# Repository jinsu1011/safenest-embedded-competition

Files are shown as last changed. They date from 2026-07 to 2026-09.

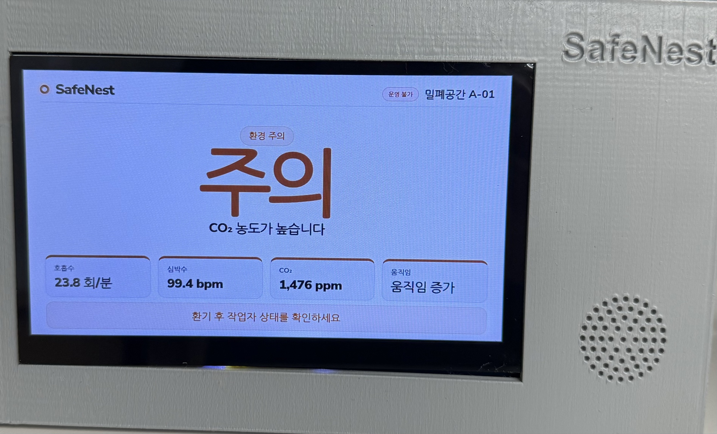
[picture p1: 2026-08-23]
final-report/assets/ui_lcd_3_caution.jpg

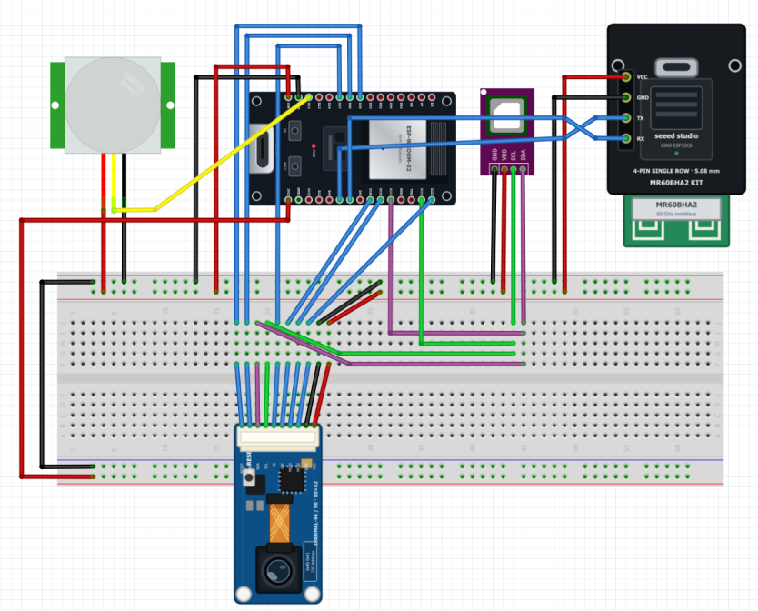
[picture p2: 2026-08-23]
final-report/assets/hw_wiring_diagram.png

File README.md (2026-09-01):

# SafeNest

밀폐공간 작업자 안전을 위한 엣지 AI 모니터링 시스템입니다. ESP32 센서 노드가 mmWave·Thermal·CO₂·PIR을 측정해 Raspberry Pi로 보내고, Pi가 On-device AI와 Rule Engine으로 위험도를 판정해 실시간 웹 대시보드에 표시합니다.

이 저장소는 여러 팀 저장소를 통합한 **canonical 통합 저장소**입니다. 각 컴포넌트의 상류 저장소와 정확한 commit SHA는 [`COMPONENT_SOURCES.json`](COMPONENT_SOURCES.json)에 기록되어 있습니다.

---

## 한 줄 실행

Raspberry Pi에서 아래 한 명령으로 전체 SafeNest 런타임이 기동됩니다.

```bash
./run_safenest.sh
```

최초 1회만 의존성을 설치합니다.

```bash
./run_safenest.sh --install
```

Thermal 모델만 바꿔 같은 SafeNest 스택을 비교하려면 별도 테스트 런처를 씁니다. 기본 `./run_safenest.sh` 동작은 그대로입니다.

```bash
./run_safenest_thermal_test.sh baseline
./run_safenest_thermal_test.sh a
./run_safenest_thermal_test.sh b
```

자세한 선택 의미는 [`docs/thermal/20260831_Thermal_V2_Team_MultiModel_Test_Staging_01.md`](docs/thermal/20260831_Thermal_V2_Team_MultiModel_Test_Staging_01.md)를 봅니다.
Pi 현장에서 baseline/A/B를 켜고 확인하는 절차는 [`PI_RUNBOOK_THERMAL.md`](PI_RUNBOOK_THERMAL.md)입니다.

이 한 명령이 하나의 프로세스 트리 안에서 다음을 모두 띄웁니다.

| 구성 요소 | 역할 |
| --- | --- |
| SafeNest TCP v1 게이트웨이 (`:9000`) | mmWave·CO₂·PIR scalar telemetry 수신 |
| SafeNest Thermal UDP v1 수신기 (`:5005`) | 80×62 열화상 프레임 chunk 재조립 |
| Sensor State Manager | 센서별 최신값·freshness·유효성·device health |
| On-device AI 파이프라인 | `RaspberryPi/Ondevice_AI`의 TFLite 어댑터 지연 로드 |
| Rule / Risk Engine | SAFENEST_RISK_V1(+필요 시 V4 호환)으로 `NORMAL/WARNING/DANGER` 판정 |
| SQLite | `RaspberryPi/Runtime/data/safenest.db` 스냅샷·이벤트 영속화 |
| FastAPI + WebSocket (`:8000`) | 통합 상태 API와 실시간 push |
| 실시간 웹 대시보드 | `http://<pi-주소>:8000/dashboard` |

여러 터미널을 열 필요가 없습니다. `Ctrl+C` 한 번으로 전체가 정상 종료됩니다.

### 접속 주소

| 대상 | URL |
| --- | --- |
| 관리자 웹 | `http://<pi-주소>:8000/admin` |
| A01 방문자 열화상 | `http://<pi-주소>:8000/guest/dashboard/A01` |
| 실시간 대시보드 | `http://<pi-주소>:8000/dashboard` |
| LCD 표시 화면 | `http://<pi-주소>:8000/display` |
| LCD 데모 제어 (명시적 opt-in) | `SAFENEST_DEMO_MODE=true`일 때 `http://<pi-주소>:8000/control` |
| 통합 상태 API | `http://<pi-주소>:8000/api/status` |
| 센서 상세 | `http://<pi-주소>:8000/api/sensors` |
| 이력 / 이벤트 | `/api/history`, `/api/events` |
| 헬스체크 | `http://<pi-주소>:8000/health` |
| WebSocket | `ws://<pi-주소>:8000/ws` |

포트를 바꾸려면 인자를 그대로 전달합니다: `./run_safenest.sh --api-port 8080 --sensor-port 9100`

### 웹과 열화상 빠른 확인

Raspberry Pi OS에서 최초 1회 OS 패키지를 설치한 뒤 SafeNest를 시작합니다.

```bash
sudo apt update
sudo apt install -y python3-venv python3-pip python3-dev build-essential
./run_safenest.sh --install
```

`--install`은 가상환경과 Python 의존성을 설치한 다음 사전 점검을 거쳐 런타임까지 시작합니다. 이후 실행은 `./run_safenest.sh`만 사용합니다. 방화벽을 사용하면 브라우저용 TCP `8000`, scalar telemetry용 TCP `9000`, Thermal UDP `5005`를 허용합니다.

ESP32의 `secrets.h`에는 Pi의 실제 IP를 `RPI_HOST`로 넣고, 펌웨어의 `THERMAL_UDP_PORT`와 Pi의 `SAFENEST_THERMAL_UDP_PORT`를 동일한 `5005`로 유지합니다. 프레임 수신 여부는 다음처럼 확인합니다.

```bash
curl -fsS http://127.0.0.1:8000/health | python3 -m json.tool
curl -sS -D - -o /dev/null http://127.0.0.1:8000/api/thermal/A01
```

열화상 API가 `200`과 `application/octet-stream`을 반환하면 웹이 그릴 수 있는 완성 프레임이 있습니다. 아직 프레임이 없으면 `204`가 정상적으로 반환됩니다. 자세한 순서는 [`RaspberryPi/Runtime/docs/WEB_THERMAL_RUNBOOK_KO.md`](RaspberryPi/Runtime/docs/WEB_THERMAL_RUNBOOK_KO.md)를 따릅니다.

---

## 저장소 구조

```
ESP32/
├── Arduino/esp32_sensor_node/    canonical 플래시 소스 (4개 센서 통합 노드)
├── docs/COMMUNICATION_PROTOCOL.md  ESP32 ↔ Pi 프로토콜 계약
├── reference/mmwave_platformio/  mmWave 단독 PlatformIO 참조 펌웨어
└── secret.h.example              Wi-Fi/Pi 주소 템플릿 (실제 값은 커밋 금지)

RaspberryPi/
├── Ondevice_AI/                  On-device AI 상류 권위 소스 (sheepmeat/test)
├── LCD/                          Pi LCD 키오스크 (레거시 독립 경로, 아래 주의)
├── Web/                          실시간 관제 대시보드 정적 자산
└── Runtime/                      Pi 런타임 (게이트웨이·상태·AI·risk·backend·DB)

research/
├── thermal_ai/                   Thermal 오프라인 데이터셋/모델 연구 (런타임 아님)
└── co2_validation/               CO₂ 측정·검증 도구와 세션 fixture (런타임 아님)

archive/                          과거 구현·측정 증거 보존 (런타임이 참조하지 않음)
hardware/                         하우징 3D 모델
COMPONENT_SOURCES.json            컴포넌트별 상류 저장소와 commit SHA
run_safenest.sh                   단일 실행 진입점
run_safenest_thermal_test.sh      Thermal baseline/A/B 비교용 테스트 런처
PI_RUNBOOK.md                     Pi 일반 현장 기동
PI_RUNBOOK_THERMAL.md             Pi Thermal baseline/A/B 비교 현장 가이드
```

### 구조 예외 (STRUCTURE_EXCEPTION)

기본 목표 구조는 `RaspberryPi/{Ondevice_AI, LCD, Web}`였지만, 기술적으로 다음 디렉터리를 추가했습니다.

| 디렉터리 | 책임 | 왜 필요한가 |
| --- | --- | --- |
| `RaspberryPi/Runtime/` | 게이트웨이, 센서 상태, AI 오케스트레이션, Risk, FastAPI, SQLite, 서비스, 배포 | 이 코드는 특정 센서나 UI가 아니라 **셋을 연결하는 런타임**입니다. `Ondevice_AI`에 넣으면 상류 저장소를 오염시키고, `Web`에 넣으면 UI가 게이트웨이를 소유하게 됩니다. 이게 없으면 단일 명령 실행 자체가 성립하지 않습니다. |
| `research/` | Thermal·CO₂ 오프라인 모델/데이터 연구 워크스페이스 | 두 상류 저장소가 스스로 "펌웨어 통합·위험도 판단은 범위 밖"이라고 명시합니다. 런타임에 섞으면 미검증 모델이 배포 경로로 오해됩니다. |
| `ESP32/docs`, `ESP32/reference` | 프로토콜 계약 문서, mmWave 참조 펌웨어 | 계약 테스트가 이 파일들을 읽습니다. `archive/`에 두면 활성 테스트가 archive에 의존하게 되어 금지된 구조가 됩니다. |
| `hardware/` | 하우징 STL | ESP32도 Pi도 소유하지 않는 물리 설계 자산입니다. |

---

## 데이터 흐름

```
ESP32 센서 노드
  ├─ mmWave (MR60BHA2, UART)  ─┐
  ├─ CO₂ (SCD4x, I2C)          ├─ JSON telemetry ─→ SafeNest TCP v1 :9000 ─┐
  └─ PIR (GPIO)               ─┘                                            │
  └─ Thermal (MI48xx, SPI) ─ 80×62 uint16 ─→ Thermal UDP v1 :5005 ─────────┤
                                                                            ▼
                                                     RaspberryPi/Runtime/gateway
                                                                            │
                                                     state/manager.py (freshness·유효성)
                                                                            │
                                              ai/pipeline.py ──→ Ondevice_AI TFLite
                                                                            │
                                              risk/engine.py (V4 가중치·임계값)
                                                                            │
                                     backend/store.py → database/ (SQLite)  │
                                                                            ▼
                                            backend/app.py (FastAPI + /ws)
                                                                            │
                                                          RaspberryPi/Web 대시보드
```

활성 진입점은 하나뿐입니다: `RaspberryPi/Runtime/backend/run_backend.py`. 컴포넌트 간 경로는 전부 `RaspberryPi/Runtime/paths.py`가 해석합니다.

---

## 설치와 실행

### 1. ESP32 펌웨어 플래시

1. Arduino IDE에서 `ESP32/Arduino/esp32_sensor_node/esp32_sensor_node.ino`를 엽니다.
2. 자격증명 파일을 스케치 폴더에 만듭니다. **이 파일은 Git에 커밋되지 않습니다.**
   ```bash
   cp ESP32/secret.h.example ESP32/Arduino/esp32_sensor_node/secrets.h
   ```
3. `secrets.h`를 열어 2.4 GHz Wi-Fi SSID/비밀번호와 Raspberry Pi의 IP를 채웁니다.
4. 보드를 `ESP32 Dev Module`로 선택하고 업로드합니다.
5. 필요한 라이브러리: `SensirionI2cScd4x`, `Seeed_Arduino_mmWave`.

배선과 패킷 형식은 [`ESP32/docs/COMMUNICATION_PROTOCOL.md`](ESP32/docs/COMMUNICATION_PROTOCOL.md)를 따릅니다.

### 2. Raspberry Pi 준비

```bash
git clone https://github.com/jinsu1011/safenest-embedded-competition.git
cd safenest-embedded-competition
./run_safenest.sh --install   # .venv 생성 + 의존성 설치
./run_safenest.sh             # 실행
```

의존성은 `RaspberryPi/Runtime/requirements-backend.txt`(FastAPI/uvicorn)와 `RaspberryPi/Ondevice_AI/requirements-pi.txt`(ai-edge-litert, numpy 등)에서 옵니다.

### 3. 선택: 비상 대응 설정

SMS·부저를 쓰려면 저장소 루트에 `.env`를 만듭니다. 템플릿은 [`RaspberryPi/Runtime/.env.example`](RaspberryPi/Runtime/.env.example)입니다. `.env`는 Git에 올라가지 않습니다.

---

## 실패 동작

시스템은 **fail-closed**입니다. 값을 지어내지 않습니다.

| 상황 | 동작 |
| --- | --- |
| 센서 패킷이 끊김 | 해당 센서가 `STALE` → `DISCONNECTED`. 마지막 값을 현재값으로 쓰지 않음 |
| 잘못된 패킷 수신 | 해당 연결만 끊고 `protocol_errors` 증가. 서비스는 계속 동작 |
| 모델 로드 실패 | 해당 센서만 `MODEL_RUNTIME_UNAVAILABLE`, 나머지는 계속 평가 |
| 전 컴포넌트 불가 | `risk_level = null` + `ALL_RISK_COMPONENTS_UNAVAILABLE`. 임의 점수를 만들지 않음 |
| 필수 설정 누락 | 기동 시 명시적 오류 |

`system_health`가 `DEGRADED`/`FAILED`인데 `risk_level`이 `NORMAL`이면, 그것은 "안전 확인"이 아니라 "판정 근거 부족"입니다.

---

## AI 모델 상태

**중요: 이 저장소의 어떤 모델도 실기기에서 검증되지 않았습니다.** Thermal 모델은 최종 runtime artifact로 활성화했지만, 이는 Pi/실센서/실제 낙상 검증 완료를 뜻하지 않습니다.

| 센서 | 런타임 모델 | 상태 |
| --- | --- | --- |
| Thermal | `public_sdt_pooled_mlp_fp32_tflite_v1` | **활성 최종 runtime 모델**. `HUMAN_FALL_PROXY`는 위험 점수 0.4로 제한 반영하며 긴급 override는 금지 |
| CO₂ | `co2_occupancy_int8_v0.1.0` | candidate, `CONFIRMED_SYNTHETIC_ONLY` |
| mmWave | `mmwave_resp_int8_v0.1.0` | **배포 차단** (`deployment_allowed: false`, `CLASS_COLLAPSE_ON_REPOSITORY_NPZ`) |
| mmWave v0.2.0 | `mmwave_resp_int8_v0.2.0_candidate` | candidate, `SYNTHETIC_SMOKE_ONLY`, 하드웨어 검증 `BLOCKED_HARDWARE` — 런타임 기본값으로 승격하지 않음 |
| PIR | 없음 | AI 모델 없음. Rule 전용 센서 |

용어를 구분합니다: 최종 runtime artifact ≠ 실기기 검증 완료, `HUMAN_FALL_PROXY` ≠ 실제 낙상 이벤트, 제한 위험 반영 ≠ 긴급 호출 권한.

권위 있는 상태는 [`RaspberryPi/Ondevice_AI/models/model_manifest.json`](RaspberryPi/Ondevice_AI/models/model_manifest.json)입니다.

---

## 검증

```bash
cd RaspberryPi/Runtime
python -m unittest discover -s tests -p "test_*.py" -v   # 151개 테스트
python deployment/verify_bundle.py                        # 필수 파일 + 모델 SHA-256
python -m hil.preflight                                   # Pi 환경 사전 점검
```

`tests/test_end_to_end.py`는 실제 TCP loopback으로 게이트웨이→AI→Risk→SQLite→API view 전체를 통과시킵니다. 이는 **소프트웨어 E2E**이며, 실제 센서 하드웨어 검증이 아닙니다. 하드웨어 검증 절차는 [`RaspberryPi/Runtime/docs/HIL_ACCEPTANCE.md`](RaspberryPi/Runtime/docs/HIL_ACCEPTANCE.md)에 있습니다.

---

## 주의사항

### LCD 경로

`run_safenest.sh`가 시작하는 FastAPI가 production 웹 대시보드와 LCD 화면을 함께 제공합니다. 물리 LCD에는 `http://localhost:8000/display`를 엽니다. 화면은 read-only `/api/state`를 통해 실제 센서/application 상태를 사용합니다. 기본 실행에서는 수동 LCD override, demo TTS, 모의 119 신고 route가 등록되지 않습니다.

경진대회용 Web/LCD 데모가 꼭 필요할 때만 저장소 루트 `.env`에 `SAFENEST_DEMO_MODE=true`를 명시하고 정상 런처를 실행합니다. 이 경우 기존 demo 대시보드, `http://<pi-주소>:8000/control`, `POST /api/state`, 모의 119 route가 함께 활성화됩니다. 설정이 없거나 `false`이면 항상 production 경로입니다.

HTML 파일을 `file://`로 직접 열지 말고 위 HTTP 주소로 접속해야 CSS·JavaScript와 센서 API가 같은 origin으로 연결됩니다.

`RaspberryPi/LCD/server.py`는 과거의 독립 구현으로 자체 TCP `:9000` 수신기와 `state.json`을 사용합니다. canonical 게이트웨이와 포트·상태가 중복되므로 `run_safenest.sh`와 동시에 실행하지 않습니다. 단독 점검이 필요할 때만 별도 포트로 실행합니다.

같은 이유로 `research/co2_validation/pi/safenest_pi_service.py`(CO₂ 전용 `:9000` 수신기)도 런타임과 동시에 실행하면 안 됩니다.

### archive는 런타임이 참조하지 않습니다

`archive/`는 과거 구현·측정 증거 보존 전용입니다. 활성 런타임은 archive를 import하지도, 설정·모델을 읽지도 않습니다.

---

## 상류 저장소 동기화

| 컴포넌트 | 상류 | 통합 commit |
| --- | --- | --- |
| On-device AI | `sheepmeat/test` | `4129753e64e0f18a3491e5b6cc0454b0d36f1610` |
| 런타임·게이트웨이·backend·DB·Web | `yuname121/integration` | `9e4ddfe770d505266f33b39dfe9ba8ec86099f82` |
| Thermal 연구 | `yuname121/safenest-thermal-ai` | `db51112bfd02cdda2d41e99cf11acde75f771ecf` |
| CO₂ 측정·검증 | `yuseungha/Sandi-2026_summer` | `145deac4cbec12ce6459cf5a6858cb0d0b1d06da` |
| 기존 메인 저장소 | `jinsu1011/safenest-embedded-competition` | `6fc04d6e9e09aa0baac96592eb374f6d3de6af07` |

상류 갱신을 반영할 때:

1. 상류 저장소를 clone하고 새 HEAD SHA를 확인합니다.
2. **런타임 임계 경로**(`inference/`, `config/`, `adapters/`, `models/model_manifest.json`)의 diff를 먼저 봅니다.
3. 모델 매니페스트의 `deployment_allowed`와 `validation_status`가 바뀌었는지 확인합니다. 최신이라는 이유만으로 승격하지 않습니다.
4. 파일을 반영하고 `COMPONENT_SOURCES.json`의 SHA를 갱신합니다.
5. `python -m unittest discover -s tests`와 `verify_bundle.py`를 돌려 모델 SHA-256이 매니페스트와 일치하는지 확인합니다.

---

## 문제 해결

| 증상 | 확인할 것 |
| --- | --- |
| 대시보드가 "WebSocket 오프라인" | 백엔드가 살아있는지 `curl localhost:8000/health` |
| 모든 센서가 `DISCONNECTED` | ESP32의 `secrets.h` 속 Pi IP, 같은 2.4 GHz 네트워크인지, `:9000` 방화벽 |
| Thermal만 안 들어옴 | Thermal은 UDP `:5005`. TCP와 별도 포트입니다 |
| `virtual environment not found` | `./run_safenest.sh --install` 먼저 실행 |
| `port_9000_available: false` | LCD나 CO₂ 전용 서비스가 이미 `:9000`을 점유 중 |
| mmWave AI가 `INPUT_UNAVAILABLE` | 정상입니다. B-model은 300-sample 호흡 phase window를 요구하며 현재 펌웨어는 vendor scalar만 보냅니다 (`PENDING_MMWAVE_DEVICE_CONTRACT_VALIDATION`) |

---

## 기여

브랜치 규칙과 리뷰 절차는 [`CONTRIBUTING.md`](CONTRIBUTING.md)를 따릅니다. 단계별 통합 근거는 [`RaspberryPi/Runtime/docs/`](RaspberryPi/Runtime/docs/)에 PHASE 1~10으로 정리되어 있습니다.

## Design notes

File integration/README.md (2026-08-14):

# `integration/`

## 1. 디렉터리 목적
ESP32 텔레메트리를 받아 상태를 판정하고 LCD·부저·웹 화면으로 내보내는 Raspberry Pi 쪽 실행 계층을 한곳에 모은다.

## 2. 시스템에서 담당하는 기능
TCP 9000으로 들어온 센서 패킷을 검증·보관하고, 상태를 판정해 LCD 키오스크 화면과 GPIO 부저를 구동하며, 관리자·방문자 웹 화면과 REST API를 제공한다.

## 3. 포함해야 하는 파일 유형
Pi 수신·표시 서버, 웹 서버와 정적 화면, 실행·설치 스크립트, 이 계층만으로 통과 가능한 테스트를 포함한다.

## 4. 포함하면 안 되는 파일 유형
ESP32 펌웨어(`devices/esp32_node/`), 센서별 드라이버(`devices/<sensor>/`), TFLite 모델·추론(`ondevice_ai/`), 공용 계약(`shared/contracts/`), `node_modules/`와 `.env` 같은 로컬 산출물은 포함하지 않는다.

## 5. 주요 하위 구성
`pi_lcd/`는 Python 표준 라이브러리 기반 수신·표시 서버(`server.py`, `static/`, `tests/`, `start_lcd.sh`, `stop_lcd.sh`)다. `web/`은 Express 기반 통합 웹(`server.js`, `admin-api.js`, `preview.html`, `qr-codes/`)이다. `install_raspberry_pi.sh`와 `start_all.sh`는 두 서버를 설치·기동한다.

## 6. 입력과 출력 인터페이스
입력은 ESP32의 `safenest.telemetry.v1` JSON(TCP 9000)이다. 출력은 `GET /api/state`, `GET /api/thermal`, `GET /health`(:8080)와 통합 웹(:3000), 그리고 LCD 화면·부저다. `POST /api/state`로 판정 결과가 LCD에 반영된다. 결측·0·NaN·timeout은 정상값이나 무호흡으로 바꾸지 않고 `stale`/`waiting`으로 표시한다.

## 7. 다른 기능 영역과의 관계
`devices/esp32_node/`가 보내는 텔레메트리를 소비하는 하위 계층이며, 반대로 펌웨어를 import하지 않는다. 현재 판정은 `web/server.js`의 규칙 기반 `evaluate()`/`riskScore()`를 쓰며, `ondevice_ai/`의 V4 위험도 엔진과는 아직 연결돼 있지 않다. 두 판정 경로의 통합은 후속 작업이다.

## 8. 실행·학습·추론 또는 활용 방법
설치와 실행은 저장소 루트에서 수행한다.

```bash
bash integration/install_raspberry_pi.sh
bash integration/start_all.sh
```

스크립트는 `pi_lcd/`와 `web/`을 각각 `~/raspberry_pi_lcd`와 `~/SafeNest_Web`으로 복사한다. 저장소 경로와 실행 환경 폴더 이름이 다른 것은 실측 검증된 운용 절차를 그대로 유지하기 위해서다. 자세한 절차는 [`docs/operations/INTEGRATION_INSTALL_AND_RUN.md`](../docs/operations/INTEGRATION_INSTALL_AND_RUN.md)에 있다.

테스트는 `pi_lcd/`에서 실행한다. 테스트가 `server.py`를 직접 import하므로 해당 디렉터리를 `PYTHONPATH`에 넣는다.

```bash
cd integration/pi_lcd
PYTHONPATH=. python3 -m unittest discover -s tests -p "test_*.py"
```

## 9. 현재 개발 상태 및 버전
실제 하드웨어에서 ESP32 수신 → 상태 판정 → LCD 자동 전환까지 검증했고 회귀 테스트 13건이 통과한다. 남은 한계(열화상 죽은 픽셀, 호흡수 노이즈)는 [`docs/esp32_node/ESP32_LCD_INTEGRATION_NOTES.md`](../docs/esp32_node/ESP32_LCD_INTEGRATION_NOTES.md) 5절에 있다. 최상위 `display-test/`와 `display-test2/`는 이 작업의 이전 스냅샷이며 이 디렉터리가 대체한다.

## 10. 향후 파일 추가 및 관리 규칙
판정 규칙과 임계값은 한 번에 하나만 바꾸고 같은 조건에서 변경 전후를 비교한다. 텔레메트리 필드를 바꾸면 `devices/esp32_node/`와 [`docs/esp32_node/COMMUNICATION_PROTOCOL.md`](../docs/esp32_node/COMMUNICATION_PROTOCOL.md)를 같은 PR에서 함께 고친다. `.env`와 `secrets.h`, `node_modules/`는 커밋하지 않는다.

## 11. 주요 기여자와 원본 브랜치·커밋 추적 정보
담당: Seungha (`@yuseungha`) — Pi 수신·표시 서버, 통합 웹, 설치·실행 스크립트.
원본 ref `yuseungha/safenest-embedded-competition@0992a6d`(`main`에 PR #1로 병합), 원본 경로 `yuseungha/raspberry_pi_lcd/`와 `yuseungha/SafeNest_Web/`.

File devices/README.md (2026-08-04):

# `devices/`

## 1. 디렉터리 목적
기기 담당자가 단독으로 책임지는 센서별 펌웨어, 드라이버, 배선·보정 문서, 기기 단독 테스트를 기기 단위로 모은다.

## 2. 시스템에서 담당하는 기능
각 물리 센서를 초기화·수집·검증해 `shared/contracts/base_sensor.py` 계약을 만족하는 정규화된 판독값으로 바꾼다.

## 3. 포함해야 하는 파일 유형
기기별 드라이버·어댑터·mock, 펌웨어 프로젝트, 기기 설정, 배선·보정 문서, 그 기기만으로 통과 가능한 테스트를 포함한다.

## 4. 포함하면 안 되는 파일 유형
여러 기기가 함께 쓰는 인터페이스(`shared/contracts/`), TFLite 추론·위험도 융합·통합 노드(`ondevice_ai/`), 빌드 산출물과 사용자명 디렉터리는 포함하지 않는다.

## 5. 주요 하위 구성
`co2/`, `pir/`, `mmwave/`, `thermal/` 네 기기가 있고 각 기기는 `src/`를 기본으로 필요에 따라 `firmware/`, `config/`, `tests/`, `docs/`를 갖는다.

## 6. 입력과 출력 인터페이스
입력은 UART/I2C/GPIO 원신호와 리플레이 로그이며, 출력은 `SensorReading` 계약을 따르는 판독값과 명시적인 결측 표시다.

## 7. 다른 기능 영역과의 관계
`shared/contracts/`의 계약을 구현하고, `ondevice_ai/src/`가 이 구현을 `devices.<device>.src...` 경로로 명시적으로 import한다. 반대 방향 의존은 만들지 않는다.

## 8. 실행·학습·추론 또는 활용 방법
기기 단독 테스트는 `python3 -m unittest discover -s devices/<device>/tests -p 'test_*.py'`로 실행하고, 펌웨어는 해당 기기 README의 빌드 절차를 따른다.

## 9. 현재 개발 상태 및 버전
mmWave는 MR60 schema 1.2 / 펌웨어 v1.2.0으로 실측 검증까지 완료했고, CO2·PIR·Thermal은 어댑터와 mock 단계다. 2026-08-03 책임 영역 재편(`38274c0`) 구조를 따른다.

## 10. 향후 파일 추가 및 관리 규칙
새 기기는 `devices/<device>/src/`부터 만들고 담당자·README·CODEOWNERS 항목을 함께 추가한다. 기기 코드를 다른 기기 디렉터리로 복사하지 말고, 공통이 필요해지면 `shared/contracts/`로 올린 뒤 양쪽에서 import한다.

## 11. 주요 기여자와 원본 브랜치·커밋 추적 정보
| 기기 | 담당 | GitHub handle | 책임 범위 |
|---|---|---|---|
| `co2/` | Seungha | `@yuseungha` | CO2 센서 드라이버, 배선, 보정 |
| `pir/` | Yuna | `@yuname121` | PIR 어댑터, 하우징 연계 |
| `mmwave/` | Jinsu | `@jinsu1011` | MR60 펌웨어, 텔레메트리, 실측 검증 |
| `thermal/` | Taegyun | `@rla1729` | Thermal-44 드라이버, 프레임 파서 |

원본은 `origin/Ondevice_AI`(`d97df3e`)의 센서 구현과 `codex/mmwave-phase-integration`(`b0d3c95`)의 MR60 작업이며, 상세 매핑은 [`docs/architecture/BRANCH_PROVENANCE.md`](../docs/architecture/BRANCH_PROVENANCE.md)에 있다.

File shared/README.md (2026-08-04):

# `shared/`

## 1. 디렉터리 목적
여러 책임 영역이 함께 의존하는 최소한의 공용 인터페이스만 보관한다. 어느 한 기기나 `ondevice_ai/`에만 속한다고 말할 수 없는 것만 여기에 둔다.

## 2. 시스템에서 담당하는 기능
기기 구현과 온디바이스 AI 사이의 데이터 계약을 한 곳에 고정해, 양쪽이 서로의 내부 구현을 알지 않아도 되게 한다.

## 3. 포함해야 하는 파일 유형
추상 기반 클래스, 데이터 계약, 상태 enum처럼 둘 이상의 최상위 영역이 실제로 import하는 정의만 포함한다.

## 4. 포함하면 안 되는 파일 유형
특정 기기 드라이버, 모델·데이터셋, 위험도 로직, 실행 스크립트, 유틸리티 잡동사니는 포함하지 않는다. 한 영역만 쓰는 코드는 그 영역에 둔다.

## 5. 주요 하위 구성
`contracts/`에 센서 계약 `base_sensor.py` 하나가 있다.

## 6. 입력과 출력 인터페이스
직접 실행되지 않는 정의 전용 영역이다. `devices/`가 구현하고 `ondevice_ai/`가 소비한다.

## 7. 다른 기능 영역과의 관계
`devices/<device>/src/`의 모든 어댑터가 이 계약을 구현하고, `ondevice_ai/src/`가 같은 계약에 기대어 동작한다. 이 영역이 커질수록 팀 전원이 같은 파일을 건드리게 되므로 의도적으로 작게 유지한다.

## 8. 실행·학습·추론 또는 활용 방법
`from shared.contracts.base_sensor import ...` 형태로 저장소 루트 기준 import한다.

## 9. 현재 개발 상태 및 버전
2026-08-03 책임 영역 재편(`38274c0`)에서 신설했다. 현재 공용 정의는 센서 계약 한 개다.

## 10. 향후 파일 추가 및 관리 규칙
새 파일을 추가하기 전에 "두 개 이상의 최상위 영역이 실제로 import하는가"를 확인한다. 아니면 해당 영역에 둔다. 계약 변경은 모든 구현체와 테스트를 함께 갱신하고 CODEOWNERS 리뷰를 받는다.

## 11. 주요 기여자와 원본 브랜치·커밋 추적 정보
담당: Junwoo (`@sheepmeat`), Jinsu (`@jinsu1011`) 공동.
원본 ref `origin/Ondevice_AI` (`d97df3e`), 원본 경로 `src/sensors/base_sensor.py`. 2026-08-03 이동 커밋 `38274c0`에서 현재 경로로 옮겼다.

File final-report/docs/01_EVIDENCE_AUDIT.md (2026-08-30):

# 01_EVIDENCE_AUDIT

Evidence levels: **E0** planned · **E1** source implemented · **E2** software verified ·
**E3** component HW verified · **E4** integrated real-HW / HIL · **E5** repeated quantitative.

Snapshot = `05_Source_Snapshot/safenest-embedded-competition` @ commit `3f22fb1…` (branch `codex/mmwave-m-c0-correspondence`).
"Executed" = actually run by me on this Mac (see `work/test_runs/EXECUTED_TESTS.md`).

| Feature / Claim | Exact source | Status | Level | Verified? | Safe wording (KO) | Missing evidence |
|---|---|---|---|---|---|---|
| ESP32 4-sensor node firmware | `devices/esp32_node/firmware/esp32_sensor_node.ino` (741 lines) | 4 sensors in one node, ESP32 Dev Module | **E1** | source read | 구현 완료 | 실기기 4센서 동시 수신 로그 |
| MCU = ESP32 DevKit V1 (not XIAO) | same file, pin constants L34-47; 유승하 report 대표문제 B | Board changed from XIAO ESP32-C6 | **E1/E3** | source + report | 구현 완료 | 교체 사유 1차 문서 (`[검증 필요]` per 유승하) |
| mmWave MR60BHA2 via **UART2** 115200 | `.ino` L38-39 `PIN_MMWAVE_RX=16/TX=17`, `MMWAVE_BAUD` | implemented + real capture | **E3** | `FINAL_REPORT_KO.md` 9.990 Hz, 1,201 rec | 실기기 검증 | — |
| SCD40 CO₂ via **I2C** 0x62 | `.ino` `SCD4X_ADDRESS=0x62`, SDA21/SCL22 | implemented + real sessions | **E3** | CO₂ 4 sessions 2026-08-12 | 실기기 검증 | 센서 분리(결측) 계약 미완 |
| Thermal MI48xx **I2C ctrl + SPI data** | `.ino` L40-46, `THERMAL_ADDRESS_A/B 0x40/0x41` | implemented | **E1/E3** | thermal v5 real frames | 실기기 검증(별도 리그) | 정식 노드에서의 실측 |
| PIR via **GPIO 13** digital | `.ino` `PIN_PIR=13`, `PIR_PERIOD_MS=20` | implemented | **E1** | source | 구현 완료 | 실 GPIO 수신 증거 (한준우: "실 GPIO 미설치") |
| **SafeNest TCP protocol v1** 16B header `SNST` | `.ino` L113-124; `integration/pi_lcd/server.py` L43-47 `PACKET_HEADER=Struct("!4sBBHII")` | both ends implemented | **E2** | **executed: 13 passed** | SW 검증 | — |
| `recv_exact()` length-prefixed framing | `integration/pi_lcd/server.py` | implemented | **E2** | executed | SW 검증 | — |
| **null ≠ 0** for invalid readings | `.ino` `formatNullableFloat()` L546-553 → emits `"null"` | implemented both ends | **E2** | executed + CO₂ CSV | 구현 완료 · SW 검증 | — |
| Per-channel `valid{}` block | `.ino` L576-583; server L140-145 | implemented | **E2** | executed | 구현 완료 | — |
| Per-sensor freshness TTL (ESP side) | `.ino` `MMWAVE_STALE_MS=5000`, `CO2_STALE_MS=15000`, `THERMAL_STALE_MS=30000` | implemented | **E1** | source | 구현 완료 | — |
| Pi-side stale state machine `waiting/live/stale/error` | `server.py` `SensorStore.snapshot()` L226-258, `stale_seconds=5.0` | implemented | **E2** | executed | SW 검증 | — |
| **CRC-16/CCITT-FALSE** on thermal frames | `.ino` L303-320 `thermalFrameCrc()`, poly 0x1021 init 0xFFFF; counter `thermalCrcErrors` | implemented | **E1** | source read | 구현 완료 | 실측 CRC 오류율 |
| Thermal frame integrity: geometry + inner/outer sequence + recomputed min/max cross-check | `server.py` L175-206 | implemented, corrupt frame discarded | **E2** | executed | SW 검증 | — |
| Dead-pixel band 2332–4231 raw (≈ −40…150 °C), ≥32 live pixels | `.ino` L98-101; `server.py` L199-206 | implemented | **E2** | executed | 구현 완료 | — |
| Robust peak = coolest of 16 hottest | `.ino` `THERMAL_PEAK_SAMPLE_COUNT=16` + comment | implemented | **E1** | source | 구현 완료 | — |
| Thermal auto re-init after 30 s no-frame (GPIO RESET 25) | `.ino` `recoverThermalIfStale()` L418-434, `initializeThermalCamera()` L232-240 | implemented | **E1** | source | 구현 완료 | 실측 복구 로그 |
| **Thermal full-frame streaming DISABLED** | `.ino` L108-111 `THERMAL_STREAM_FRAMES=false` + comment | current canonical state | **E1** | source | 현재 구조: 요약값 전송 | — |
| SPI 1 MHz / I2C 100 kHz (signal integrity) | `.ino` `THERMAL_SPI_HZ=1000000`; `Wire.setClock(100000)` L696 | implemented, from 8 MHz/400 kHz | **E3** | 유승하 report 문제3 | 실기기 검증 | 계측 파형 없음 |
| No `delay()`; millis() scheduling + FreeRTOS network task; 1-slot `xQueueOverwrite` | `.ino` header comment L15-18 | implemented | **E1** | source | 구현 완료 | — |
| Buzzer GPIO18 880 Hz on `emergency` | `server.py` `BuzzerController` L410, args L699-701 | implemented | **E2** | executed (mocked) | SW 검증 | 실기기 부저 증거 |
| **Risk engine (current Pi)** R=100·(0.25·mmWave+0.30·CO₂+0.15·PIR+0.30·Thermal), floors | `RaspberryPi/Runtime/risk/formula_v1.py`, `risk_formula_v1.json` | implemented | **E2** | `test_risk_formula_v1.py` | SW 검증. 보고서 P10 정본 | 구 V4 스냅샷 식과 다름 |
| Thresholds NORMAL<30 / WARNING 30–65 / DANGER ≥65 | same | implemented | **E2** | executed | 주의=WARNING. CAUTION 명칭 폐기 | 30/65는 팀 프로토타입 |
| CO₂ warning floor ≥1500 ppm or baseline+700, immediate danger ≥5000 ppm | `risk_formula_v1.json` `co2` + `CO2BaselineLock`; `docs/09_SAFETY_CRITERIA_V1.md` | implemented | **E2** | `test_indoor_air_quality_anchor_raises_warning_even_when_r_is_low`; `test_relative_rise_warns_below_the_absolute_ceiling`; `test_co2_baseline_lock.py` | 1,500 ppm(별표2 비고)=주의. \(B\)+700=상대 주의. occupancy는 점수 제외 | 인증 기준 아님 |
| **Fail-closed: all sensors invalid → risk_score=None, risk_level=None** | `ondevice_ai/risk/fallback.py` L196-201 | implemented | **E2** | executed | SW 검증 (**핵심 차별성**) | — |
| Weight renormalisation over valid sensors only | `fallback.py` L214-219 | implemented | **E2** | executed | SW 검증 | — |
| STALE excluded (not reused as current) | `fallback.py` L157-163 `_STALE_TIMESTAMP` | implemented | **E2** | executed | SW 검증 | — |
| system_health HEALTHY/DEGRADED/FAILED | `fallback.py` L182-190 | implemented | **E2** | executed | SW 검증 | — |
| Emergency override (thermal=1.0 or mmwave=1.0 → 100/DANGER) | `fallback.py` L203-212 | implemented | **E2** | executed | SW 검증 | — |
| **mmWave model v0.1.0 — deployment BLOCKED** | `ondevice_ai/models/model_manifest.json` | `validation_status: BLOCKED`, `block_reason: CLASS_COLLAPSE_ON_REPOSITORY_NPZ`, acc 0.3996, macroF1 0.19, abnormal/apnea recall 0.0, 468/468 predicted NORMAL | **E2** | manifest | 재현성 검증에서 클래스 붕괴 → 배포 차단 | — |
| mmWave model v0.2.0 candidate acc 1.0 | same manifest | `SYNTHETIC_SMOKE_ONLY`, `real_sensor_performance: NOT_VERIFIABLE`, `hardware_validation: BLOCKED_HARDWARE`, false-alarm `NOT_COMPUTABLE` | **E2** | manifest | **합성 데이터 한정** 후보 | 실센서 평가 전무 |
| Thermal model `thermal_fall_int8_v0.1.0` | manifest: `CONFIRMED_SYNTHETIC_ONLY` (2026-07-25) **superseded by** `03_Evidence/Thermal/*` (2026-08-11) real-HW E2E | real frames → real INT8 TFLite on Pi 5 | **E4** | phase reports | 실기기 E2E 검증 | 정식 4센서 노드 경유는 아님 |
| **HUMAN_FALL = LYING posture proxy** | `phase7_10_scenario_report.md` 시나리오 D "**안전하게 눕기**" → `HUMAN_FALL`; 김태균 report L47,490-491 | proxy only | **E3** | evidence | 눕기(LYING) 자세 기반 위험 후보 상태 | 시간축 낙상 사건 검증 없음 |
| Thermal surface temp ≠ body temp | 김태균 report L502; `.ino` peak comment | — | — | — | 표면 온도 / 열 분포 | 의료 근거 없음 |
| **Real Raspberry Pi 5 E2E latency (thermal)** | `phase11_12_fail_closed_benchmark.md` | 30.06 s, 138 iter, 135 valid (97.8%), 4.6 FPS, mean 167.92 / p50 162.70 / p95 173.90 / max 873.75 ms | **E5** | evidence | 실기기 실측 | 단일 세션·thermal 채널 한정 |
| Thermal fail-closed 6 cases incl. physical disconnect + recovery | `phase11_12_...md` | all PASS on real HW | **E4** | evidence | 실기기 fail-closed 검증 | — |
| Mac-only TFLite latency p50 0.139 ms | `03_Evidence/Thermal/thermal_latest.json` (`platform: macOS`) | model-only, **not Pi** | **E2** | file | macOS 기준 모델 단독 추론 | Pi 단독 추론 수치 없음 |
| CO₂ real sessions (ESP32→Pi TCP 9000) | `03_Evidence/CO2_Data/*.csv` + `VERIFICATION_REPORT_2026-08-12.md` | preflight 30 s (30/30), baseline 5 min attempt02 (300/300, 0% missing), 1st attempt FAIL 7.67% preserved, breath 6 min 360/329 (8.61% missing), peak 1,493 ppm | **E3/E5** | raw CSV | 실기기 검증 (PARTIAL) | 센서 분리 60 s 로그 없음 |
| mmWave live validation (standalone) | `FINAL_REPORT_KO.md` | 199/199 parse, seq loss 0, 9.994 Hz; 1,201 rec @ 9.990 Hz; UART/checksum/parser errors 0/0/0; real INT8 TFLite, fallback 0 | **E3/E5** | evidence | 센서 단위 실기기 검증 | 통합 노드 아님 |
| mmWave fail-closed `MMWAVE_PHASE_SIGNAL_TOO_FLAT` + recovery | `PROJECT_PROGRESS.md`, `FINAL_REPORT_KO.md` | verified live | **E3** | evidence | 실기기 fail-closed | — |
| mmWave replay benchmark (real logs) | `benchmark_summary.csv` | 12 scenarios; presence rate 1.0 @0.6–0.9 m, 0.814 @1.2 m, 0.880 @1.5 m (lock loss, 0 windows); resp MAE 0.270 rpm @12 rpm, 0.275 @15 rpm, 0.550 @20 rpm; model p95 0.14–0.18 ms | **E5** | CSV | 오프라인 리플레이 정량 결과 | 실시간 통합 아님 |
| Long-duration logs 30 min empty / 31 min occupied | `03_Evidence/Logs/*.jsonl` (18.4 MB / 19.0 MB) | sensor-level only | **E3** | files | mmWave 단일 채널 장시간 로그 | 전 센서 통합 내구 시험 없음 |
| ESP32 build footprint | `FINAL_REPORT_KO.md`, `INTEGRATION_PROGRESS.md` | RAM 32,356/327,680 = 9.9%; Flash 268,765/1,310,720 = 20.5% | **E2** | evidence | 실측 빌드 리소스 | — |
| Firmware/config hash-pinned telemetry | `FINAL_REPORT_KO.md` schema 1.2, ESP config SHA-256 `b817e8bf…` | implemented | **E3** | evidence | 구현 완료 | — |
| **FastAPI** in canonical snapshot | searched 401 code files | **NOT PRESENT** | **E0** | verified absent | 미구현 (계획 단계) | — |
| **SQLite** in canonical snapshot | searched 401 code files | **NOT PRESENT** | **E0** | verified absent | 미구현 (계획 단계) | — |
| **WebSocket** in canonical snapshot | searched 401 code files | **NOT PRESENT** | **E0** | verified absent | 미구현 (계획 단계) | — |
| Web layer actually present | `integration/web/package.json` | **Express 5 + bcryptjs + jsonwebtoken + qrcode** (Node.js), `sensor-simulator.js`, `rpi-protocol-simulator.js` | **E1** | source | 구현 완료(시뮬레이터 구동) | 실센서 구동 스크린샷 없음 |
| LCD/API server | `integration/pi_lcd/server.py`, Python **stdlib http.server**, HTTP 8080, 6 states | implemented | **E2** | executed | SW 검증 | 실센서 LCD 사진 없음 |
| Runtime launcher | `integration/start_all.sh`, `install_raspberry_pi.sh` | present (no `run_safenest.sh`) | **E1** | source | 구현 완료 | — |
| Integrated node runtime | `ondevice_ai/integrated_node/run_node.py` (+ mock sensors, provider contract) | implemented, provider injection | **E1/E2** | source | 구현 완료 | 4센서 실기기 주입 미검증 |
| Mock E2E scenario coverage 21 scenarios A–O | `03_Evidence/Test_Results/m_b9_summary.json` | `gate_status: PASS_WITH_WARNINGS`, mock only | **E2** | file | **모의 E2E** | 실 HIL 아님 |
| Test functions in repo | 99 files | **1,483 `def test_`** — count only | — | counted | 소스 내 테스트 함수 수 | 전체 실행 결과 아님 |
| Tests executed by me | see `work/test_runs/EXECUTED_TESTS.md` | **57 passed, 2 failed** (2 = missing packaged dataset manifest) | **E2** | executed | 본 세션 실행 결과 | TF/HW 의존 스위트 미실행 |
| Integrated 4-sensor HIL | — | **NONE FOUND** | **E0** | — | 미검증 | CRITICAL |
| Wi-Fi disconnect/recovery test | — | **NONE FOUND** (thermal cable-disconnect only) | **E0** | — | 미검증 | HIGH |
| Final integrated hardware photo | `03_Evidence/Hardware_Photos/*` = CO₂ bench only | not final build | **E3** | photos | CO₂ 벤치 실물 | CRITICAL |
| Final enclosure (printed) | `hardware/3d_models/*.stl` ×4 + 2 spec txt + 4 CAD renders (강유나 최종본) | design only | **E1** | files/images | 설계 완료 · 출력물 미확인 | 실제 출력물 사진 |
| Web dashboard with real sensor data | `03_Evidence/Dashboard/` **empty** | — | **E0** | — | 미검증 | HIGH |
| GitHub repo naming compliance | official rule `2026ESWContest_free_팀명` vs `safenest-embedded-competition` | noncompliant | — | — | — | CRITICAL |
| Demo video | storyboard PDF only | — | **E0** | — | 미제작 | CRITICAL |

## Datasets / external models (규정 제10조③ 대상)

| Sensor | Dataset | Source | License | Status |
|---|---|---|---|---|
| mmWave | Zenodo vital-sign, 110명·440rec·530window | DOI `10.5281/zenodo.18599983` | **CC BY 4.0** | 지도학습 backbone |
| Thermal | SDT Dataset, 32k train / 8k val / 8k real test, FLIR Lepton 3.5 | TU Wien / Zenodo `4124309` | **CC-BY-4.0 메타 vs 비상업 연구 제한 충돌 — 확인 필요** | T-A/T-B offline |
| CO₂ | UCI Occupancy Detection, 20,560행 | UCI ID 357 / Univ. of Mons | **CC-BY-4.0 VERIFIED** | C-A/C-B6 학습 |
| PIR | 없음 | — | — | 규칙만 |
| mmWave | repository NPZ 468 샘플 | 저장소 테스트 자산 | 내부 | **합성 — 실세계 근거로 사용 금지** |

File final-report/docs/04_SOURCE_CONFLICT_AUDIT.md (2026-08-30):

# 04_SOURCE_CONFLICT_AUDIT

Priority: ① Official docs ② Canonical source snapshot ③ Actual evidence ④ Team reports ⑤ Initial plan ⑥ External.
Snapshot = `jinsu1011/safenest-embedded-competition` @ `3f22fb145c…`, branch `codex/mmwave-m-c0-correspondence`, archived 2026-08-21 21:59 KST.

| # | Topic | Older / other source | Newer / canonical source | Interpretation | Report wording |
|---|---|---|---|---|---|
| **C1** | **Web/Backend stack** | 중간계획서: "Python(FastAPI) 게이트웨이 · SQLite 로그 DB · Chart.js 대시보드". 강유나 최종본: "Backend FastAPI · WebSocket · SQLite", HTTP 8000, `backend/app.py` | **Snapshot: FastAPI / SQLite3 / WebSocket 문자열이 401개 코드 파일 전체에 0건.** 실제는 `integration/pi_lcd/server.py` (Python **stdlib http.server**, HTTP 8080) + `integration/web` (**Express 5**) | 계획·타 브랜치의 스택이 정본에 병합되지 않음 | 보고서는 **정본 구현만** 기술: stdlib HTTP 서버 + Express. FastAPI/SQLite/WebSocket **언급 금지** |
| **C2** | **강유나 작업 브랜치 미병합** | 강유나 최종본: repo `yuname121/integration`, commit `9e4ddfe770d5…`, 파일 `gateway/protocol.py`, `receiver.py`, `thermal_udp.py`, `backend/`, `web/dashboard/`, `web/portal/`, `services/buzzer.py`, `services/emergency.py`, `deployment/run_pi.sh`. 자체 검증 "Python 153 tests OK" | **정본 스냅샷에 `gateway/`, `backend/`, `web/` 디렉터리 자체가 없음** (확인: `ls` → No such file or directory) | 병렬 개발 브랜치가 정본에 **미병합**. 153 tests는 정본에서 재현 불가 | 정본 기준으로 기술. 강유나 기여는 **정본에 실재하는 산출물**(display-test2 ESP32 노드, `raspberry_pi_lcd` 초기 서버, STL 4종, 설계사양 2종, PIR 어댑터)로 한정. 미병합 사실은 **팀장 확인 필요**로 내부 기록 |
| **C3** | **Thermal 전송 경로** | 중간계획서: XIAO에서 UDP로 Pi 전송. 김태균 v5 검증(2026-08-11): **XIAO-ESP32C6 단독 + UDP 5005 + 1,440 B 청킹**, ~7 FPS. 강유나: **UDP 5005 + SNTU v1 32 B 청크 헤더 + CRC32 + 9개 datagram(≤1,200 B)** | **정본 ESP32 노드: TCP 단일 연결, `PACKET_THERMAL_U16_BE`(type 2) 정의는 있으나 `THERMAL_STREAM_FRAMES = false`로 전송 비활성.** 실제로는 최고온도만 1 s telemetry에 포함 | **3세대 아키텍처가 병존**. 동시 설계가 아님 | 4번 항목(장애요인)에서 **시간 순 진화**로 서술: TCP 전 프레임 스트리밍 → telemetry 침해 확인 → 태스크/큐/청크/분주비/클럭 시도 → 대역폭 문제 잔존 → **정본은 송신측 요약(최고온도)으로 전환**. 별도 열화상 리그는 **UDP 분리 경로**로 검증되었음을 구분 표기 |
| **C4** | **UDP 청크 크기** | 김태균: 1,440 B | 강유나: ≤1,200 B, 9개 | 서로 다른 리그/브랜치 | 수치 단정 금지. "MTU 회피를 위한 청킹" 수준으로 기술하거나 출처를 명시 |
| **C5** | **MCU 보드** | 중간계획서·초기: **XIAO ESP32-C6** (RISC-V) | 정본 `.ino`: **ESP32 Dev Module / ESP-WROOM-32 DevKit V1**, 10개 신호선 단독 핀, RESET D25 | 보드 교체 확정 | "GPIO 자원 제약 → 보드 교체 → 열화상 nRESET 제어 확보 → 30 s 무프레임 자동 복구 가능" 인과로 기술. 단 **유승하 보고서가 인과를 `[검증 필요]`로 표기**했으므로 "기록된 제약 사실 + 결과"로만 서술 |
| **C6** | **열화상 센서 명칭** | 계획·정본: **Thermal-44 Camera** (80×62) | 김태균 최종검증문: "**Thermal-90 모듈**", 동시에 "Thermal-44 V5"도 사용 | 명칭 불일치 | 보고서는 정본 기준 **Thermal-44 (80×62, MI48xx)** 사용. Thermal-90 표기는 인용하지 않음. **팀 확인 필요** |
| **C7** | **AI 모델 검증 등급** | `model_manifest.json` (생성 2026-07-25): thermal·co2 = `CONFIRMED_SYNTHETIC_ONLY` | `03_Evidence/Thermal/*` (2026-08-11): 실 Thermal 프레임 → Pi 5 → 실 INT8 TFLite E2E ALL PASS | **매니페스트가 열화상에 한해 구식** | 열화상은 **실기기 E2E 검증**으로 상향 기술. CO₂·mmWave 모델은 **합성/오프라인 한정** 유지 |
| **C8** | **mmWave 모델 상태** | 계획: 1D-CNN/LSTM으로 무호흡 분류 | v0.1.0 `BLOCKED` (class collapse, acc 0.3996, abnormal/apnea recall 0.0) / v0.2.0 후보 acc 1.0이나 `SYNTHETIC_SMOKE_ONLY`·`NOT_VERIFIABLE` | 배포 가능한 검증 모델 없음 | **"재현성 검증 → 클래스 붕괴 발견 → 배포 차단"**을 공학적 성숙도 근거로 서술. acc 1.0은 **합성 한정**임을 같은 화면에 명시 |
| **C9** | **낙상 감지** | 계획: 낙상 시나리오. 김태균 v5 결론문: "인체 낙상 징후를 명확히 구분해냄" | 동일 문서 시나리오 D = "**안전하게 눕기**" → `HUMAN_FALL`. 김태균 본보고서 L47/490-491: LYING 정적 자세 프록시, 실제 낙상은 자세 전이·충격·지속·회복 실패 필요 | **낙상 사건 검증 아님** | "**눕기(LYING) 자세 기반 위험 후보 상태**", "정적 자세 proxy". `낙상 감지 완료`·`낙상 정확도` **금지** |
| **C10** | **Raspberry Pi AI 지연** | `MISSING_INPUTS.md`: "Actual Raspberry Pi AI latency — MISSING" | `phase11_12_fail_closed_benchmark.md`: Pi 5 실측 E2E mean 167.92 / p50 162.70 / p95 173.90 ms, 4.6 FPS | **열화상 채널 한정 실측은 존재** | "열화상 채널 실기기 E2E 지연"으로 **범위를 명시**하여 사용. 전 시스템 경보 지연으로 일반화 금지 |
| **C11** | **ESP32→Pi 실통신** | `MISSING_INPUTS.md`: NOT VERIFIED | CO₂ 검증 리포트: ESP32 `192.168.1.16` → Pi 5 `192.168.1.44:9000` TCP, 4개 세션 실측 | **CO₂ 단일 채널 실경로는 검증됨**; 4센서 동시는 미검증 | "CO₂ 채널 기준 ESP32→Pi 실경로 검증", "4센서 동시 수신 미검증"으로 분리 서술 |
| **C12** | **CO₂ 임계값** | 유승하 표: NORMAL 400–600 / CAUTION >1,000 / WARNING ≥1,500 / EMERGENCY ≥2,000. 구 스냅샷 `co2_ppm > 1500` 성분 1.0. 08.24 보고서는 별표2를 1,500만 적고 기본 1,000을 빠뜨림 | **현재 정본 `risk_formula_v1.json` 1.2.0**: 절대 주의 ≥1,500 ppm(별표2 비고), 밀실 기준값 \(B\)+700 상대 주의, 2,500 ppm도 주의 플로어, 즉시 위험 ≥5,000 ppm. 별표2 기본 1,000은 트립 아님. occupancy 모델은 점수 제외 | 유승하 2,000 EMERGENCY와 V4 1,500=위험은 **폐기**. 필드 idle ~1,184 ppm을 1,000 주의로 올리면 상시 경보 | 보고서 P10은 v1만 기술. "안전기준 준수" 금지. 출처 표는 `09_SAFETY_CRITERIA_V1.md` |
| **C13** | **LCD 아키텍처** | `display-test/`, `display-test2/raspberry_pi_lcd/` (독립 수신·상태) | 정본 `integration/pi_lcd/server.py` (동일 계보의 최신본, 테스트 13종) | 레거시 2벌 + 정본 1벌 | 정본만 현재 런타임으로 기술. display-test·display-test2는 **초기/레거시**로 구분 |
| **C14** | **테스트 수** | 강유나: "153 tests OK"(자기 브랜치). `INTEGRATION_PROGRESS.md`: "84 tests OK, skipped=2". `PROJECT_PROGRESS.md`: "devices 46 passed, on-device/provider 23 passed" | 저장소 정적 카운트 **1,483 `def test_`** / **본 세션 실행 57 passed, 2 failed** | 시점·범위가 모두 다름 | 숫자를 합치지 않음. 보고서에는 **본 세션 실행값**과 **소스 내 테스트 함수 수**를 분리 표기 |
| **C15** | **응용 범위 드리프트** | 계획: 밀폐공간 + 통학차량. 강유나 최종본: "실내 안전 모니터링", 김태균 자료조사: 독거노인·고령자 | 정본 QR: `밀폐공간_A-01`, `통학차량_B-02`, `창고_C-03` | 1차 범위는 밀폐공간·차량 | 주 적용처 = **밀폐공간**, 부 = **차량 내부**. 고령자·독거 시나리오는 **확장 가능성**으로만 |
| **C16** | **중간계획서 출처** | `01_Initial_Plan` 원본 파일명 = `창의혁신공모전_중간계획서`, 제목 = "제5회 창의혁신 공모전 중간계획서" | 본 대회는 제24회 임베디드SW경진대회 | **타 공모전 제출 계획서** | 대회 보고서에서 계획서를 인용할 때 **본 대회 제출물로 오인될 표현 금지**. 규정 제10조④ 관련 사실은 정확히만 기술 |
| **C17** | **Thermal frame 요청 FPS** | 강유나: "약 6.25 FPS, divider 4 기준" | 정본 `.ino`: `THERMAL_FRAME_RATE_DIVIDER = 8` → 약 3.125 FPS | 강유나는 구(display-test2) 펌웨어 기준 | 정본 값(divider 8, ~3.125 FPS, 1 MHz에서 프레임당 ~81 ms) 사용 |
| **C18** | **display-test2 펌웨어에 CRC 없음** | 유승하 문제#5: CRC-16/CCITT-FALSE 도입 | 정본 `devices/esp32_node` 에 `thermalFrameCrc()` **존재**, `display-test2` 펌웨어에는 **없음** | CRC는 정본에만 반영 | CRC 관련 서술 시 **정본 파일 경로**를 근거로 표기 |

## 처리 원칙

1. 서로 다른 세대의 아키텍처를 **동시 설계인 것처럼 합치지 않는다**.
2. 정본에 없는 구성요소(FastAPI·SQLite·WebSocket·gateway·backend·web/dashboard)는 **보고서에 등장시키지 않는다**.
3. 팀원 보고서의 결론 문장이 같은 문서의 데이터와 충돌하면(**C9**), **데이터를 따른다**.
4. 범위가 다른 실측치(**C10, C11**)는 삭제하지 않고 **범위를 명시**하여 사용한다.

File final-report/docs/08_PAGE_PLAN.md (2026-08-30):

# 08_PAGE_PLAN — 표지 + 콘텐츠 20p (공식 3+10+5+2)

배지 표기: `구현 완료` `SW 검증` `오프라인 AI 검증` `실기기 검증` `통합 HIL` `미검증` `향후 검증`

---
## 표지 (콘텐츠 미포함)
제24회 임베디드SW경진대회 개발완료보고서 / 자유공모 부문 / SafeNest — 엣지 AI 기반 밀폐공간·차량 생명감지 및 위험도 자동경보 시스템 / `[팀번호 확인 필요]_가만있어도SANDI` / 경희대학교

---
# SECTION 1 · 개발 개요 (3P)

## P1 — 「밀폐공간 사고는 '사람이 쓰러진 뒤'에 발견된다」
- 결론: 사고를 못 막는 이유는 감지 수단이 없어서가 아니라, **사람의 상태를 상시 확인할 수단이 없기 때문**.
- 근거: 2014~2023 밀폐공간 질식재해 174건 / 재해자 338명 / 사망 136명(치명률 약 42%) — 각주 "고용노동부 보도자료(2024) 인용, **원문 확인 필요**"
- 산업안전보건법 제619조: 농도 측정 + 감시인 배치 의무 → 소규모 사업장은 상시 배치가 현실적으로 어려움
- 시각: 문제 다이어그램(작업자 진입 → 이상 발생 → 발견 지연 → 사고)
- 심사: 독창성(동기·배경)
- 상태: 통계 `[출처 원문 확인 필요]`

## P2 — 「단일 센서는 '값'은 주지만 '사람이 안전한지'는 답하지 못한다」
- 비교표 (○/△/×): 가스감지기 / CCTV / PIR / 웨어러블 / 단일 mmWave / 단일 열화상 × 축(정지 인체 / 사생활 / 미착용 / 환경 / 오탐 구분)
- 각 한계는 단정 대신 조건부(△) 사용
- **SafeNest 관점 도입**: 문제는 센서 개수가 아니라 "이 증거를 지금 믿어도 되는가"
- 심사: 독창성(차별성)

## P3 — 「SafeNest: 카메라 없이, 증거의 유효성까지 판단하는 엣지 안전 노드」
- 개발 목표 ①~④ (중간계획서 기준, **초기 개발 목표**로 명시)
- 개념도: 4채널 증거 → 유효성/신선도 → 규칙+엣지AI → 위험도(정상 R<30 / 주의 30–65 / 위험 R≥65 / 판단 보류) → 경보/표시/기록
- **소스코드**: `https://github.com/jinsu1011/safenest-embedded-competition` (실제 URL)
- **시연동영상**: `[최종 시연동영상 URL 입력 필요]` — 하이퍼링크 생성 금지
- 심사: 독창성 / 공식 필수(링크)

---
# SECTION 2·3·4 · 개발 환경 + 프로그램 설명 + 장애요인 (10P)

## P4 — 「SafeNest는 3계층 엣지 구조로 동작한다」
- 계층: 감지(4센서) → 수집·검증(ESP32) → 판단(Raspberry Pi 5) → 대응(부저/LCD/Web/로그)
- 개발환경 표: Arduino/PlatformIO(ESP32), Python 3(Pi, 표준 라이브러리 중심), Node.js Express 5(Web), TensorFlow 2.19.1(학습), TFLite INT8(추론), macOS/Pi OS
- **주의: FastAPI·SQLite·WebSocket은 정본 미구현 → 등장 금지 (C1)**
- 심사: 기술성

## P5 — 「4개 센서를 서로 다른 버스로 한 노드에 통합했다」
- 인터페이스 표: MR60BHA2 **UART2** 115200 (RX16/TX17) / SCD4x **I2C** 0x62 (SDA21·SCL22) / PIR **GPIO13** / Thermal-44 **I2C 0x40·0x41 제어 + SPI 데이터** (SCLK18·MISO19·MOSI23·CS27·READY26·**RESET25**)
- 사진 A1(회전 보정) + 3D 개구부 렌더 A8
- 캡션: "CO₂ 검증용 벤치 구성 — **최종 통합 4센서 완제품 아님** `[최종 통합 하드웨어 사진 교체 필요]`"
- 심사: 기술성

## P6 — 「저장소는 기기·책임 영역 기준으로 나뉜다」
- 주요 모듈 표 (경로 / 역할 / 입력 / 출력): `devices/esp32_node/firmware/esp32_sensor_node.ino`, `devices/{mmwave,co2,pir,thermal}/src/`, `shared/contracts/base_sensor.py`, `ondevice_ai/{inference,risk,integrated_node}/`, `integration/pi_lcd/server.py`, `integration/web/`, `hardware/3d_models/`
- 외부 OSS/데이터셋 고지 (규정 제10조③): Zenodo CC BY 4.0 / UCI CC-BY-4.0 / SDT(라이선스 확인 필요) / TFLite / Express
- 심사: 기술성, 정보전달력

## P7 — 「센서에서 게이트웨이까지: SafeNest TCP protocol v1」
- 16바이트 헤더 도해: `SNST`(4) · version 1 · type(1 JSON / 2 thermal) · flags(2) · sequence u32 · payload_length u32, network byte order
- TCP는 경계를 보존하지 않음 → `recv_exact()` 길이 접두 프레이밍
- 주기: PIR 20 ms / CO₂ 250 ms / telemetry 1,000 ms
- 코드 스니펫(3~5줄): `formatNullableFloat()` — **invalid → `null`**
- 심사: 기술성(임베디드SW)

## P8 — 「0은 측정값이지만, 결측은 측정값이 아니다」 ★핵심
- 판정 흐름도: 수신 → magic/version/length 검사 → 스키마 검사 → `valid{}` 확인 → TTL 검사 → LIVE / STALE / INVALID / DISCONNECTED
- 이중 신선도: ESP32(mmWave 5 s · CO₂ 15 s · Thermal 30 s) + Pi(5 s) 독립 판정
- 열화상 무결성: **CRC-16/CCITT-FALSE**(poly 0x1021, init 0xFFFF) + 헤더 min/max 재계산 대조 + 내외부 sequence 일치 + 사용 가능 화소 ≥32 → 불일치 프레임 폐기
- 30 s 무프레임 → GPIO RESET 재초기화
- 배지: `구현 완료` `SW 검증`(본 세션 13 tests 통과)
- 심사: 기술성 + 독창성

## P9 — 「온디바이스 AI는 '모델이 있다'와 '검증됐다'를 구분한다」
- 모델 3종 표: 입력 / 출력 / 양자화 / 검증등급 / 배포상태
  - Thermal `thermal_fall_int8_v0.1.0` (62×80×1 INT8 → 3class) — **실기기 E2E 검증**, 단 `HUMAN_FALL` = **눕기(LYING) 정적 자세 프록시**
  - CO₂ `co2_occupancy_int8_v0.1.0` (3특징 → 2class) — 합성/오프라인 한정
  - mmWave `mmwave_resp_int8` (300샘플 30 s 창 → 3class) — **v0.1.0 배포 차단**, v0.2.0 후보는 **합성 한정**
- 실측(열화상 채널, Pi 5): p50 162.70 / p95 173.90 ms, 4.6 FPS, 유효 97.8% — **범위 명시**
- 차트 CH2 또는 열화상 스팟체크 A9
- 심사: 기술성

## P10 — 「NORMAL과 UNKNOWN은 다르다」 ★최강 페이지
- 정본: `RaspberryPi/Runtime/risk/formula_v1.py` + `risk_formula_v1.json` (`SAFENEST_RISK_V1`)
- 상세 정책: `docs/09_SAFETY_CRITERIA_V1.md`
- R = 100 × (0.25·mmWave + 0.30·CO₂ + 0.15·PIR + 0.30·Thermal)
- 정상 R<30 / 주의(WARNING) 30–65 / 위험 R≥65. 구 V4 CAUTION·R≥60 사용 금지
- 채널 플로어: CO₂ ≥1,500 ppm 주의(별표2 기계환기 예외) 또는 밀실 기준값 \(B\)+700. ≥5,000 ppm 즉시 위험. occupancy는 점수 제외
- 열화상 `HUMAN_FALL_PROXY`는 점수 0.4·비상 없음. mmWave 신경망은 관측 전용, 하드웨어 확인 apnea만 즉시 위험
- 유효 센서만으로 가중치 재정규화. 유효 가중치 <0.5 이면 정상을 INDETERMINATE로 내림
- 전 센서 무효 → `risk_score=None`, `risk_level=None`, `system_health=FAILED`
- 계산 예시(엔진 실행): CO₂ 1,500 ppm + 평온 인체 → R=9.75 정상, 플로어로 주의
- occupancy 로컬라이징은 본 식에서 제외
- 배지: `SW 검증` (`tests/test_risk_formula_v1.py`)
- 심사: 기술성 + 독창성

## P11 — 「실제로 어디까지 돌아가는가」
- 런타임: `integration/start_all.sh` → TCP 9000 수신 + HTTP 8080(`/display` `/control` `/api/state` `/health`) + 부저 GPIO18 880 Hz + 6개 상태
- **차트 CH1**: 실측 CO₂ 6분 세션 (호기 상승 1,493 ppm → 복귀 634 ppm) + **결측 구간을 잇지 않고 공백 표시**
- 검증 매트릭스(요약): 채널별 구현/SW검증/실기기/통합HIL
- 미확보 항목 명시: 실센서 대시보드·LCD 캡처 `[추가 증거 필요]`, 4센서 동시 수신 `미검증`
- 심사: 기술성, 정보전달력

## P12 — 「열화상 스트리밍이 telemetry를 밀어내 전송 구조를 바꿨다」 (장애요인 ①)
- 문제: type 2 프레임 9,952 B × 약 6.25 fps ≈ 60 KB/s를 ESP32 Wi-Fi 단일 TCP로 전송 → 1초 telemetry 주기 붕괴
- 시도 5가지: FreeRTOS 태스크 분리 / 큐 1칸 `xQueueOverwrite` / 512 B 청크 / divider 4→8 / SPI 8 MHz→1 MHz
- **실패 인정**: 구조 개선은 지연을 감췄을 뿐 링크 총 바이트를 줄이지 못함
- 최종: `THERMAL_STREAM_FRAMES = false` — 송신측에서 요약(가장 뜨거운 16화소 중 최저값)만 1초 telemetry에 포함
- 잃은 것: LCD 열화상 영상 제외 (정직하게 명시)
- 별도 열화상 리그는 UDP 분리 경로로 검증됨(범위 구분)
- 심사: 기술성(난이도·문제해결)

## P13 — 「나머지 세 가지 실제 임베디드 문제」 (장애요인 ②)
- ① **GPIO 자원**: XIAO ESP32-C6 외부 11핀 중 D6/D7(내부 UART), D3(레이더 부트/리셋), D1(RGB LED 공유) 제약 → nRESET 미연결 시 카메라 부팅 시퀀스·자동복구 불가 → **ESP32 DevKit V1 교체**, 10신호선 단독 배정, RESET D25 확보
- ② **신호 무결성**: 브레드보드·점퍼에서 SPI 8 MHz·I2C 400 kHz 판독 누락 → **SPI 1 MHz / I2C 100 kHz**, 프레임당 약 81 ms로 divider 8의 160 ms 예산 내 → `READOUT_TOO_SLOW` 해소
- ③ **AI 재현성**: mmWave v0.1.0 재현 검증에서 **클래스 붕괴**(468/468 NORMAL, abnormal·apnea recall 0.0) → **배포 차단(`deployment_allowed:false`)** 후 후보 재수립
- 메시지: 실패를 지우지 않고 차단·기록한 것이 안전 시스템의 요건
- 심사: 기술성

---
# SECTION 5·6 · 차별성 + 파급력 (5P)

## P14 — 「SafeNest의 기술적 차별성 5가지」
① 이종 센서 **증거 융합**(값 수집 아님) ② 카메라 없는 프라이버시 보존 감지 ③ **유효성·신선도를 1급 상태로 관리** ④ **fail-closed: NORMAL≠UNKNOWN** ⑤ 규칙+엣지 AI 하이브리드와 **검증 등급에 따른 배포 통제**
- 각 항목에 근거 파일 경로 + 배지

## P15 — 「기존 방식과의 비교」
- 카테고리 비교표: 사생활 / 정지 인체 증거 / 환경 감시 / 로컬 처리 / 다중 증거 / 무효 데이터 인지 / 이벤트 로그 / 확장성
- 마케팅 체크박스 금지, △ 적극 사용, SafeNest 미구현 항목도 △/× 표기

## P16 — 「현재 완성도: 무엇이 검증됐고 무엇이 남았는가」
- 표: 구성요소 / 구현 / 검증 / 증거 / 남은 과제
  - ESP32 4센서 노드 ● / SW / `.ino` / 4센서 동시 실측
  - SNST v1 송수신 ● / SW(13) / `server.py` / —
  - 유효성·신선도 ● / SW / `fallback.py` / 통합 HIL
  - Risk 엔진 ● / SW(22) / `risk_engine.py` / 실입력 HIL
  - mmWave 채널 ● / **실기기** / 9.990 Hz·오류 0 / 통합
  - CO₂ 채널 ● / **실기기(부분)** / 4세션 CSV / 분리 로그
  - Thermal 채널 ● / **실기기 E2E** / p95 173.9 ms / 정본 노드 경유
  - Web/LCD ● / SW / 13 tests / 실센서 캡처
  - 하우징 ◐ / 설계 / STL 4종 / 출력·조립
- 본 세션 실행: **57 passed / 2 failed** + 소스 내 테스트 함수 1,483개(실행 결과 아님)

## P17 — 「1차 적용처는 밀폐공간, 확장은 차량·창고」
- 주 적용: 맨홀·정화조·집수정 등 밀폐공간 무인 감시 (산안법 제619조 대응 보조)
- 확장 가능성: 통학차량 잔류 감지 / 냉동·양생 창고 (저장소 QR 3종 실재: 밀폐공간 A-01, 통학차량 B-02, 창고 C-03)
- 기대효과는 "가능성"으로 서술, 매출·시장규모 단정 금지

## P18 — 「프로토타입에서 현장까지: 단계형 로드맵」
- 현재(프로토타입, 채널별 검증) → 통합 HIL → 하우징 출력·조립 → 현장 데이터 수집·보정 → 다중 노드 → 인증·평가
- 3D CAD 렌더 A5/A6/A7 배치 + 치수(센서 137×80×60 mm, LCD 240×140 mm, 슬롯 3.5 mm, 편측 유격 0.25 mm)
- 완료된 것/미완료를 시각적으로 명확히 구분

---
# SECTION 7 · 일정 + 업무 분장 (2P)

## P19 — 「실제 개발 일정과 주요 설계 변경」
- 계획 대비 실제: 7월 설계·부품 → 8/1 mmWave 장시간 로그 → 8/2~8/3 저장소 통합·책임영역 재편(`38274c0`) → 8/8 mmWave 라이브 검증·리플레이 벤치 → 8/11 열화상 v5 실기기 E2E → 8/12 CO₂ 실측 4세션 → 8/16~8/21 mmWave M-C0 정합·스냅샷(`3f22fb1`)
- 주요 설계 결정 3개 표시: 보드 교체 / 열화상 전송 구조 전환 / 모델 배포 차단
- **미완료 구간도 표시** (통합 HIL, 시연영상)

## P20 — 「5인 책임 영역과 인터페이스」
- 근거: `.github/CODEOWNERS` (2026-08-03 collaborator 권한 확인 기재) + 실제 산출물
  - **김진수**(팀장, @jinsu1011): mmWave 펌웨어·어댑터·실측, 저장소 통합·구조, 문서 — `devices/mmwave/`, `docs/`
  - **유승하**(@yuseungha): CO₂(SCD40) 연동·실측 4세션, ESP32 4센서 노드, Pi LCD/부저 서버, 회로 — `devices/co2/`, `devices/esp32_node/`, `integration/`
  - **김태균**(@rla1729): Thermal-44 드라이버·프레임 파서·전처리, 열화상 온디바이스 AI 실기기 검증 — `devices/thermal/`
  - **한준우**(@sheepmeat): 데이터셋 출처·분할, 모델 학습·비교·재현, Pi AI 준비, 위험 판단 연계 — `ondevice_ai/`, `shared/contracts/`
  - **강유나**(@yuname121): PIR 어댑터, 3D 하우징 CAD 4종·설계사양, LCD/Web 초기 골격 — `devices/pir/`, `hardware/3d_models/`
- 인터페이스: 센서 계약(`shared/contracts/base_sensor.py`) → 텔레메트리 스키마 `safenest.telemetry.v1` → Risk 입력 계약
- **내부 주의**: 강유나 최종 산출물 상당수가 `yuname121/integration` @ `9e4ddfe…`에 있으며 정본 미병합 → `[팀장 확인 필요]`

---
## 페이지 배분 검증
1(3) + 2·3·4(10: P4–P13) + 5·6(5: P14–P18) + 7(2: P19–P20) = **20** ✅ 표지 제외

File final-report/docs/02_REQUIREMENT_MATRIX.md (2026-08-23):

# 02_REQUIREMENT_MATRIX

## A. 공식 필수 항목 → 페이지 대응

| 공식 요구사항 | 보고서 페이지 | 증거 | 상태 | 위험 |
|---|---:|---|---|---|
| 1. 개발 개요 — 배경 | 1 | 고용노동부 밀폐공간 질식재해 통계(중간계획서 인용, **원문 재확인 필요**) | 계획 | 통계 원문 미확보 |
| 1. 개발 개요 — 동기·필요성 | 2 | 기존 방식 한계 비교(계획서 + 정본 구현 근거) | 계획 | — |
| 1. 개발 개요 — 목표 | 3 | 중간계획서 개발목표 ①~④ | 계획 | KPI는 "초기 개발 목표"로만 |
| 1. **소스코드 링크(필수)** | 3 | `https://github.com/jinsu1011/safenest-embedded-competition` | **삽입 예정** | repo 명명 규칙 위반 |
| 1. **시연동영상 링크(필수)** | 3 | 없음 | **MISSING** | **CRITICAL — 예선 필수** |
| 2. HW 구성 및 기능 | 5 | `esp32_sensor_node.ino` 핀맵, 실물 사진, 3D CAD 4종 | 계획 | 최종 통합 사진 없음 |
| 2. SW 구성 | 4, 6 | 정본 디렉터리 트리, `package.json`, `server.py` | 계획 | — |
| 2. 기능 설계도 | 4 | 계층 아키텍처 다이어그램(정본 기준) | 계획 | — |
| 2. 개발 환경 | 4 | PlatformIO/Arduino, Python 3, Node.js, Pi 5 | 계획 | — |
| 3. 파일 구성 | 6 | 모듈별 경로·입출력 표 | 계획 | — |
| 3. 함수별 기능 | 6, 8, 10 | `formatNullableFloat`, `thermalFrameCrc`, `recoverThermalIfStale`, `evaluate_sensor_health_and_risk` | 계획 | — |
| 3. 흐름도 | 7, 8, 10 | 센서→ESP32→Pi 흐름 / 유효성 판정 흐름 / Risk 판정 흐름 | 계획 | — |
| 3. 기술적 차별성 | 9, 10, 14 | fail-closed, null≠0, 배포 차단 | 계획 | — |
| 4. 장애요인과 해결방안 | 12, 13 | 대역폭·GPIO·신호무결성·CRC·클래스 붕괴 | 계획 | — |
| 5. 차별성·우수성 | 14, 15, 16 | 비교표 + 완성도 매트릭스 | 계획 | — |
| 6. 파급력·기대효과 | 17, 18 | 활용처 + 로드맵 | 계획 | 시장 수치는 계획서 인용, 원문 재확인 필요 |
| 7. 개발 일정 | 19 | 실제 마일스톤(커밋·검증일자 기반) | 계획 | — |
| 7. 업무 분장 | 20 | CODEOWNERS + 실제 산출물 | 계획 | 강유나 브랜치 미병합 |
| ≤20 콘텐츠 페이지 | 1–20 | — | **PASS (표지 별도)** | — |
| PPT 작성 → PDF 제출 | — | PPTX → PDF | 계획 | — |

## B. 심사 항목 → 페이지 대응

| 심사 항목 | 배점 | 담당 페이지 | 주력 증거 | 현재 약점 |
|---|---:|---|---|---|
| **독창성** | **30** | 1, 2, 3, 14, 15 | ① 이종 센서 **증거 융합**(값 수집이 아님) ② 비영상 프라이버시 보존 ③ 유효성·신선도를 1급 상태로 다루는 설계 ④ NORMAL≠UNKNOWN | 유사 연구 대비 정량 비교 부재 |
| **기술성 및 완성도** | **30** | 4–13, 16 | UART/I2C/SPI/GPIO 실배선, SNST v1 프로토콜, CRC-16, 자동 재초기화, 신호무결성 조정, fail-closed(실행 22 tests), 열화상 실기기 E2E(p95 173.9 ms), mmWave 9.990 Hz·오류 0, 모델 배포 차단 | **통합 4센서 HIL 부재**, AI 2종 합성 한정 |
| **활용성** | **20** | 17, 18 | 밀폐공간 1차 적용 + 차량·창고 QR 3종, 단계형 로드맵 | 시장 수치 원문 미확인, 현장 파일럿 없음 |
| **정보전달력** | **10** | 전 페이지 | 결론형 제목, 증거 등급 배지, 각주 출처 | — |
| **팀 구성 및 팀 역량** | **10** | 20 (+19) | CODEOWNERS 5인 책임 영역, 실제 산출물, 인터페이스 계약 | 강유나 산출물 미병합, 팀번호 미확인 |

**독창성+기술성 = 60/100** → 페이지 4–16(13쪽)이 기술·차별성에 배정되어 배점 비중과 정렬됨.

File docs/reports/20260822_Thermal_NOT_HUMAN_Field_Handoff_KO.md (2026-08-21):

# 열화상 필드 상황 인수인계 (NOT_HUMAN / 육안 불일치)

- **작성일:** 2026-08-22 (KST)
- **대상 레포:** `jinsu1011/safenest-embedded-competition`
- **세션 성격:** 실행 중 런타임 **수정 없이** 관측·누적 데이터 검토
- **관련 측정 기록:** [`measurements/20260822_thermal_field_measurement_record.json`](./measurements/20260822_thermal_field_measurement_record.json)

---

## 1. 한 줄 요약

열화상 **수신·저장·추론 파이프라인은 동작**한다.  
실시간 화면에서 사람 형체가 보여도, production 모델 `thermal_fall_int8@0.1.0` 은 필드에서 **`NOT_HUMAN`으로 과다 분류**한다.  
우선 확인할 것은 **재학습이 아니라 보정/전처리 계약(°C·학습 도메인 vs 런타임 `per_frame_minmax`)** 이다.

---

## 2. 네트워크 / 호스트 정리

| 역할 | 관측 주소 | 비고 |
|---|---|---|
| Raspberry Pi (SafeNest `:8000`) | **`192.168.137.249`** | health/status 응답. 사용자가 “와바튼 IP”로 부른 주소는 **Pi** |
| ESP peer (thermal/telemetry) | **`192.168.137.107`** | `thermal.state.peer` |
| 이전 필드 Wi‑Fi IP (참고) | `192.168.0.3` (`EELabO3 2G`) | 이후 `192.168.137.x` 망으로 이동 |

---

## 3. 관측된 증상

1. LCD/상태 API에서 열화상 AI가 **`NOT_HUMAN`**
2. 운영자가 **인식거리에서 실시간 열화상 화면으로 사람 형체를 육안 인지**
3. 동시에 mmWave는 종종 `presence=true` / `human_detected_raw=true`
4. Risk reasons에 **`MMWAVE_THERMAL_MISMATCH`** 등장
5. 시스템: `ONLINE` / **`DEGRADED`** (수신은 되나 센서 간 불일치·폴백)

---

## 4. 측정 기록 (요약)

상세 JSON:  
- [`20260822_thermal_live_api_snapshot.json`](./measurements/20260822_thermal_live_api_snapshot.json)  
- [`20260822_thermal_npz_tally.json`](./measurements/20260822_thermal_npz_tally.json)  
- 통합: [`20260822_thermal_field_measurement_record.json`](./measurements/20260822_thermal_field_measurement_record.json)

### 4.1 라이브 API 스냅샷 (동일 세션 후반)

| 항목 | 값 |
|---|---|
| Pi | `192.168.137.249:8000` |
| system | `ONLINE` / `DEGRADED` |
| TCP connections | 4 |
| telemetry_packets | 15987 |
| thermal completed_frames | 10074 |
| thermal incomplete_frames | 424 |
| effective_fps | ~5.19 |
| storage written thermal | 10068 |
| storage written mmwave | 15987 |
| thermal status | `LIVE` |
| AI state | **`NOT_HUMAN`** |
| confidence | ~0.992 |
| probabilities | `[0.992, 0.008, 0.0]` → class0 우세 |
| preprocessing | `per_frame_minmax` |
| temperature_calibrated | **`false`** |
| raw min–max (예) | 2722–3172 |
| model | `thermal_fall_int8` / `0.1.0` |
| mmWave presence / raw | `true` / `true` |
| risk formula | `SAFENEST_RISK_V1` |
| risk reasons (예) | `PRESENCE_FROM_MMWAVE`, `MMWAVE_THERMAL_MISMATCH`, `HIGH_CO2_WARNING`, `NO_MOTION_DETECTED` |
| component_status | thermal=`AI`, mmwave=`RULE_FALLBACK`, co2=`RULE`, pir=`RULE` |

### 4.2 누적 NPZ 집계 (디스크)

경로(파이): `/home/sandi/safenest-team-main/RaspberryPi/Runtime/data/thermal/`  
포맷: `frames (N,62,80) uint16` + `analysis_json`(프레임별 AI 스냅샷)

| 항목 | 값 |
|---|---|
| on-disk npz | 3516 |
| readable npz | 3484 |
| 최근 500파일 analysis frames | 6163 |
| `NOT_HUMAN` | 5879 (~95.4%) |
| `HUMAN_NORMAL` | 189 |
| `HUMAN_FALL` | 95 |
| HUMAN_* 합 | 284 (~4.6%) |
| raw span mean (최근) | ~465.5 (min 280 / max 1017) |
| hot≥0.75 픽셀 수 mean | ~434 (공간 핫스팟 존재) |

### 4.3 동일 밤 더 이른 프로브 (참고)

약 01:15 KST 부근 최근 500파일 창에서는 `HUMAN_* = 0`, `NOT_HUMAN` 지배였다.  
후반 창에서는 HUMAN 소수가 나타나지만 **여전히 NOT_HUMAN 과다**.

### 4.4 공간 구조 (육안과 정합)

최근 npz 샘플에서 per-frame min-max 후 상위 핫픽셀·centroid가 관측됨 → **빈 노이즈 프레임이 아님**.  
UI `heatmap_preview`도 동일 min-max로 대비를 키워 **형체가 잘 보이게** 만듦.

---

## 5. 원인 분석 (우선순위)

### P0 — 보정/전처리 계약 불일치 가능성 (**먼저 체크**)

| 런타임(production) | 오프라인 O2/문서 경로 |
|---|---|
| `temperature_calibrated: false` | `uint16 → Celsius (raw/10 − 273.15)` 등 물리 도메인 |
| `preprocessing: per_frame_minmax` | P1 global z-score 등 학습 파이프라인 |
| 모델 입력: min-max 후 INT8 | T-B5/O2 리플레이는 별 계약 |

문서(`PHASE5_AI` 등)도 production은 “°C 미추정, 공간 패턴만”이라고 명시.  
**학습/검증이 물리 도메인이면**, 지금 런타임 경로만으로 `NOT_HUMAN` 과다 → **재학습 전에 계약 정렬·재추론 비교**가 맞다.

### P1 — 도메인 시프트 / 모델 편향 (계약이 맞을 때의 후보)

전처리가 학습과 동일한데도 HUMAN이 희귀하면 → 재학습·필드 데이터 적응 검토.

### 아님 (이번 세션에서 기각)

- ESP↔Pi 미연결, thermal `NO_DATA` → **아님** (`LIVE`, fps·written 증가)
- “형체가 데이터에 없다” → **아님** (핫픽셀·centroid·육안 preview)

---

## 6. UI vs AI가 어긋나 보이는 이유

1. 화면 preview와 모델 모두 **프레임별 min-max** → 눈에는 사람처럼 보임.  
2. 분류기는 학습 분포의 ‘사람’ 특징을 요구 → 필드 raw/스케일이 다르면 **고대비 블롭 ≠ HUMAN_***.  
3. mmWave는 재실을 말하고 thermal은 `NOT_HUMAN` → Risk가 mismatch를 기록 (정상 동작).

---

## 7. 인수인계 — 다음에 할 일 (권장 순서)

1. **(수정 없이)** 저장된 npz raw에 O2식 `°C = raw/10 − 273.15` 적용 후 **동일 `thermal_fall_int8` 재추론** → 클래스 분포 비교.  
2. 학습/매니페스트 계약이 `normalized_thermal_frame` + min-max인지, °C/P1인지 **문서·학습 스크립트와 대조**.  
3. 전처리만 맞춰도 HUMAN이 유의미하게 늘면 → **런타임 전처리 PR** (재학습 아님).  
4. 맞춰도 `NOT_HUMAN` 고착이면 → 필드 npz 라벨/재학습 이슈로 에스컬레이션.  
5. 운영 PASS 관점: thermal AI만으로 재실을 단정하지 말 것. mmWave mismatch·`DEGRADED`를 명시.

**금지(현 세션 합의):** 라이브 런타임 핫패치로 결론 확정하지 말 것. worktree → PR → merge → Pi pull.

---

## 8. 관련 코드/문서 포인터

| 항목 | 위치 |
|---|---|
| production AI 경로 | `RaspberryPi/Runtime/ai/pipeline.py` (`temperature_calibrated: False`, `per_frame_minmax`) |
| TFLite wrapper | `RaspberryPi/Ondevice_AI/inference/thermal_interpreter.py` (`_prepare_float_frame` min-max) |
| 클래스맵 | `NOT_HUMAN` / `HUMAN_NORMAL` / `HUMAN_FALL` |
| 필드 모니터 | `RaspberryPi/Runtime/hil/pi_field_monitor.py` (표3 thermal `ai_state`) |
| Pi 런북 | `PI_RUNBOOK.md` |
| O2 °C 리플레이 | `RaspberryPi/Runtime/hil/thermal_o2_real_snapshot_replay.py` |

---

## 9. 측정 재현 명령 (읽기 전용)

```bash
# 라이브
curl -s http://192.168.137.249:8000/api/status | python3 -m json.tool | less

# 필드 모니터
cd /home/sandi/safenest-team-main/RaspberryPi/Runtime
python3 hil/pi_field_monitor.py --once

# 누적 npz (파이 로컬)
ls RaspberryPi/Runtime/data/thermal | wc -l
```

---

## 10. 인수 체크리스트

- [ ] Pi IP / ESP peer 구분 이해 (`249` = Pi, `107` = ESP)
- [ ] thermal LIVE·저장 증가·`NOT_HUMAN` 과다 재현 가능
- [ ] 육안 형체 vs AI 불일치가 “수신 실패”가 아님을 공유
- [ ] **다음 액션 = 보정/전처리 계약 검증** (재학습은 그 다음)
- [ ] 본 문서 + `measurements/*.json` 이 팀 main에 merge됨

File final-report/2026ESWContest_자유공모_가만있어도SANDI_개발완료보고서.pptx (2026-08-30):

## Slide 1

제24회 임베디드SW경진대회 개발완료보고서

자 유 공 모 부 문

SafeNest

엣지 AI 기반 밀폐공간·차량 생명감지 및 위험도 자동경보 시스템

가만있어도SANDI

경희대학교 전자공학과

김진수 · 유승하 · 김태균 · 한준우 · 강유나

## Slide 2

Ⅰ. 개발 개요

1.1 밀폐공간 질식재해 현황과 개발 필요성

재해 통계 (최근 10년, 2014~2023)

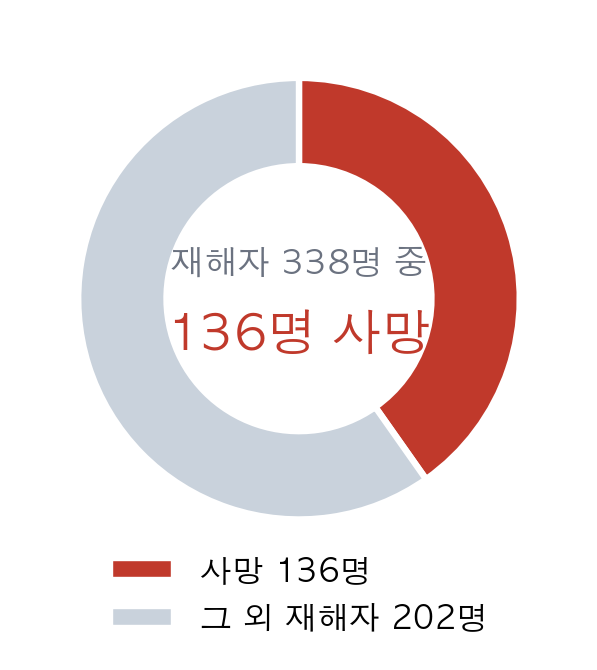
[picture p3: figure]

밀폐공간 질식재해 발생 건수

174건

제도와 현실의 간극

· 산업안전보건법 제619조는 밀폐공간 작업 시 산소·유해가스 농도 측정과 감시인 배치를 사업주 의무로 규정한다.

· 중대재해처벌법 확대 적용으로 소규모 사업장까지 예방 설비 수요가 늘었다.

· 감시인 상시 배치가 어려운 소규모 사업장이 대다수여서, 사람의 상태까지 자동으로 확인하는 무인 감시 수단이 필요하다.

재해자

338명

사망자

136명

검찰 송치 중대재해 중
산소·유해가스 농도 미측정 상태에서 발생

85.7%

사고 진행 단계와 현재 감시 수단의 공백

가스 감지기·PIR·CCTV가 사람의 상태를 놓치는 구간

작업자 진입

밀폐공간 내부

이상 발생

산소결핍·유해가스

움직임 정지

스스로 신고 불가

▼

발견 지연

감시인 부재

▼

사고 확정

구조 골든타임 경과

▶

▶

▶

▶

SafeNest는 이 구간에서 사람의 존재와 상태를 자동으로 확인하고 현장에 경보를 낸다.

※ 출처 : 고용노동부 밀폐공간 질식재해 예방 보도자료(2024), 경향신문 밀폐공간 중대재해 분석 보도(2025). 법령 : 산업안전보건법 제619조.

SafeNest · 가만있어도SANDI

1

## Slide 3

Ⅰ. 개발 개요

1.2 기존 감지 방식의 한계

감지 방식 | 정지 인체 | 사생활 보호 | 착용 불필요 | 환경 위험 감시 | 한계
가스 감지기 | × | ○ | ○ | ○ | 공기질만 측정하므로 사람의 존재를 알지 못한다
CCTV | △ | × | ○ | × | 정지 인체 판별이 어렵고 사생활 침해 소지가 크다
PIR 센서 | × | ○ | ○ | × | 움직일 때만 감지하여 쓰러진 사람을 놓친다
웨어러블 | ○ | ○ | × | × | 착용과 충전에 의존하며 미착용 시 무력하다
단일 mmWave | ○ | ○ | ○ | × | 환경 위험을 모르고 비생체 반사와 구분이 어렵다
단일 열화상 | △ | ○ | ○ | × | 히터·기계 열원과 사람의 구분이 어렵다

공백의 성격

여섯 가지 방식은 각각 다른 이유로 실패한다. 공통점은 하나다. 센서가 값을 내지 못하거나 값이 오래된 상황을 스스로 인지하지 못한다는 점이다.
그래서 값이 도착하지 않아도 시스템은 조용하고, 조용한 상태는 안전한 상태로 읽힌다. SafeNest는 서로 다른 성질의 증거를 함께 모으고, 그 증거를 지금 신뢰해도 되는지까지 판정하는 구조로 이 공백에 대응한다.

○ 충족 · △ 조건부 충족 · × 미충족. 비교는 감지 방식의 범주를 기준으로 하며 특정 제품의 성능을 단정하지 않는다. 유사 제품과의 비교는 15페이지에 별도로 제시한다.

SafeNest · 가만있어도SANDI

2

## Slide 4

Ⅰ. 개발 개요

1.3 개발 목표 및 시스템 구성

시스템 구성도

mmWave
MR60BHA2

UART2

resp_rate_bpm
heart_rate_bpm

▼

Thermal-44
(80×62)

I²C + SPI

thermal_max_c

▼

PIR

GPIO

pir_motion

▼

SCD40
(CO₂)

I²C

co2_ppm

▼

개발 목표 (중간계획서 기준 초기 목표)

① mmWave와 열화상 융합으로 정지 상태의 인체를 비영상 방식으로 감지한다.

② 다중 센서 증거 융합과 온디바이스 AI로 정상·주의·위험 3단계를 자동 판단한다.

ESP32 Dev Module 4센서 수집 · 유효성 판정 · 패킷화

▼ SafeNest TCP protocol v1 (16 B 헤더 · Wi-Fi · valid{} 동봉)

③ 위험 감지 시 현장 경보·상태 표시·이벤트 기록을 자동 수행한다.

④ Raspberry Pi 단일 노드 MVP를 완성하고 다중 노드로 확장 가능한 구조를 갖춘다.

Raspberry Pi 5
유효성·신선도 재검사 → INT8 TFLite 추론 → Risk Engine 가중 융합

▼

소스코드 (GitHub)

시연동영상 (YouTube)

SafeNest는 mmWave·열화상·PIR·CO₂ 센서의 서로 다른 정보를 결합하고, 각 값의 유효성과 신선도를 확인한 뒤 위험도를 판단하여 현장 경보와 화면으로 전달하는 임베디드 안전 시스템이다.

정상

R < 30

▼

주의

30 ≤ R < 65

▼

위험

R ≥ 65

▼

판단 보류

증거 부족

▼

부저

GPIO18 · 880 Hz

LCD

상태 6종 표시

Web 관제

Express 5 · QR 공간코드

표기 원칙 : 구현 완료 / SW 검증 / 실기기 검증 / 실기기 E2E / 미검증 을 구분해 표기한다. 초기 개발 목표와 달성 결과는 분리하며, 달성 여부는 16페이지 완성도 표에 증거 등급과 함께 제시한다.

SafeNest · 가만있어도SANDI

3

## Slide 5

Ⅱ. 개발 환경 설명

2.1 시스템 계층 구조 및 개발 환경

감지

4계층 역할 분담

MR60BHA2 · Thermal-44 · SCD40 · PIR

수집·검증

ESP32 Dev Module. 버스 판독, valid·freshness 판정, CRC, 패킷화

판단

대응

Raspberry Pi 5. 센서 상태 관리, INT8 TFLite 추론, Risk Engine

부저·LCD·Web 관제. 등급별 경보와 상태 표시

개발 환경

구분 | 사용 기술 | 대상 기기 | 저장소 근거 경로
MCU 펌웨어 | Arduino / PlatformIO (C++) | ESP32 Dev Module | devices/esp32_node/firmware/
수신·표시 서버 | Python 3 표준 라이브러리 (http.server, socket, struct) | Raspberry Pi 5 | integration/pi_lcd/server.py
온디바이스 AI | TensorFlow Lite INT8 추론 / 학습·검증 TensorFlow 2.19.1 | Raspberry Pi 5 | ondevice_ai/inference/, models/
위험도 엔진 | Python, 규칙+플로어 융합 | Raspberry Pi 5 | RaspberryPi/Runtime/risk/formula_v1.py
웹 관제 | Node.js Express 5 (bcryptjs · jsonwebtoken · qrcode) | Raspberry Pi 5 | integration/web/
센서 계약 | Python 추상 인터페이스 | 전 영역 공통 | shared/contracts/base_sensor.py
외함 | 3D CAD → STL 4종 | FDM 출력 | hardware/3d_models/

저장소 전체 파일 수 1,904개 (패키징 시점 개발 스냅샷, commit 3f22fb1). 위 표는 개발 환경에 해당하는 구성만 발췌한 것이다.

SafeNest · 가만있어도SANDI

4

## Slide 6

Ⅱ. 개발 환경 설명

2.2 센서 구성 및 하드웨어 인터페이스

센서 | 인터페이스 | ESP32 핀 / 주소 | 수집 값
MR60BHA2 (mmWave) | UART2 115200 bps | RX GPIO16 / TX GPIO17 | 호흡수, 심박수, 재실, phase
SCD40 (CO₂) | I²C 100 kHz | SDA 21 / SCL 22 / 0x62 | co2_ppm
PIR | GPIO 디지털 입력 | GPIO 13 (20 ms 폴링) | pir_motion
Thermal-44 (MI48xx) | I²C 제어 + SPI 1 MHz | 0x40 · 0x41 / SCLK18 MISO19 MOSI23 CS27 READY26 RESET25 | 80×62 uint16 프레임


[그림 1] ESP32 4센서 결선도. 좌측 표의 핀 배정과 1:1로 대응한다.

설계상 중요한 점

· 열화상 RESET(GPIO25)을 단독 핀으로 확보해 부팅 시퀀스와 무프레임 자동 재초기화를 구현하였다.

· 브레드보드·점퍼 배선 환경을 고려해 SPI 1 MHz, I²C 100 kHz로 운용한다.

· 실행 루프에서 delay()를 사용하지 않고 millis() 주기 판정과 FreeRTOS 네트워크 태스크로 분리하였다.

· 10개 신호선이 서로 다른 버스에 물리므로 핀 상수를 펌웨어 상단에 모아 배선도와 1:1로 대응시켰다.

근거 : devices/esp32_node/firmware/esp32_sensor_node.ino (741줄) 의 핀 상수 정의 PIN_*, SCD4X_ADDRESS, THERMAL_ADDRESS_A·B.

SafeNest · 가만있어도SANDI

5

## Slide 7

Ⅲ. 개발 프로그램 설명

3.1 소프트웨어 모듈 구성

경로 | 역할 | 입력 → 출력
devices/esp32_node/firmware/ esp32_sensor_node.ino | 4센서 수집, 유효성 판정, 패킷화 (741줄) | 센서 버스 → SafeNest TCP v1 패킷
devices/{mmwave,co2,pir,thermal}/src/ | 센서별 어댑터, mock, 설정 | 원시 판독 → 공용 센서 계약
shared/contracts/base_sensor.py | 모든 영역이 의존하는 센서 계약 | 인터페이스 정의
integration/pi_lcd/server.py | TCP 9000 수신, HTTP 8080 API, 상태 6종, 부저 | 패킷 → 상태·화면·경보
ondevice_ai/inference/ | TFLite Interpreter, 모델 레지스트리, 검증기 | 프레임·윈도우 → InferenceResult
RaspberryPi/Runtime/risk/ formula_v1.py | 가중 융합 + 채널별 안전기준 플로어 | 센서·AI → risk_score / WARNING·DANGER
ondevice_ai/integrated_node/run_node.py | 통합 실행 노드, 외부 provider 주입 | 센서 provider → 위험도 출력
integration/web/ | Express 5 관제 웹, QR 생성, 시뮬레이터 | 상태 → 관리자·방문자 화면
hardware/3d_models/ | 외함 CAD STL 4종 + 설계사양 2종 | 설계 → FDM 출력

외부 오픈소스 및 데이터셋 고지 (대회 규정 제10조 ③)

데이터셋 : Zenodo mmWave vital-sign (DOI 10.5281/zenodo.18599983, CC BY 4.0) · UCI Occupancy Detection (ID 357, CC BY 4.0) · SDT Thermal (TU Wien / Zenodo 4124309, 라이선스 조건 확인 중)
라이브러리 : TensorFlow Lite, Sensirion SCD4x, Seeed mmWave, Express 5, gpiozero, NumPy. 위 자산은 학습·추론·통신에 활용하였으며, 센서 통합 펌웨어와 통신 프로토콜, 상태 관리, 위험도 엔진은 팀 자체 구현이다.

본 보고서의 저장소 경로는 패키징 시점 스냅샷(commit 3f22fb1) 기준이다. 이후 저장소를 기기 단위로 재편하여 현재 main 에서는 ESP32/ 와 RaspberryPi/ 아래에 있으며, 스냅샷 구조는 archive/legacy_main_repo/ 에 그대로 보존되어 있다.

SafeNest · 가만있어도SANDI

6

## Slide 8

Ⅲ. 개발 프로그램 설명

3.2 통신 프로토콜 설계

SafeNest TCP protocol v1. 모든 정수는 network byte order

16 B 고정 헤더 구조

magic

4 B

"SNST"

version

1 B

1

type

1 B

1=JSON, 2=열화상

flags

2 B

0

sequence

4 B

uint32

payload_length

4 B

uint32

전송 흐름과 페이로드

센서 판독

▶

유효성 판정

▶

SNST 16 B 헤더 + payload

▶

TCP 9000 송신

▶

Pi 수신·재검사

Type 1 스칼라 JSON, 1초 주기

Type 2 열화상 프레임, 현재 비활성

Type 1 페이로드 (schema safenest.telemetry.v1)

device_id · seq · uptime_ms
resp_rate_bpm · heart_rate_bpm · co2_ppm
thermal_max_c · pir_motion
valid { respiration, heart, co2, thermal }

Type 2 규격 (12페이지의 구조 변경으로 전송 비활성)

16 B 메타 (width 80, height 62, frame_sequence,
uptime_ms, minimum_raw, maximum_raw)
+ 4,960 × uint16 = 9,920 B
→ payload 9,936 B / 패킷 9,952 B

0 ppm과 측정 실패를 같은 숫자로 보내면 수신 측은 둘을 구분할 수 없다. 값과 valid 플래그를 함께 보내야 판단 계층이 결측을 정상값으로 오해하지 않는다.

무효값 처리

void formatNullableFloat(char *output, size_t outputSize, bool valid, float value) {
if (valid && isfinite(value)) snprintf(output, outputSize, "%.2f", value);
else strlcpy(output, "null", outputSize); // 0으로 대체하지 않는다
}

근거 : esp32_sensor_node.ino 프로토콜 정의 L113–124, formatNullableFloat L546–553 · integration/pi_lcd/server.py 의 PACKET_HEADER, recv_exact.

SafeNest · 가만있어도SANDI

7

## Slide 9

Ⅲ. 개발 프로그램 설명

3.3 센서 유효성 및 신선도 검사

수신부터 상태 확정까지

패킷 수신

recv_exact()로 헤더 16 B를 읽고
payload_length 만큼 정확히 수신

형식 검사

magic·version·flags 확인
payload > 20,000 B 이면 연결 종료

스키마 검사

safenest.telemetry.v1 확인
valid{} 객체 존재 확인

신선도 검사

ESP32 : mmWave 5 s / CO₂ 15 s / 열화상 30 s
Pi : 5 s 독립 판정

상태 확정

LIVE · STALE · INVALID
DISCONNECTED · WAITING

▶

▶

▶

▶

열화상 프레임 무결성 검사

검사 | 방법 | 불합격 시 처리 | 구현 위치
CRC-16/CCITT-FALSE | poly 0x1021, init 0xFFFF 로 계산해 헤더 기록값과 대조 | 프레임 폐기 | thermalFrameCrc()
헤더 범위 재계산 | min/max 를 픽셀에서 다시 계산해 헤더 값과 대조 | 프레임 폐기 | server.py
시퀀스 교차 확인 | 외부 헤더 sequence 와 내부 frame_sequence 일치 확인 | 프레임 폐기 | server.py
죽은 화소 배제 | raw 2332–4231 (약 −40~150 ℃) 범위 밖 화소 제외 | 사용 가능 화소 32개 미만이면 폐기 | .ino / server.py
무프레임 자동 복구 | 30 s 무프레임 시 GPIO RESET LOW 20 ms → HIGH 300 ms | 센서 재초기화 | recoverThermalIfStale()

설계 원칙 : 센서가 정해진 시간 안에 갱신되지 않으면 해당 입력을 STALE로 분리하고, 마지막 정상값을 현재 증거로 다시 쓰지 않는다. 유효하지 않은 증거는 판단에서 제외하며 0으로 대체하지 않는다.

검증 : 본 문서 작성 시점에 integration/pi_lcd 테스트 13건을 실행해 전부 통과하였다. 부분 수신, 잘못된 헤더, 시퀀스 불일치, 신선도 판정이 포함된다.

SafeNest · 가만있어도SANDI

8

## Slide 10

Ⅲ. 개발 프로그램 설명

3.4 온디바이스 AI 모델 구성과 검증 범위

기능 | 모델 | 입력 → 출력 | 양자화 | 검증 범위 | 상태
열화상 기반 인체 자세 분석 | thermal_fall_int8 v0.1.0 | 62×80×1 프레임 → 3-class NOT_HUMAN / HUMAN_NORMAL / HUMAN_FALL | full INT8 318 KB | 실제 Thermal 프레임 → Raspberry Pi 5 → 실제 INT8 TFLite E2E 관통 | 허용
CO₂ 기반 재실 분석 | co2_occupancy_int8 v0.1.0 | CO₂ slope · 습도 · ppm → 2-class VACANT / OCCUPIED | full INT8 4.4 KB | 공개 데이터셋 기반 오프라인 검증 (실센서 평가 미수행) | 허용 (제한)
mmWave 기반 호흡 패턴 분석 | mmwave_resp_int8 v0.1.0 | 300샘플 30 s 창 → 3-class NORMAL / RAPID / APNEA | full INT8 466 KB | 재현 검증에서 클래스 붕괴 확인 acc 0.3996 · macro-F1 0.19 · recall 0.0 | 차단
mmWave 기반 호흡 패턴 분석 | mmwave_resp_int8 v0.2.0 후보 | 동일 | full INT8 22 KB | 합성 데이터 468샘플 한정 smoke 실센서 성능 검증 불가 | 후보

열화상 채널
실기기 실측

Raspberry Pi 5
30.06 s · 138회

p50

162.70 ms

p95

173.90 ms

평균

167.92 ms

유효 프레임

135/138

처리량

4.6 FPS

※ 네트워크 수신 + 추론 포함, 열화상 채널 한정

실기기 E2E

오프라인

배포 차단

합성 한정

① HUMAN_FALL 은 눕기(LYING) 정적 자세의 프록시이며 시간축 낙상 사건을 검증한 결과가 아니다.
② 열화상이 산출하는 값은 표면 온도이며 의료용 체온이 아니다. ③ mmWave 호흡 관련 신호는 임상 진단 목적이 아니다. ④ v0.2.0 후보의 합성 데이터 정확도 1.0은 실센서 성능이 아니다.

근거 : ondevice_ai/models/model_manifest.json · 03_Evidence/Thermal/phase4_6_inference_report.md · phase11_12_fail_closed_benchmark.md

표현 범위

SafeNest · 가만있어도SANDI

9

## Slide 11

Ⅲ. 개발 프로그램 설명

3.5 위험도 산출과 안전기준

R = 100 × ( 0.25 · mmWave + 0.30 · CO₂ + 0.15 · PIR + 0.30 · Thermal ) 정상 R < 30 · 주의 30 ≤ R < 65 · 위험 R ≥ 65

채널별 안전기준. 플로어가 가중합보다 등급을 올릴 수 있다

채널 | 주의 플로어 | 즉시 위험 | 점수에 넣는 방식
CO₂ | ≥ 1,500 ppm 또는 기준값+700 ppm 상승 ≥ 15 ppm/min | ≥ 5,000 ppm 비상 2,500 ppm 은 주의 유지 | ppm 곡선. occupancy 모델은 제외
열화상 | HUMAN_FALL_PROXY 점수 0.4 비상 없음 | HUMAN_FALL 신뢰도 ≥ 0.8 현재 모델은 프록시만 출력 | 눕기 자세 프록시. 낙상 사건 검증 전
mmWave | 미검증 APNEA 2회 연속 호흡 10–24 rpm 이탈 지속 | 하드웨어 확인 apnea 만 | 신경망은 관측 전용. 스펙트럼 호흡수 우선
PIR | 재실 확인 후 180 s 무움직임 | 해당 없음 | 재실 미확인이면 비가용 (0점으로 채우지 않음)

SW 검증

계산 예시 : CO₂ 1,500 ppm, 사람 상태는 평온

입력 호흡 16 rpm · CO₂ 1,500 ppm (성분 0.325) · 움직임 있음 · 열화상 HUMAN_NORMAL
가중합 R = 100 × (0.25×0 + 0.30×0.325 + 0.15×0 + 0.30×0) = 9.75 → 점수 등급 정상
플로어 co2_warning → 주의 · 비상 아님 · mmWave 신경망 관측 전용이라 health = DEGRADED

fail-closed (formula_v1.py)

전 채널 무효 → score·level = None
유효 가중치 < 0.5 이고 정상이면
INDETERMINATE (정상으로 채우지 않음)
점수가 낮아도 플로어가 주의를 올린다

임계값의 근거 1,500 ppm 은 별표2 비고(자연환기 불가+기계환기)이며 기본 유지기준은 1,000 ppm 이다. 5,000 ppm 은 OSHA/NIOSH 8h TWA와 같은 값이며 순간 비상으로 쓴다. 제618조 적정공기는 15,000 ppm. 인증 준수 주장은 하지 않는다. 출처는 docs/09_SAFETY_CRITERIA_V1.md.

계산 예시는 RaspberryPi/Runtime/risk/formula_v1.py 실행 값. 검증 : tests/test_risk_formula_v1.py. occupancy 로컬라이징은 본 식에서 제외한다.

SafeNest · 가만있어도SANDI

10

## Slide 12

Ⅲ. 개발 프로그램 설명

3.6 실측 검증 결과

서로 다른 조건에서 채널별로 수행하였으며, 통합 시스템 성능으로 합산하지 않는다

① CO₂ 센서 연속 수신 검증

ESP32 192.168.1.16 → Pi 5 192.168.1.44:9000, TCP 실경로, 2026-08-12

② mmWave 수신 안정성 및 리플레이 결과

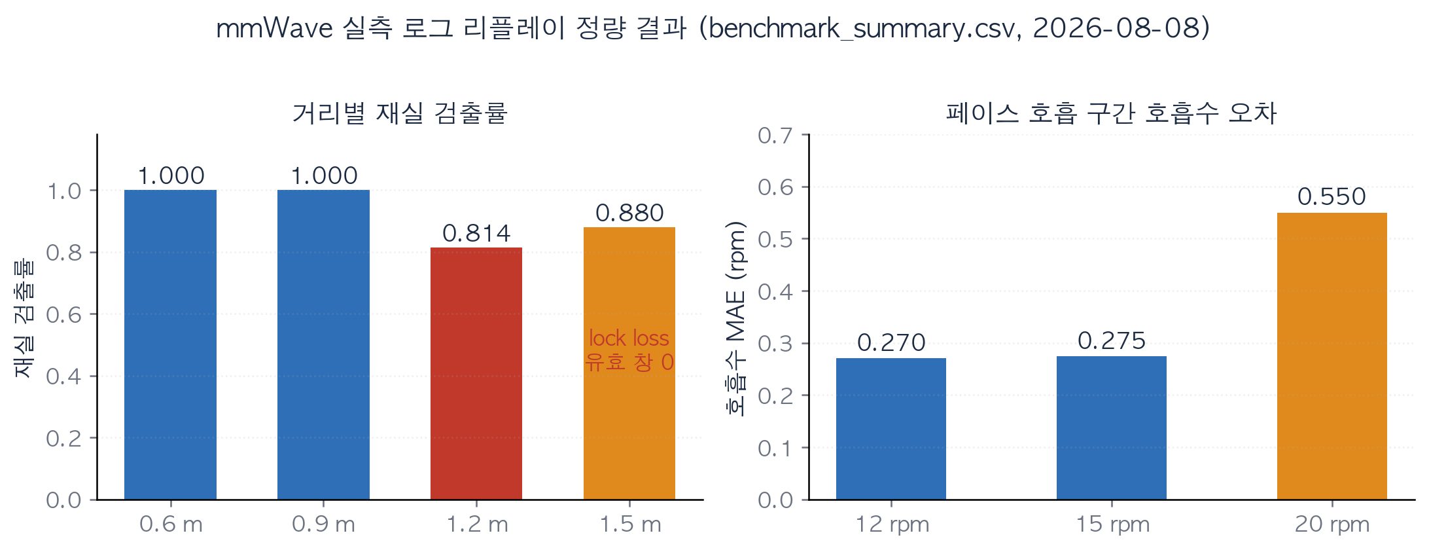
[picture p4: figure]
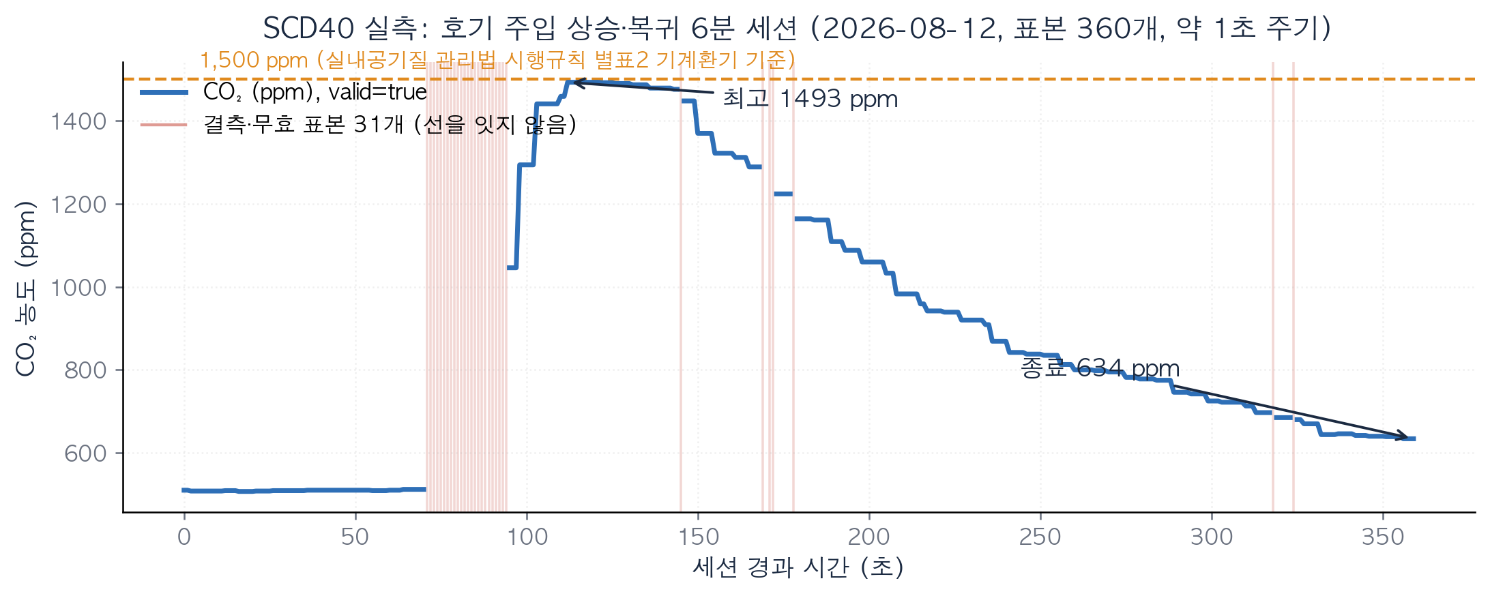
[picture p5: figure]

세션 | 유효 표본 | 결측률 | 판정
프리플라이트 30초 | 30 / 30 | 0 % | PASS
baseline 5분 (최초) | 277 / 300 | 7.67 % | FAIL
baseline 5분 (재측정) | 300 / 300 | 0 % | PASS
호기 6분 | 329 / 360 | 8.61 % | PASS

라이브 UART 수신 (2026-08-08)

9.990 Hz · 1,201 레코드 · 199/199 창 파싱 · 시퀀스 누락 0 · UART / checksum / parser 오류 0 / 0 / 0

③ Thermal 실기기 End-to-End

Raspberry Pi 5, 30.06 s / 138회 측정

p50 162.70 ms · p95 173.90 ms · 평균 167.92 ms
유효 프레임 135 / 138 (97.8 %) · 처리량 4.6 FPS
fail-closed 6종(순서위반 · NaN/Inf · 형식오류 · 물리적 단선 · 복구 · close 후 read) 실기기 PASS

최초 baseline 의 결측은 채우거나 삭제하지 않고 원본을 실패 증거로 보존한 뒤 재측정하였다. 호기 세션 최고 1,493 ppm, 종료 634 ppm.

ESP32 펌웨어 빌드 자원 : RAM 32,356 / 327,680 B (9.9 %), Flash 268,765 / 1,310,720 B (20.5 %). 4센서 동시 수신 로그는 아직 확보하지 않았다 [추가 검증 필요].

SafeNest · 가만있어도SANDI

11

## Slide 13

Ⅳ. 장애요인과 해결방안

4.1 열화상 전송 구조 개선

문제

열화상 프레임을 계속 전송하면 1초 주기 telemetry(호흡·심박·CO₂·PIR)가 밀린다. 화면 값이 갱신되지 않거나 stale 로 떨어졌다.

원인

패킷 하나가 9,952 B (메타 16 B + 4,960 × 2 B + 헤더 16 B). 당시 분주비 4로 25 FPS 센서에서 초당 약 6.25 프레임을 요청하여 약 60 KB/s 를 ESP32 Wi-Fi 단일 TCP 연결에 투입하였다. 열화상 write 가 블로킹되면 뒤의 telemetry write 도 함께 지연된다.

시도

① TCP write 를 별도 FreeRTOS 태스크로 분리 ② 열화상 큐를 길이 1로 두고 xQueueOverwrite 로 최신 프레임만 유지 ③ 512 B 청크 분할 전송 ④ 분주비 4 → 8 (약 3.125 FPS) ⑤ SPI 8 MHz → 1 MHz

실패

수집이 네트워크 때문에 멈추는 현상은 사라졌지만, 스트리밍을 켠 상태에서 1초 주기는 여전히 유지되지 않았다. 큐를 줄인 것은 지연을 감춘 것이지 전송량을 줄인 것이 아니었다. 링크에 실리는 총 바이트는 그대로였다.

해결

THERMAL_STREAM_FRAMES = false 로 전환하였다. 프레임을 보내는 대신 ESP32 가 그 자리에서 요약한다. 측정 범위 밖 죽은 화소를 제외하고, 살아 있는 화소가 32개 이상일 때 가장 뜨거운 16개 중 최저값을 골라 thermal_max_c 하나로 환산해 1초 telemetry 에 싣는다.

type 2 패킷 9,952 B 를 초당 약 6.25회 전송 시도
→ 1초 telemetry 주기 붕괴, 화면 값 지연

개선 전

type 2 전송 없음. telemetry JSON 1개(상한 512 B)로 1초 주기 유지
대신 LCD 열화상 영상은 제외하였고, 프레임 자체는 별도 리그에서만 검증한다.

개선 후

배운 점 : 대역폭이 한정된 링크에서는 판정에 필요한 최소 정보를 송신 측에서 뽑아 보내야 한다. 9,936 B 프레임에서 실제 판정에 쓰인 정보는 최고온도 하나였다.

근거 : esp32_sensor_node.ino 의 THERMAL_STREAM_FRAMES, THERMAL_FRAME_RATE_DIVIDER, xQueueOverwrite 사용부.

SafeNest · 가만있어도SANDI

12

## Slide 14

Ⅳ. 장애요인과 해결방안

4.2 자원·버스·재현성 장애요인

① GPIO 자원 제약으로 자동 복구 기능이 막힌 문제

문제·원인

XIAO ESP32-C6 의 외부 디지털 핀 11개 중 D6/D7 은 보드 내부에서 MR60BHA2 와 UART 로 묶여 외부 사용이 불가능하고, D3 은 레이더 부트·리셋 회로에, D1 은 온보드 RGB LED 에 물려 있었다.

시도·실패

nRESET 을 연결하지 않는 방안을 시도하였으나, 초기화가 I²C 주소를 찾기 전에 RESET 을 LOW 20 ms → HIGH 300 ms 로 토글해야 해서 부팅 시퀀스가 성립하지 않았다. 사람이 버튼을 눌러야 복구되는 장치는 무인 감시에 쓸 수 없다.

해결

ESP32 DevKit V1(30-pin)으로 교체하고 10개 신호선을 모두 단독 핀에 배정하였다. RESET(GPIO25) 제어를 확보하여 30초 무프레임 자동 재초기화가 동작한다.

② 브레드보드 배선이 버스 속도를 견디지 못한 문제

문제·원인

SPI 8 MHz, I²C 400 kHz 에서 MI48 과 SCD4x 양쪽에서 판독 누락이 재현되었다. 배선을 다시 꽂고 길이를 줄여도 동일하였다.

시도·실패

속도를 낮추면 프레임 판독 시간이 늘어 요청 주기를 넘길 위험이 있었으므로, 시간 예산 안에 들어오는지를 함께 계산해야 했다.

해결

SPI 1 MHz, I²C 100 kHz 로 조정하였다. 1 MHz 에서 한 프레임 판독이 약 81 ms 로, 분주비 8이 요구하는 160 ms 예산 안에 들어가 READOUT_TOO_SLOW 정지가 사라졌다.

③ 학습이 끝난 모델이 재현 검증을 통과하지 못한 문제

문제·원인

mmWave 호흡 이상 분류 모델 v0.1.0 을 저장소 데이터로 재현 평가한 결과, 468개 표본 전부를 NORMAL 로 예측하는 클래스 붕괴가 확인되었다. 정확도 0.3996, macro-F1 0.19, RAPID·APNEA 재현율 0.0 이다.

시도·실패

아티팩트는 존재하였고 SHA-256 과 텐서 계약도 일치하였다. 모델 파일이 있다는 것이 검증을 통과했다는 뜻은 아니라는 사실이 드러났다.

해결

매니페스트에 deployment_allowed = false 와 차단 사유 CLASS_COLLAPSE_ON_REPOSITORY_NPZ 를 기록해 배포를 차단하고 후보를 다시 세웠다. 안전 판단 경로에 검증되지 않은 모델을 올리지 않는 것을 우선하였다.

세 번째 사례가 특히 중요하다. 성능이 나오지 않은 모델을 팀이 스스로 찾아내 배포를 차단한 것은, 검증되지 않은 구성요소를 안전 경로에 올리지 않는다는 원칙을 실제로 적용한 결과다.

근거 : esp32_sensor_node.ino (핀 상수 · THERMAL_SPI_HZ · Wire.setClock · recoverThermalIfStale) · ondevice_ai/models/model_manifest.json (validation_status: BLOCKED).

SafeNest · 가만있어도SANDI

13

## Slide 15

Ⅴ. 개발 결과물의 차별성

5.1 기술적 차별성

1

증거가 무효이거나 결측이면 마지막 정상값을 재사용하지 않는다. 네 채널이 모두 무효이면 위험도를 산출하지 않고 risk_score 와 risk_level 을 None 으로 두며 system_health 를 FAILED 로 기록한다. 침묵을 안전의 증거로 삼지 않는다.

fail-closed 판단 보류

RaspberryPi/Runtime/risk/formula_v1.py

SW 검증

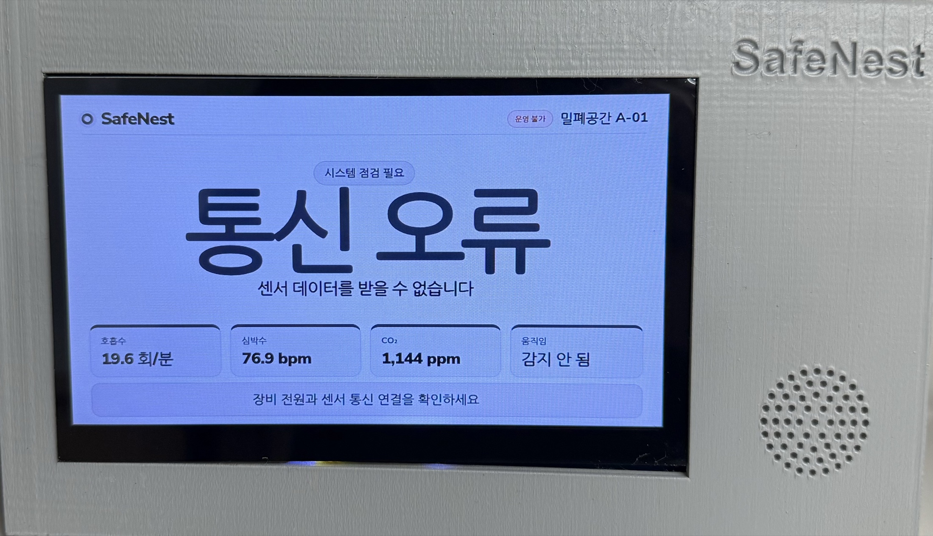
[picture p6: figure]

[그림 2] 전 센서 무효 시 표시 화면. 정상으로 표시하지 않고 점검 필요 상태를 출력한다. 표시 계층 검증용 시나리오 화면이며 실센서 측정값이 아니다.

2

값과 함께 valid 플래그를 전송하며, 유효하지 않은 수치는 0으로 대체하지 않고 null 로 보낸다. ESP32 와 Raspberry Pi 가 신선도를 각각 독립적으로 판정하고, STALE 입력은 판단에서 제외한다.

유효성·신선도의 1급 상태 관리

formatNullableFloat() · SensorStore

SW 검증

3

영상 센서를 쓰지 않는다. mmWave 의 미세 움직임, 열화상의 저해상도 열 분포, CO₂ 의 환경 추세, PIR 의 움직임 이벤트가 서로 다른 실패 모드를 상쇄한다. 열화상은 80×62 해상도로 개인 식별용 영상이 아니다.

카메라 없는 이종 센서 증거 융합

RaspberryPi/Runtime/risk/formula_v1.py

SW 검증

4

모델마다 검증 범위와 배포 허용 여부를 매니페스트에 기록한다. 재현 검증에 실패한 모델은 실제로 배포가 차단되었다.

검증 등급에 따른 배포 통제

오프라인 검증

5

CRC-16/CCITT-FALSE 검사, 헤더 범위 재계산, 시퀀스 교차 확인을 거치며 30초 무프레임 시 GPIO RESET 으로 센서를 재초기화한다.

각 항목은 03_CLAIM_EVIDENCE_LEDGER 의 근거 파일과 1:1로 연결되어 있으며, 근거가 확인되지 않은 주장은 포함하지 않았다.

SafeNest · 가만있어도SANDI

프레임 무결성과 자동 복구

실기기 검증

14

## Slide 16

Ⅴ. 개발 결과물의 차별성

5.2 기존 방식 및 유사 사례 비교

비교 축 | 가스감지기 | CCTV | PIR | 웨어러블 | Vayyar Care | TI IWR6843 | SafeNest
사생활 보호 (비영상) | ○ | × | ○ | ○ | ○ | ○ | ○
정지 인체에 대한 증거 | × | △ | × | ○ | ○ | ○ | ○
환경 위험 감시 | ○ | × | × | × | × | × | ○
다중 증거 교차 확인 | × | × | × | × | × | × | ○
무효·결측 데이터 인지 | × | × | × | △ | 확인 불가 | 확인 불가 | ○
증거 부재 시 판단 보류 | × | × | × | × | 확인 불가 | 확인 불가 | ○
통합 실기기 검증 완료 | ○ | ○ | ○ | ○ | ○ | ○ | ×

Vayyar Care
(상용 제품)

SafeNest 가 다르게 한 지점은 감지 성능보다 증거를 다루는 정책에 있다. 조사한 세 사례 모두 공개 자료에서 무효·결측 인지와 판단 보류 정책을 확인할 수 없었다. 다만 SafeNest 는 4센서 통합 실기기 검증을 완료하지 않았으므로 마지막 행을 그대로 표기한다.

60 GHz 4D 이미징 레이더 기반 낙상 감지 장치. 카메라·마이크·웨어러블을 쓰지 않고 1대가 약 16 m²를 감시하며 낙상을 3단계로 구분한다. 환경 가스 감시 기능은 제품 설명에서 확인되지 않는다.

TI IWR6843
(상용 부품)

60~64 GHz FMCW 단일칩 mmWave 센서. 재실 감지와 생체신호 검출 레퍼런스 디자인이 공개되어 있다. 센서 단위 부품이므로 환경 센서 융합과 판단 보류 정책은 범위 밖이다.

학술 연구
(arXiv 2403.05634, 2024)

SafeNest · 가만있어도SANDI

TI mmWave 레이더 3대로 다중 인체 추적과 낙상 감지를 수행하여 정확도 96.3 %를 보고하였다. 단일 모달리티 실험이며 센서 무효·결측 시의 처리 정책은 다루지 않는다.

○ 충족 · △ 조건부 충족 · × 미충족 · 확인 불가는 공개 자료에서 판정 근거를 찾지 못한 항목이다. 출처 : vayyar.com/care-pages/how, ti.com/tool/IWR6843ISK, arXiv:2403.05634.

15

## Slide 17

Ⅴ. 개발 결과물의 차별성

5.3 구현 결과 및 검증 수준

구성요소 | 구현 | 검증 수준 | 증거 | 남은 과제
ESP32 4센서 통합 노드 | 완료 | SW 검증 | esp32_sensor_node.ino 741줄 · 빌드 RAM 9.9 % / Flash 20.5 % | 4센서 동시 수신 실측
TCP v1 송·수신 및 유효성 검사 | 완료 | SW 검증 | 수신기 테스트 13건 통과 · CRC-16 · 범위 재계산 · 이중 TTL | 실환경 장시간 수신
Risk Engine · fail-closed | 완료 | SW 검증 | 위험도 테스트 22건 실행 통과 | 실입력 기반 HIL
mmWave 채널 | 완료 | 실기기 검증 | 9.990 Hz · 1,201 레코드 · 오류 0 · 리플레이 MAE 0.270 rpm | 통합 노드 편입
CO₂ 채널 | 완료 | 실기기 검증(부분) | 실측 4세션 · 재측정 결측 0 % · 호기 최고 1,493 ppm | 센서 분리 결측 계약
Thermal 채널 | 완료 | 실기기 E2E | Pi 5 p50 162.70 / p95 173.90 ms · 유효 97.8 % · fail-closed 6종 통과 | 정본 노드 경유 검증
Web · LCD · 부저 · 외함 | 완료 | SW 검증 + 실물 | 상태 6종 표시·경보 확인 · 하우징 2종 출력·조립 완료 | 실센서 구동 화면
4센서 통합 HIL | 미착수 | 미검증 | 해당 없음 | 최우선 과제

하드웨어 없이 실행 가능한 테스트를 직접 실행하여 57건 통과, 2건 실패(데이터 파일 부재)하였다. 저장소의 테스트 함수 1,483개는 소스에 정의된 개수이며 실행·통과 건수와 다르다.

테스트 수치의 의미

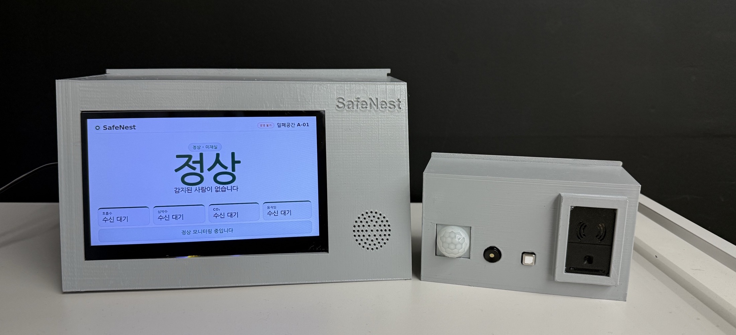
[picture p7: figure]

[그림 3] 완성품. 좌측 표시부, 우측 센서 노드. 하우징 2종은 자체 설계 STL 출력물이다.

SafeNest · 가만있어도SANDI

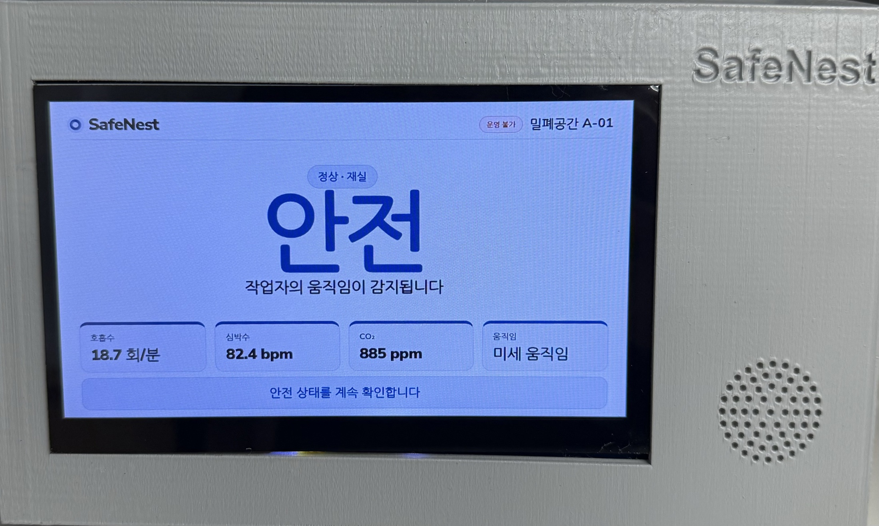
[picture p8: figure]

안전 · 재실


주의 · CO₂ 높음

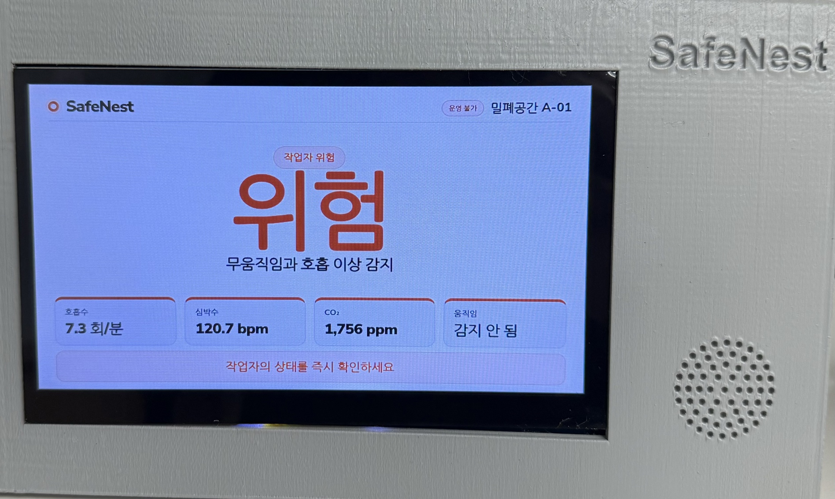
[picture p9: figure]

위험 · 호흡 이상

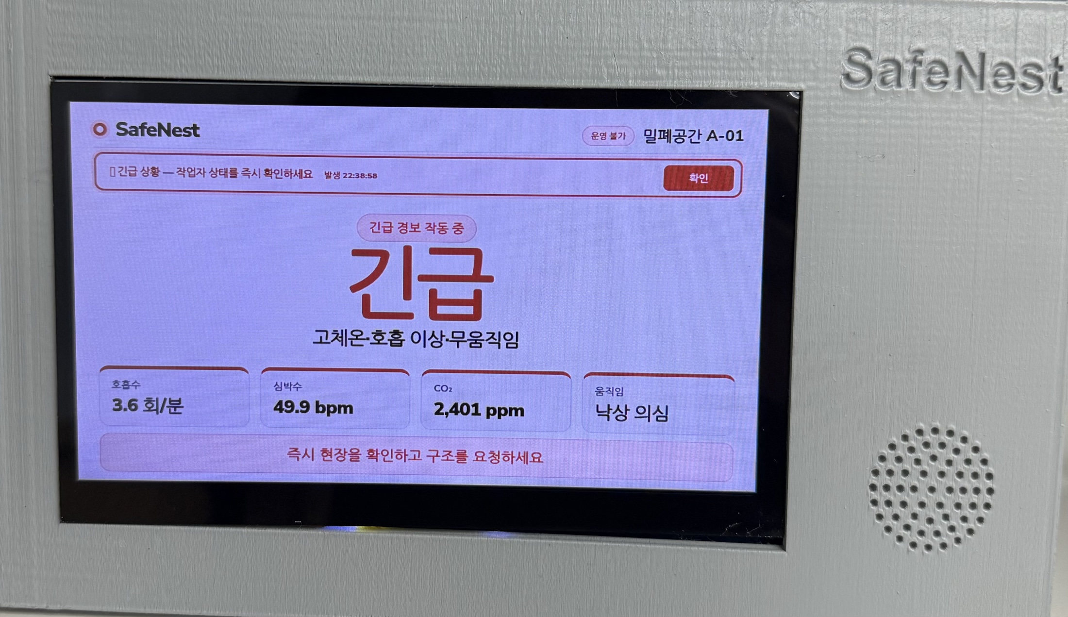
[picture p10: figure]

긴급 · 복합 위험

[그림 4] 위험도 등급별 표시·경보 화면. 주의는 화면 경고, 위험부터는 부저 경보가 함께 출력된다. 화면 값은 표시 계층 검증용 시나리오 입력이며 실센서 측정값이 아니다.

검증 수준 : SW 검증은 소프트웨어 테스트 통과, 실기기 검증은 실제 센서·보드에서 확인, 실기기 E2E 는 실센서부터 추론까지 관통, 통합 HIL 은 4센서 동시 실기기 검증(미완)을 뜻한다.

16

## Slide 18

Ⅵ. 파급력 및 기대효과

6.1 적용 분야 및 기대효과

1차 적용 : 밀폐공간 무인 감시

· 맨홀·정화조·집수정 등 산업안전보건법 시행규칙 별표18이 정한 밀폐공간

· 감시인 상시 배치가 어려운 소규모 사업장의 보조 감시 수단

· 공기질(CO₂)과 사람의 상태를 함께 확인하여 가스 감지기 단독 운용의 공백을 메운다

· 카메라를 쓰지 않으므로 작업자 사생활 문제를 설계 단계에서 줄인다

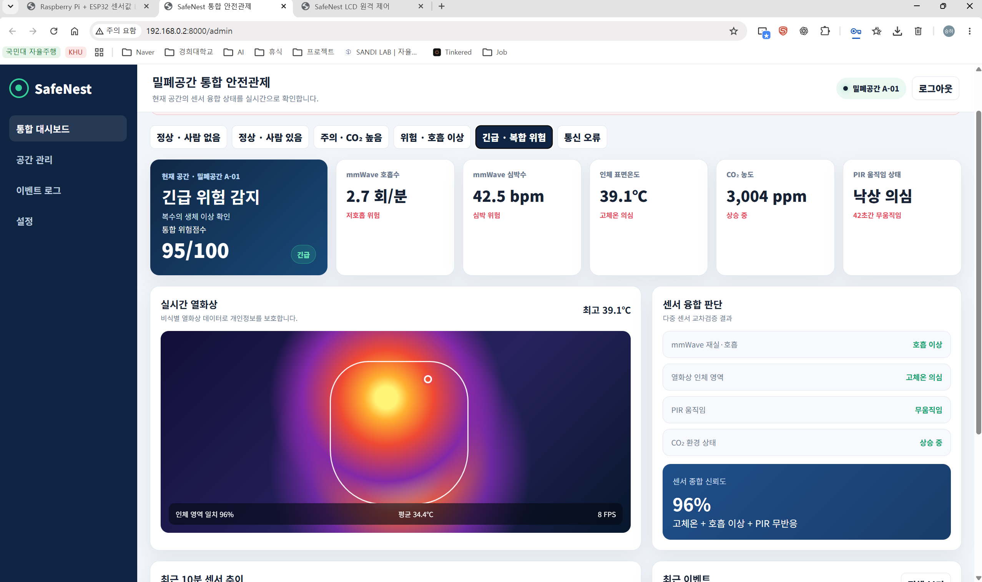
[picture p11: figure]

[그림 5] Express 5 관제 웹. 공간 단위 상태 조회와 다중 노드 관제로의 확장 근거다. 표시 계층 구현 결과이며 화면 값은 시나리오 입력이다.

확장 적용과 실측 감지 특성의 대응

좌석까지의 거리가 0.6~0.9 m 구간에 해당한다. 해당 구간의 재실 검출률은 리플레이 기준 1.000 이다.

통학차량 잔류 감지

창고·냉동·양생 공간

작업자 고립 감지와 환경 악화 추세를 동시에 관측한다. 1.2 m 이상에서는 검출률이 0.814로 낮아지므로 노드 배치 간격을 좁혀야 한다.

다중 노드 확장

1.5 m 에서는 lock loss 로 유효 창이 0이었다. 따라서 대형 공간은 단일 노드를 키우는 대신 노드를 분산 배치하여 대응한다.

공간 식별 체계

기대효과 서술의 범위

확장 시나리오는 동일한 노드 구조로 대응 가능하다는 설계 판단과 리플레이 실측 감지 특성에 근거한다. 현장 파일럿과 정량 효과, 시장 규모는 아직 검증하지 않았다. 매출·판매가·시장 점유 수치는 제시하지 않으며, 부품 단가도 공개 출처로 전 항목을 확인하기 전까지 기재하지 않는다.

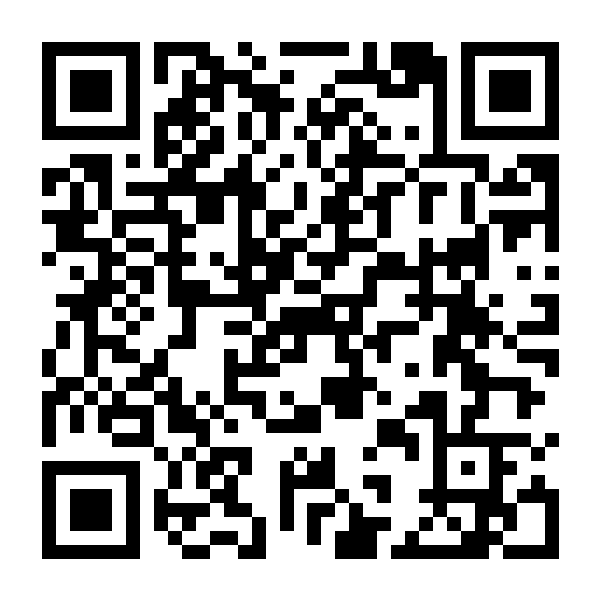
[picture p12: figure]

QR 로 공간을 식별한다. 관제 웹에 밀폐공간 A-01, 통학차량 B-02, 창고 C-03 등록.

SafeNest · 가만있어도SANDI

적용 근거 : 산업안전보건법 시행규칙 별표18 밀폐공간의 범위. 감지 거리 근거 : devices/mmwave/validation_results/replay_v5/benchmark_summary.csv.

17

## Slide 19

Ⅵ. 파급력 및 기대효과

6.2 발전 가능성 및 외함 설계

단계별 진행 상황

✓

✓

3

4

5

6

1단계

채널별 실기기 검증
+ SW 검증

2단계

하우징 출력·조립
완제품 형상 확보

3단계

4센서 통합 HIL
실입력 → Risk → 경보

4단계

현장 데이터 수집
임계값·보정 확정

5단계

다중 노드 확장
무선 관제

6단계

인증·현장 평가

설계에서 실물까지

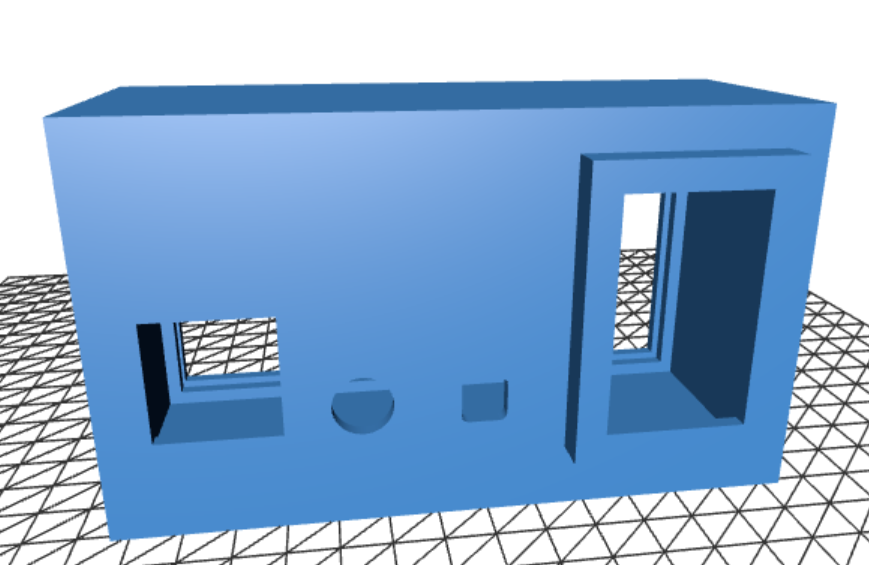
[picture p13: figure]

[그림 6] 센서 하우징 전면 개구부 설계

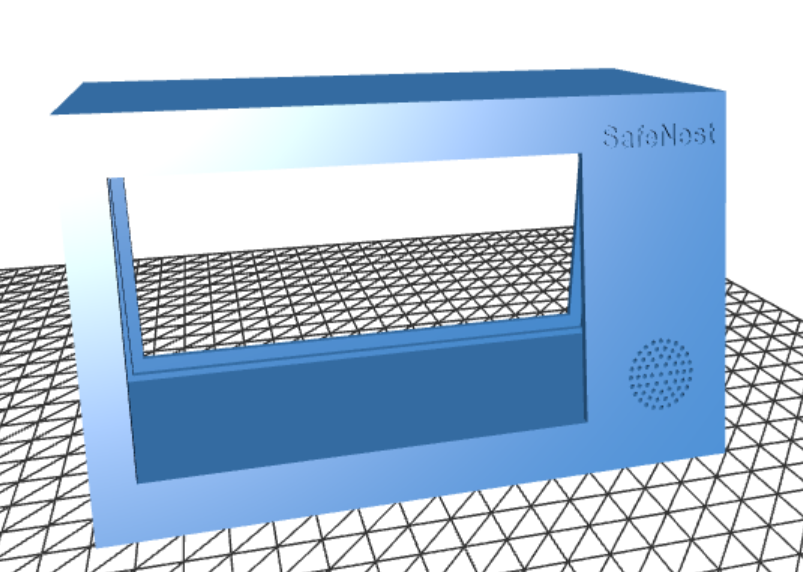
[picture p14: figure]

[그림 7] LCD·부저 하우징 전면 설계

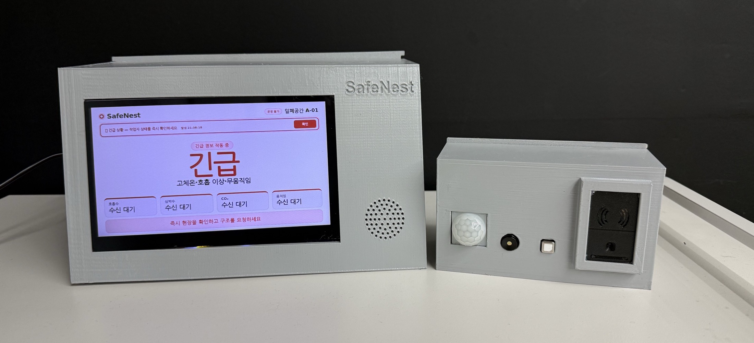
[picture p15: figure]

[그림 8] FDM 출력·조립을 마친 실물. 긴급 등급 표시 상태이며 화면 값은 시나리오 입력이다.

▶

센서 하우징 137×80×60 mm (벽 3 mm) · LCD·부저 하우징 240×140 mm · 슬라이딩 슬롯 3.5 mm · 편측 유격 0.25 mm. STL 4종과 설계사양 2종을 전달하였고 출력·조립을 완료하였다. 장시간 체결 강도와 발열 특성은 아직 확인하지 않았다.

CAD 설계와 STL 출력물 모두 팀 자체 산출물이다.

SafeNest · 가만있어도SANDI

18

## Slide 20

Ⅶ. 개발 일정 및 업무 분장

7.1 개발 일정 및 주요 설계 변경

7월

실제 수행 일정

요구사항 정의 · 시스템 설계 · 부품 확보 · 개발환경 구축 · 센서별 드라이버 착수

8/01

8/02–8/03

mmWave 장시간 실측. 빈 공간 30분 / 재실 31분 원시 로그 확보

저장소 통합 및 기기·책임 영역 재편 · CODEOWNERS 정의 · 회귀 테스트

8/08

mmWave 라이브 검증(9.990 Hz, 오류 0) · 실측 로그 리플레이 벤치마크 12종

8/11

8/12

Thermal-44 실기기 E2E 검증 · fail-closed 6종 · Pi 5 지연 실측

SCD40 실기기 4세션 측정 · ESP32 → Pi TCP 실경로 확인 · 검증 리포트 작성

8/16–8/21

8/23

mmWave 물리 측정 정합 감사 · 패키징 시점 개발 스냅샷(3f22fb1) 확정

하우징 STL 출력·조립 완료 · 표시·경보 계층 상태 6종 확인

이후

4센서 통합 HIL · 시연동영상 촬영 (미완료)

개발 과정에서 내린 주요 설계 변경

MCU 교체

XIAO ESP32-C6 → ESP32 DevKit V1

GPIO 자원 부족으로 열화상 RESET 제어가 불가능해 자동 복구 요구사항을 충족할 수 없었다.

SafeNest · 가만있어도SANDI

열화상 전송 구조

전 프레임 스트리밍 → 송신측 요약

9,952 B 패킷을 초당 약 6.25회 보내면서 1초 telemetry 주기가 무너졌다.

모델 배포 통제

mmWave v0.1.0 배포 차단

재현 검증에서 클래스 붕괴를 확인하여 검증 실패 모델을 안전 경로에 올리지 않기로 하였다.

일정은 저장소 커밋 이력과 검증 문서의 실제 일자를 기준으로 작성하였으며, 계획서의 예정 간트를 그대로 옮기지 않았다.

19

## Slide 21

Ⅶ. 개발 일정 및 업무 분장

7.2 업무 분장 및 협업 구조

성명 | 구분 | 담당 업무 | 책임 영역 (CODEOWNERS) | 주요 산출물
김진수 | 팀장 | mmWave 펌웨어·어댑터·실측, 저장소 구조 통합, 문서 총괄 | devices/mmwave/ · docs/ · 저장소 전체 기본 리뷰어 | MR60 실측 로그 30분·31분, 라이브 검증(9.990 Hz), 리플레이 벤치 12종
유승하 | 팀원 | CO₂(SCD40) 연동·실측, ESP32 4센서 노드 펌웨어, Pi LCD·부저 서버, 회로 | devices/co2/ · devices/esp32_node/ · integration/ | esp32_sensor_node.ino(741줄), CO₂ 실측 4세션·검증 리포트, TCP v1 송·수신
김태균 | 팀원 | Thermal-44 드라이버·프레임 파서·전처리, 열화상 온디바이스 AI 검증 | devices/thermal/ · docs/thermal/ | 실기기 E2E 관통, fail-closed 6종, Pi 5 지연 실측(p95 173.9 ms)
한준우 | 팀원 | 데이터셋 출처·분할, 모델 학습·비교·재현, Pi AI 준비, 위험 판단 연계 | ondevice_ai/ · shared/contracts/ | 모델 3종 매니페스트, 재현 검증·클래스 붕괴 발견 및 배포 차단
강유나 | 팀원 | PIR 어댑터, 3D 하우징 CAD 설계 및 출력, LCD·Web 초기 골격 | devices/pir/ · hardware/3d_models/ | STL 4종 + 설계사양 2종, 하우징 출력·조립, PIR 어댑터, LCD 초기 서버

담당 경계를 고정한 협업 인터페이스

센서 계약

shared/contracts/base_sensor.py

모든 센서 담당자 ↔ AI 담당자

텔레메트리 스키마

패킷 규격

safenest.telemetry.v1 (valid 블록 포함)

SafeNest TCP protocol v1 (16 B 헤더)

ESP32 담당 ↔ 수신 서버 담당

ESP32 담당 ↔ Pi 수신 담당

추론 결과 계약

위험도 출력

InferenceResult / SensorState

SafeNestRiskOutput (schema 5.0)

센서 담당 ↔ 위험도 담당

위험도 담당 ↔ 표시·경보 담당

담당 표기는 저장소 CODEOWNERS 와 실제 산출물로 확인한 범위만 기재하였으며, 기여도를 인위적으로 균등화하지 않았다.

SafeNest · 가만있어도SANDI

20

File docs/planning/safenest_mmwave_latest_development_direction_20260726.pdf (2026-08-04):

# SafeNest mmWave 최신 개발 방향 및 데이터·노드 아키텍처

기준일: 2026-07-26

문서 상태: 팀 의사결정용 최신안
대상 센서: Seeed Studio MR60BHA2 및 60 GHz FMCW 계열
대상 플랫폼: Raspberry Pi 5 온디바이스 추론
관련 기존 문서: safenest_mmwave_ondevice_ai_roadmap_20260725.md, safenest_mmwave_ai_guide.md
우선 기준: 실제 코드는 models/model_manifest.json, inference/, adapters/, integrated_node/를 따

른다.

상태 표기:

표기 | 의미
IMPLEMENTED | 코드 경로가 존재함
LOCAL-VALIDATED | 로컬 자동·smoke test까지 확인됨
PLANNED | 목표 구조이며 아직 구현되지 않음
BLOCKED | 외부 데이터·실센서 계약 등 선행조건이 필요함
0. 총괄 결정

SafeNest mmWave의 최신 방향은 데이터 출처별 무조건 통합도 아니고, 데이터셋마다 모델 노드를 하나씩 만드는 구조도 아니다.

채택할 원칙은 다음과 같다.

1. 원본 데이터는 110명 공개 데이터, 추가 공개 데이터, 팀 자체 MR60 데이터로 분리 보존한다.
2. 각 출처는 전용 Adapter를 거쳐 공통 Canonical Window 규격으로 변환한다.
3. 입력 의미·라벨·ground truth·센서 도메인이 호환되는 데이터만 통합 학습 후보로 사용한다.
4. 호흡 상태라는 같은 문제를 푸는 호환 모델은 가능한 한 하나로 통합한다.
5. 호흡 상태, 신호 품질, presence/multi-target처럼 문제가 다르면 전문 모델을 병렬화한다.
6. MR60BHA2 데이터는 초기에는 기존 모델의 외부검증·도메인 보정에 사용하고, 충분한 클래스와 피험자가 확보된 뒤 통합 또는
fine-tuning을 결정한다.
7. 안전 경로는 AI와 분리한다. 출처가 검증된 upstream apnea flag, presence, RPM 규칙과 센서 fault는 30초 AI window를

기다리지 않는다.

한 문장으로 정리하면 다음과 같다.

출처별 병렬 수집 → 호환 데이터의 조건부 통합 학습 → 역할별 전문 모델 병렬 추론 → 하나의 mmWave 상태로 안전 융합

1. 현재 기준선

1.1 학습·모델 상태

현재 적용 모델의 기준선은 다음과 같다.

항목 | 현재 상태
원 학습 데이터 | 110명 규모 db_records 60 GHz FMCW 데이터
safenest_mmwave_latest_development_direction_20260726.md | 2026-07-26

항목 | 현재 상태
원 데이터 버전 | 현재 공개본은 Zenodo v1.1, DOI 10.5281/zenodo.18599983; 실제 학습본 버전은 확인 필요
원 데이터 규모 | 110명, 4개 조건씩 총 440개 기록
학습 위치 | Google Colab 외부 학습 환경
저장소에 보관한 항목 | 양자화 TFLite, 정규화 metadata, manifest
공식 모델 | models/mmwave/mmwave_resp_int8_v0.1.0.tflite
입력 | resp_phase, [1, 300, 1], 10 Hz, 30초, INT8
출력 | [1, 3], NORMAL / RAPID_OR_ABNORMAL / APNEA
현재 검증 등급 | local_runtime_validated
미완료 | 실센서 CSV 정확도, Pi 5 benchmark, 현장 HIL, 클래스별 provenance

110명 원본 데이터가 저장소에 없는 것은 현재 배포 구성과 일치한다. 저장소 밖의 Colab 환경에서 학습했고, 이 저장소에는 배포 산출물

만 반입됐다. 다만 원본·notebook·학습 run의 현재 보존 여부와 실제 사용 버전은 아직 증명되지 않았으므로, 재현성을 위해 DOI, 버전,
파일 해시, subject split, 학습 commit을 dataset_manifest.json에 고정해야 한다.

원 데이터 v1.1의 공식 설명에는 440개 실험 중 12개 실험의 시작 부분에 all-zero FFT frame이 있다고 명시돼 있다. 재학습 Adapter

는 공식 skip 목록을 반영하고, 제거 전후 frame 수를 manifest에 기록해야 한다.

1.2 Class 1 주의사항

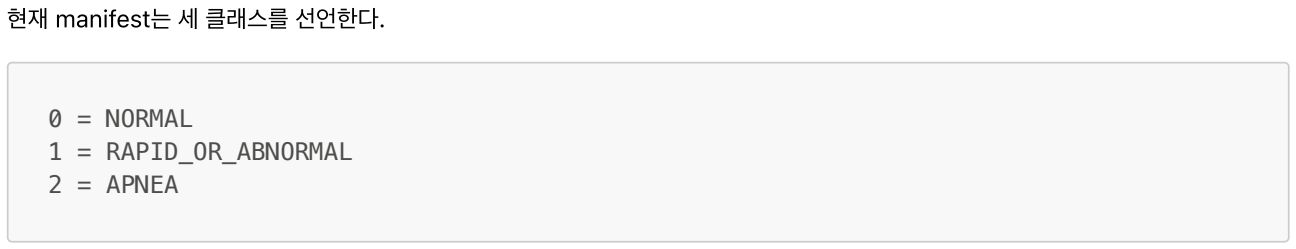
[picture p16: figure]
현재 manifest는 세 클래스를 선언한다.; 0 = NORMAL 1 = RAPID_OR_ABNORMAL 2 = APNEA

그러나 현재 보존된 학습 가이드의 window 생성 코드에서는 NORMAL=0, APNEA=2만 생성한다. 별도의 실제 학습 코드 또는 label

manifest에서 Class 1 양성 샘플이 확인되기 전까지는 다음처럼 취급한다.

Class 1은 검증 대기 상태다.

Class 1 출력을 안전 위험도의 확정 근거로 단독 사용하지 않는다.

Class 1 데이터가 확보되지 않으면 NORMAL/APNEA 2-class 재학습 후보를 만든다.
3-class를 유지하려면 tachypnea/rapid, bradypnea/slow, shallow/hypopnea의 정의와 ground truth를 먼저

고정한다.

1.3 현재 런타임 구현 수준

현재 통합 코드는 ROS2가 아니라 다음과 같은 in-process Python 구조다.

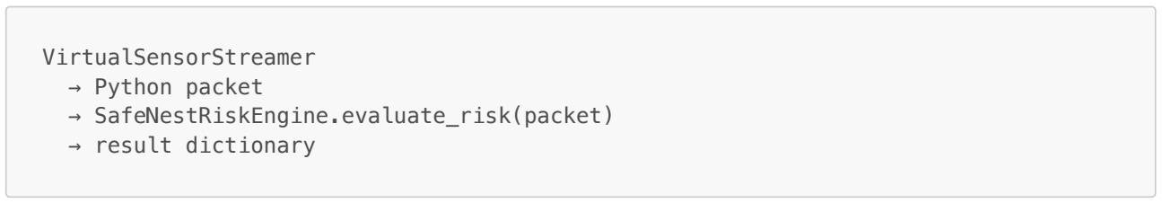
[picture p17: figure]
VirtualSensorStreamer → Python packet → SafeNestRiskEngine.evaluate_risk(packet) → result dictionary

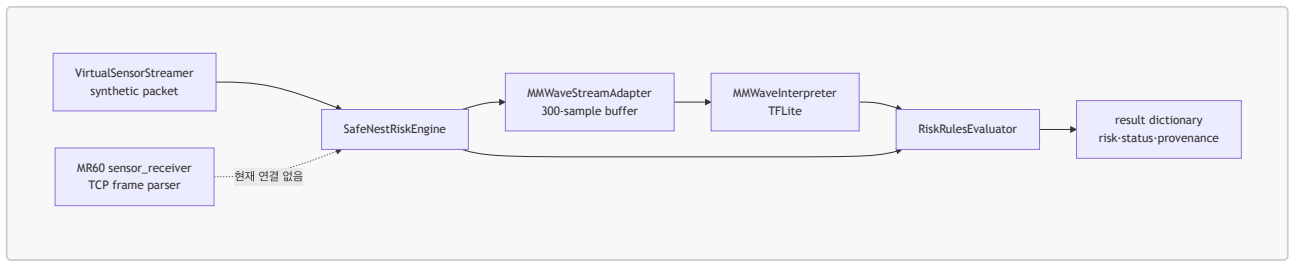
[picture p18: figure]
VirtualSensorStreamer synthetic packet; SafeNestRiskEngine; MMWaveStreamAdapter 300-sample buffer; MMWaveInterpreter TFLite; RiskRulesEvaluator; result dictionary risk·status·provenance; MR60 sensor_receiver TCP frame parser

이 그림은 AS-IS다. sensor_receiver.py와 통합 위험엔진 사이의 publish/subscribe 연결은 현재 존재하지 않는다.

mmwave_mr60 패킷에서 사용하는 핵심 필드는 다음과 같다.

presence
breath_rpm
heart_bpm
apnea
resp_phase
rfft_frame # 선택적

현재 구현의 실제 동작은 다음과 같다.

resp_phase를 ring buffer에 저장한다.
300개가 쌓이면 TFLite 입력 window를 만든다.
push_sample()이 presence=0을 받으면 buffer를 초기화한다. 다만 presence=0 패킷에 resp_phase가 없으면 현 위

험엔진은 push_sample()을 호출하지 않아 과거 buffer가 남을 수 있다.
timestamp 역순·중복, NaN/Inf, 0.5초 초과 gap을 거부한다.
2초 이상 stale이면 추론 window를 사용하지 않는다.

sample_rate_hz=10은 선언돼 있지만 실시간 Adapter가 10 Hz 재샘플링이나 29.9초 coverage를 강제하지는 않는다. 현

재는 간격이 허용 범위 안이면 300개를 30초 window로 간주한다.

breath_rpm과 apnea가 모두 있어야 현행 Quality Gate가 mmWave를 정상 입력으로 인정한다.
모델 파일·hash·tensor 계약 오류는 fallback provenance로 기록한다.

로컬 더미 입력으로 invoke()가 성공했다는 사실은 tensor와 실행 경로가 동작한다는 뜻일 뿐 정확도를 증명하지 않는다. 실제 CSV

와 source별 confusion matrix가 확보되기 전에는 모델의 호흡·무호흡 성능을 보장한다고 표기하지 않는다.

2. 핵심 의사결정: 통합 모델과 병렬 모델

2.1 데이터셋마다 노드를 만들면 안 되는 이유

데이터셋은 런타임 센서가 아니라 모델을 만드는 학습 근거다. 따라서 다음 구조는 기본안으로 채택하지 않는다.

세 모델이 같은 입력과 같은 라벨을 학습했다면 중복 계산이 많고, 신뢰도가 서로 다르며, 한 출처의 편향을 세 표처럼 잘못 세는 문제가 생

긴다. 병렬 모델은 데이터 출처가 다르다는 이유가 아니라 다른 역할을 수행할 때 사용한다.

2.2 권장 모델 역할

모델 역할 | 입력 | 출력 | 병렬 유지 이유
Respiration State | 30초 resp_phase

NORMAL, ABNORMAL,
APNEA
| | | 핵심 호흡 패턴 분류

Signal Quality

SNR, gap, phase variance,
motion, distance

GOOD, MOTION,
NO_TARGET, FAULT
| | | 낮은 품질을 APNEA로 오인하 지 않기 위해 분리

Presence/Multi-target

raw ADC/rFFT 또는 센서
presence

0/1/multi target, target bin

| | | 사람 수·위치 문제는 호흡 상태
와 다른 task
MR60 Specialist | MR60 breath_phase | 호흡 상태 | 기존 110명 도메인과 호환되지 않을 때만 사용

2.3 통합/분리 결정 트리

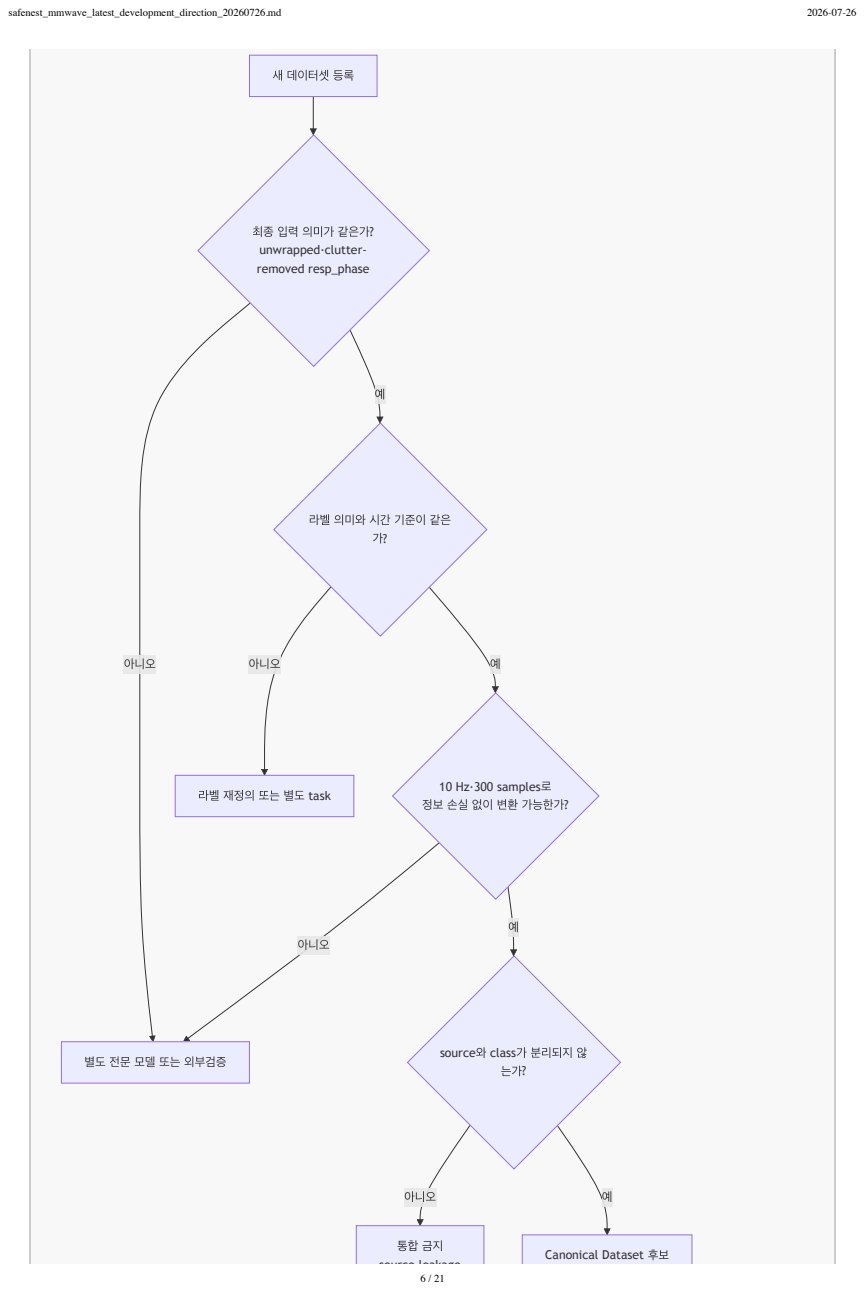
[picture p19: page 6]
아니오; 새 데이터셋 등록; 통합 금지 source leakage

최종 입력 의미가 같은가?
unwrapped·clutter-
removed resp_phase

라벨 의미와 시간 기준이 같은

10 Hz·300 samples로
정보 손실 없이 변환 가능한가?

라벨 재정의 또는 별도 task

source와 class가 분리되지 않

별도 전문 모델 또는 외부검증

Canonical Dataset 후보

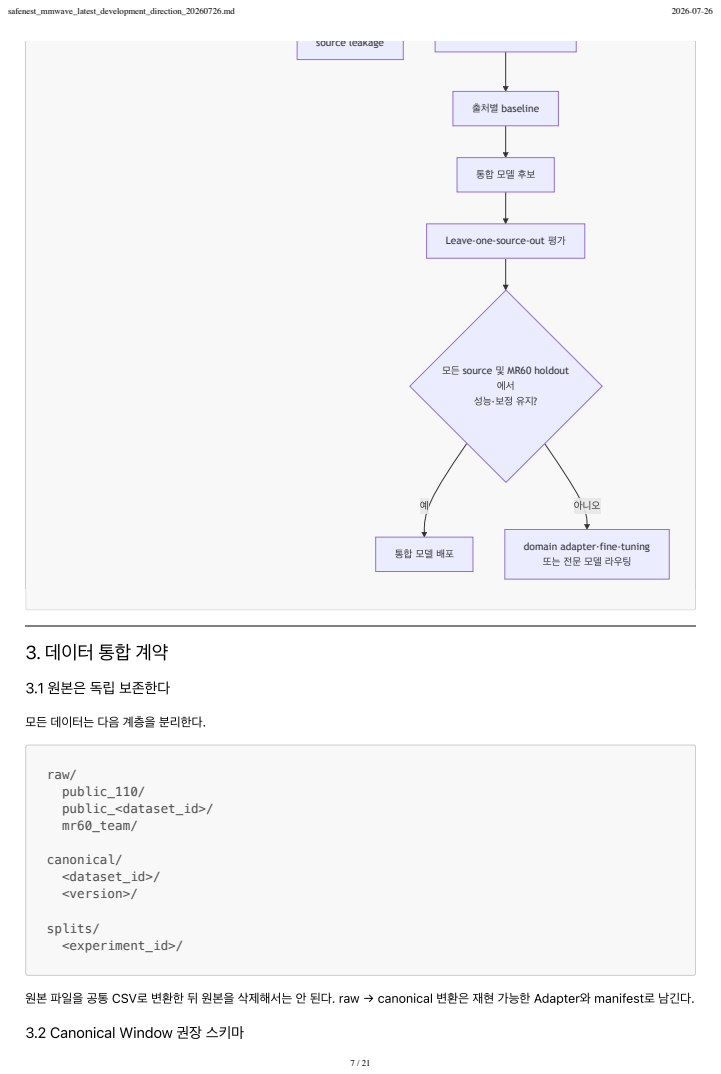
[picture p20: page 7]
아니오; source leakage; 출처별 baseline; raw/ public_110/ public_<dataset_id>/ mr60_team/; canonical/ <dataset_id>/ <version>/; splits/ <experiment_id>/

Leave-one-source-out 평가

모든 source 및 MR60 holdout

domain adapter·fine-tuning

또는 전문 모델 라우팅

3. 데이터 통합 계약

3.1 원본은 독립 보존한다

모든 데이터는 다음 계층을 분리한다.

원본 파일을 공통 CSV로 변환한 뒤 원본을 삭제해서는 안 된다. raw → canonical 변환은 재현 가능한 Adapter와 manifest로 남긴다.
3.2 Canonical Window 권장 스키마

window_id
timestamp_start_s
timestamp_end_s
subject_id
session_id
source_id
device_id
firmware_version
sensor_frequency_ghz
signal_semantic

resp_phase[300]
sample_rate_hz = 10
window_seconds = 30
stride_seconds = 3

presence
distance_m
breath_rpm_reference
apnea_reference
quality

label_respiration
label_presence
label_motion_artifact
ground_truth_source

label_respiration, label_presence, label_motion_artifact를 분리한다. 사람 부재, 센서 dropout, 큰 움직임을

APNEA에 포함하면 모델이 호흡 정지가 아니라 신호 소실을 학습하게 된다.

3.3 호환성 검사 항목

영역 | 확인 항목
신호 의미 | ADC, range FFT, phase, displacement, 제조사 처리 breath_phase 구분
단위·스케일 | rad, mm, arbitrary unit, unwrap 여부, filter 대역
시간 | 실제 sample rate, jitter, gap, window/stride
센서 | 주파수, 안테나, chirp, 펌웨어, 설치 거리·각도
라벨 | NORMAL, rapid, shallow, apnea의 정의와 최소 지속시간

ground truth 버튼, 호흡 벨트, ECG/PPG, mannequin 설정, 센서 자체 flag

누수 | subject/session/source가 train과 test에 중복되는지

3.4 통합 승인 시험

통합 모델은 최소 다음 비교를 통과해야 한다.

1. 현재 110명 모델 baseline
2. 출처별 단독 학습 baseline
3. 모든 호환 출처 통합 모델
4. 110명 모델을 MR60에 fine-tuning한 모델
5. 필요 시 역할별 전문 모델과 decision fusion

평가는 다음 단위로 별도 보고한다.

source별 confusion matrix
class별 precision, recall, F1
APNEA false negative와 false alarm/hour subject-independent test
leave-one-source-out test
MR60 현장 holdout
confidence calibration/ECE
Pi 5 p50·p95·p99 latency, RSS, throttling

통합 모델이 평균 성능만 높고 특정 source 또는 MR60 holdout을 악화시키면 통합 승인을 내리지 않는다.

4. 권장 학습 아키텍처

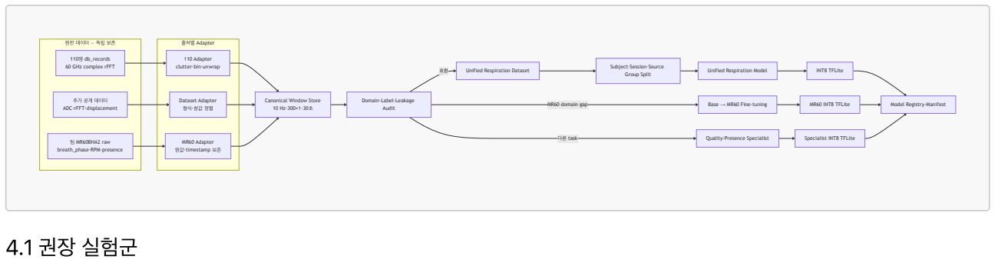
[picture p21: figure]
원천 데이터 — 독립 보존; 출처별 Adapter; MR60 domain gap; 다른 task; 110명 db_records 60 GHz complex rFFT; 추가 공개 데이터 ADC·rFFT·displacement; 팀 MR60BHA2 raw breath_phase·RPM·presence; 110 Adapter clutter·bin·unwrap; Dataset Adapter 형식·참값 정렬; MR60 Adapter 원값·timestamp 보존; Canonical Window Store 10 Hz·300×1·30초; Domain·Label·Leakage Audit; Unified Respiration Dataset; Base → MR60 Fine-tuning; Quality·Presence Specialist; Subject·Session·Source Group Split; Unified Respiration Model; INT8 TFLite; MR60 INT8 TFLite; Specialist INT8 TFLite; Model Registry·Manifest; 4.1 권장 실험군

ID | 후보 | 목적
B0 | 현재 110명 INT8 모델 | 기준선 고정
B1 | 110명 데이터 재학습 | split·class provenance 복구
U1 | 110명 + 호환 공개 데이터 | 통합 데이터 이점 검증
U2 U1 + 균형 잡힌 MR60 데이터 | 완전 통합 가능성 검증
F1 | B1 또는 U1 → MR60 fine-tuning | 장치 도메인 적응
E1 | Respiration + Quality 전문 모델 | motion/no-target 오탐 억제
E2 | Respiration + Presence/Multi-target 다중 인원 확장 시 사용

4.2 현재 권장 배포 순서

1. B0를 현행 baseline으로 유지한다.
2. 팀 MR60 raw로 B0의 외부검증을 먼저 수행한다.
3. Class 1 provenance를 복구하거나 2-class B1을 만든다.
4. 추가 공개 데이터는 바로 합치지 않고 Adapter·label audit를 선행한다.
5. U1/F1/E1을 동일 MR60 holdout에서 비교한다.
6. 가장 단순하면서 안전 성능을 만족하는 후보만 Pi 5에 배포한다.
5. 추가 공개 데이터셋 추천

추천 등급은 현재 SafeNest 목표인 호흡 이상·무호흡·밀폐공간 강건성·다중 인원 확장을 기준으로 한다.

5.1 추천 목록

우

선

순

위

데이터셋 | 센서·규모·참값 | 라이선스 | SafeNest 배치

기

준

Extensive Age-Balanced 110-
participant

TI IWR6843 계열 60 GHz, 110명 ·440회, rFFT, Movesense ECG·가속 도, breath-hold timestamp

CC BY
4.0

현 모델 baseline·재현 기준

P1

Radar Recorded
Child Vital Signs

TI IWR6843 60 GHz, 50명 아동, 20 fps raw IF·추출 신호, Nihon Kohden

호흡·심박 참값

CC0

같은 대역의 사람 데이터. phase 변환

후 조건부 통합 후보

P1

Three FMCW
Radars at Elevated
Position

IWR6843ISK+DCA1000 3대, 18명,

10 Hz, 호흡벨트, 자세·위치·움직임·빠른

호흡

CC BY
4.0

정지 단일표적 구간은 조건부 통합, 전체
는 자세·motion 전문 모델

P1 SiViS

IWR6843AOP, 2~3개 의료
mannequin, RR
0~33·apnea·distress, raw complex
I/Q

저장소

조건 재

확인

Quality·multi-target·Class 1 사전

연구

P1

120 GHz Vital
Signals with
synchronized
references

custom 122~123 GHz, 24명,
resting·자발성 apnea, displacement
와 ECG·PPG·호흡 참값

CORA

공개본
CC0

APNEA 독립 외부검증, raw 직접 병합

금지

P1

Clinically Recorded
Radar Vital Signs

24 GHz Six-Port CW I/Q, 30명, ECG·ICG·흉부 임피던스·혈압, breath-hold 등

CC BY
4.0

임상 외부검증·표현 사전학습, raw 직접

병합 금지

P2

Diverse
Physiological
Scenarios

AWR1642 77~81 GHz, 10명, 20 fps ADC·range map·chest
displacement, Polar H10

CC BY-NC-SA
4.0

feature-level 조건부 통합 또는 외부검

증

P2

60 GHz Multi-person Vital Signs

IWR6843ISK+DCA1000, 2명 동시,
raw ADC, ADS1292R ECG·호흡 참값

CC BY
4.0

target
separation·presence·quality 전

문 모델

다음 자료는 현재 1차 도입 대상에서 제외한다.

IR-UWB 데이터는 motion/quality 연구에는 도움이 되지만 MR60 respiration 모델의 직접 증강 자료가 아니다. 감정 분류용 mmWave 데이터는 apnea/rapid 라벨이 없어 우선순위가 낮다.

CWT 이미지 데이터는 현행 1D resp_phase 입력과 표현이 달라 직접 병합하지 않는다.

피험자 1명 데이터는 일반화 학습이 아니라 장애물·SNR 회귀시험에만 사용한다.

5.2 데이터셋별 권장 배치도

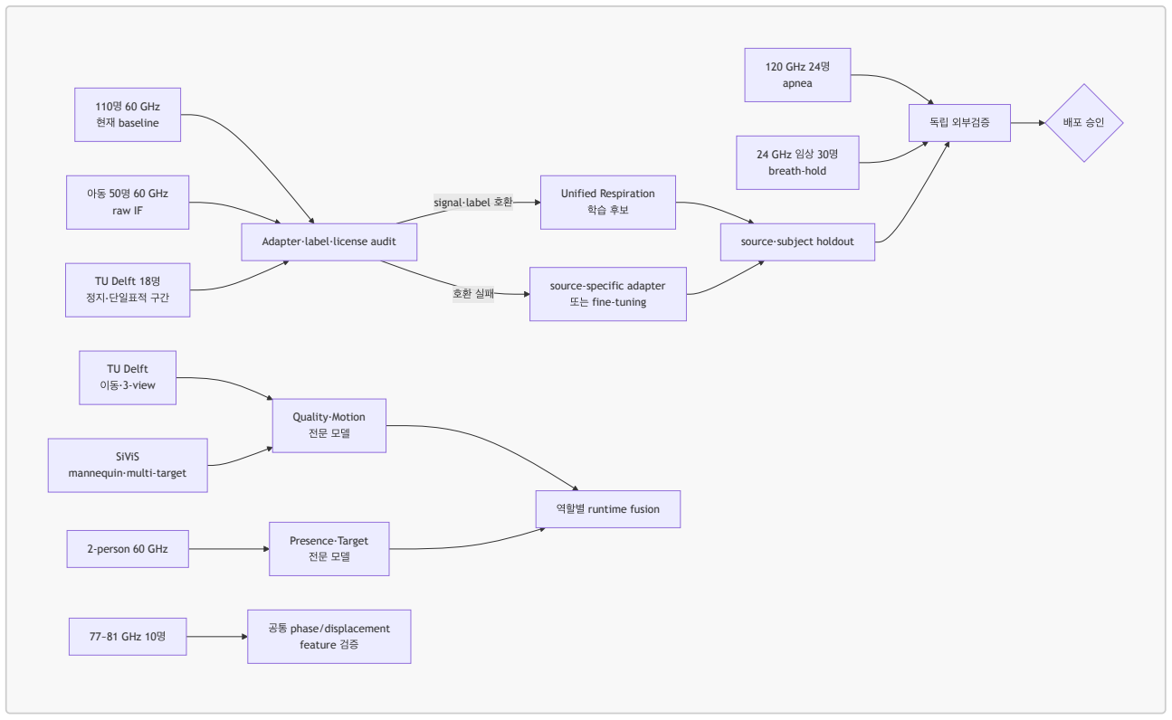
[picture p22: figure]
signal·label 호환; 110명 60 GHz 현재 baseline; Adapter·label·license audit; 아동 50명 60 GHz raw IF; TU Delft 18명; 정지·단일표적 구간; Unified Respiration 학습 후보; source-specific adapter 또는 fine-tuning; TU Delft 이동·3-view; Quality·Motion 전문 모델; SiViS mannequin·multi-target; 2-person 60 GHz; Presence·Target 전문 모델; 120 GHz 24명 apnea; 독립 외부검증; 24 GHz 임상 30명 breath-hold; 77~81 GHz 10명; 공통 phase/displacement feature 검증; source·subject holdout; 역할별 runtime fusion

핵심은 아동·TU Delft 데이터도 파일을 내려받았다는 이유만으로 합치는 것이 아니라, signal_semantic, 참값 정의, source

leakage 시험을 통과한 구간만 통합하는 것이다.

5.3 상세 추천 판단

A. 50명 아동 60 GHz — 가장 먼저 확인할 직접 보강 후보

데이터: Figshare DOI 10.6084/m9.figshare.13515977.v1 (https://doi.org/10.6084/m9.figshare.13515977.v1)
논문: Sensors 2021, child vital-sign dataset (https://doi.org/10.3390/s21072412)
센서·참값: TI IWR6843, 60.25 GHz 시작·3.75 GHz bandwidth, 20 fps, raw IF와 추출 vital signal, Nihon Kohden
BSM6501K 동기 참값

장점: 현재 110명 및 MR60과 같은 60 GHz 계열의 실제 사람 데이터이고 아동 50명으로 연령 도메인을 넓힌다.

제한: 차량 환경·아동 도메인이며 명시적 apnea 학습셋이 아니다. 몸 움직임 구간을 APNEA나 RAPID로 매핑하면 안 된다.
결정: range-bin → phase unwrap/displacement → 20→10 Hz → 300 sample Adapter를 만든 뒤 NORMAL·quality 도메인 보강에 조건부 사용한다. dataset_id, age_group, vehicle/motion 태그를 유지하고 source-balanced sampler를 사용한다.
B. 18명·3레이더 TU Delft — 자세·움직임과 Class 1 검증 후보

데이터: 4TU DOI 10.4121/169cadca-e5dd-46e7-a9c5-91a4c9b1ff28.v1 (https://doi.org/10.4121/169cadca-e5dd-46e7-a9c5-91a4c9b1ff28.v1)
공식 설명: TU Delft Research Portal (https://research.tudelft.nl/en/datasets/dataset-of-vital-sign-measurements-with-three-fmcw-radars-at-elev/)
센서·참값: IWR6843ISK+DCA1000 3대, 60/61.25/62.5 GHz FDMA, 10 Hz raw .bin, respiration belt

장점: 착석·누움·임의 위치·자세 변경·연속 이동·20초 빠른 호흡과 3개 elevated view를 포함한다.

제한: apnea 라벨은 없고, 다중 view를 한 sample처럼 합치면 현 단일 MR60 배포 조건과 달라진다.

결정: 정지·단일 radar 구간은 reference RR로 RAPID 기준을 다시 계산한 뒤 조건부 통합한다. 움직임·자세·다중 view 구간은
Quality/Motion 모델 및 stress test에 사용한다.
C. SiViS — 통제된 apnea·multi-target 전문모델 후보

DOI: 10.7910/DVN/S9SNAK (https://doi.org/10.7910/DVN/S9SNAK)

논문: Scientific Data, SiViS (https://www.nature.com/articles/s41597-025-06449-9)
장점: RR=0 apnea부터 빠른 호흡까지 프로그램된 참값, 2~3개 target, 거리·각도·chirp 변화, IWR6843AOP raw complex sample을 제공한다.

제한: 사람 대신 의료 mannequin이므로 실제 흉부 미세운동 분포와 다르다.
결정: 최종 사람 호흡 모델의 단독 근거로 사용하지 않는다. Quality, Multi-target, Range-bin, Class 1 사전학습에

사용하고 사람 holdout으로 반드시 재검증한다.

D. 120 GHz Rest/Apnea — APNEA 독립 외부검증 후보

데이터: CORA DOI 10.34810/DATA2962 (https://doi.org/10.34810/DATA2962)
논문: Scientific Data, 120 GHz vital signals (https://www.nature.com/articles/s41597-026-07016-6)
장점: 24명, 명시적 resting·자발성 apnea 절차, ECG·PPG·호흡 신호가 동기화돼 있어 onset과 recovery를 평가할 수 있다. 제한: 120 GHz custom radar이며 제공 신호가 displacement 중심이다.
결정: 60 GHz rFFT와 raw 수준에서 병합하지 않는다. 공통 displacement/phase 표현으로만 변환해 APNEA 외부검증 및 representation 비교에 사용한다.
E. 24 GHz 임상 데이터 — 센서가 다른 독립 안전성 시험 후보

데이터: Figshare DOI 10.6084/m9.figshare.12186516.v2 (https://doi.org/10.6084/m9.figshare.12186516.v2)
논문: Scientific Data, clinically recorded radar vital signs (https://doi.org/10.1038/s41597-020-00629-5)
장점: 30명, 24 GHz CW I/Q와 ECG·ICG·흉부 임피던스·혈압이 동기화되고 흡기·호기 breath-hold, Valsalva, tilt 조건이 있

다.

제한: FMCW가 아닌 Six-Port CW이고 입력 표현과 대역이 다르다.
결정: raw 직접 통합하지 않는다. breath-hold 검출의 센서간 독립 검증이나 self-supervised representation 연구에 사용한

다.

F. 77~81 GHz 및 2-person 60 GHz — 기능 확장용 P2

77~81 GHz: 4TU Diverse Physiological Scenarios는 (https://doi.org/10.4121/48acba04-96bc-4131-b52f-9e18458ad92b) ADC·range map·chest displacement와 운동 후·천식·명상 조건

을 제공한다. 조건명이 아니라 실제 reference RR 기준을 만족한 구간만 RAPID 후보로 사용한다.
2-person 60 GHz: Mendeley Multi-person Vital Signs는 (https://doi.org/10.17632/684v4r8wfr.1) IWR6843ISK raw ADC와 ADS1292R 참값을 제공하지만 피 험자 수가 적고 apnea 라벨이 없다. 주 분류기에 섞지 말고 target separation·presence·quality 노드에 사용한다.

5.4 실제 도입 순서

1. 현재 110명 v1.1의 ExampleCode.ipynb, helper, damaged-frame skip 목록, DOI·파일 hash를 먼저 동결해 B0 재현

기준을 만든다.
2. 아동 50명 데이터의 metadata와 2~3명 sample로 raw IF→canonical phase Adapter를 검증한다.
3. TU Delft 데이터의 ReadMe와 정지·빠른 호흡·움직임 sample을 받아 label 및 단일-radar 분리가 가능한지 확인한다.
4. SiViS metadata·sample·decoder로 multi-target/quality 전문모델의 입력 계약을 확인한다.
5. 120 GHz와 24 GHz 데이터는 2~3명씩 받아 apnea/breath-hold boundary를 공통 평가 포맷으로 변환한다.
6. multi-person 전체 다운로드는 Presence/Target 노드 개발 착수 시점으로 미룬다.

각 데이터는 전체 다운로드 전에 최신 이용조건을 다시 확인하고 아래 산출물을 승인받는다.

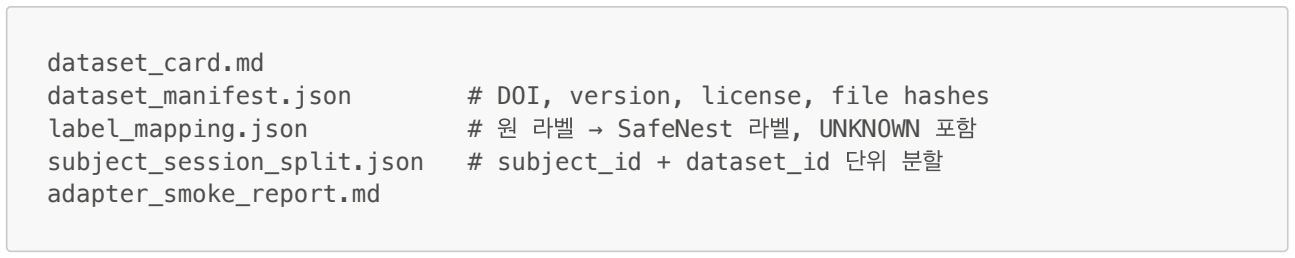
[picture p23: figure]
dataset_card.md; adapter_smoke_report.md

dataset_manifest.json | # DOI, version, license, file hashes
label_mapping.json | # 원 라벨 → SafeNest 라벨, UNKNOWN 포함
subject_session_split.json | # subject_id + dataset_id 단위 분할

무작위 window 분할은 금지한다. 동일 인물·세션의 인접 window가 train/test에 동시에 들어가면 데이터 증강이 아니라 누수가 된다.

운동 후, 천식, 빠르게 호흡 지시도 reference RR 및 지속시간 기준을 만족한 경우에만 RAPID_OR_ABNORMAL로 매핑하고, 나머지
는 UNKNOWN 또는 보조 domain label로 유지한다.

## 6. 팀 자체 MR60BHA2 데이터 방향

6.1 초기 역할

팀 raw 데이터는 처음부터 110명 데이터에 합치는 학습 재료가 아니다. 우선 다음 세 목적으로 사용한다.

1. MR60 breath_phase와 110명 unwrapped phase의 도메인 차이 측정
2. 기존 모델의 field holdout 평가
3. 센서·설치·환경별 calibration 및 Quality Gate 설계

6.2 수집 필수 조건

그룹 | 수집 조건
NORMAL | 여러 피험자, 날짜, 누움/정지 조건
RAPID | 참조 호흡수와 함께 안전하게 유도된 빠른 호흡

SLOW/SHALLOW 명확한 protocol과 호흡 참조센서 필요

APNEA | 안전관리·동의·중단 조건이 있는 짧은 breath-hold
NO_TARGET | 빈방, 진입 전, 퇴장 후
MOTION | 자세 변경, 뒤척임, 센서 흔들림
HARD NEGATIVE | 팬, 에어컨, 커튼, 반사체, 차량/기계 진동
DOMAIN | 0.5/1.0/1.5 m, 각도·높이, 방, firmware/device 반복

MR60BHA2 공식 안내는 호흡·심박 기능을 약 1.5 m 이내의 정지한 단일 대상, 특히 수면 환경 중심으로 설명한다. 따라서 데이터는 다

음처럼 구분한다.

primary distribution: 제조사 권장 설치·정지 단일 대상

stress test: 거리 초과, 움직임, 다중 대상, 팬·커튼·진동

공식 참고: Getting started with MR60BHA2 (https://wiki.seeedstudio.com/getting_started_with_mr60bha2_mmwave_kit/)

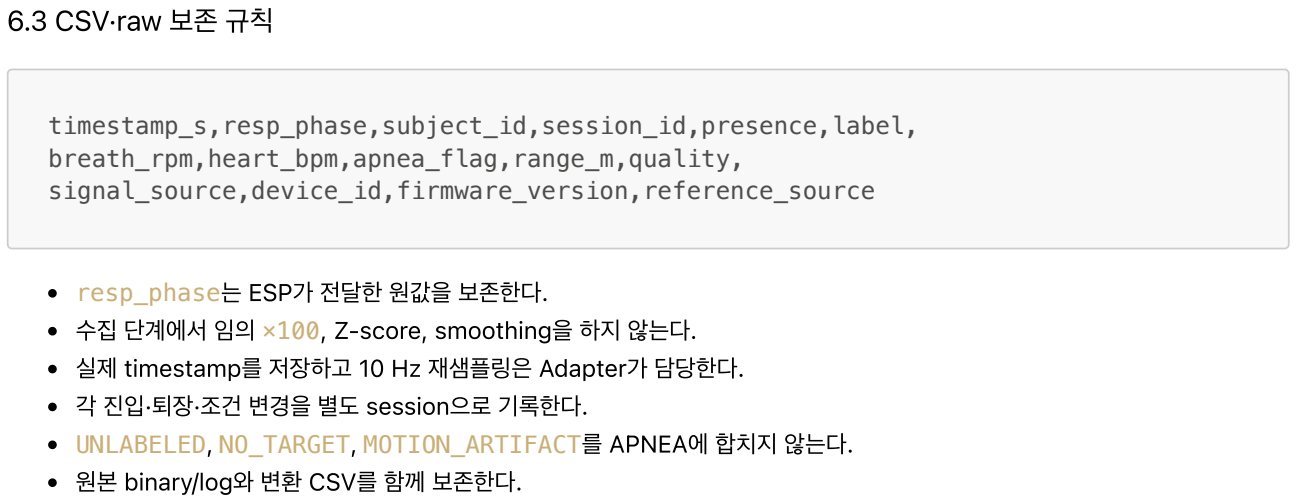
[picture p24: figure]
6.3 CSV·raw 보존 규칙; timestamp_s,resp_phase,subject_id,session_id,presence,label, breath_rpm,heart_bpm,apnea_flag,range_m,quality, signal_source,device_id,firmware_version,reference_source; resp_phase는 ESP가 전달한 원값을 보존한다.; 각 진입·퇴장·조건 변경을 별도 session으로 기록한다.; 원본 binary/log와 변환 CSV를 함께 보존한다.

수집 단계에서 임의 ×100, Z-score, smoothing을 하지 않는다.
실제 timestamp를 저장하고 10 Hz 재샘플링은 Adapter가 담당한다.

UNLABELED, NO_TARGET, MOTION_ARTIFACT를 APNEA에 합치지 않는다.

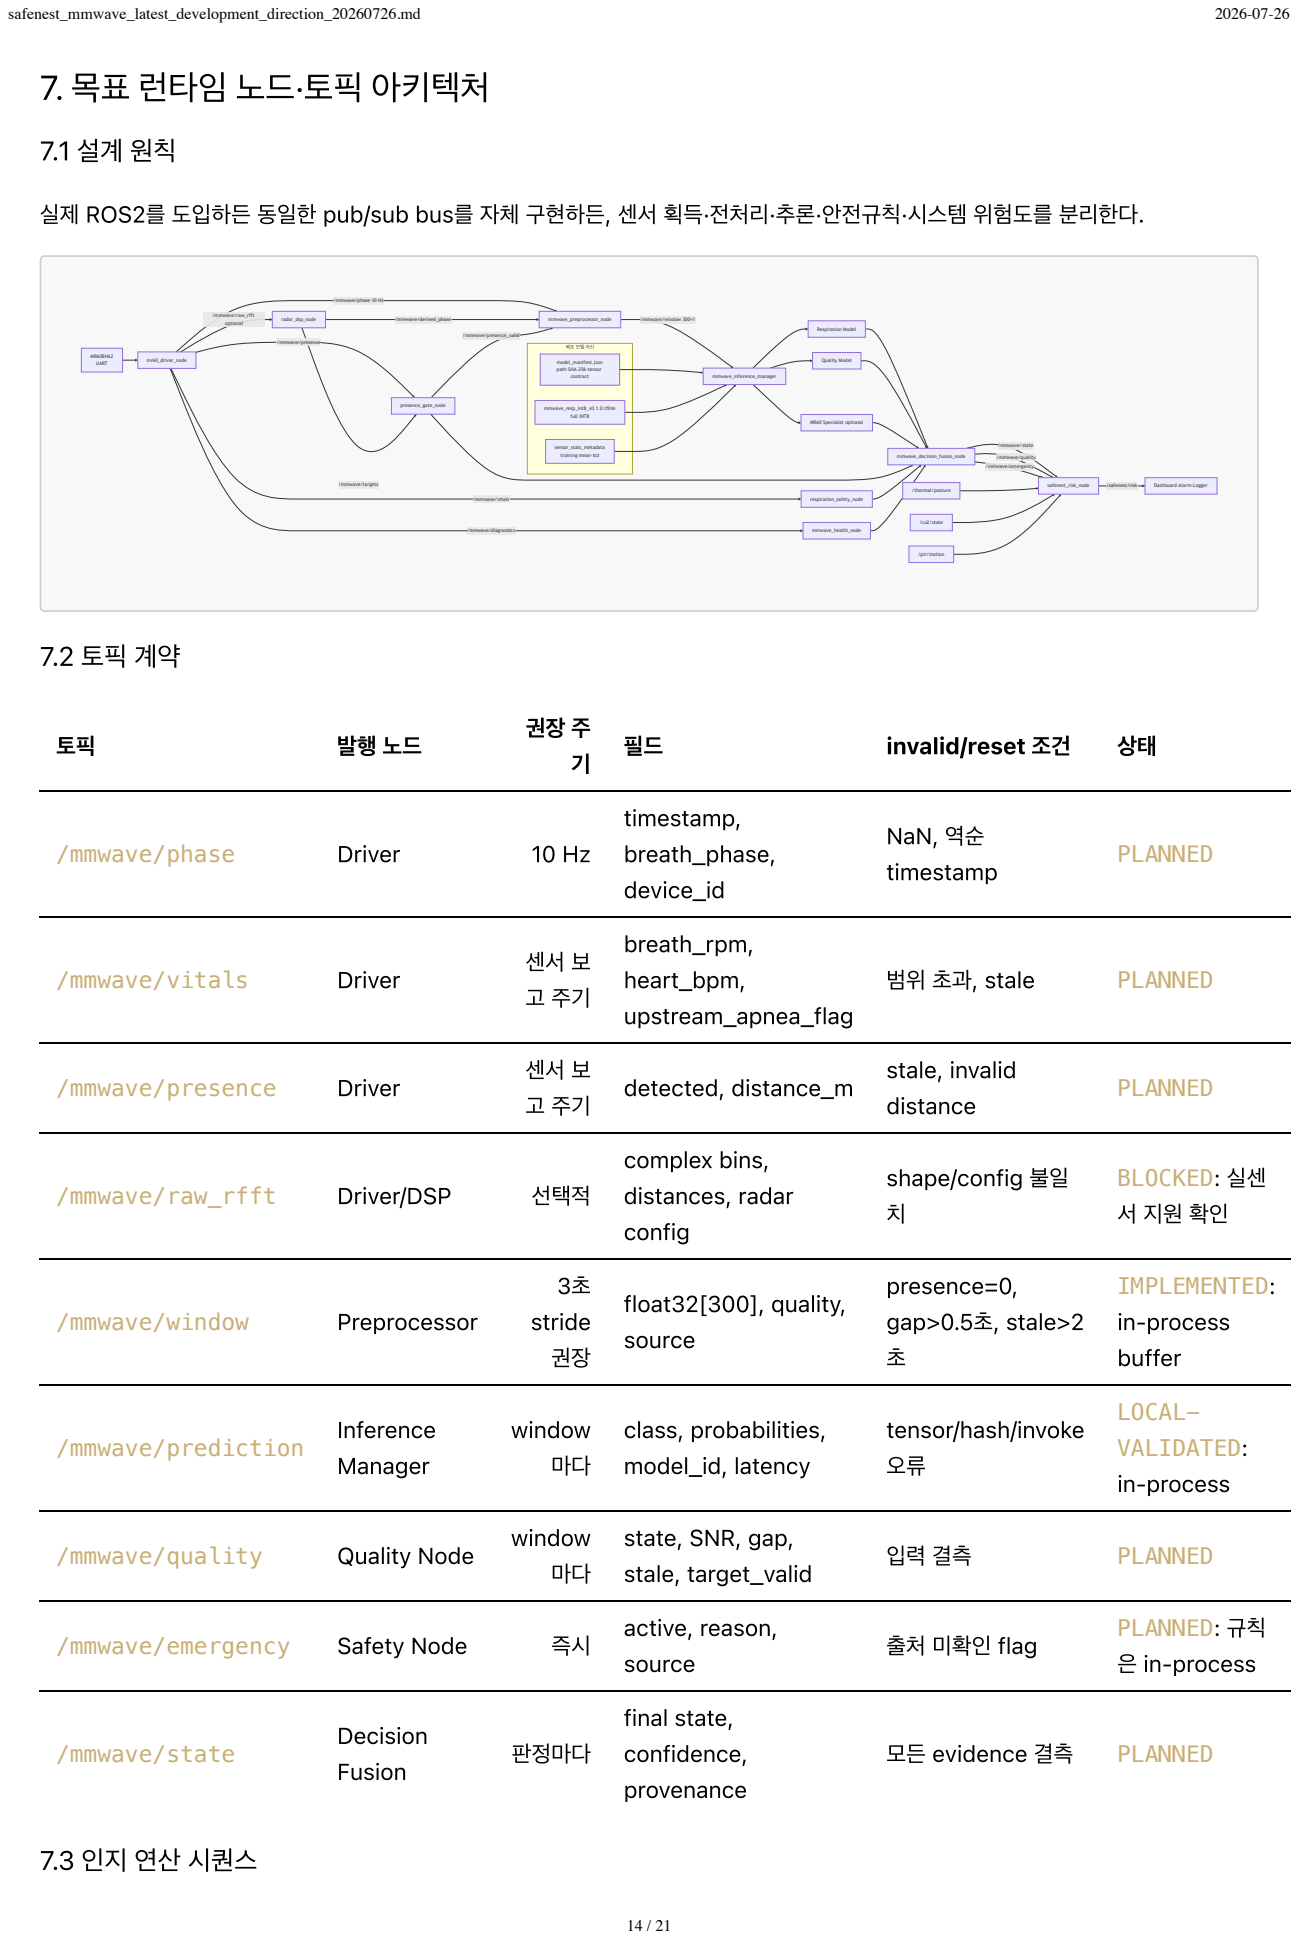
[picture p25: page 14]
/mmwave/presence; /mmwave/vitals; /mmwave/raw_rfft optional; /mmwave/diagnostics; /mmwave/derived_phase; /mmwave/targets; /mmwave/presence_valid; /mmwave/window 300×1; /mmwave/state; /safenest/risk; MR60BHA2 UART; mr60_driver_node; presence_gate_node; respiration_safety_node; radar_dsp_node; mmwave_preprocessor_node; mmwave_health_node; mmwave_resp_int8_v0.1.0.tflite full INT8; Respiration Model; Quality Model; MR60 Specialist optional; mmwave_decision_fusion_node; safenest_risk_node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

7. 목표 런타임 노드·토픽 아키텍처

실제 ROS2를 도입하든 동일한 pub/sub bus를 자체 구현하든, 센서 획득·전처리·추론·안전규칙·시스템 위험도를 분리한다.

/mmwave/phase 10 Hz

mmwave_inference_manager model_manifest.json path·SHA-256·tensor contract

sensor_stats_metadata
training mean·std

/mmwave/quality /mmwave/emergency

Dashboard·Alarm·Logger

shape/config 불일

tensor/hash/invoke

state, SNR, gap,
stale, target_valid

출처 미확인 flag

7.3 인지 연산 시퀀스

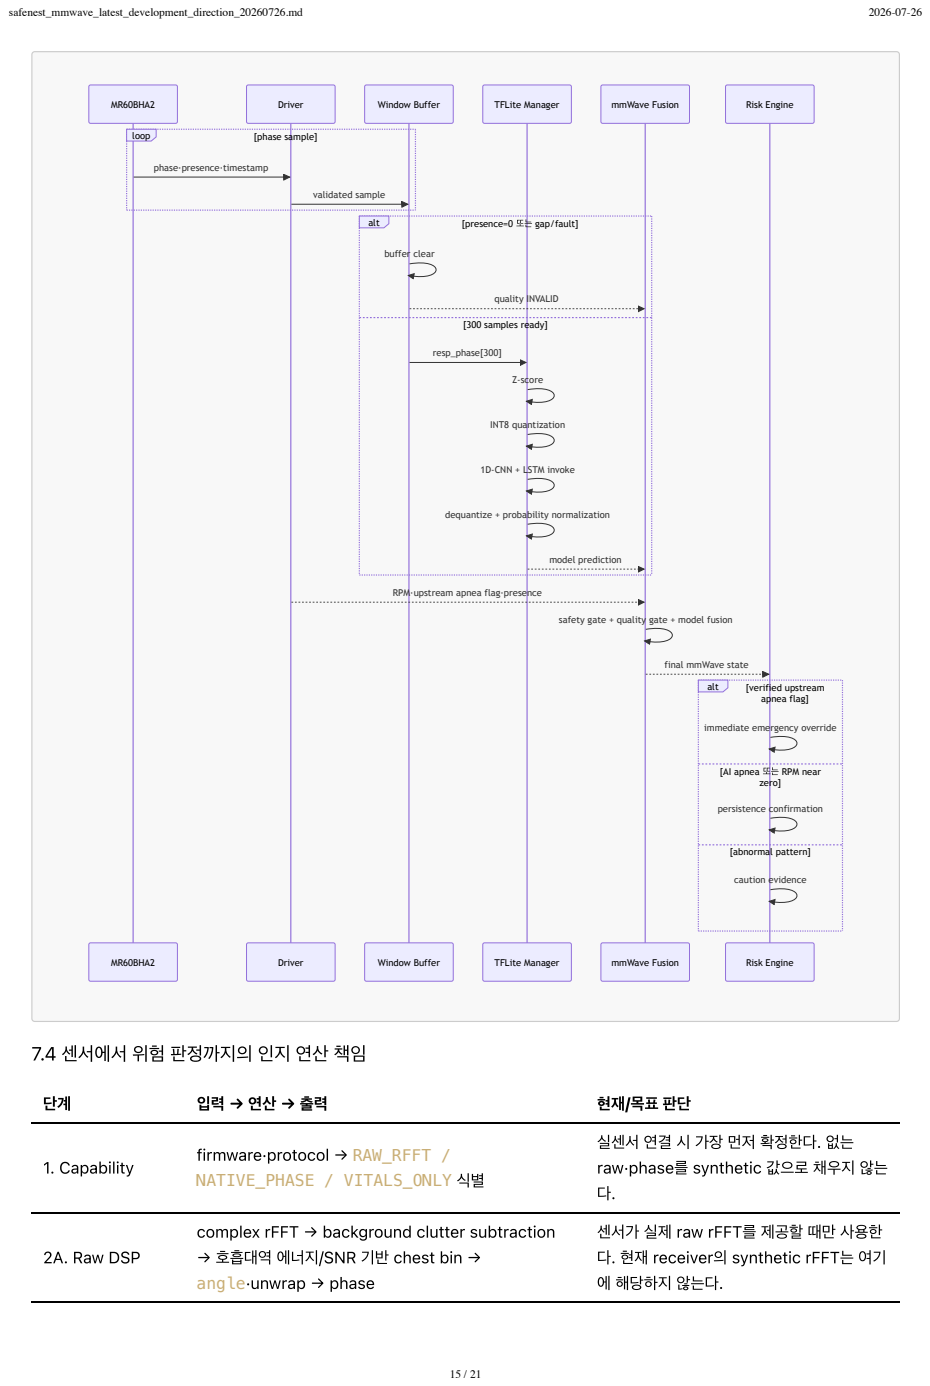
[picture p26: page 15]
MR60BHA2; Driver; Window Buffer; TFLite Manager; mmWave Fusion; Risk Engine; loop; [phase sample]; alt; [presence=0 또는 gap/fault]; [300 samples ready]; [verified upstream; apnea flag]; zero]; [abnormal pattern]; validated sample; buffer clear; quality INVALID; resp_phase[300]; Z-score; INT8 quantization; model prediction; persistence confirmation; caution evidence; 1. Capability; firmware·protocol → RAW_RFFT / NATIVE_PHASE / VITALS_ONLY 식별; 2A. Raw DSP

phase·presence·timestamp

1D-CNN + LSTM invoke

dequantize + probability normalization

RPM·upstream apnea flag·presence

safety gate + quality gate + model fusion

final mmWave state

immediate emergency override

[AI apnea 또는 RPM near

7.4 센서에서 위험 판정까지의 인지 연산 책임

실센서 연결 시 가장 먼저 확정한다. 없는
raw·phase를 synthetic 값으로 채우지 않는

complex rFFT → background clutter subtraction
→ 호흡대역 에너지/SNR 기반 chest bin →
angle·unwrap → phase

센서가 실제 raw rFFT를 제공할 때만 사용한
다. 현재 receiver의 synthetic rFFT는 여기
에 해당하지 않는다.

단계 | 입력 → 연산 → 출력 | 현재/목표 판단

2B. Native phase

제조사 breath_phase → timestamp·단위·filter 의미 검증 → canonical phase

MR60 native phase가 110명 모델의 resp_phase와 같은 의미인지 domain audit가 필요하다.

3.
Presence/Quality

presence·distance·gap·stale·motion·SNR →
VALID/NO_TARGET/MOTION/FAULT 및 quality
| | 사람 부재·신호 소실을 APNEA로 오인하지
| | 않도록 AI보다 앞에서 gate한다.
4. Window

valid phase → 실제 10 Hz grid 재샘플링 → 300 sample·29.9초 coverage 확인

presence loss, gap>0.5초, timestamp 역순, stale이면 reset/abstain한다.

5. Model input

window → 학습 metadata의 global mean/std Z-score → manifest scale·zero point로 INT8 quantization

| | 현재 wrapper가 수행한다. 전처리 의미는 실
제 Colab notebook과 대조해야 한다.
6. AI inference

INT8 [1,300,1] → 1D-CNN 특징 → LSTM 시간 패
턴 → Dense/Softmax → 3-class probability

모델은 30초 패턴 증거이며 즉시 안전센서가
아니다. confidence·calibration·abstain

을 추가한다.

7. mmWave
fusion

AI 확률 + Quality + Presence + RPM + 검증된 upstream flag → 최종 mmWave state

모델 출처별 다수결이 아니라 역할별
evidence와 provenance를 융합한다.
8. System risk

mmWave state + Thermal + CO₂ + PIR → rule·persistence·hysteresis → alarm/dashboard/log

검증된 fast safety path는 smoothing을 우회하고, 모델 오류·fallback은
DEGRADED/FAULT로 전파한다.

모델 파일은 센서 값을 직접 읽지 않는다. Driver가 발행한 신호를 Preprocessor가 모델 입력으로 만들고, Inference Manager가 manifest의 경로·SHA-256·tensor shape·INT8 scale을 검증한 뒤 모델을 호출한다. 모델이 없거나 hash/load/invoke 오류가 나

면 현재 코드의 heuristic 결과를 학습 모델 판정처럼 사용하지 않고 fallback_used=true와 원인을 함께 발행해야 한다.

## 8. Decision Fusion 정책

8.1 우선순위

1. 센서 fault와 no-target를 먼저 판정한다.
2. presence가 없으면 flat phase를 APNEA로 분류하지 않는다.
3. 출처와 의미가 검증된 upstream apnea flag는 빠른 안전 경로로 보낸다.
4. AI APNEA는 presence·quality·지속시간과 함께 확인한다.
5. 미검증 Class 1은 확정 위험이 아니라 추가 증거로만 사용한다.
6. 모델 충돌은 억지 다수결 대신 UNCERTAIN/DEGRADED와 provenance를 발행한다.

8.2 같은 라벨 공간의 병렬 모델을 사용할 때

MR60 specialist와 global respiration 모델을 동시에 실행한다면 단순 다수결을 사용하지 않는다.

p_fused = normalize(Σ quality_m × calibration_weight_m × p_m)

다만 device_id=MR60BHA2처럼 배포 도메인을 알고 있는 경우에는 다음 순서를 우선한다.

1. 사전 결정된 MR60 모델로 routing
2. global 모델은 shadow evaluation 또는 fallback
3. 두 모델 동시 추론은 비교 실험 기간에만 허용

이는 중복 모델을 영구 실행해 Pi 5 지연과 메모리를 늘리는 것을 방지한다.

9. 현재 코드와 목표 구조의 차이
Gap | 현재 | 목표

우

선

순

위

실센서 연결

sensor_receiver.py가 화면 출력

중심

| | Driver가 표준 message publish | P0
rFFT | receiver 내부 synthetic rFFT | 실제 센서 raw 가능 여부 확인 후 실제 DSP | P0
phase 경로 | 가상 streamer가 resp_phase 생성 | 실제 MR60 breath_phase 수신·timestamp | P0
노드 통신 | in-process dictionary | ROS2 또는 명시적 pub/sub interface | P1
inference stride | buffer 준비 후 매 sample 추론 가능 | 학습과 일치하는 3초 stride 명시 | P1

시간축 계약

10 Hz 선언만 있고 실시간 재샘플링
·coverage 검사 없음
| | canonical 10 Hz grid와 실제 29.9초 coverage 검사 | P0
presence reset | phase 없는 presence=0 event가 buffer를 못 비울 수 있음 | presence event가 독립적으로 buffer reset | P0
Quality Gate | 필드 존재 중심 0/1 품질 | SNR·gap·stale·motion·distance 연속 품질 | P1
confidence | class index만 규칙에 전달 | calibration·confidence threshold·abstain | P1

상태 의미

NO_TARGET/WINDOW_NOT_READY 도 DEGRADED로 혼합

NO_TARGET·WARMING_UP·READY·DEGRADED·FAULT

분리

P0

오류 전파

일부 load/hash/init 오류가 system status와 분리될 수 있음

모든 model health 오류를 diagnostics와 system status에

전파

P0

위험 단계

호흡 CAUTION이 최종 가중합에서는
NORMAL에 머물 수 있음
| sensor severity와 system severity 전달 정책 명시 | P0

raw DSP 연

결

chest bin 계산과 모델 입력이 분리 | rFFT→clutter→target bin→phase→window 연결 | P1

전처리 의미

guide와 metadata의 clutter 제거 의미

가 완전히 대조되지 않음

| | 실제 Colab notebook으로 signal semantic 확정 | P0
Class 1 | manifest에 존재, provenance 불명 | 데이터 확보 또는 2-class 전환 | P0
Pi 성능 | Mac local 검증 | Pi 5 p95/RSS/thermal 검증 | P0
provenance 모델·metadata 중심 | dataset DOI/hash/split/training commit 포함 | P0
CLI smoke | unit test 밖의 CLI가 구형 결과 key를 참 조 | process-level CLI/GUI smoke test | P1

중요: 현재 mr60/sensor_receiver.py의 rFFT는 실제 센서 raw가 아니라 알고리즘 표시용 합성 데이터다. 따라서 해당 코드의
clutter map과 adaptive chest bin 화면을 실센서 검증 결과로 표기하면 안 된다.

10. 단계별 실행 계획

Phase 0 — 기준선과 provenance 고정

작업:

110명 데이터 DOI·버전·파일 해시 기록
실제 학습 notebook과 class 생성 코드 고정 train/val/test subject 목록 복구
현재 TFLite와 metadata 연결 확인

Class 1 양성 데이터 존재 여부 확정

완료 조건:

dataset_manifest.json
split_manifest.json
training_manifest.json
클래스별 sample/window 수
재학습 또는 2-class 결정

Phase 1 — 실제 MR60 Driver 구축

작업:

UART/ESP에서 breath_phase, RPM, HR, presence, distance, firmware 수신 단조 timestamp 부여
표준 message/packet 발행

실센서 raw rFFT 지원 여부를 제조사 protocol 기준으로 확정
센서 capability를 RAW_RFFT / NATIVE_PHASE / VITALS_ONLY로 선언하고 지원되지 않는 신호를 synthetic 값으

로 채우지 않기

완료 조건:

10 Hz phase 장기 로그
missing/gap/stale 통계
실제 10 Hz 재샘플링·coverage와 독립 presence reset 검증 receiver→preprocessor→inference end-to-end 실행 synthetic와 real 필드 명확한 분리

Phase 2 — 팀 데이터 수집·도메인 감사

작업:

primary와 stress test를 분리 수집
MR60 mean/std, PSD, SNR, amplitude, gap 분석 110명 phase와 MR60 phase의 의미·스케일 비교 현재 모델을 MR60 holdout에 실행

완료 조건:

mr60_domain_audit.md
session별 예측과 오류 분석
source-only baseline
domain adapter/fine-tuning 필요 여부 결정

Phase 3 — 추가 데이터 intake

작업:

P1 데이터셋 소량 샘플 다운로드
라이선스·형식·decoder·ground truth 확인 Canonical Adapter prototype
Class 1, apnea, multi-target에 실제로 기여하는지 평가

완료 조건:

데이터셋별 dataset_intake_report.md

직접 통합/조건부 통합/전문 모델/외부검증 분류

대용량 전체 다운로드 승인 여부

Phase 4 — 모델 후보 비교

작업:

B1, U1, F1, E1 실험
source/subject-independent 평가 quantization 전후 성능 비교
confidence calibration

완료 조건:

동일 test protocol의 모델 비교표
APNEA false negative와 false alarm/hour 최종 candidate와 rollback model 선택

Phase 5 — 노드·Fusion 구현

작업:

Driver, Preprocessor, Inference Manager, Quality, Safety, Fusion 분리 topic/message contract test
model_id, version, latency, fallback provenance 출력
upstream fast safety path와 AI slow path 결합

완료 조건:

노드별 unit test
message contract test
sensor dropout·presence loss·model failure fault injection emergency path가 smoothing을 우회하는지 검증

Phase 6 — Pi 5와 현장 검증

작업:

Pi 5 p50/p95/p99 latency, RSS, CPU, 온도 24~72시간 soak test

빈방·팬·커튼·진동·진입퇴장·정상·무호흡 시나리오
model rollback과 health telemetry 확인

완료 조건:

pi_validated

실제 센서 HIL 통과 후 field_validated 검증 증거와 함께 release version 고정

11. 최종 권장 아키텍처 요약

multi-target/raw ADC → Presence·Target Specialist; motion/no-target; → Signal Quality Specialist; 런타임 단계 MR60 Driver; ├─ presence/distance → Presence Gate ├─ signal stats → Quality Model

호환 공개셋 ├─ Adapter → Canonical Dataset → Unified Respiration Model
MR60 raw ──┘ | └→ 호환 실패 시 MR60 fine-tuning

├─ phase → 30초 window → Respiration Model

└─ RPM/verified upstream apnea flag → Fast Safety Rule

모든 결과 → mmWave Decision Fusion → SafeNest Risk Engine

따라서 현 시점의 최선은 다음과 같다.

1. 현재 110명 모델을 baseline으로 유지한다.
2. 팀 MR60 데이터는 즉시 합치지 않고 실센서 외부검증과 domain audit에 사용한다.
3. Class 1 학습 근거를 복구하거나 2-class 모델을 병행 제작한다.
4. 추가 데이터는 아동 50명 60 GHz → TU Delft 18명 → SiViS 순으로 Adapter 적합성을 먼저 본다.
5. 120 GHz 24명과 임상 24 GHz 30명은 APNEA/breath-hold 독립 외부검증에 사용한다.
6. 호환성이 입증된 사람·구간만 unified respiration model에 통합하고 source-balanced 학습을 적용한다.
7. 다중표적·움직임·신호품질 데이터는 호흡 모델에 억지로 섞지 않고 전문 모델로 분리한다.
8. 병렬 노드는 데이터셋별이 아니라 Respiration·Quality·Presence라는 역할별로 구성한다.
12. 참고 자료

내부 기준

models/model_manifest.json models/mmwave/sensor_stats_metadata_v0.1.0.json inference/mmwave_interpreter.py adapters/mmwave_stream_adapter.py adapters/mmwave_csv_adapter.py integrated_node/safenest_risk_engine.py mr60/sensor_receiver.py
walkthrough/MMWAVE_MODEL_IMPORT_VALIDATION_20260725.md walkthrough/MMWAVE_CSV_HANDOFF_DECISION_20260725.md

외부 기준

110-participant dataset v1.1 repository (https://doi.org/10.5281/zenodo.18599983)
110-participant 60 GHz vital-sign dataset paper (https://www.nature.com/articles/s41597-026-07172-9)


50-child 60 GHz vital-sign dataset (https://doi.org/10.6084/m9.figshare.13515977.v1)
50-child dataset paper (https://doi.org/10.3390/s21072412)
TU Delft three-radar, 18-participant dataset (https://doi.org/10.4121/169cadca-e5dd-46e7-a9c5-91a4c9b1ff28.v1)
SiViS multi-patient physiological states (https://www.nature.com/articles/s41597-025-06449-9)
120 GHz synchronized vital signals (https://www.nature.com/articles/s41597-026-07016-6)
120 GHz CORA dataset (https://doi.org/10.34810/DATA2962)
24 GHz clinically recorded radar vital signs (https://doi.org/10.6084/m9.figshare.12186516.v2)
4TU diverse physiological scenarios (https://research.utwente.nl/en/datasets/mm-wave-fmcw-radar-vital-sign-monitoring-dataset-diverse-physiolo/)
60 GHz multi-person vital signs (https://data.mendeley.com/datasets/684v4r8wfr/1)
Seeed Studio MR60BHA2 documentation (https://wiki.seeedstudio.com/getting_started_with_mr60bha2_mmwave_kit/)

이 문서는 mmWave 총괄 의사결정 기준이다. 모델·데이터·노드 상태는 검증 증거가 생길 때마다 manifest와 함께 갱신하며, 미검증 수
치는 배포 성능으로 표기하지 않는다.

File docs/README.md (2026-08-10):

# `docs/`

## 1. 디렉터리 목적
개발, 운용, 연구, 기획, 기여 이력을 사람이 읽을 수 있는 문서로 제공한다.

## 2. 시스템에서 담당하는 기능
설치·실행·튜닝·인수인계·구조 결정과 비코드 산출물의 기준 문서를 제공한다.

## 3. 포함해야 하는 파일 유형
Markdown, PDF, DOCX, 문서용 이미지와 검증 가능한 출처 기록을 포함한다.

## 4. 포함하면 안 되는 파일 유형
실행 코드의 유일한 사본, 모델·데이터셋, 비밀값, 렌더링 임시 파일은 포함하지 않는다.

## 5. 주요 하위 구성
기기별 문서는 `mmwave/`처럼 센서 이름으로, 공통 문서는 `operations/`, `architecture/`, `planning/`, `dashboard/`로 구분한다.

## 6. 입력과 출력 인터페이스
입력은 코드·설정·시험 결과이며 출력은 팀원이 재현 가능한 절차와 의사결정 기록이다.

## 7. 다른 기능 영역과의 관계
`devices/`, `ondevice_ai/`, `hardware/`, `shared/` 등 모든 최상위 책임 영역의 사용법을 연결하고 루트 `README.md`의 상세 근거를 제공한다. 각 영역의 상세 규칙은 해당 영역 README에 있다.

## 8. 실행·학습·추론 또는 활용 방법
먼저 루트 README를 읽고 하드웨어 작업은 `operations/`, AI 작업은 `ai/` 문서를 따른다.

## 9. 현재 개발 상태 및 버전
V4 AI 인수인계와 MR60 v1.2.0 운용 문서를 통합했고, 2026-08-03 책임 영역 재편(`38274c0`) 이후 구조를 반영한다. 기기별 인수인계·운용 문서는 `docs/<sensor>/`로 모으며 현재 `docs/mmwave/`가 있다. V4 패키지 내부 문서는 `ondevice_ai/docs/`에 남아 있다.

## 10. 향후 파일 추가 및 관리 규칙
링크는 저장소 루트 기준으로 유지하고 날짜·대상 버전·작성자·원본 ref를 기록한다.

## 11. 주요 기여자와 원본 브랜치·커밋 추적 정보
Jinsu Kim의 `origin/main`/mmWave 계보, Junwoo Han의 `origin/Ondevice_AI` 문서, 팀 공통 운영 문서를 보존한다.

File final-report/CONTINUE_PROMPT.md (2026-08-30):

# 이어서 작업하기 — Claude Code 프롬프트

다른 PC에서 이어서 할 때 아래 `===` 사이를 그대로 Claude Code 에 붙여넣는다.

## 먼저 할 일

```bash
git clone https://github.com/jinsu1011/safenest-embedded-competition.git
cd safenest-embedded-competition
git checkout report/final-report      # 브랜치명은 실제 푸시된 이름으로
cd final-report/generator && npm install
```

macOS + Keynote 가 있어야 PDF 변환이 된다. 없으면 PPTX 편집·생성까지만 가능하다.

---

===============================================================

너는 내 PC에서 Claude Code로 동작한다.
제24회 임베디드SW경진대회(2026) 자유공모 부문 **SafeNest 개발완료보고서**를 이어서 수정한다.

**새로 만들지 마라.** 이미 완성된 21슬라이드 산출물을 수정하는 작업이다.
`DO NOT rebuild from scratch.`

## 0. 작업 폴더

저장소를 clone 한 뒤 `final-report/` 안에서 작업한다.

```
final-report/
├── README.md               ★ 빌드 방법·편집 규칙. 먼저 읽어라
├── HANDOFF.md              ★ 지금까지 한 일과 남은 일. 먼저 읽어라
├── generator/build.js          ★ 슬라이드 편집 원본 (PptxGenJS). 모든 수정은 여기서
├── generator/rebuild.sh        PPTX 생성 → Keynote PDF export → PNG 렌더
├── generator/charts/make_charts.py   차트 생성 (원본 증거 패키지 필요, 보통 쓸 일 없음)
├── assets/                 보고서 삽입 이미지
├── previews/chart_*.png    P1·P11 삽입 차트
├── previews/pdf/p-01~21.png   페이지별 렌더
├── docs/00~08, 11          근거·감사 문서
└── 2026ESWContest_자유공모_가만있어도SANDI_개발완료보고서.pptx / .pdf
```

## 1. 수정 전 필독

1. `HANDOFF.md` — 현재 상태, 남은 일
2. `README.md` — 빌드 방법, Keynote 함정, 편집 규칙
3. `docs/04_SOURCE_CONFLICT_AUDIT.md` — 자료 충돌 18건 해소 결과. **이걸 어기면 사실관계가 틀어진다**
4. `docs/03_CLAIM_EVIDENCE_LEDGER.md` — 강한 주장의 허용/금지 표현
5. `generator/build.js` 전체
6. `previews/pdf/p-01.png ~ p-21.png` 전 페이지 육안 확인

## 2. 작업 방식 — 반드시 이 순서

1. **`generator/build.js`만 편집한다.** PPTX/PDF 를 직접 편집하지 마라. 재빌드 때 덮어써진다.
   슬라이드는 `/* ====== P1 ====== */` ~ `P20` 주석으로 구분되어 있다.
   헬퍼: `page(n,title,sub)` · `box()` · `badge()` · `hdr()` · `sub()` · `note()` · `cap()`
2. 재빌드: `bash final-report/generator/rebuild.sh`
3. **재빌드할 때마다 렌더된 PNG를 Read 도구로 열어 눈으로 확인한다.** 텍스트 넘침·겹침이 자주 난다.
4. 슬라이드 21장 / PDF 21페이지 / PNG 21장인지 확인한다.

**Keynote 함정** (README.md 에도 있음)
- 이전 실행의 Keynote 문서가 남아 있으면 export 가 AppleEvent 타임아웃(-1712)으로 실패한다. `killall Keynote` 후 재시도.
- export 는 됐는데 `close`/`quit` 에서 타임아웃 나면 **PDF 는 이미 정상 생성된 것이다.** PNG 렌더만 따로 돌려라:
  `cd final-report/previews/pdf && rm -f p-*.png && pdftoppm -png -r 70 "../../2026ESWContest_자유공모_가만있어도SANDI_개발완료보고서.pdf" p`

## 3. 절대 규칙 (어기면 대회 규정 위반)

- **날조 금지**: 정확도·지연·오탐률·가용성·시장규모·매출·테스트 결과·사진·팀 기여를 지어내지 마라.
  증거가 없으면 `미검증` / `[추가 검증 필요]`로 쓴다. (대회 규정 제10조④: 제작 사실 허위 시 수상 취소)
- **콘텐츠 20페이지 초과 금지.** 표지 제외 20p까지만 평가된다. 현재 표지1+본문20 = 21슬라이드로 꽉 차 있다.
  **무언가를 추가하려면 반드시 무언가를 빼야 한다.**
- 공식 분량 배분 유지: 개발개요 3p(P1–3) / 환경·프로그램·장애요인 10p(P4–13) / 차별성·파급력 5p(P14–18) / 일정·업무분장 2p(P19–20)
- **초기 개발 목표(KPI)를 달성 결과로 바꾸지 마라.** (정확도 ≥95%, 경보 ≤2초, 오탐 ≤5%/hr, AI ≤100ms, 가용성 ≥99% — 전부 미달성)
- **합성 데이터 결과를 실센서 성능으로 쓰지 마라.** (mmWave v0.2.0 정확도 1.0은 합성 468샘플 한정)
- 금지 표현: `낙상 감지 완료` `낙상 정확도` `체온 측정` `호흡 질환 진단` `세계 최초` `완벽한` `100% 안전` `의료급` `상용화 완료` `실시간 보장`
- **문체 규칙** (이미 전체 적용됨, 유지할 것):
  제목은 전부 명사형 + 번호 체계(`1.1`). em dash(`—`) 사용 금지. `A가 아니라 B` · `핵심은` · `본질적으로` 같은 패턴 금지.
  컬러 콜아웃 박스는 4개(P6·P9·P16·P17)만 유지하고 늘리지 마라.

## 4. 반드시 알아야 할 사실 관계 (조사 완료 — 다시 조사하지 마라)

**정본 소스 스냅샷** = `jinsu1011/safenest-embedded-competition` @ `3f22fb145c…`, 1,904개 파일.

### 실제 구현된 것 (보고서에 써도 되는 것)
- ESP32 Dev Module 4센서 노드 `devices/esp32_node/firmware/esp32_sensor_node.ino` (741줄)
  - mmWave MR60BHA2 **UART2** 115200 (RX16/TX17) · SCD40 **I2C** 0x62 (SDA21/SCL22) · PIR **GPIO13** · Thermal-44 MI48xx **I2C 0x40·0x41 + SPI 1MHz** (SCLK18/MISO19/MOSI23/CS27/READY26/RESET25)
  - **SafeNest TCP protocol v1**: 16B 헤더 `SNST`+version+type+flags+seq+payload_length, network byte order
  - **`formatNullableFloat()`** — 무효값을 0이 아닌 `null`로 전송 + `valid{}` 블록
  - **CRC-16/CCITT-FALSE** (poly 0x1021, init 0xFFFF) `thermalFrameCrc()`
  - **`recoverThermalIfStale()`** — 30초 무프레임 시 GPIO RESET 재초기화
  - `THERMAL_STREAM_FRAMES = false` — 열화상 전 프레임 전송 **비활성**, 최고온도만 1초 telemetry에 실음
  - staleness: mmWave 5s / CO₂ 15s / Thermal 30s, `delay()` 미사용 + FreeRTOS 태스크 + 1-slot 큐
- Pi 수신·표시 `integration/pi_lcd/server.py` — **Python 표준 http.server**, TCP 9000, HTTP 8080, 상태 6종, 부저 BCM GPIO18 880Hz
- 위험도 `RaspberryPi/Runtime/risk/formula_v1.py` — R = 100×(0.25·mmWave+0.30·CO₂+0.15·PIR+0.30·Thermal), 정상<30/주의 30–65/위험≥65
  - 정책 정본 `final-report/docs/09_SAFETY_CRITERIA_V1.md`
  - **전 센서 무효 → `risk_score=None`, `risk_level=None`, `system_health=FAILED`**
  - 유효 센서만 가중치 재정규화. CO₂ ≥1,500 ppm 또는 밀실 기준값 \(B\)+700 주의. ≥5,000 ppm 즉시 위험. occupancy는 점수 제외
  - 열화상 프록시는 비상 없음. mmWave 신경망 관측 전용, 하드웨어 확인 apnea만 즉시 위험
- 웹 `integration/web/` — **Express 5** (bcryptjs·jsonwebtoken·qrcode), QR 공간코드 3종
- 외함 `hardware/3d_models/` — STL 4종. **출력·조립 완료** (체결·발열 확인은 미검증)

### ⚠ 정본에 **없는** 것 (보고서에 쓰면 안 됨)
- **FastAPI · SQLite3 · WebSocket — 코드 401개 파일 전수 검색 결과 0건.**
- `gateway/`, `backend/`, `web/dashboard/`, `web/portal/`, `services/` 디렉터리 — 존재하지 않음
- 강유나 최종 보고서의 `gateway/`·`backend/`·UDP 5005·FastAPI·"153 tests"는 별도 브랜치 `yuname121/integration`에 있고 **정본 미병합**

### 실측 수치 (전부 원시 증거 기반, 그대로 인용 가능)
- 열화상 Pi 5 실기기 E2E: mean 167.92 / **p50 162.70 / p95 173.90** ms, 4.6 FPS, 유효 135/138 (97.8%), 30.06초 138회
- 열화상 fail-closed 6종(순서위반·NaN/Inf·형식오류·물리적 단선·복구·close후read) 실기기 PASS
- mmWave 라이브: 9.990 Hz, 1,201 레코드, UART/checksum/parser 오류 **0/0/0**, 시퀀스 누락 0, 199/199 파싱
- mmWave 리플레이: presence 1.0@0.6·0.9m, 0.814@1.2m, 0.880@1.5m(lock loss, 유효창 0) / 호흡 MAE 0.270rpm@12, 0.275@15, 0.550@20
- CO₂ 실측 4세션(2026-08-12, ESP32 192.168.1.16 → Pi 192.168.1.44:9000): preflight 30/30 · baseline 최초 277/300(결측 7.67% **FAIL, 원본 보존**) · 재측정 300/300(0%) · 호기 6분 329/360(8.61%), **최고 1,493 ppm, 종료 634 ppm**
- ESP32 빌드: RAM 32,356/327,680 = **9.9%**, Flash 268,765/1,310,720 = **20.5%**
- **직접 실행한 테스트: 57 passed / 2 failed** (실패 2건 = 패키지 내 manifest 파일 부재)
  - 저장소 내 `def test_` 총 1,483개(99파일) — **이건 함수 개수다. "1,483 통과"로 쓰면 안 됨**
- **P10 계산 예시** (`formula_v1.py` 실행): CO₂ 1,500 ppm + 평온 인체 → **R = 9.75 정상, 플로어 `co2_warning` → 주의**, 비상 아님

### AI 모델 3종 상태 (`ondevice_ai/models/model_manifest.json`)
| 모델 | 상태 |
|---|---|
| `thermal_fall_int8_v0.1.0` | 실기기 E2E 검증됨. 단 **HUMAN_FALL = 눕기(LYING) 정적 자세 프록시**. 시간축 낙상 검증 아님 |
| `co2_occupancy_int8_v0.1.0` | 공개 데이터 오프라인 한정, 실센서 평가 없음 |
| `mmwave_resp_int8_v0.1.0` | **배포 차단** — `CLASS_COLLAPSE_ON_REPOSITORY_NPZ`, acc 0.3996, macro-F1 0.19, abnormal/apnea recall 0.0 |
| `mmwave_resp_int8_v0.2.0` 후보 | acc 1.0이지만 **합성 468샘플 한정**, `real_sensor_performance: NOT_VERIFIABLE` |

### 임계값 외부 근거 (조사 완료)
- **CO₂ 1,500 ppm** = 실내공기질 관리법 시행규칙 **별표2** 기계환기 시설 유지기준과 동일한 값. **주의 구간**이지 즉시 위험이 아님
- 법정 적정공기 = 산업안전보건기준에 관한 규칙 **제618조** (CO₂ 1.5 % 미만 = 15,000 ppm, 산소 18~23.5 %)
- **위험도 30/60 과 CO₂ 2,000 ppm 은 팀 내부 실험 기준값** — 공인 기준 아님. P10에 명시되어 있다

### 선행 사례 (P15 반영 완료)
- Vayyar Care (상용) — 60 GHz 4D 레이더 낙상 감지, 카메라·마이크 없음, 1대 약 16 m², 낙상 3단계 구분. 환경 가스 감시 없음
- TI IWR6843 (상용 부품) — 60~64 GHz FMCW 단일칩, 재실·생체신호 레퍼런스 공개
- arXiv 2403.05634 (2024) — TI 레이더 3대, 낙상 감지 정확도 96.3 % 보고
- 세 사례 모두 공개 자료에서 **무효·결측 인지와 판단 보류 정책을 확인할 수 없었다** → `확인 불가` 로 표기

### 데이터셋 라이선스
- mmWave: Zenodo vital-sign, DOI `10.5281/zenodo.18599983`, **CC BY 4.0**
- Thermal: SDT Dataset, TU Wien/Zenodo `4124309`, **라이선스 조건 확인 중**
- CO₂: UCI Occupancy Detection ID 357, **CC-BY-4.0**

### 팀 5인 (근거: `.github/CODEOWNERS`)
- 김진수(팀장, @jinsu1011): mmWave 펌웨어·실측, 저장소 구조, 문서
- 유승하(@yuseungha): CO₂/SCD40, ESP32 4센서 노드 펌웨어, Pi LCD·부저, 회로
- 김태균(@rla1729): Thermal-44 드라이버·파서, 열화상 온디바이스 AI 실기기 검증
- 한준우(@sheepmeat): 데이터셋·모델 학습/재현/배포판단, Pi AI, 위험판단 연계
- 강유나(@yuname121): PIR 어댑터, 3D 하우징 CAD·출력, LCD·Web 초기 골격

## 5. 현재 상태

**보고서는 완성 상태다.** 21장 전 페이지 육안 검수 완료. AI 문체 지문 제거 완료
(em dash 0 / 서술형 제목 0 / `라벨 — 설명문` 0 / 콜아웃 박스 4개 / 금지어 0).

**남은 것은 사용자가 채워야 하는 빈칸 2개뿐이다:**
- **P3 소스코드 (GitHub) 밑줄** — 저장소 URL. 공식 명명규칙은 `2026ESWContest_free_가만있어도SANDI` 이므로 rename 여부 결정 필요
- **P3 시연동영상 (YouTube) 밑줄** — 아직 촬영 전. 예선 필수 제출물

두 칸 모두 지금은 **깨끗한 빈 밑줄**이다(빨간 안내문구 없음). URL이 정해지면 `build.js` 의 P3 블록에서 밑줄 위에 `hyperlink` 텍스트만 추가하면 된다.

**문서로는 못 메우는 갭 (임의로 완료 처리하지 마라):**
4센서 동시 수신 실기기 로그 · 통합 HIL · AI 최종 성능 · 실제 낙상 검증 · 하우징 체결/발열 확인 · 최종 시연영상
→ 새 증거를 받기 전까지 현재 표기(`미착수` / `미검증` / `[추가 검증 필요]`)를 그대로 유지한다.
단 문서 전체를 미완성 프로젝트처럼 보이게 하지도 마라. 실제 완료된 것은 자신 있게 구현 결과로 쓴다.

## 6. 이번에 할 일

<<< 여기에 원하는 수정을 적으세요. 예시:
- "시연영상 올렸어: <YouTube URL> — P3에 넣어줘"
- "저장소 이름 2026ESWContest_free_가만있어도SANDI 로 바꿨어 — P3 GitHub 칸 채워줘"
- "4센서 동시 수신 로그 찍었어: <파일 경로> — P11이랑 P16 업데이트해줘"
- "하우징 발열 테스트 했어: <결과> — P18 반영해줘"
- "P15에 선행 연구 1건 더 추가해줘: <논문 DOI>"
>>>

작업 후에는 반드시 `rebuild.sh`를 돌리고, 바뀐 페이지의 `previews/pdf/p-XX.png`를 열어 레이아웃을 눈으로 확인한 뒤 결과를 한국어로 보고해라.

===============================================================

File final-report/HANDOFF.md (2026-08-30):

# SafeNest 개발완료보고서 — 작업 인계 메모

최종 갱신 : 2026-08-30 (CO₂ 밀실 기준값 로컬라이징 가동)

---

## 0. 2026-08-30 변경

현재 Pi 런타임 `SAFENEST_RISK_V1` 을 보고서 정본 안전기준으로 올렸다.

- 정책 문서: `docs/09_SAFETY_CRITERIA_V1.md` (팀장에게 넘겨 P10 에이전트 입력으로 쓰는 브리핑. 법령·논문 URL·복붙 문장·금지 표현 포함)
- 슬라이드 원본: `generator/build.js` P3·P4·P6·P10·P14
- 엔진: `RaspberryPi/Runtime/risk/formula_v1.py` + `risk_formula_v1.json` (1.2.0, 절대 주의 1,500 ppm, 밀실 기준값 \(B\) + 상대 \(\Delta 700\))

구 V4 식(0.35/0.35, CAUTION, R≥60, 1,500 ppm=위험)은 보고서에 쓰지 않는다.

**맥에서 `generator/rebuild.sh` 로 PPTX·PDF를 다시 뽑아야 제출본이 갱신된다.** Pi에서는 Keynote export가 안 된다.

---

## 1. 지금 상태 한 줄 요약

`_최종수정프롬프트_v2.md` 의 배치 A~D 를 **전부 반영 완료**했고, 21장 전 페이지 육안 검수까지 마쳤다.
**남은 것은 P17 캡션 1줄 수정 하나뿐**이다. 그 외에는 제출 가능한 상태다.

---

## 2. 산출물 (파일명에서 `_DRAFT` 를 뗐다)

```
2026ESWContest_자유공모_가만있어도SANDI_개발완료보고서.pptx   ← 최신
2026ESWContest_자유공모_가만있어도SANDI_개발완료보고서.pdf    ← 최신
2026ESWContest_자유공모_가만있어도SANDI_개발완료보고서_DRAFT.*  ← 구버전, 참고용
generator/build.js        편집 원본 (전면 재작성됨)
generator/build.js.bak    수정 전 원본 백업
generator/charts/make_charts.py   차트 3종 생성 스크립트 (신규)
previews/chart_co2.png · chart_mmwave.png · chart_victims.png
previews/pdf/p-01 ~ p-21.png
```

---

## 3. 이번에 한 일

### AI 문체 지문 제거 (v2 §5-3)
| 항목 | 전 | 후 |
|---|---:|---:|
| em dash `—` | 39 | **0** |
| 서술형(`~다`) 제목 | 20 | **0** (전부 `1.1 명사형` 번호 체계) |
| `라벨 — 설명문` 패턴 | 27 | **0** |
| 컬러 콜아웃 박스 | 15 | **4** (P6 규정 고지 / P9 표현 범위 / P16 테스트 수치 / P17 기대효과 범위) |
| 금지 패턴(`A가 아니라 B`, `핵심은` 등) | 다수 | **0** |
| 금지어(FastAPI·SQLite·WebSocket·팀번호·DRAFT 등) | — | **0** |

대단원을 `Ⅰ~Ⅶ` 로미숫자 + 소단원 `1.1 / 1.2 …` 로 바꿔 중간계획서 양식에 맞췄다.

### 레이아웃 (v2 §5-1, §5-2)
- `page()` 헬퍼 수정 : 제목 27→23 pt, 부제가 구분선을 뚫던 버그 해결, 콘텐츠 시작선 정리
- 본문 12 pt 이상 / 표 10.5~12 pt / 캡션 9~9.5 pt 로 상향
- 21장 전부 하단 넘침·겹침 제거

### 신규 콘텐츠
- **P3 시스템 구성도 신규 작도** (보고서 전체에 없던 최대 결손). 센서 4종 → ESP32 → TCP v1 → Pi 5 → 등급 4종 → 부저/LCD/Web. 화살표에 실제 인터페이스와 데이터 이름(`resp_rate_bpm`, `co2_ppm`, `thermal_max_c`, `pir_motion`, `valid{}`) 표기
- **P10 계산 예시 신규**. 정본 `ondevice_ai/risk/fallback.py` 를 **직접 실행해서** 얻은 값만 기재 :
  Thermal STALE → 유효 가중치 0.85 재정규화(0.412/0.412/0.176) → **R = 58.82 → CAUTION**, `system_health = DEGRADED`
- **P11 재구성** : 2단 구성으로 바꿔 `chart_mmwave.png`(미배치였던 것) 배치. ①CO₂ ②mmWave ③Thermal 로 검증 블록 분리
- 차트 3종 재생성 (제목의 em dash 제거, CO₂ 차트에 1,500 ppm 법정 기준선 추가, 도넛 신규)

### 사진 배치 (v2 §8)
| 사진 | 위치 |
|---|---|
| `hw_wiring_diagram.png` | P5 주력 (브레드보드 사진 대체) |
| `ui_lcd_6_failed.jpg` | P14 fail-closed 근거 |
| `hw_product_full_crop.jpg` + LCD 4종 | P16 |
| `ui_web.png` | P17 |
| CAD 2종 + `hw_product_emergency_crop.jpg` | P18 (설계 → 실물 대비 구도) |

하우징을 `설계 완료` → **`출력·조립 완료`** 로 상향. 단 `체결·발열 확인` 은 미검증 유지.
**LCD·웹 화면 캡션은 전부 "표시 계층 검증용 시나리오 입력이며 실센서 측정값이 아니다" 로 명시**했다 (§8-1).

### 조사 과제 (v2 §7)
- **① 선행 사례 → P15 반영 완료.** Vayyar Care(상용) / TI IWR6843(상용 부품) / arXiv 2403.05634(낙상 96.3 %). 공개 자료로 확인 못 한 항목은 `확인 불가` 로 두었고 출처를 각주에 남겼다
- **② 임계값 외부 근거 확보 → P10 반영 완료.**
  - CO₂ 1,500 ppm = **실내공기질 관리법 시행규칙 별표2** 기계환기 시설 유지기준과 동일한 값
  - 법정 적정공기(**산업안전보건기준에 관한 규칙 제618조**)는 CO₂ 1.5 %(15,000 ppm) 미만 → SafeNest 값이 훨씬 보수적인 조기경보 지점임을 명시
  - 위험도 30/60 과 CO₂ 2,000 ppm 은 `내부 실험 기준값` 이라고 P10 본문에 빨간 글씨로 못박음
- **③ BOM 원가 → 보류.** 8개 부품 전부의 출처 있는 단가를 확보하지 못했고 P17 공간도 부족. 근거 없는 원가표는 넣지 않았다 (v2 §7-③ 이 허용한 스킵)

### 정직성 유지 (건드리지 않은 것)
`4센서 통합 HIL = 미착수/미검증`, P15 마지막 행 `통합 실기기 검증 완료 = SafeNest만 ×`,
`mmWave v0.1.0 배포 차단`, `v0.2.0 = 합성 468샘플 한정`, `HUMAN_FALL = 눕기(LYING) 프록시`,
`테스트 57 passed / 2 failed (1,483개는 함수 개수)` — 전부 그대로 유지.

---

## 4. 내일 이어서 할 일
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

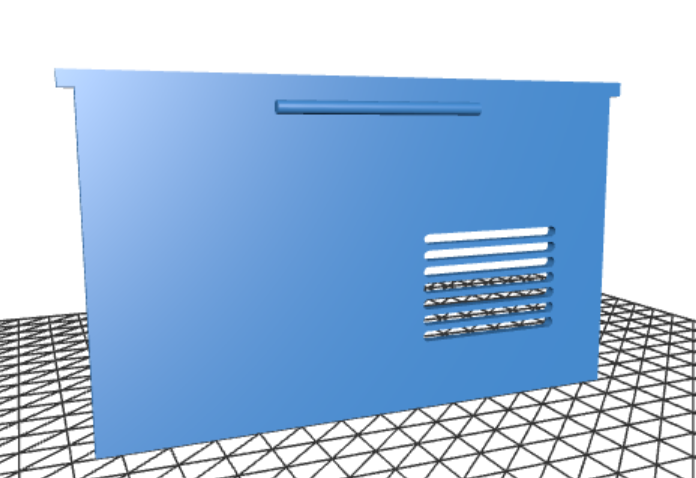
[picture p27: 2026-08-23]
final-report/assets/3d_sensor_housing_sliding_back.png

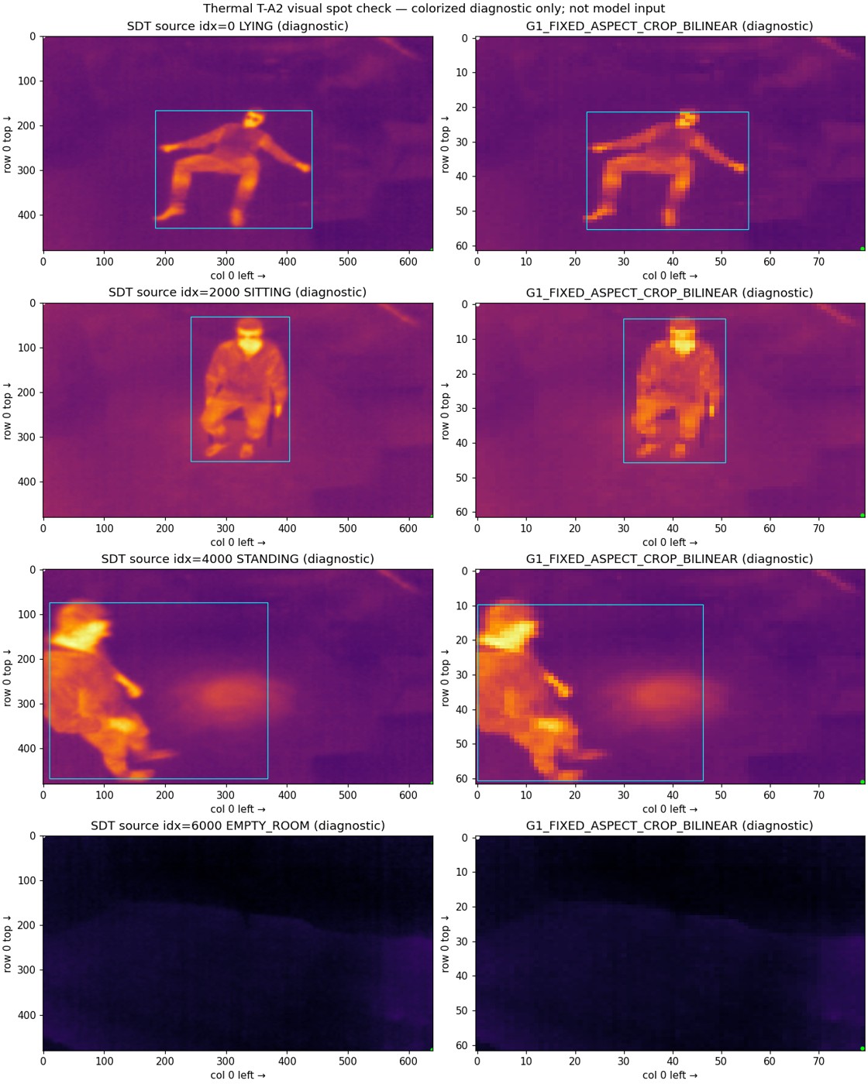
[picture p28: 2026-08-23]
final-report/assets/thermal_spotcheck.jpg

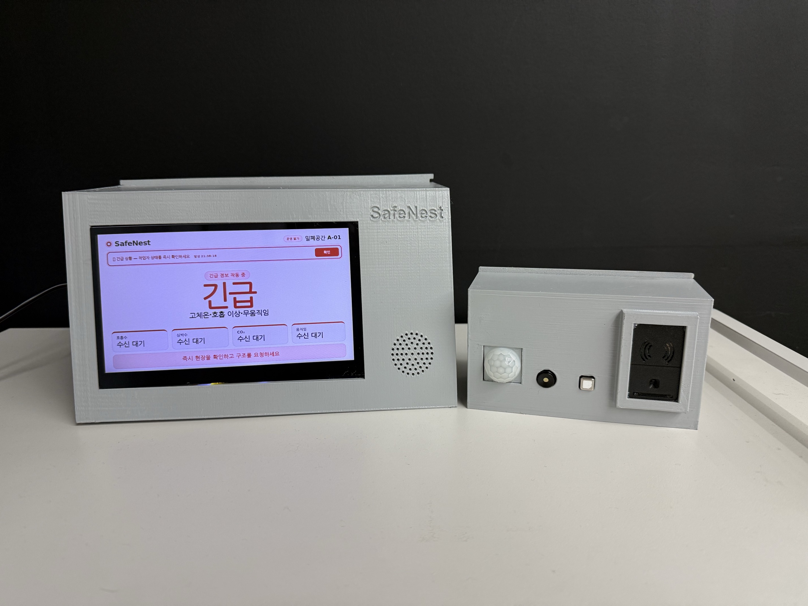
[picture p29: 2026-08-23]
final-report/assets/hw_product_full_emergency.jpg

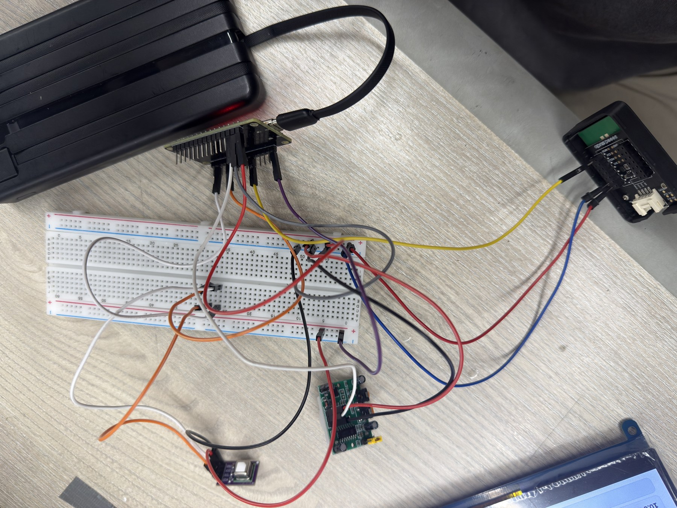
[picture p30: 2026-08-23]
final-report/assets/hw_bench.jpg

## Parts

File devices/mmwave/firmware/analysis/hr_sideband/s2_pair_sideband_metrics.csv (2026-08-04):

index | elapsed_from_entry_s | watch_bpm | vendor_mr60_bpm | vendor_error_bpm | mr60_samples | valid | exclusion_reason | stable_presence_rate | respiration_rpm | breath_phase_std | breath_spectral_peak_ratio | vendor_error_nearest_order | vendor_error_order_residual_bpm | vendor_error_sideband_match | dominant_total_peak_bpm | dominant_spectrum_nearest_order | dominant_spectrum_order_residual_bpm | dominant_spectrum_sideband_match | vendor_to_watch_amplitude_ratio | max_predicted_sideband_to_base_ratio
1 | 0.0 | 135.0 | 68.0 | -67.0 | 49 | False | CAUSAL_WINDOW_STABLE_PRESENCE_BELOW_95_PERCENT | 0.7213114754098361 | 20.698541549934287 | 0.43674853595605734 | 2.325585614698534 | -2 | 25.602916900131426 | False | 103.64117620067586 | -2 | 10.038259300544432 | False | 0.4661009148381991 | 0.6845914469594792
2 | 35.638 | 100.0 | 113.0 | 13.0 | 49 | True |  | 1.0 | 24.82246959237784 | 0.49678886153899415 | 3.923900546131831 | 1 | 11.82246959237784 | False | 100.96907038905266 | 0 | 0.9690703890526606 | False | 0.5451159651101808 | 0.8341938243531272
3 | 65.685 | 92.0 | 82.0 | -10.0 | 49 | True |  | 1.0 | 16.714744402731682 | 0.41577628691231533 | 2.6380362443379926 | -1 | 6.714744402731682 | False | 53.109292851865845 | -2 | 5.46121834267079 | False | 1.2206899228126356 | 1.331755868090329
4 | 95.604 | 92.0 | 61.0 | -31.0 | 49 | True |  | 1.0 | 19.826189145633634 | 0.41047887969736574 | 2.6702661709320217 | -2 | 8.652378291267269 | False | 78.13549020471561 | -1 | 5.961679350349243 | False | 0.9442670569125299 | 1.3211273005002908
5 | 125.64 | 94.0 | 102.0 | 8.0 | 49 | True |  | 1.0 | 24.924873626255557 | 0.4632003934705839 | 7.337318475953275 | 0 | 8.0 | False | 101.85325404122351 | 0 | 7.853254041223508 | False | 1.2828868709824512 | 0.4989825789731233
6 | 155.668 | 86.0 | 73.0 | -13.0 | 49 | True |  | 1.0 | 6.5197965537501625 | 0.3220519855103313 | 1.7422153495248753 | -2 | 0.039593107500325075 | True | 68.58493682725968 | -2 | 4.375470065239993 | False | 2.346585838035434 | 2.346585838035434
7 | 185.598 | 91.0 | 90.0 | -1.0 | 44 | True |  | 1.0 | 10.856720387600937 | 0.21484886936570233 | 2.3309222870534163 | 0 | 1.0 | False | 59.2704788396801 | -2 | 10.016080385118023 | False | 1.012535362370991 | 1.8550491196472636

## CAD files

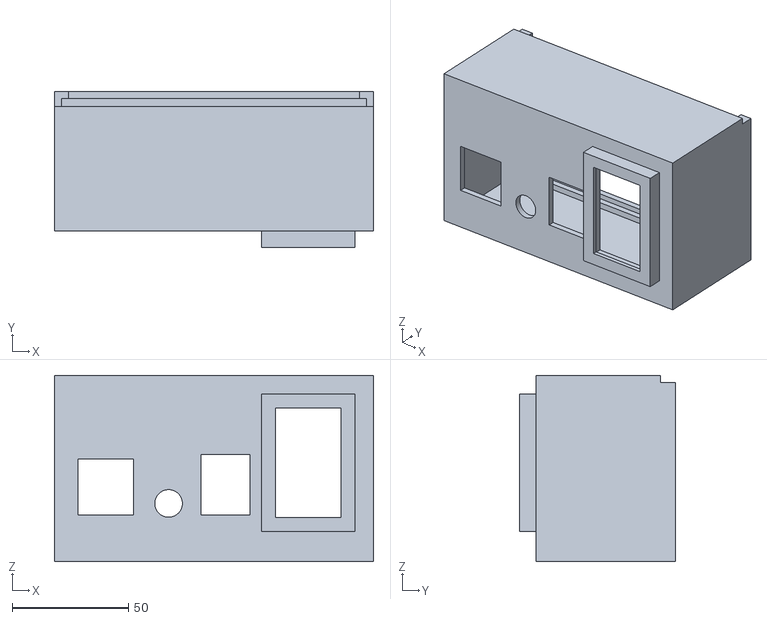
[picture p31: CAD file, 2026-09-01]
hardware/3d_models/housing_body.stl
137.0 x 67.0 x 80.0

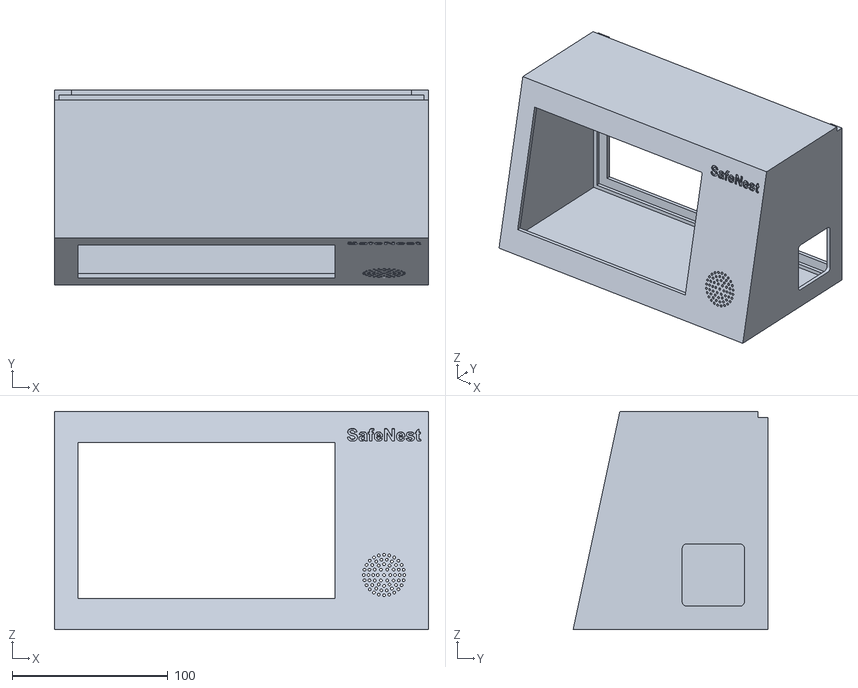
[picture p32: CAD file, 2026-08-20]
hardware/3d_models/trapezoid_housing_body.stl
240.0 x 125.0 x 140.0

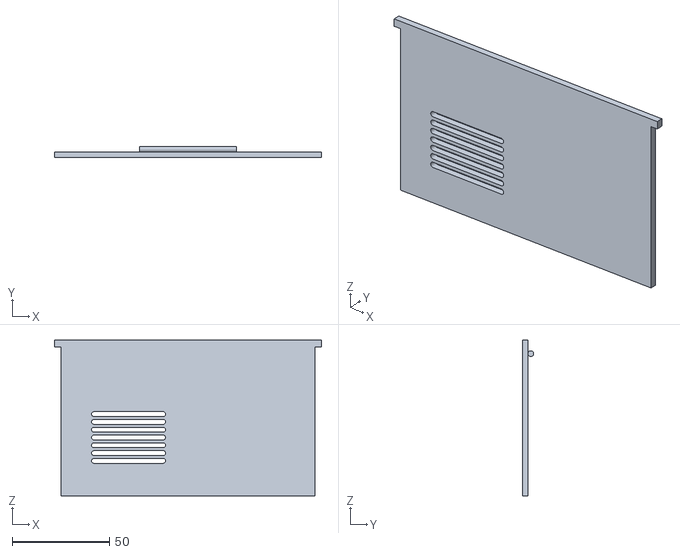
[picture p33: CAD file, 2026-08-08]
hardware/3d_models/sliding_back_panel.stl
137.0 x 5.90 x 80.0

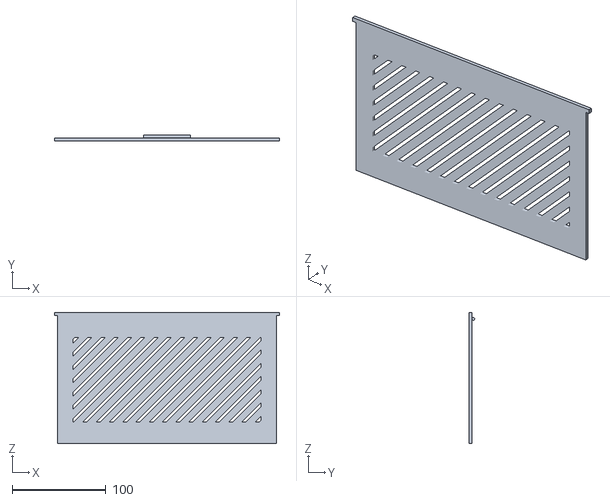
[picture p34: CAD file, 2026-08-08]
hardware/3d_models/trapezoid_T_back_panel.stl
240.0 x 5.90 x 140.0

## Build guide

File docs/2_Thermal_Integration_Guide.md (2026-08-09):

# 열화상 센서 통합 TCP 매뉴얼 (ESP32 & Raspberry Pi)

본 문서는 다른 센서(mmWave, CO2, PIR)와 열화상 카메라가 완전히 통합되어 1개의 단일 프로토콜로 작동하는 **TCP 기반 SafeNest 스트리밍 가이드**입니다.

이 가이드에 해당하는 코드들은 `devices/thermal/thermal_integration` 디렉토리에 위치해 있습니다.

---

## 1. 디렉토리 구성 (thermal_integration)
- `esp32_sensor_node.ino`: 팀에서 최종적으로 하나로 병합한 센서 통합 ESP32 아두이노 코드입니다. 열화상 카메라 제어부 및 TCP 패킷(SNST 헤더) 조립 로직이 포함되어 있습니다.
- `tcp_thermal_receiver_rpi.py`: 라즈베리파이에서 포트 9000번 TCP 서버를 열고 대기하며, `SNST` 규격의 헤더를 파싱하여 열화상(Type 2) 패킷이 들어올 때만 화면에 시각화하는 전용 파이썬 수신부입니다.

---

## 2. 통합 프로토콜 규격 (SNST Protocol v1)

모든 데이터는 TCP 포트 9000을 통해 전송되며, 패킷 앞단에 16바이트의 고정 헤더(Big-Endian)가 붙습니다.
- `[0:4]` Magic Word: "SNST"
- `[4]` Version: 1
- `[5]` Type: 1 (환경 센서 JSON 텔레메트리), 2 (열화상 데이터)
- `[6:8]` Flags: 예약됨
- `[8:12]` Sequence: 패킷 순서 번호
- `[12:16]` Payload Length: 뒤따라오는 데이터 길이

**열화상 (Type 2) 상세 구조:**
- 16 바이트 메타데이터: 가로 폭(80), 세로 높이(62), 업타임, 최소/최대 온도
- 9,920 바이트 픽셀 데이터: 4,960개의 해상도 픽셀 (uint16)

---

## 3. 실행 가이드

이전 UDP 방식과는 달리, **수신부(TCP Server)를 먼저 켜두어야 송신부(TCP Client)가 접속**할 수 있습니다.

1. **수신부 (라즈베리파이) 대기**
   - 라즈베리파이 터미널에서 다음 명령을 통해 TCP 9000번 포트를 엽니다.
     ```bash
     export DISPLAY=:0
     python tcp_thermal_receiver_rpi.py
     ```
   - 콘솔에 `[Main] TCP Server listening on port 9000...` 메시지가 뜨면 접속 대기 상태가 됩니다.

2. **송신부 (ESP32) 접속**
   - `esp32_sensor_node.ino` 코드 내의 RPI_HOST 변수를 수신부 라즈베리파이의 IP 주소로 수정한 뒤 업로드합니다.
   - 전원이 켜지면 ESP32가 Wi-Fi에 접속한 후 자동으로 포트 9000번에 TCP 연결을 시도하며 데이터를 스트리밍합니다.
   - 라즈베리파이 화면에 열화상 영상이 팝업되는 것을 확인할 수 있습니다.

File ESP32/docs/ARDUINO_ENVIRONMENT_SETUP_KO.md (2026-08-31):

# SafeNest ESP32 Arduino 개발 환경 구축 가이드

이 문서는 다른 PC에서도 SafeNest ESP32 통합 센서 펌웨어를 빌드하고 ESP32에 업로드할 수 있도록 필요한 프로그램, 보드 패키지, Arduino 라이브러리, 설정 파일과 실행 절차를 정리한 문서입니다.

대상 스케치:

```text
ESP32/Arduino/esp32_sensor_node/esp32_sensor_node.ino
ESP32/Arduino/esp32_sensor_node_260828_v2/esp32_sensor_node_260828_v2.ino
ESP32/Arduino/esp32_sensor_node_mhz19b_v2/esp32_sensor_node_mhz19b_v2.ino
```

> 이 프로젝트의 기준 보드는 일반적인 ESP32-WROOM 계열의 `ESP32 Dev Module`입니다. XIAO ESP32C6용 보드 설정이 아닙니다. 소스의 핀 번호도 `ESP32 Dev Module` 기준이므로 다른 보드로 바꾸면 배선과 핀 정의를 함께 수정해야 합니다.

`esp32_sensor_node_mhz19b_v2`는 v2 노드의 CO₂ 경로만 MH-Z19B UART로 바꾼 형제 스케치입니다. Sensirion SCD4x 라이브러리가 필요 없고, MR60은 계속 UART2(GPIO 16/17), MH-Z19B는 UART1(GPIO 32/33)을 씁니다. 모듈 전원은 4.5–5.5 V이며 ESP32 3.3 V 레일로 켜지 않습니다. 자세한 배선은 `ESP32/Arduino/esp32_sensor_node_mhz19b_v2/ESP32_UPDATE_CHANGELOG_KO.md`를 봅니다.

## 1. 준비물

- ESP32 Dev Module(ESP32-WROOM 계열)
- 데이터 통신이 가능한 USB 케이블
- MR60BHA2 60 GHz mmWave 센서
- Sensirion SCD40/SCD4x CO₂ 센서
- PIR 센서
- Waveshare Thermal Camera HAT / MI48xx(80 × 62) 열화상 센서
- Raspberry Pi와 ESP32가 함께 접속할 수 있는 **2.4 GHz Wi-Fi**
- Windows, macOS 또는 Linux PC

ESP32는 저속 센서 데이터를 Raspberry Pi의 TCP `9000` 포트로, 열화상 데이터를 UDP `5005` 포트로 전송합니다. 펌웨어만 단독으로 업로드할 수는 있지만 전체 시스템 동작을 확인하려면 Raspberry Pi 수신 프로그램이 먼저 실행 중이어야 합니다.

## 2. 설치해야 하는 프로그램과 패키지

### 2.1 Arduino IDE

[Arduino IDE 공식 다운로드](https://www.arduino.cc/en/software/)에서 Arduino IDE 2.x의 최신 안정 버전을 설치합니다.

CLI 기반 설치를 원하는 경우에는 [Arduino CLI](https://arduino.github.io/arduino-cli/latest/installation/)를 대신 사용할 수 있습니다. GUI 절차는 3절, CLI 절차는 8절을 따릅니다.

### 2.2 ESP32 보드 패키지

Arduino IDE에서 다음 보드 매니저 URL을 등록합니다.

```text
https://espressif.github.io/arduino-esp32/package_esp32_index.json
```

설치 대상:

| 구분 | 설치/선택 항목 | 비고 |
|---|---|---|
| 보드 패키지 | `esp32` by Espressif Systems | 안정 버전 사용 |
| 보드 | `ESP32 Dev Module` | Arduino FQBN: `esp32:esp32:esp32` |
| 시리얼 속도 | `115200` baud | 업로드 후 Serial Monitor 설정 |

설치 순서:

1. Arduino IDE에서 `File > Preferences`를 엽니다.
2. `Additional boards manager URLs`에 위 URL을 추가합니다.
3. `Tools > Board > Boards Manager`를 엽니다.
4. `esp32`를 검색하고 **Espressif Systems**가 제공하는 패키지를 설치합니다.
5. `Tools > Board > esp32 > ESP32 Dev Module`을 선택합니다.

이 스케치에서 사용하는 `Arduino.h`, `WiFi.h`, `WiFiUdp.h`, `Wire.h`, `SPI.h`, FreeRTOS API는 ESP32 보드 패키지에 포함되므로 별도 라이브러리로 설치하지 않습니다.

### 2.3 외부 Arduino 라이브러리

다음 두 라이브러리가 스케치의 직접 의존성입니다.

| Library Manager 검색 이름 | 제공자 | 필요한 헤더 | 권장 버전/주의 사항 |
|---|---|---|---|
| `Sensirion I2C SCD4x` | Sensirion | `SensirionI2cScd4x.h` | `1.0.0` 이상. 현재 소스는 새 `SensirionI2cScd4x` API를 사용함 |
| `Seeed Arduino mmWave` | Seeed Studio | `Seeed_Arduino_mmWave.h` | 검증 기준 안정 계열 `1.0.0`; MR60BHA2 지원 필요 |

함께 설치되는 의존성:

| 상위 라이브러리 | 하위 의존성 | 처리 방법 |
|---|---|---|
| Sensirion I2C SCD4x | `Sensirion Core` | 설치 창에서 `Install all` 선택 |
| Seeed Arduino mmWave | `Adafruit NeoPixel`, `hp_BH1750` | 설치 창에서 `Install all` 선택 |

Arduino IDE에서 설치하는 방법:

1. 왼쪽의 `Library Manager` 아이콘을 누르거나 `Sketch > Include Library > Manage Libraries...`를 엽니다.
2. `Sensirion I2C SCD4x`를 검색해 Sensirion 제공 라이브러리를 설치합니다.
3. 의존성 설치 여부를 물으면 `Install all`을 선택합니다.
4. `Seeed Arduino mmWave`를 검색해 Seeed Studio 제공 라이브러리를 설치합니다.
5. 역시 `Install all`을 선택합니다.
6. 설치가 끝나면 Arduino IDE를 한 번 재시작합니다.

Seeed 라이브러리가 Library Manager에서 검색되지 않으면 [Seeed mmWave 공식 저장소](https://github.com/Seeed-Projects/Seeed-mmWave-library)의 안정 릴리스 ZIP을 내려받아 `Sketch > Include Library > Add .ZIP Library...`로 설치합니다. ZIP으로 수동 설치할 때는 위 표의 하위 의존성도 Library Manager에서 따로 설치합니다. 프리릴리스나 개발 브랜치는 API 호환성을 다시 확인하기 전까지 사용하지 않는 것이 안전합니다.

Sensirion 라이브러리의 공식 설치 및 의존성 정보는 [Sensirion I2C SCD4x 저장소](https://github.com/Sensirion/arduino-i2c-scd4x)를 참고합니다.

## 3. 프로젝트 받기

Git을 사용하는 방법:

```bash
git clone https://github.com/jinsu1011/safenest-embedded-competition.git
cd safenest-embedded-competition
```

Git을 사용하지 않으면 GitHub의 `Code > Download ZIP`으로 받은 뒤 압축을 풉니다. `.ino` 파일 하나만 전달하지 말고 최소한 다음 구조를 유지해야 합니다.

```text
safenest-embedded-competition/
└── ESP32/
    ├── secret.h.example
    └── Arduino/
        └── esp32_sensor_node/
            ├── esp32_sensor_node.ino
            └── secrets.h            # 사용자가 생성, Git에 올리지 않음
```

Arduino 스케치 폴더 이름과 `.ino` 파일의 기본 이름은 모두 `esp32_sensor_node`로 같아야 합니다.

## 4. 개인 설정 파일 만들기

Wi-Fi 비밀번호 같은 개인정보는 소스에 직접 적지 않고 스케치 폴더의 `secrets.h`에 둡니다. 이 파일은 `.gitignore`에 등록되어 Git에 커밋되지 않습니다.

Windows PowerShell:

```powershell
Copy-Item .\ESP32\secret.h.example .\ESP32\Arduino\esp32_sensor_node\secrets.h
```

macOS/Linux:

```bash
cp ESP32/secret.h.example ESP32/Arduino/esp32_sensor_node/secrets.h
```

생성한 `secrets.h`를 다음과 같이 수정합니다.

```cpp
#pragma once

constexpr char WIFI_SSID[] = "2.4_GHz_Wi-Fi_이름";
constexpr char WIFI_PASSWORD[] = "Wi-Fi_비밀번호";
constexpr char RPI_HOST[] = "192.168.1.44";  // Raspberry Pi의 실제 IPv4 주소
constexpr uint16_t RPI_PORT = 9000;
```

주의 사항:

- ESP32는 이 구성에서 2.4 GHz Wi-Fi를 사용합니다.
- `RPI_HOST`에는 `localhost`가 아니라 ESP32에서 접근할 수 있는 Raspberry Pi의 LAN IPv4 주소를 넣습니다.
- `RPI_PORT`는 Raspberry Pi 수신 서버의 TCP 포트 `9000`과 같아야 합니다.
- 열화상 UDP 포트 `5005`는 현재 `.ino`의 `THERMAL_UDP_PORT`에 정의되어 있습니다.
- 실제 `secrets.h`를 메신저, 문서 또는 Git으로 공유하지 마십시오. 다른 사용자는 예제 파일에서 자신의 값을 만들어야 합니다.

## 5. 배선 확인

현재 스케치에 고정된 ESP32 핀은 다음과 같습니다.

| 장치/신호 | ESP32 핀 | 연결 방향 또는 설명 |
|---|---:|---|
| 공통 I²C SDA | GPIO 21 | SCD4x 및 Thermal 제어 버스 |
| 공통 I²C SCL | GPIO 22 | SCD4x 및 Thermal 제어 버스 |
| PIR OUT | GPIO 13 | ESP32 디지털 입력 |
| MR60BHA2 TX | GPIO 16 | 센서 TX → ESP32 RX |
| MR60BHA2 RX | GPIO 17 | 센서 RX ← ESP32 TX |
| Thermal SCLK | GPIO 18 | SPI clock |
| Thermal MISO | GPIO 19 | 센서 → ESP32 |
| Thermal MOSI | GPIO 23 | ESP32 → 센서 |
| Thermal CS | GPIO 27 | SPI chip select |
| Thermal READY | GPIO 26 | ESP32 입력 |
| Thermal RESET | GPIO 25 | ESP32 출력 |

모든 모듈과 ESP32의 GND를 공통으로 연결합니다. 센서 전원 전압과 핀 허용 전압은 반드시 각 센서의 데이터시트 및 사용 중인 모듈 보드 사양을 확인하십시오. 상세 통신 규약은 [COMMUNICATION_PROTOCOL.md](./COMMUNICATION_PROTOCOL.md)를 참고합니다.

## 6. 컴파일 및 업로드

1. Arduino IDE에서 `ESP32/Arduino/esp32_sensor_node/esp32_sensor_node.ino`를 엽니다.
2. `Tools > Board`에서 `ESP32 Dev Module`을 선택합니다.
3. `Tools > Port`에서 ESP32가 연결된 포트를 선택합니다.
4. 먼저 `Sketch > Verify/Compile`로 컴파일합니다.
5. 오류가 없으면 `Upload`를 눌러 플래시합니다.
6. 업로드 후 `Tools > Serial Monitor`를 열고 `115200 baud`를 선택합니다.

ESP32가 포트 목록에 나타나지 않으면 다음을 확인합니다.

- 충전 전용이 아닌 데이터 USB 케이블인지 확인
- 다른 USB 포트 사용
- 보드에 장착된 USB-UART 칩에 따라 CP210x 또는 CH340 드라이버 설치
- Windows 장치 관리자 또는 macOS/Linux의 직렬 장치 목록에서 포트 확인
- 업로드 연결 중 필요하면 보드의 `BOOT` 버튼을 누른 상태에서 업로드 시작

## 7. 정상 동작 확인

업로드 직후 Serial Monitor에서 다음 흐름을 확인합니다.

```text
SafeNest ESP32 sensor node starting
[identity] device=esp32-01 ...
[wifi] connecting to ... asynchronously
```

이후 10초마다 출력되는 `[health]` 로그에서 다음 항목을 확인합니다.

| 항목 | 정상 예시 | 의미 |
|---|---|---|
| `wifi` | `up` | Wi-Fi 연결 성공 |
| `rpi` | 설정한 Raspberry Pi IP | 전송 목적지 |
| `co2` | 0이 아닌 측정값 | SCD4x 측정 수신 |
| `resp`, `heart` | 사람이 감지될 때 값 출력 | MR60BHA2 데이터 수신 |
| `thermal_frames` | 계속 증가 | 열화상 프레임 캡처 진행 |
| `udp_sent` | 계속 증가 | Raspberry Pi로 UDP 전송 진행 |
| `udp_failed` | 지속 증가하지 않음 | UDP 전송 오류 여부 |

Raspberry Pi 쪽에서도 TCP `9000`과 UDP `5005`가 수신 대기 중이어야 합니다. PC 또는 Raspberry Pi 방화벽이 이 통신을 막지 않는지 확인합니다.

## 8. 선택 사항: Arduino CLI로 동일 환경 만들기

다음 명령은 Arduino CLI가 설치되어 있고 터미널에서 `arduino-cli`를 실행할 수 있다는 전제입니다.

```bash
arduino-cli config init
arduino-cli config add board_manager.additional_urls https://espressif.github.io/arduino-esp32/package_esp32_index.json
arduino-cli core update-index
arduino-cli core install esp32:esp32
arduino-cli lib install "Sensirion I2C SCD4x"
arduino-cli lib install "Seeed Arduino mmWave"
```

컴파일:

```bash
arduino-cli compile --fqbn esp32:esp32:esp32 ESP32/Arduino/esp32_sensor_node
arduino-cli compile --fqbn esp32:esp32:esp32 ESP32/Arduino/esp32_sensor_node_mhz19b_v2
```

업로드 예시:

```bash
arduino-cli upload --fqbn esp32:esp32:esp32 --port COM5 ESP32/Arduino/esp32_sensor_node
```

macOS/Linux에서는 `COM5` 대신 실제 포트(예: `/dev/cu.usbserial-...`, `/dev/ttyUSB0`)를 넣습니다. 포트는 다음 명령으로 확인할 수 있습니다.

```bash
arduino-cli board list
```

## 9. 재현성을 위한 버전 기록

모든 팀원이 완전히 같은 결과를 얻어야 한다면 “최신 버전”만 사용하지 말고, 최초로 정상 컴파일·실기 동작을 확인한 뒤 아래 버전을 기록해 공유합니다.

```bash
arduino-cli version
arduino-cli core list
arduino-cli lib list
```

권장 기록표:

| 구성 요소 | 프로젝트 요구 조건 | 팀 검증 버전 기입란 |
|---|---|---|
| Arduino IDE 또는 CLI | IDE 2.x 또는 호환 CLI | `____________` |
| ESP32 by Espressif Systems | 안정 버전, `ESP32 Dev Module` 지원 | `____________` |
| Sensirion I2C SCD4x | `1.0.0` 이상 | `____________` |
| Sensirion Core | SCD4x가 요구하는 버전 | `____________` |
| Seeed Arduino mmWave | 안정 계열 `1.0.0` | `____________` |
| Adafruit NeoPixel | Seeed 라이브러리가 요구하는 버전 | `____________` |
| hp_BH1750 | Seeed 라이브러리가 요구하는 버전 | `____________` |

버전을 고정한 CLI 설치 예시는 다음 형식입니다.

```bash
arduino-cli core install esp32:esp32@<검증한_버전>
arduino-cli lib install "Sensirion I2C SCD4x@<검증한_버전>"
arduino-cli lib install "Seeed Arduino mmWave@1.0.0"
```

## 10. 자주 발생하는 오류

| 오류/증상 | 원인 | 해결 방법 |
|---|---|---|
| `SensirionI2cScd4x.h: No such file or directory` | SCD4x 라이브러리가 없거나 구형 라이브러리 설치 | `Sensirion I2C SCD4x` 1.0.0 이상과 `Sensirion Core` 설치 |
| `Seeed_Arduino_mmWave.h: No such file or directory` | 다른 24 GHz radar 라이브러리를 설치했거나 라이브러리 누락 | 정확히 `Seeed Arduino mmWave` 설치 |
| `secrets.h: No such file or directory` | 개인 설정 파일 미생성 | 4절의 명령으로 예제 파일을 복사 |
| `SCD41_I2C_ADDR_62` 또는 `getDataReadyStatus` 관련 오류 | Sensirion 구형 API 사용 | 구형 SCD4x 라이브러리를 제거하고 1.0.0 이상 설치 |
| 여러 라이브러리가 발견되었다는 메시지 | 이름이 비슷한 구형/복제 라이브러리가 함께 설치됨 | Arduino libraries 폴더에서 중복을 제거하고 정확한 제공자 버전만 유지 |
| 포트가 보이지 않음 | USB 케이블 또는 USB-UART 드라이버 문제 | 데이터 케이블, CP210x/CH340 드라이버, 다른 USB 포트 확인 |
| 업로드 중 연결 실패 | 자동 부트 진입 실패 또는 포트 점유 | Serial Monitor를 닫고 재시도, 필요하면 `BOOT` 버튼 사용 |
| Wi-Fi 연결 실패 | 5 GHz 전용 SSID, 잘못된 비밀번호 | 2.4 GHz SSID와 `secrets.h` 재확인 |
| `wifi=up`인데 Pi에 데이터가 없음 | Pi IP/포트/방화벽 또는 수신 서버 문제 | `RPI_HOST`, TCP 9000, UDP 5005, Pi 실행 상태와 방화벽 확인 |
| 센서 값만 비어 있음 | 배선, 전원, RX/TX 방향 또는 센서 펌웨어 문제 | 5절 배선과 공통 GND 확인; MR60BHA2는 필요 시 공식 안내에 따라 펌웨어 확인 |

## 11. 다른 사람에게 전달할 때 체크리스트

- [ ] 저장소 전체 또는 최소 ESP32 폴더 구조를 전달했다.
- [ ] 실제 `secrets.h`가 아니라 `secret.h.example`만 전달했다.
- [ ] 사용 보드가 `ESP32 Dev Module`임을 알렸다.
- [ ] ESP32 보드 패키지와 두 직접 라이브러리의 설치를 안내했다.
- [ ] 라이브러리 설치 시 `Install all`로 하위 의존성을 설치했다.
- [ ] 검증에 사용한 IDE, ESP32 core, 라이브러리 버전을 기록했다.
- [ ] 2.4 GHz Wi-Fi 및 Raspberry Pi IP를 각 사용자 환경에 맞게 설정했다.
- [ ] TCP 9000, UDP 5005 포트와 방화벽을 확인했다.
- [ ] 업로드 후 Serial Monitor를 `115200 baud`로 확인했다.

## 공식 참고 자료

- [Espressif Arduino-ESP32 설치 문서](https://docs.espressif.com/projects/arduino-esp32/en/latest/installing.html)
- [Sensirion I2C SCD4x Arduino 라이브러리](https://github.com/Sensirion/arduino-i2c-scd4x)
- [Seeed Arduino mmWave 라이브러리](https://github.com/Seeed-Projects/Seeed-mmWave-library)
- [Seeed MR60BHA2 시작 가이드](https://wiki.seeedstudio.com/getting_started_with_mr60bha2_mmwave_kit/)
- [SafeNest ESP32 통신 규약](./COMMUNICATION_PROTOCOL.md)

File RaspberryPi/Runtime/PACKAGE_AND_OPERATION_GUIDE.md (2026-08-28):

# SafeNest 전달 패키지 및 프로그램 실행·종료 가이드

## Thermal UDP 운영 추가사항 (2026-08-14)

```text
mmWave + CO2 + PIR -- SafeNest TCP v1 :9000 --> Raspberry Pi
Thermal-44 --------- chunked UDP :5005 ------> Raspberry Pi
```

Raspberry Pi firewall를 사용하는 경우 TCP 9000과 함께 UDP 5005를 허용해야 한다. `backend/run_backend.py`는 기본적으로 `0.0.0.0:5005/udp`를 열며 `.env`의 `SAFENEST_THERMAL_UDP_*` 값으로 port, incomplete-frame timeout과 pending-frame 상한을 조정할 수 있다. ESP32 firmware의 `THERMAL_UDP_PORT`와 Pi port는 반드시 같아야 한다.

UDP frame은 9개 datagram으로 나뉘며 일부 chunk가 없거나 CRC32/shape/min-max 검증에 실패하면 frame 전체를 폐기한다. `/health`의 `receiver.thermal_udp`에서 packet, 완료 frame, incomplete/timeout, duplicate, out-of-order, effective FPS와 평균 reassembly 시간을 확인한다.

## 1. 압축 폴더만 보내면 실행할 수 있는가?

이 저장소 루트에는 SafeNest 통합을 위해 작성·선정한 소스 코드, TFLite 모델, ESP32 firmware 원본, Raspberry Pi 실행 스크립트, 웹 대시보드, SQLite schema, 자동 테스트와 문서가 모두 포함되어 있다.

다만 ZIP만 풀면 의존성·Wi-Fi 비밀번호·하드웨어 설정까지 자동으로 생기는 것은 아니다. 받는 사람은 이 문서의 최초 설치를 수행해야 하며 Raspberry Pi가 인터넷에 연결되어 있어야 Python 의존성을 설치할 수 있다.

### 포함된 항목

- SafeNest TCP v1 Pi receiver와 strict parser
- Sensor State Manager와 freshness 처리
- `RaspberryPi/Ondevice_AI/` 전체 snapshot, primary 모델과 mmWave candidate/experiment evidence, inference adapter
- Risk Engine과 rule fallback
- FastAPI, WebSocket, SQLite repository
- 실시간 웹 대시보드
- loopback E2E 및 HIL 증거 수집 도구
- ESP-WROOM-32용 통합 ESP32 firmware와 `ESP32/secret.h.example`
- PHASE 1~10 및 HIL 상세 문서
- Pi 설치·점검·실행 스크립트

### 보안상 포함하지 않은 항목

- 실제 Wi-Fi 비밀번호가 든 `secrets.h`
- 개인 SSH key와 Raspberry Pi 계정 비밀번호
- 기존에 생성된 SQLite 운영 데이터
- `.venv`, Python package cache와 임시 파일

### 외부 설치가 필요한 항목

- Raspberry Pi OS 64-bit, Python 3.10 이상
- 인터넷을 통한 FastAPI, uvicorn, numpy, LiteRT 등의 Python package
- Arduino IDE와 ESP32 board core
- Arduino library `Sensirion I2C SCD4x`
- Arduino library `Seeed Arduino mmWave`
- 실제 센서, 배선, 전원, Raspberry Pi와 ESP32

## 2. 현재 지원 보드에 관한 중요 제한

현재 통합 firmware의 핀은 ESP-WROOM-32/Arduino `ESP32 Dev Module` 기준이다.

```text
I²C SDA/SCL: GPIO 21/22
PIR: GPIO 13
MR60 UART RX/TX: GPIO 16/17
Thermal SPI SCLK/MISO/MOSI/CS: GPIO 18/19/23/27
Thermal READY/RESET: GPIO 26/25
```

최종 목표 보드인 XIAO ESP32-C6에는 이 firmware를 그대로 업로드할 수 없다. XIAO C6 사용 시 핀, UART, SPI class와 FreeRTOS 동작을 포팅하고 compile/HIL 검증해야 한다. 이 제한 때문에 **XIAO C6 기준으로는 현재 ZIP만 받아 즉시 전체 시스템을 실행할 수 없다.**

## 3. 기존 실행 방식과 달라진 점

다음 기존 명령은 새 통합 패키지에 포함되지 않으며 실행하지 않는다.

```text
cd ~/raspberry_pi_lcd && bash start_lcd.sh
cd ~/SafeNest_Web && node server.js
http://RPI_IP:8080/thermal
http://RPI_IP:3000
```

새 통합 시스템은 Raspberry Pi에서 Python process 하나가 TCP 9000, UDP 5005, HTTP 8000, SQLite와 대시보드를 함께 담당한다.

```text
ESP32 scalar → TCP 9000 ─┐
ESP32 Thermal → UDP 5005 ├→ SafeNest Runtime
                         ├─ FastAPI / WebSocket :8000
                         ├─ SQLite data/safenest.db
                         ├─ Admin /admin
                         ├─ Guest Thermal /guest/dashboard/A01
                         └─ Dashboard /dashboard
```

## 4. 받는 사람의 최초 설치 순서

### 4.1 저장소 받기

Raspberry Pi에서 canonical 저장소의 최신 `main`을 받는다.

[Raspberry Pi에서 실행]

```bash
cd ~
git clone https://github.com/jinsu1011/safenest-embedded-competition.git
cd safenest-embedded-competition
test -f ./run_safenest.sh
```

이미 clone한 폴더라면 `git pull --ff-only`로 최신 내용을 받은 뒤 진행한다.

Windows에서 먼저 확인할 경우 최신 mmWave 실험 파일 중 경로가 긴 항목이 있으므로 드라이브 루트에 가까운 짧은 clone 경로(예: `C:\safenest`)를 사용하고 Git의 `core.longpaths`를 활성화한다. Raspberry Pi에는 Windows 경로 길이 제한이 없다.

### 4.2 OS 기본 package

```bash
sudo apt update
sudo apt install -y python3-venv python3-pip python3-dev build-essential unzip
```

### 4.3 Python 의존성 설치와 최초 실행

```bash
cd ~/safenest-embedded-competition
./run_safenest.sh --install
```

이 명령은 다음을 순서대로 수행한다.

1. `<repository>/.venv` 생성 (`SAFENEST_VENV_PATH`로 재정의 가능. `~/.venv`가 기본값이 아니다)
2. backend 및 Pi AI 의존성 설치
3. 필수 파일과 Python runtime 확인
4. manifest에 등록된 primary 3개와 보존된 후보 artifact의 SHA-256 확인

최신 mmWave BPF+Z-score 경로는 `runtime_manifest_path`를 명시적으로 전달하는 phase 전용 기능이다. 현재 SafeNest 통합은 운영 primary manifest를 사용하며, `deployment_ready=false` 오프라인 후보를 자동 선택하지 않는다. phase 후보를 별도로 실험할 때만 `scipy`와 해당 runtime manifest 계약을 추가 설치·검증한다.
5. TCP 8000·9000과 UDP 5005 포트 확인
6. FastAPI와 전체 sensor runtime 실행

설치 또는 LiteRT package가 Pi의 Python version에서 실패하면 그 오류를 해결하기 전에는 실행 완료로 간주하지 않는다.

## 5. ESP32 최초 준비

canonical flash source에 비밀번호를 직접 기록하지 말고 Arduino sketch 작업 복사본을 만든다. 플래시 원본은 `ESP32/Arduino/esp32_sensor_node/esp32_sensor_node.ino`다.

[Windows 노트북 PowerShell에서 실행]

```powershell
$repo = "safenest-embedded-competition_경로"
$source = Join-Path $repo "ESP32\Arduino\esp32_sensor_node"
$sketch = Join-Path $HOME "Documents\Arduino\esp32_sensor_node"
Copy-Item -LiteralPath $source -Destination $sketch -Recurse
Copy-Item -LiteralPath (Join-Path $repo "ESP32\secret.h.example") -Destination (Join-Path $sketch "secrets.h")
```

`secrets.h`를 다음처럼 실제 환경에 맞춘다.

```cpp
constexpr char WIFI_SSID[] = "EELab04 2G";
constexpr char WIFI_PASSWORD[] = "실제_비밀번호";
constexpr char RPI_HOST[] = "Raspberry_Pi_IP";
constexpr uint16_t RPI_PORT = 9000;
```

sketch에 선언된 `THERMAL_UDP_PORT = 5005`와 Pi UDP listener 설정이 같은지도 확인한다. 이 상수는 `secrets.h`에 다시 선언하지 않는다.

Arduino IDE에서 다음을 확인한다.

1. Board: `ESP32 Dev Module`
2. 올바른 ESP-WROOM-32 USB port
3. `Sensirion I2C SCD4x`, `Seeed Arduino mmWave` library 설치
4. 센서 배선과 전압 확인
5. firmware upload
6. Serial Monitor 115200 baud에서 Wi-Fi와 TCP 연결 확인

canonical firmware는 boot 때 한 번 생성한 `boot_id`를 재연결 중 유지한다. telemetry `seq`는 약 1초 publication마다, `co2_measurement_event_id`는 성공한 새 SCD4x read마다, `pir_event_id`는 실제 digital state transition마다 증가한다. Thermal `frame_sequence`는 획득한 frame마다 증가하고 `chunk_index`는 한 frame의 0부터 8까지를 식별한다. 서로 다른 sequence를 대체 사용하지 않는다.

Pi는 source의 `uptime_ms`와 sensor event monotonic time을 그대로 보존하고, 별도로 receive wall-clock 및 receive monotonic time을 기록한다. ESP와 Pi 사이 wall-clock 동기화는 가정하지 않는다.

## 6. 매번 프로그램 실행 순서

1. 노트북 Wi-Fi를 `EELab04 2G`로 연결한다.
2. Raspberry Pi 전원을 켠다.
3. Raspberry Pi가 부팅될 때까지 기다린다.
4. VS Code Remote SSH로 Raspberry Pi에 연결한다.
5. VS Code에서 터미널을 하나 연다.
6. Raspberry Pi 통합 프로그램을 실행한다.

```bash
cd ~/safenest-embedded-competition
./run_safenest.sh
```

7. 터미널에서 Uvicorn TCP 8000, sensor TCP 9000, Thermal UDP 5005 listener가 시작됐는지 확인한다.
8. ESP-WROOM-32와 센서 전원을 켠다.
9. ESP32 Serial Monitor 또는 Pi 로그에서 TCP 연결과 telemetry 수신을 확인한다.
10. 노트북 브라우저에서 다음 주소를 연다.

```text
관리자 웹:          http://RPI_IP:8000/admin
A01 방문자 열화상:  http://RPI_IP:8000/guest/dashboard/A01
통합 웹 대시보드:  http://RPI_IP:8000/dashboard
상태 API:           http://RPI_IP:8000/api/status
시스템 진단:        http://RPI_IP:8000/health
API 문서:           http://RPI_IP:8000/docs
```

11. 대시보드에서 `ONLINE`, 센서별 `LIVE`, 현재 값, risk와 최근 갱신 시각을 확인한다.

## 7. 프로그램 종료 순서

1. 브라우저 사용을 종료한다.
2. `run_safenest.sh`가 실행 중인 Pi 터미널에서 `Ctrl+C`를 한 번 누른다.
3. Uvicorn shutdown과 backend 종료 메시지가 끝날 때까지 기다린다.
4. ESP32와 센서 전원을 분리한다.
5. Raspberry Pi에서 안전 종료를 실행한다.

```bash
sudo shutdown -h now
```

6. SSH 연결이 끊어지는 것을 확인한다.
7. Raspberry Pi activity LED가 멈춘 뒤 전원선을 분리한다.

별도의 `node server.js`, `start_lcd.sh`, `stop_lcd.sh` process는 새 통합 시스템에 없으므로 시작하거나 종료할 필요가 없다.

## 8. 정상 실행 확인

[Raspberry Pi의 별도 SSH 터미널에서 실행]

```bash
curl -fsS http://127.0.0.1:8000/health | python3 -m json.tool
curl -fsS http://127.0.0.1:8000/api/status | python3 -m json.tool
curl -sS -D - -o /dev/null http://127.0.0.1:8000/api/thermal/A01
```

필수 확인 항목:

- `/health`의 `ok`가 `true`
- database `available`이 `true`
- receiver `connections`가 1 이상
- receiver `thermal_udp`의 완료 frame과 effective FPS가 증가
- `/api/status`의 `ready`가 `true`
- 센서 연결 후 system `ONLINE`
- SQLite snapshot count가 계속 증가

## 9. 문제 발생 위치 구분

| 증상 | 먼저 확인할 계층 |
|---|---|
| ESP32가 Wi-Fi에 연결되지 않음 | `secrets.h`, 2.4 GHz SSID/비밀번호 |
| ESP32 TCP 연결 실패 | `RPI_HOST`, port 9000, Pi firewall, runtime 실행 여부 |
| 모든 센서 DISCONNECTED | ESP32 전원/TCP와 Pi receiver |
| 한 센서만 INVALID/STALE | 해당 센서 배선·driver·freshness |
| Thermal AI unavailable | LiteRT 설치, 모델 hash, frame 유효성 |
| API는 되지만 DB unavailable | DB 경로 권한과 SQLite 오류 |
| 브라우저 접속 실패 | port 8000, Pi IP, 같은 Wi-Fi 여부 |
| 대시보드 값이 갱신되지 않음 | `/api/status`, `/ws`, sensor timestamp |

## 10. 전달 전 체크리스트

- 저장소 루트에 `README.md`, `run_safenest.sh`, `ESP32/`, `RaspberryPi/`가 있는가?
- `RaspberryPi/Runtime/PACKAGE_AND_OPERATION_GUIDE.md`와 `INTEGRATION_PHASE_SUMMARY.md`가 있는가?
- `RaspberryPi/Ondevice_AI/models/`와 manifest 등록 primary/candidate artifact가 있는가?
- Runtime의 `requirements-backend.txt`와 Ondevice_AI의 `requirements-pi.txt`가 있는가?
- 실제 `secrets.h`, `.venv`, DB, SSH key가 포함되지 않았는가?
- 받는 사람이 WROOM-32와 XIAO C6 제한을 이해했는가?
- 실제 장비 HIL 미완료와 TEST 4/6 제약을 전달했는가?

## 11. Stage 7 Mac-offline preflight and future Pi execution

Mac에서 배포 구조만 확인할 때는 Pi를 기다리지 않는다.

```bash
python3 -m hil.preflight --offline-preflight
```

이 명령이 PASS여도 Pi 배포, ARM, process/port, 실센서 검증을 의미하지 않는다. `pi_checks`와 `sensor_checks`는 `NOT_RUN`이다. Python 3.10 이상에서 runtime import/construct 실패는 구조적 차단이고, 3.10 미만 skip은 ARM/Pi runtime 검증이 아니다.

```text
STAGE_7_MAC_OFFLINE_RUNTIME_PREPARATION = PASS_WITH_LIMITATIONS
STAGE7_PREFLIGHT_MMWAVE_SELECTOR_DRIFT = RESOLVED_IN_CODE
PI_DEPLOYMENT = NOT_RUN
PI_PROCESS_CHECK = NOT_RUN
PI_PORT_CHECK = NOT_RUN
PI_ARM_RUNTIME = NOT_RUN
```

Stage 7 preflight는 현재 M-N9 selector를 검사한다. `deployment_allowed=true`는
device validation이 아니다. 추가 Mac RP-X0 구현은 필요 없고, 이후 실제 Pi 실행만 남는다.

```text
Further Mac RP-X0 implementation required:
NO

FUTURE_OPERATOR_CAN_EXECUTE_WITHOUT_CHAT_HISTORY:
YES for Mac-offline RP-X0 integration work

Remaining boundary:
Stage 7 actual Pi execution = PI_REQUIRED / NOT_RUN
Stage 9 live smoke = SENSOR_AND_PI_REQUIRED / NOT_RUN
```

현재 효과:

```text
PR #22 active M-N9 selector = authoritative
historical B = inactive
O3 status projection = MODEL_PENDING
Stage 7 preflight asserts M-N9 selector identity
deployment_allowed=true is not device validation
DEVICE_VALIDATED = false
PI_SMOKE = NOT_PERFORMED
PRESENCE_GATE_REQUIRED = true
```

아래는 Stage 7의 hardware boundary이며 Stage 9 live-sensor smoke가 아니다.

1. `jinsu1011/safenest-embedded-competition`의 검토된 `main` commit을 checkout한다.
2. Raspberry Pi에서 지원 Python(3.10+)과 `./run_safenest.sh --install`을 사용한다.
3. `.env.example`을 참고해 필요한 env/config를 적용한다. 개발자 Mac 절대경로를 넣지 않는다. venv 기본은 `<repository>/.venv` (`SAFENEST_VENV_PATH`로 재정의).
4. Thermal production path는 `thermal_public_sdt_fp32_active`이며 기존 v0.1.0 INT8은 non-active legacy다. `HUMAN_FALL_PROXY`는 위험 점수 `0.4`로 제한 반영하고 emergency override에는 사용하지 않는다. Stage 7 preflight는 selector·artifact·risk boundary를 함께 검사한다. CO₂/mmWave의 별도 selector와 검증 경계는 manifest를 따른다.
5. `./run_safenest.sh`로 runtime을 시작한다. 진입점은 `run_safenest.sh → RaspberryPi/Runtime/deployment/run_pi.sh → backend/run_backend.py`다.
6. process가 살아 있는지 확인한다.
7. 기대 포트: HTTP `:8000`, TCP `:9000`, UDP `:5005`.
8. `curl -fsS http://127.0.0.1:8000/health` 와 `/api/status`로 backend health를 확인한다.
9. Admin `/admin`, A01 guest thermal `/guest/dashboard/A01`, Dashboard `/dashboard` 도달을 확인한다. Pi LCD도 별도 서버 대신 `/dashboard`를 연다.

그 다음 Stage 9 minimal live smoke만 수행한다. 30분 soak는 기본이 아니다.

## 12. 긴급 대응 HMI와 환경변수

DANGER 전환 시 터치 화면에 긴급 오버레이가 열리고, 서버의 alarm latch·buzzer·SQLite event log가 함께 갱신된다. 119 버튼은 경진대회 시연용 모의 카운트다운만 수행하며 실제 119에 연결되지 않는다. `경고 확인`은 buzzer만 끄고 Risk Engine의 DANGER를 해제하지 않는다. 센서가 offline이거나 WebSocket이 끊겨도 live `WARNING/NORMAL` publication이 오기 전까지 DANGER를 유지한다.

담당자 SMS와 GPIO 설정은 [`docs/EMERGENCY_HMI_AND_OPERATIONS_KO.md`](docs/EMERGENCY_HMI_AND_OPERATIONS_KO.md)의 `.env` 표를 따른다. 실제 SMS 자격증명이 없을 때는 요청을 성공으로 처리하지 않고 `SMS_NOT_CONFIGURED`를 반환한다. 개발 PC에서는 `SAFENEST_GPIO_MODE=mock`을 사용하고, Raspberry Pi에서는 BCM buzzer 핀과 전원 회로를 실제 배선과 대조한다.

화면에 사용할 한국어 음성 파일의 이름과 위치는 [`../../Web/audio/README.md`](../../Web/audio/README.md)에 있다. 음성 파일이 없거나 autoplay가 차단되어도 API와 터치 동작은 중단되지 않는다.

## 13. Stage 9 minimal live-smoke tooling

Stage 9 툴링은 배포 후 런타임이 최소로 살아 있는지 관측하기 위한 읽기 전용 probe다. Mac에서 평가기를 완성하며, 실제 live smoke는 하지 않는다.

```bash
python3 -m hil.stage9_smoke
python3 -m hil.stage9_smoke --plan
python3 -m hil.stage9_smoke --evaluate-fixture tests/fixtures/stage9/pass.json
```

기본 호출은 plan이며 hardware에 접속하지 않는다. fixture PASS는 evaluator 검증일 뿐 `STAGE_9_LIVE_SMOKE = PASS`가 아니다.

```text
STAGE_9_LIVE_SMOKE = NOT_RUN
```

미래 Pi에서만, Stage 7 process/port 확인 뒤에 명시적으로:

```bash
python3 -m hil.stage9_smoke --live
```

`--live`는 Linux/Pi에서 로컬 `ss`와 localhost HTTP만 결합한다. `--host`가 loopback이 아니면 거절한다. Mac에서 `--live`를 실행하면 실패로 거절한다. 기본 관측 창은 20초이며 운영 smoke 시간일 뿐 모델/샘플링 계약이 아니다. 30분 soak는 기본이 아니다.

검사하는 것:

- HTTP `:8000` `/health`, `/api/status`
- TCP `:9000`, UDP `:5005` listener
- ESP TCP session (`/api/status` TCP 센서 connectivity; receiver counters는 보조)
- CO2 물리 측정 identity 진행 (`measurement_event_count`; `last_received_at`만으로는 PASS하지 않음)
- Thermal/mmWave/PIR identity 진행 (값 변화가 아님; PIR `NO_MOTION` 허용)
- runtime-status (Thermal AI `BLOCKED`, PIR AI `NOT_APPLICABLE`; mmWave는 현재 O3 projection `MODEL_PENDING`을 소비한다. PR #22 M-N9 selector와 혼동하지 않는다)
- logger drop **증가분** (`/health` `receiver.sensor_logging.dropped`; `new_drops = after - before`. 과거 lifetime count만으로 FAIL하지 않음)

검사하지 않는 것:

- 모델 정확도, T-B5 활성화, 옛 mmWave B live gate, Capture, risk 임계값, 합성 패킷 주입

결과: `PASS` / `PASS_WITH_LIMITATIONS` / `FAIL` / plan의 `NOT_RUN`.
종료코드: `PASS`, `PASS_WITH_LIMITATIONS`, `NOT_RUN` → 0; `FAIL` → 1.

JSON은 stdout. `--output logs/stage9-smoke.json`은 선택이며 `logs/`는 gitignore된다. 실측 리포트를 커밋하지 않는다.

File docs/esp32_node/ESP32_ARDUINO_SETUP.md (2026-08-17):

# ESP32-WROOM-32 Arduino IDE setup

## Prerequisites

- ESP32-WROOM-32 / ESP32 Dev Module
- A USB data cable
- Arduino IDE 2.x
- 2.4 GHz Wi-Fi
- MR60BHA2, SCD4x, PIR, and MI48 thermal sensor with common ground

## Board and libraries

1. Install the Espressif Systems ESP32 board package from Boards Manager.
2. Select Tools > Board > esp32 > ESP32 Dev Module.
3. Install Sensirion I2C SCD4x and Seeed Arduino mmWave from Library Manager.
4. Select the serial port and open Serial Monitor at 115200 baud.

WiFi, Wire, SPI, and WiFiUDP are included with the ESP32 board package.

## Sketch and secrets.h

Create secrets.h next to devices/esp32_node/firmware/esp32_sensor_node.ino:

~~~
#pragma once
constexpr char WIFI_SSID[] = "YOUR_2G_SSID";
constexpr char WIFI_PASSWORD[] = "YOUR_WIFI_PASSWORD";
constexpr char RPI_HOST[] = "192.168.0.50";
constexpr uint16_t RPI_PORT = 9000;
~~~

RPI_HOST must be an IP address or DNS host without an HTTP scheme or port suffix. The thermal UDP port is the firmware constant THERMAL_UDP_PORT=5005; do not redeclare it in secrets.h.

## Pin map

- SCD4x: SDA GPIO21, SCL GPIO22
- PIR OUT: GPIO13
- MR60BHA2: sensor TX -> ESP32 GPIO16, sensor RX <- ESP32 GPIO17
- Thermal SPI: SCLK GPIO18, MISO GPIO19, MOSI GPIO23, CS GPIO27, READY GPIO26, RESET GPIO25

## Upload

1. Run Verify.
2. Run Upload.
3. If upload stops at Connecting..., hold the BOOT button while starting upload.
4. Open Serial Monitor at 115200 baud after upload.

Expected startup includes:

~~~
SafeNest ESP32 sensor node starting
[thermal] ready: ...
[co2] ready: first measurement takes about 5 seconds
[wifi] connecting to YOUR_SSID asynchronously
~~~

## Verify both network channels

- TCP 9000: scalar telemetry JSON. Confirm a TCP listener is listening.
- UDP 5005: thermal datagrams. Confirm a UDP listener is bound.

On Raspberry Pi:

~~~
hostname -I
sudo ss -ltnp | grep 9000
sudo ss -lunp | grep 5005
sudo ufw allow 9000/tcp
sudo ufw allow 5005/udp
~~~

In the ESP32 health log, thermal_frames is the capture count and udp_sent/udp_failed are frame send results. If thermal_frames grows while udp_failed grows, check RPI_HOST, listener, firewall, and Wi-Fi subnet before suspecting a camera short.

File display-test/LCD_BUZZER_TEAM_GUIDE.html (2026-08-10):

SafeNest 팀 인수인계 문서

# LCD 화면 출력·제어와 피에조 부저 로직

처음 프로젝트를 받는 팀원도 배선, 무음 점검, 실행, 긴급 경보 시험, 종료, Git 업로드까지 한 번에 따라 할 수 있도록 정리했습니다.

작성 기준 2026-08-01 Raspberry Pi + Chromium BCM GPIO18 · 880 Hz 기본 포트 8080

## 오늘 구현한 핵심

Raspberry Pi 한 대가 상태 서버와 LCD 화면을 함께 실행합니다. 같은 Wi-Fi의 노트북이 제어 페이지에서 상태를 바꾸면 LCD가 즉시 갱신되고, 긴급 상태일 때만 피에조 부저가 울립니다.

LCD

6

### 상태별 전체화면

정상·재실·주의·위험·긴급·오류를 색상, 큰 제목, 지표, 행동 문구로 구분합니다.

동기화

0.4초

### LCD 상태 조회 주기

LCD 페이지가 /api/state를 400 ms마다 확인하고 revision이 바뀐 경우만 다시 그립니다.

Alarm

880 Hz

### 긴급 전용 경보

emergency에서만 GPIO18 부저를 켜며, 다른 상태와 서버 종료에서는 끕니다.

현재 범위: 화면에 보이는 CO₂·온도·움직임 수치는 실제 센서에서 수신한 값이 아니라 수동 시연용 예시값입니다. 이번 구현은 화면·원격 상태 전환·긴급 부저 연동까지이며, 센서 실시간 연동 완료를 의미하지 않습니다.

### 이 문서 작성 시 다시 확인한 것

- Python 회귀 테스트 2개 통과
- Python 파일 및 셸 스크립트 문법 검사 통과
- 부저 비활성 모드에서 /health, /display, /control 응답 확인
- 실물 LCD 표시와 GPIO 부저 소리는 Raspberry Pi에서 현장 확인 필요

## 동작 구조

1. 노트북 제어버튼 또는 숫자키 1~6

2. 상태 APIPOST /api/state

3. 저장·출력state.json + LCD 갱신

4. 경보 판단emergency이면 부저 ON

### LCD 화면 쪽

static/display.html은 400 ms마다 상태를 조회합니다. 각 상태는 common.css의 색상 변수로 구분되고, 긴급 화면에는 붉은 점멸 효과가 추가됩니다.

상태 revision이 변했을 때만 DOM을 갱신하므로 같은 상태를 반복해서 다시 그리지 않습니다.

### 노트북 제어 쪽

static/control.html은 버튼과 숫자키 1~6을 지원합니다. 자동 순환은 3초마다 다음 상태로 이동하며 수동 선택 시 즉시 멈춥니다.

공간 이름은 최대 24자로 정리되어 상태 파일에 함께 저장됩니다. 제어 페이지는 1.5초마다 서버 연결 상태를 다시 확인합니다.

### 파일 역할

파일 | 역할 | 팀원이 주로 수정할 때
server.py | HTTP 서버, 입력 검증, 상태 저장, 부저 ON/OFF | 상태·API·GPIO 규칙 변경
static/display.html | 실제 LCD 전체화면과 상태별 문구·예시값 | LCD 내용 변경
static/control.html | 노트북 미리보기, 버튼, 키보드, 자동 순환 | 원격 제어 UI 변경
static/common.css | 상태 색상, LCD 레이아웃, 긴급 점멸 | 디자인·해상도 조정
start_lcd.sh | 서버 시작 후 Chromium 키오스크 실행 | 포트·브라우저 실행 옵션 변경
stop_lcd.sh | PID 파일 기준 브라우저와 서버 종료 | 종료 대상 추가
deploy_buzzer.sh | 테스트→재시작→긴급음 2초→해제 자동 검증 | 현장 검증 절차 변경
test_buzzer.py | 실물 GPIO 없이 부저·상태 연동 회귀 검사 | 부저 규칙 변경 시 테스트 보강

## LCD 6개 상태와 부저 매핑

상태 키는 서버가 허용하는 값과 화면의 시나리오 키가 같아야 합니다. 현재 부저가 켜지는 상태는 긴급 하나뿐입니다.

키 / 조작 | LCD 표시 | 대표 상황 | 색상 | 부저
normal-empty 숫자 1 | 정상 · 미재실 | 사람 감지 없음 | 초록 | OFF
normal-occupied 숫자 2 | 정상 · 재실 | 작업자 움직임 감지 | 파랑 | OFF
warning 숫자 3 | 환경 주의 | CO₂ 농도 상승 예시 | 황색 | OFF
danger 숫자 4 | 작업자 위험 | 무움직임·호흡 이상 예시 | 주황 | OFF
emergency 숫자 5 | 긴급 + 붉은 점멸 | 고체온·호흡 이상·무움직임 예시 | 빨강 | ON, 880 Hz 연속음
offline 숫자 6 | 통신 오류 | 센서 데이터 수신 불가 | 회색 | OFF

## 피에조 부저 제어 로직

### 초기화

gpiozero.TonalBuzzer(18)을 만들고 즉시 정지합니다. 기본 주파수는 880 Hz입니다. 초기화 실패 시 오류를 기록하되 화면 서버는 계속 실행됩니다.

### 상태 연동

상태를 저장한 직후 state == "emergency" 결과를 부저에 전달합니다. 같은 ON/OFF 요청이 반복되면 GPIO 명령을 중복 실행하지 않습니다.

### 안전 종료

서버 종료 시 stop() 후 close()를 호출합니다. 자동 검증 스크립트도 EXIT·INT·TERM에서 긴급 상태를 해제하도록 방어합니다.

### 상태 확인

/health에서 활성화 여부, GPIO 사용 가능 여부, BCM 핀, 주파수, 현재 발음 상태, 오류를 확인할 수 있습니다.

재시작 주의: 서버 시작 시 저장된 마지막 상태가 emergency이면 부저가 바로 켜집니다. 실물 부저를 연결하기 전 state.json의 상태를 확인하거나 아래 무음 시험으로 먼저 normal-empty를 저장하세요.

## 2핀 수동 피에조 부저 배선

Raspberry Pi 전원을 완전히 끈 상태에서 연결합니다. 프로그램은 BCM 번호를 사용하며, BCM GPIO18은 물리 핀 12번입니다.

부저 단자 | Raspberry Pi | 물리 핀 | 기준 위치
+ 긴 다리 | BCM GPIO18 | 12번 | USB 포트가 아래쪽일 때 위에서 6행, 바깥쪽 열
− 짧은 다리 | GND | 14번 | USB 포트가 아래쪽일 때 위에서 7행, 바깥쪽 열

하드웨어 안전: 전원이 켜진 상태에서 배선을 바꾸지 마세요. 5V 핀에 연결하지 않습니다. 단순 저전류 피에조 소자가 아니라 전류가 큰 부저 모듈·스피커라면 GPIO에 직결하지 말고 트랜지스터 드라이버와 보호 회로를 사용해야 합니다.

## 팀원용 실행 순서

처음에는 부저를 연결하지 않거나 --disable-buzzer로 무음 시험을 끝낸 뒤 실제 출력을 켭니다.

1

### Raspberry Pi 준비 상태 확인

Pi와 노트북을 같은 Wi-Fi에 연결하고 필요한 명령이 설치되어 있는지 확인합니다.

복사

python3 --version
python3 -c 'import gpiozero; print("gpiozero OK")'
command -v chromium || command -v chromium-browser
command -v curl
hostname -I

빠진 항목이 있으면 Raspberry Pi OS에서 다음을 설치합니다.

복사

sudo apt update
sudo apt install -y python3 python3-gpiozero chromium curl

2

### 프로젝트 가져오기

GitHub 업로드 후에는 clone 방식이 권장됩니다.

복사

git clone https://github.com/<조직또는계정>/<저장소명>.git
cd <저장소명>/safenest_lcd_remote

아직 GitHub에 올리지 않았다면 Windows PowerShell에서 Pi로 복사합니다. 아래 IP는 현재 문서의 예시이므로 실제 Pi IP로 바꿉니다.

복사

scp -r .\safenest_lcd_remote sandi@192.168.1.44:~/

3

### 실행 권한과 자동 테스트

복사

cd ~/safenest_lcd_remote
chmod +x start_lcd.sh stop_lcd.sh deploy_buzzer.sh
python3 -m unittest -v test_buzzer.py

마지막에 Ran 2 tests와 OK가 표시되어야 합니다. 이 테스트는 실물 GPIO 대신 모의 부저를 사용하므로 소리가 나지 않습니다.

4

### 부저 없는 무음 서버 시험

부저 출력 없이 API와 웹 화면부터 확인합니다. 이 직접 실행 방식은 Chromium 키오스크를 자동으로 띄우지 않습니다.

복사

python3 server.py --disable-buzzer

노트북에서 http://<라즈베리파이-IP>:8080/control을 열고 1~6 버튼을 눌러 봅니다. Pi 브라우저에서는 http://127.0.0.1:8080/display를 열 수 있습니다.

저장 상태가 긴급이면 제어 페이지에서 1. 정상 · 사람 없음을 선택한 뒤 Ctrl+C로 종료합니다.

5

### LCD 키오스크와 실제 부저 실행

전원을 끄고 배선을 마친 뒤 다시 켭니다. 부저가 울려도 안전한 상황인지 주변에 먼저 알립니다.

복사

cd ~/safenest_lcd_remote
bash start_lcd.sh

스크립트가 서버 준비를 확인한 후 Wayland 또는 X11을 자동 선택하고 Chromium을 전체화면으로 엽니다. Raspberry Pi 5의 Chromium GPU 충돌을 피하기 위해 CPU 소프트웨어 렌더링 옵션을 사용합니다.

6

### 건강 상태 확인

복사

curl -s http://127.0.0.1:8080/health | python3 -m json.tool

실물 부저를 사용할 때는 enabled: true, available: true, pin_bcm: 18, frequency_hz: 880.0, 초기 sounding: false를 확인합니다.

7

### 노트북에서 제어

start_lcd.sh가 출력한 주소를 노트북 브라우저에서 엽니다. 예: http://192.168.1.44:8080/control.

- 버튼 또는 숫자키 1~6: 즉시 상태 전환
- 자동 순환: 3초마다 다음 상태로 이동
- 수동 선택: 자동 순환 즉시 중지
- 공간 이름 적용: 최대 24자까지 Pi에 저장

8

### 실제 경보 2초 자동 시험 — 선택 사항

이 명령은 실제 소리를 냅니다. 현장 인원에게 알리고, 테스트 중지 권한이 있는 사람이 옆에서 실행하세요.

복사

cd ~/safenest_lcd_remote
bash deploy_buzzer.sh

단위 테스트와 GPIO 라이브러리 확인 후 LCD를 재시작하고, 긴급 상태를 약 2초 유지한 다음 자동으로 정상 상태로 되돌립니다. 중단 신호를 받아도 경보 해제를 시도합니다.

9

### 종료

복사

cd ~/safenest_lcd_remote
bash stop_lcd.sh

Chromium 키오스크와 SafeNest 서버에 종료 신호를 보내고 PID 파일을 정리합니다. 서버 종료 과정에서 부저도 정지·해제됩니다.

## 주소와 API

경로 | 방식 | 용도
/control | GET | 노트북 원격 제어 화면
/display | GET | Raspberry Pi LCD 전체화면
/api/state | GET | 현재 상태, 공간 이름, revision, 갱신 시각 조회
/api/state | POST | 허용 상태 또는 공간 이름 변경
/health | GET | 서버와 부저 상태 확인

### 상태를 직접 긴급으로 바꾼 뒤 즉시 해제

실물 부저가 연결되어 있으면 첫 명령부터 경보음이 납니다.

복사

curl -s -X POST http://127.0.0.1:8080/api/state \
  -H 'Content-Type: application/json' \
  -d '{"state":"emergency"}'

sleep 2

curl -s -X POST http://127.0.0.1:8080/api/state \
  -H 'Content-Type: application/json' \
  -d '{"state":"normal-empty"}'

## 문제 해결

제어 페이지는 열리는데 LCD가 안 뜹니다

복사

cat ~/safenest_lcd_remote/logs/chromium.log
command -v chromium || command -v chromium-browser
echo "$XDG_RUNTIME_DIR"
echo "$WAYLAND_DISPLAY"
echo "$DISPLAY"

Pi의 실제 로그인 화면 세션과 SSH 세션의 Wayland/X11 환경이 다르면 Chromium이 열리지 않을 수 있습니다.

서버 또는 8080 포트가 열리지 않습니다

복사

cat ~/safenest_lcd_remote/logs/server.log
curl -v http://127.0.0.1:8080/health
ss -ltnp | grep ':8080'

부저가 울리지 않습니다

복사

python3 -c 'import gpiozero; print(gpiozero.__file__)'
curl -s http://127.0.0.1:8080/health | python3 -m json.tool
tail -n 50 ~/safenest_lcd_remote/logs/server.log

available: false 또는 error가 있으면 GPIO 라이브러리, 핀 점유, 권한, 배선을 먼저 확인합니다. 2핀 수동 피에조인지도 확인하세요.

노트북에서 제어 주소가 열리지 않습니다

복사

hostname -I
curl -s http://127.0.0.1:8080/health

Pi와 노트북이 같은 네트워크인지, 브라우저 주소에 Pi의 최신 IP와 포트 8080을 사용했는지 확인합니다.

## GitHub 업로드 준비

현재 폴더에는 실행 중 생기는 로그·PID·상태·Chromium 프로필을 제외하는 .gitignore와 Linux 실행 파일의 줄바꿈을 지키는 .gitattributes가 준비되어 있습니다.

### 업로드할 구조

safenest_lcd_remote/ ├─ server.py ├─ start_lcd.sh ├─ stop_lcd.sh ├─ deploy_buzzer.sh ├─ test_buzzer.py ├─ static/ │ ├─ display.html │ ├─ control.html │ └─ common.css ├─ LCD_BUZZER_TEAM_GUIDE.html ├─ GIT_UPLOAD_GUIDE.md ├─ README.md ├─ state.example.json ├─ .gitignore └─ .gitattributes

업로드 제외: state.json, logs/, PID 파일, .chromium-kiosk/, __pycache__/. 이 항목은 기기별 런타임 데이터입니다.

### 새 저장소에 올리는 명령

복사

git init
git branch -M main
git add .
git update-index --chmod=+x start_lcd.sh stop_lcd.sh deploy_buzzer.sh
git status --short
git diff --cached --check
git commit -m "feat: add SafeNest LCD control and emergency buzzer"
git remote add origin https://github.com/<조직또는계정>/<저장소명>.git
git push -u origin main

### 권장 PR 제목

복사

feat: Raspberry Pi LCD 원격 제어 및 긴급 피에조 경보 추가

커밋 범위, 검증 체크리스트, 그대로 복사할 PR 본문은 같은 폴더의 GIT_UPLOAD_GUIDE.md에 준비되어 있습니다.

## 팀 인계 완료 체크리스트

### 실행 담당자

- Pi 전원을 끄고 GPIO18·GND 배선 확인
- 무음 테스트 후 저장 상태를 정상으로 초기화
- LCD에서 6개 화면과 긴급 점멸 확인
- 긴급 부저 ON과 정상 복귀 OFF 확인
- stop_lcd.sh 종료 후 무음 확인

### Git 업로드 담당자

- 런타임 파일이 staging에 없는지 확인
- 셸 3개 파일의 실행 권한 비트 확인
- 실물 확인 결과를 PR 체크박스에 반영
- 센서 수치가 예시값임을 PR에 명시
- 팀원 한 명이 clone부터 재실행

완료 기준: “코드가 올라감”이 아니라, 다른 팀원이 새로 clone한 폴더에서 무음 시험 → LCD 실행 → 현장 경보 시험 → 안전 종료까지 재현해야 인계 완료입니다.

SafeNest LCD·피에조 부저 팀원 가이드 · 2026-08-01

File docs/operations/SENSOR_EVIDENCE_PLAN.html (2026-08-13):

# SafeNest 센서 실기기 증거 확보 계획

SCD40(CO2) · HC-SR501 계열(PIR) 실측 증거를 devices/co2/, devices/pir/ 아래에 남기기 위한 작업 절차서

작성일 2026-08-12 저장소 safenest-embedded-competition 기준 구조 devices/mmwave/ 셸 PowerShell (Windows 11)

## 0. 이 문서의 사용 규칙

#### 절대 규칙

- 측정하지 않은 값은 만들지 않는다. mock_sensor.py 출력, 시뮬레이션 값, 손으로 쓴 숫자는 증거가 아니다.
- 로그 파일(logs/*.jsonl, *.csv)은 생성 후 사람이 편집하지 않는다. 잘못 찍혔으면 다시 측정한다.
- 결측을 0으로 바꾸지 않는다. 센서 분리·타임아웃은 null + error_code로 기록하고 SensorState로 표기한다.
- 한 번에 한 단계만 진행한다. 이전 단계의 통과 기준을 충족하기 전에 다음 단계로 넘어가지 않는다.
- 배선 변경은 모든 전원(USB-C·외부전원)을 뺀 상태에서만 한다. (docs/operations/HARDWARE_RUNBOOK.md §0)
- git 커밋·푸시는 승인 후에만. main에 직접 커밋하지 않는다.

트랙 표기 ■ 공통 — 두 센서 공통 준비 ■ CO2 — feature/co2-scd40-verification ■ PIR — feature/pir-verification

## 1. 현재 저장소 상태 진단

### 1.1 증거 산출물 존재 여부

요구 산출물 | devices/mmwave (기준) | devices/co2 | devices/pir
docs/WIRING.md (배선·전원·사진) | docs/ 7종 존재(배선 전용 문서는 없음) | 없음 (docs/ 디렉터리 자체 없음) | 없음 (docs/ 디렉터리 자체 없음)
firmware/capture_*.py | capture_serial.py 존재 | 없음 (firmware/ 없음) | 없음 (firmware/ 없음)
firmware/logs/ 실측 로그 | baseline·breath·diagnostics·final 60여 개 JSONL | 없음 | 없음
firmware/analysis/*_summary.json | 40여 개 존재 | 없음 | 없음
tests/ 기기 단독 테스트 | 4개 (로그 리플레이 포함) | 없음 | 없음
docs/VERIFICATION_REPORT_*.md | MMWAVE_TUNING_REPORT_2026-07-29.md 등 | 없음 | 없음

현재 devices/co2/는 README.md, src/co2_adapter.py, src/mock_sensor.py, src/__init__.py 4개 파일뿐이고 devices/pir/도 동일 구성이다. 즉 6종 산출물 중 0종이 존재한다.

### 1.2 코드 레벨에서 발견한 문제

위치 | 내용 | 영향
devices/co2/src/co2_adapter.py:52-54 | read_raw_values()가 (650.0, 45.0, 23.5) 고정값을 반환. 실제 I2C 통신 코드가 한 줄도 없다. | 이름은 "Hardware SCD40 I2C Adapter"지만 실체는 상수 스텁. 지금 상태로 돌리면 하드웨어가 없어도 "정상 동작"처럼 보인다.
devices/co2/src/co2_adapter.py:28-38 | connect()가 self.connected = True만 하고 무조건 성공을 반환. | 센서를 뽑아도 NOT_CONNECTED가 되지 않는다. 결측 시나리오가 현재 코드로는 재현 불가.
devices/pir/src/pir_adapter.py:34-36 | read_gpio()가 항상 True 반환. GPIO 접근 코드 없음. | 영구 "동작 감지" 상태. 무동작 5분 오검출 0 검증이 구조적으로 불가능.
devices/pir/src/pir_adapter.py:22-32 | connect()가 GPIO 설정 없이 무조건 성공. | CO2와 동일 문제.
devices/mmwave/firmware/src/main.cpp:528 | 부팅 이벤트가 "board":"esp-wroom-32"를 보고. 반면 HARDWARE_RUNBOOK.md §3은 XIAO ESP32-C6 핀맵(D4/D5/D0)을 권장. | 문서와 펌웨어의 보드가 불일치. 실물 보드를 확인해야 배선표를 쓸 수 있다. → 질문 Q2
main.cpp 전체 (546줄) | scd/co2/pir/Wire/i2c 문자열이 하나도 없음. 현재 ESP 펌웨어는 mmWave UART 전용. | SCD40/PIR을 ESP32에 붙이기로 하면 펌웨어에 센서 읽기·JSON 필드 추가가 필요하다(통신 재구축이 아니라 필드 추가). → 질문 Q1/Q3
.gitattributes | 경로가 firmware/esp_wroom32_mr60_monitor/logs/...로 되어 있어 현재 구조(devices/mmwave/firmware/logs/)와 맞지 않는 사문화된 규칙. | 새 로그가 CRLF 변환·자동 정규화로 바이트가 바뀔 수 있다. 1단계에서 devices/*/firmware/logs/** 규칙을 추가한다.
작업 트리 상태 | devices/mmwave/firmware/capture_serial.py 수정됨(M), monitor_serial.py·logs/live/ 미추적(??). | 브랜치를 파기 전에 이 변경을 어떻게 처리할지 결정해야 한다. → 질문 Q11

### 1.3 계약(shared/contracts/base_sensor.py) 요약

요소 | 정의 | 검증에서 의미
SensorState | NORMAL / NOT_CONNECTED / READ_TIMEOUT / INVALID_FORMAT / NAN_OR_INF / OUT_OF_BOUNDS / INFER_FAILED / STALE / SHUTDOWN | 센서 분리 시 NOT_CONNECTED 또는 READ_TIMEOUT이어야 하고 값은 valid=False여야 한다.
BaseSensor 추상 메서드 | connect(), read() -> InferenceResult, close() | 기기 테스트는 이 3개와 health()를 저장된 로그로 재생해 검증한다.
SensorHealth | sensor_id, connected, state, last_read_ts, age_sec, read_count, error_count, last_error | stale_sec(기본 5초) 초과 시 STALE로 전이되는지 확인한다.

## 2. 진행 전 확인이 필요한 사항

#### 아래 답변 전에는 1단계 이후로 진행하지 않는다

핀 번호·포트·보드·전원은 추측하면 하드웨어가 망가진다. 모르는 항목은 "모름"이라고 답하면 확인 절차부터 계획에 넣는다.

번호 | 질문 | 왜 필요한가
Q1 | SCD40과 PIR을 각각 어느 보드에 붙일 것인가? (ESP32 / 라즈베리파이 5) | 캡처 경로가 완전히 달라진다. ESP32면 펌웨어 수정 + 시리얼 캡처, Pi면 Python I2C/GPIO 직접 읽기.
Q2 | 실물 ESP32 보드 모델은? (main.cpp는 esp-wroom-32, 런북은 XIAO ESP32-C6) | 핀 이름(D4/D5/D0 vs GPIO21/22)과 전압 규격이 다르다.
Q3 | 현재 ESP32 펌웨어에 SCD40/PIR 읽기 코드가 이미 있는가? 있다면 어느 파일인가? | 없으면 펌웨어에 센서 필드를 추가해야 하고, 그러면 재플래싱 절차가 계획에 들어간다.
Q4 | SCD40 배선 실제 핀: SDA / SCL이 각각 어느 핀에 꽂혀 있는가? (아직 안 꽂았으면 "미배선") | WIRING.md의 핵심 내용이며, 이후 명령의 I2C 버스 번호와 직결된다.
Q5 | SCD40 breakout 제품명과 전원 핀 실크 표기는? (VIN / VDD / 3V3) 레귤레이터·레벨시프터 유무는? | 5V를 넣으면 안 되는 보드에 5V를 넣으면 센서가 죽는다. 런북 §6-3 필수 확인 항목.
Q6 | PIR 모듈 정확한 모델명(HC-SR501?)과 OUT 핀 HIGH 전압 실측값은? VCC는 5V인가 3.3V인가? | OUT이 3.3V를 넘으면 레벨시프터 없이 MCU에 직결 금지(런북 §7-2).
Q7 | PIR OUT을 연결할 핀 번호, 그리고 모듈의 홀드타임/감도 볼륨과 재트리거 점퍼(H/L) 현재 설정은? | 검출 지연·검출률 해석에 반드시 필요하다. 홀드타임이 길면 10회 반복 간격을 그에 맞춰야 한다.
Q8 | 캡처 스크립트를 어디서 실행하는가? (Windows PC에서 USB 시리얼 / 라즈베리파이에서 SSH) | PowerShell 명령의 형태가 달라진다. Pi 실행이면 SSH 원격 명령으로 감싼다.
Q9 | Windows PC에서 ESP32가 잡히는 COM 포트 번호는? (예: COM5) | capture_*.py --port 인자. 2단계에서 목록을 뽑는 명령으로 같이 확인할 수 있다.
Q10 | 라즈베리파이 접속 방법: IP 주소, 사용자 계정, SSH 키 사용 여부. (비밀번호는 알려주지 말 것 — 필요 시 본인이 직접 입력) | Pi에서 측정하거나 Pi로 파일을 가져올 때 필요.
Q11 | 현재 미커밋 상태인 devices/mmwave/firmware/capture_serial.py(수정), monitor_serial.py·logs/live/(미추적)를 어떻게 할까? (그대로 두기 / 별도 커밋 / stash) | 브랜치를 파기 전에 정리해야 CO2·PIR 커밋에 섞이지 않는다.
Q12 | 배선 사진 촬영이 가능한가? 촬영본을 어디에 두면 되는가? | WIRING.md에 사진이 요구 산출물로 명시되어 있다.

## 3. 만들 디렉터리 구조 (mmwave와 동일 형태)

devices/co2/                          devices/pir/
├─ docs/                              ├─ docs/
│  ├─ WIRING.md                       │  ├─ WIRING.md
│  ├─ images/                         │  ├─ images/
│  └─ VERIFICATION_REPORT_YYYY-MM-DD.md  │  └─ VERIFICATION_REPORT_YYYY-MM-DD.md
├─ firmware/                          ├─ firmware/
│  ├─ capture_scd40.py                │  ├─ capture_pir.py
│  ├─ analyze_scd40_log.py            │  ├─ analyze_pir_log.py
│  ├─ logs/                           │  ├─ logs/
│  │  ├─ diagnostics/                 │  │  ├─ diagnostics/
│  │  ├─ baseline/                    │  │  ├─ baseline/
│  │  ├─ scenario/                    │  │  ├─ scenario/
│  │  └─ fault/                       │  │  └─ fault/
│  └─ analysis/*_summary.json         │  └─ analysis/*_summary.json
├─ src/ (기존)                        ├─ src/ (기존)
└─ tests/test_co2_contract.py         └─ tests/test_pir_contract.py

## 4. 단계 요약표

단계 | 트랙 | 이름 | 핵심 산출물
S1 | 공통 | 하드웨어 정보 확정 | Q1~Q12 답변 (이후 모든 문서의 근거)
S2 | 공통 | 작업 트리 정리 · CO2 브랜치 생성 · 디렉터리 골격 · .gitattributes 보강 | feature/co2-scd40-verification, 빈 디렉터리 구조
S3 | 공통 | 캡처 환경 점검 (Python, pyserial, COM 포트 / SSH) | 실행 가능 확인 로그
S4 | CO2 | SCD40 배선 + 사진 + WIRING.md 초안 | devices/co2/docs/WIRING.md, docs/images/
S5 | CO2 | 원시 판독 경로 확보 (펌웨어 필드 추가 또는 Pi I2C 리더) | 펌웨어 패치 또는 리더 코드
S6 | CO2 | capture_scd40.py 작성 | devices/co2/firmware/capture_scd40.py
S7 | CO2 | 헬스체크 60초 (0x62 검출, CRC 오류 0) | logs/diagnostics/*_healthcheck_60s.jsonl
S8 | CO2 | 워밍업 후 실내 baseline 5분 | logs/baseline/*_indoor_baseline_300s.jsonl
S9 | CO2 | 입김 주입 → 상승·복귀 시나리오 | logs/scenario/*_breath_injection.jsonl
S10 | CO2 | 센서 분리 → 결측 표기 시나리오 | logs/fault/*_disconnect.jsonl
S11 | CO2 | analyze_scd40_log.py 작성 및 실행 | analysis/*_summary.json 4종
S12 | CO2 | 계약 테스트 작성·실행 (저장 로그 리플레이) | devices/co2/tests/test_co2_contract.py
S13 | CO2 | 검증 보고서 작성 · WIRING.md 확정 | docs/VERIFICATION_REPORT_YYYY-MM-DD.md
S14 | CO2 | 커밋 · 푸시 · PR (승인 후) | 원격 브랜치 + PR
S15 | PIR | main에서 PIR 브랜치 생성 · 디렉터리 골격 | feature/pir-verification
S16 | PIR | OUT 전압 실측 → 배선 + 사진 + WIRING.md 초안 | devices/pir/docs/WIRING.md
S17 | PIR | 원시 판독 경로 확보 + capture_pir.py 작성 | devices/pir/firmware/capture_pir.py
S18 | PIR | 전원 인가 후 워밍업 60초 캡처 | logs/diagnostics/*_warmup_60s.jsonl
S19 | PIR | 무동작 5분 오검출 0 확인 | logs/baseline/*_no_motion_300s.jsonl
S20 | PIR | 동작 10회 반복 → 검출률·검출 지연 | logs/scenario/*_motion_trials_10.jsonl + 큐 파일
S21 | PIR | 센서 분리 → 결측 처리 확인 | logs/fault/*_disconnect.jsonl
S22 | PIR | analyze_pir_log.py 작성 및 실행 | analysis/*_summary.json 4종
S23 | PIR | 계약 테스트 작성·실행 | devices/pir/tests/test_pir_contract.py
S24 | PIR | 검증 보고서 작성 | docs/VERIFICATION_REPORT_YYYY-MM-DD.md
S25 | PIR | 커밋 · 푸시 · PR (승인 후) | 원격 브랜치 + PR

## 5. 단계별 상세

<확정 후>로 표시된 명령은 S1 답변에 따라 값이 정해진다. 그 전에는 실행하지 않는다.

S1. 하드웨어 정보 확정 공통

목적 | 추측 없이 배선표·캡처 명령을 확정한다.
내 물리 작업 | 보드·모듈 실물을 보고 §2의 Q1~Q12에 답한다. 모르면 "모름"으로 답한다. SCD40 breakout과 PIR 모듈의 실크(핀 이름) 사진을 찍어두면 좋다.
AI 작업 | 답변을 정리하고 S2 이후 명령의 인자(포트·핀·경로)를 확정한다. "모름" 항목은 확인 절차를 별도 단계로 추가한다.
PowerShell | 없음 (대화로 진행)
통과 기준 | Q1·Q2·Q8이 확정됨. 나머지는 "모름"이어도 확인 절차로 대체 가능.
산출물 | 없음 (S4/S16의 WIRING.md에 반영)

S2. 작업 트리 정리 · 브랜치 · 디렉터리 골격 공통

목적 | 깨끗한 브랜치에서 시작하고, 로그가 CRLF 변환으로 오염되지 않게 막는다.
내 물리 작업 | 없음
AI 작업 | Q11 답변에 따라 미커밋 변경 처리 → main 최신화 → CO2 브랜치 생성 → 디렉터리·.gitkeep 생성 → .gitattributes에 devices/*/firmware/logs/**/*.jsonl binary 규칙 추가.
PowerShell | git -C "<repo>" fetch origin git -C "<repo>" switch -c feature/co2-scd40-verification origin/main 디렉터리 생성 명령은 S2 실행 시 함께 제시
통과 기준 | git status가 예상대로 나오고, 브랜치가 feature/co2-scd40-verification이며 main이 아니다.
산출물 | 브랜치, 빈 디렉터리 구조, .gitattributes 갱신

S3. 캡처 환경 점검 공통

목적 | 측정 직전에 환경 문제로 실패하는 것을 막는다.
내 물리 작업 | ESP32(또는 Pi)를 PC에 연결한 상태로 둔다.
AI 작업 | 결과를 보고 누락 패키지·포트 문제를 진단한다.
PowerShell | python --version python -c "import serial; print(serial.__version__)" Get-CimInstance Win32_SerialPort | Select-Object DeviceID, Description
통과 기준 | Python 3.x 확인, pyserial 임포트 성공, ESP32 COM 포트가 목록에 보임 (Pi 실행이면 SSH 접속 성공).
산출물 | 없음 (확인용)

S4. SCD40 배선 + 사진 + WIRING.md 초안 CO2

목적 | 제3자가 재현할 수 있는 배선 근거를 남긴다.
내 물리 작업 | ① 모든 전원 분리 ② 무전원에서 VCC-GND 저항 측정(0Ω 근처면 중단) ③ SDA/SCL/GND 연결(20cm 이내) ④ 전원 핀은 Q5 확인 결과에 따라 결정 — 정체 불명 보드에 5V 금지 ⑤ 사진 3장: 전원 전 전체 / 핀 근접 / 전원 후 상태 LED.
AI 작업 | 답변·사진 파일명을 받아 WIRING.md 초안 작성 (보드, 핀 대응표, 공급 전압, 풀업 유무, I2C 주소, 사진 링크).
PowerShell | 사진 복사 명령 <확정 후>
통과 기준 | 단락 없음, 사진 3장 확보, 배선표의 모든 칸이 실측/실물 확인으로 채워짐(추정 없음).
산출물 | devices/co2/docs/WIRING.md, devices/co2/docs/images/*

S5. SCD40 원시 판독 경로 확보 CO2

목적 | 실제 I2C로 읽은 값이 타임스탬프와 함께 호스트까지 도달하게 한다. (현재 co2_adapter.py는 상수 스텁이라 그대로는 증거가 될 수 없다.)
내 물리 작업 | ESP32 경로면 펌웨어 재플래싱, Pi 경로면 I2C 활성화(raspi-config) 및 i2cdetect 실행.
AI 작업 | Q1/Q3에 따라 ESP 펌웨어에 SCD40 필드 추가 코드를 쓰거나, Pi용 I2C 리더를 작성한다. 오류는 null + error_code로 내보내도록 한다(런북 §8-4).
PowerShell | <확정 후>
통과 기준 | I2C 스캔에서 0x62 검출. 콘솔에 실제로 변하는 ppm/온도/습도가 출력됨.
산출물 | 펌웨어 패치 또는 리더 코드

S6. capture_scd40.py 작성 CO2

목적 | 원시 로그를 가공 없이 JSONL로 저장한다. (devices/mmwave/firmware/capture_serial.py와 동일 철학)
내 물리 작업 | 없음
AI 작업 | --port --duration --output 인자, UTC 타임스탬프 + 단조 시각, 수신 레코드 무변형 기록, 결측·타임아웃 시 null + error_code 기록, 종료 시 레코드 수 출력.
PowerShell | 없음 (파일 작성)
통과 기준 | 스크립트가 --help로 정상 실행되고, 값 보정·평활·결측 대체 로직이 들어있지 않다.
산출물 | devices/co2/firmware/capture_scd40.py

S7. 헬스체크 60초 CO2

목적 | 본 측정 전에 통신이 안정적인지 확인한다.
내 물리 작업 | 센서 근처에서 숨을 쉬지 말고 60초 대기.
AI 작업 | 레코드 수·결측·CRC 오류를 확인하고 이상이면 원인을 진단한다.
PowerShell | python devices/co2/firmware/capture_scd40.py ` --port <COM> --duration 60 ` --output devices/co2/firmware/logs/diagnostics/2026-MM-DD_healthcheck_60s.jsonl
통과 기준 | 재부팅 0회, I2C timeout/CRC 오류 0회, 결측 없이 값 갱신.
산출물 | logs/diagnostics/*_healthcheck_60s.jsonl

S8. 워밍업 후 실내 baseline 5분 CO2

목적 | 기준 실내 농도와 노이즈 수준을 확보한다.
내 물리 작업 | 전원 인가 후 5분 워밍업(런북 §6-6). 그다음 센서에서 1m 이상 떨어져 5분간 유지. 환기·재실 인원·창문 상태를 기록해 알려준다. 측정 중 센서 쪽으로 숨을 쉬지 않는다.
AI 작업 | 명령 제공 후 결과 검토.
PowerShell | python devices/co2/firmware/capture_scd40.py ` --port <COM> --duration 300 ` --output devices/co2/firmware/logs/baseline/2026-MM-DD_indoor_baseline_300s.jsonl
통과 기준 | 레코드 결측률 < 1%, 비현실적 점프 없음, 값이 물리적으로 타당한 범위(대략 400~2000ppm 실내).
산출물 | logs/baseline/*_indoor_baseline_300s.jsonl

S9. 입김 주입 → 상승·복귀 CO2

목적 | 센서가 실제 자극에 반응한다는 것을 보인다. 상수 스텁으로는 절대 나올 수 없는 증거다.
내 물리 작업 | 구간을 시계로 지키고 각 전환 시각을 메모: ①0~60초 무자극 ②60~90초 센서 10cm 앞에서 천천히 날숨 ③90~300초 자리를 떠나 복귀 관찰. 시작·종료 시각을 알려준다.
AI 작업 | 구간별 통계로 상승폭·복귀 시상수를 계산한다.
PowerShell | python devices/co2/firmware/capture_scd40.py ` --port <COM> --duration 300 ` --output devices/co2/firmware/logs/scenario/2026-MM-DD_breath_injection.jsonl
통과 기준 | 자극 구간 최대값이 baseline 평균 + 200ppm 이상 상승하고, 이후 baseline 방향으로 단조 감소(복귀)한다.
산출물 | logs/scenario/*_breath_injection.jsonl

S10. 센서 분리 → 결측 표기 CO2

목적 | 결측이 0으로 위조되지 않고 결측 상태로 남는지 증명한다.
내 물리 작업 | 캡처 시작 → 30초 정상 기록 → SDA(또는 SCL) 점퍼 1개만 뽑음 → 60초 유지 → 다시 꽂음 → 30초 기록. 전원선은 뽑지 않는다(단락 위험). 뽑고 꽂은 시각을 알려준다.
AI 작업 | 결측 구간의 값이 null이고 상태가 NOT_CONNECTED/READ_TIMEOUT인지 확인한다.
PowerShell | python devices/co2/firmware/capture_scd40.py ` --port <COM> --duration 120 ` --output devices/co2/firmware/logs/fault/2026-MM-DD_disconnect.jsonl
통과 기준 | 결측 구간에 co2_ppm = 0인 레코드가 0개. null 또는 명시적 error_code로만 기록됨. 재연결 후 정상 복귀.
산출물 | logs/fault/*_disconnect.jsonl

S11. 분석 스크립트 실행 CO2

목적 | 재현 가능한 수치 요약을 남긴다. (analyze_mmwave_log.py와 동형)
내 물리 작업 | 없음
AI 작업 | analyze_scd40_log.py 작성: 샘플 수, 결측 수·결측률, ppm 평균/중앙/표준편차/최소/최대, 샘플링 주기, CRC·파싱 오류 수, 구간별 통계, 판정(PASS/FAIL).
PowerShell | python devices/co2/firmware/analyze_scd40_log.py ` devices/co2/firmware/logs/baseline/2026-MM-DD_indoor_baseline_300s.jsonl ` --output devices/co2/firmware/analysis/2026-MM-DD_indoor_baseline_300s_summary.json (4개 로그에 대해 반복)
통과 기준 | summary 4개 생성. 각 파일에 records, missing_rate, 통계, verdict가 존재.
산출물 | devices/co2/firmware/analysis/*_summary.json ×4

S12. 계약 테스트 CO2

목적 | 저장된 실측 로그를 재생해 BaseSensor 계약 준수를 자동 검증한다.
내 물리 작업 | 없음
AI 작업 | test_co2_contract.py 작성: ①connect/read/close 구현 확인 ②baseline 로그 리플레이 시 valid=True, ppm 범위 타당 ③fault 로그 리플레이 시 valid=False이고 상태가 NOT_CONNECTED/READ_TIMEOUT, score가 0으로 위조되지 않음 ④stale_sec 초과 시 STALE 전이 ⑤로그 파일이 실측본임을 파일 해시로 고정.
PowerShell | python -m pytest devices/co2/tests -v
통과 기준 | 전 테스트 통과. mock을 쓰지 않고 저장 로그만 사용.
산출물 | devices/co2/tests/test_co2_contract.py

S13. 검증 보고서 작성 CO2

목적 | 측정 조건·기대값·실측값·합격 여부를 한 문서로 묶는다.
내 물리 작업 | 환경 정보 제공(실내 면적, 재실 인원, 환기 상태, 기온, 측정 시각).
AI 작업 | 보고서 작성: 장비·펌웨어 버전, 배선 버전, 시나리오별 조건/기대/실측/판정 표, 로그 파일 경로와 SHA-256, 미달 항목과 사유.
PowerShell | Get-FileHash devices/co2/firmware/logs/*/*.jsonl -Algorithm SHA256 | Select-Object Hash, Path
통과 기준 | 4개 시나리오 전부 표에 있고, 각 행의 실측값이 로그에서 계산된 값과 일치.
산출물 | devices/co2/docs/VERIFICATION_REPORT_2026-MM-DD.md

S14. 커밋 · 푸시 · PR CO2 승인 필수

목적 | 제3자가 GitHub에서 증거를 확인할 수 있게 한다.
내 물리 작업 | 변경 목록 확인 후 승인.
AI 작업 | git status·git diff --stat을 먼저 보여주고 승인받은 뒤에만 커밋·푸시.
PowerShell | git -C "<repo>" add devices/co2 git -C "<repo>" commit -m "<메시지>" git -C "<repo>" push -u origin feature/co2-scd40-verification
통과 기준 | 원격 브랜치에 로그·summary·테스트·문서가 모두 올라가고 main은 변경되지 않음.
산출물 | 원격 브랜치, PR

S15. PIR 브랜치 생성 · 디렉터리 골격 PIR

목적 | CO2와 독립된 브랜치에서 PIR 증거를 만든다.
내 물리 작업 | 없음
AI 작업 | origin/main에서 feature/pir-verification 생성, devices/pir/ 하위 구조 생성.
PowerShell | git -C "<repo>" switch -c feature/pir-verification origin/main
통과 기준 | 브랜치 전환 성공, 작업 트리 깨끗함.
산출물 | 브랜치, 디렉터리

S16. OUT 전압 실측 → 배선 + 사진 + WIRING.md PIR

목적 | MCU 입력 파괴 없이 안전하게 연결하고 근거를 남긴다.
내 물리 작업 | ① 전원 분리 ② PIR VCC/GND만 먼저 연결하고 OUT 핀 HIGH 전압을 멀티미터로 실측 ③ 3.3V 초과면 중단하고 보고(분압/레벨시프터 필요) ④ 안전 확인 후 OUT을 지정 핀에 연결 ⑤ 감도·홀드타임·재트리거 점퍼 설정 기록 ⑥ 사진 3장 ⑦ 히터·직사광·환풍기에서 이격.
AI 작업 | 실측값 기반으로 WIRING.md 작성 (핀 대응표, VCC, OUT HIGH 실측 전압, 홀드타임, 재트리거 모드, 설치 높이·각도, 사진).
PowerShell | 사진 복사 <확정 후>
통과 기준 | OUT HIGH 실측값이 문서에 기록됨. 3.3V 초과 시 보호 회로 없이 연결하지 않았음.
산출물 | devices/pir/docs/WIRING.md, docs/images/*

S17. 원시 판독 경로 + capture_pir.py PIR

목적 | 엣지 타임스탬프를 놓치지 않고 기록한다. (검출 지연 측정의 정확도가 여기서 결정된다.)
내 물리 작업 | 필요 시 펌웨어 재플래싱 또는 Pi GPIO 준비.
AI 작업 | 20~50ms 폴링 또는 엣지 인터럽트로 상태 변화 시각을 밀리초 단위 기록. 매 레코드에 seq, 단조 시각, UTC 시각, 원시 GPIO 레벨. 큐(cue) 기능으로 동작 시작 시각을 별도 파일에 남겨 지연 계산 기준을 만든다.
PowerShell | 없음 (파일 작성)
통과 기준 | 손을 흔들면 콘솔에서 상태가 실제로 변한다.
산출물 | devices/pir/firmware/capture_pir.py

S18. 워밍업 60초 PIR

목적 | HC-SR501 계열은 전원 인가 직후 오출력이 있다. 워밍업 구간을 증거로 남긴다.
내 물리 작업 | 전원을 넣는 즉시 캡처 시작하고 센서 시야에서 벗어난 채 60초 대기.
AI 작업 | 워밍업 중 토글 횟수를 세어 안정화 시점을 판단.
PowerShell | python devices/pir/firmware/capture_pir.py ` --port <COM> --duration 60 ` --output devices/pir/firmware/logs/diagnostics/2026-MM-DD_warmup_60s.jsonl
통과 기준 | 60초 끝 시점에서 출력이 LOW로 안정. 안정되지 않으면 대기 시간을 늘리고 재측정.
산출물 | logs/diagnostics/*_warmup_60s.jsonl

S19. 무동작 5분 · 오검출 0 PIR

목적 | 오검출률 0을 실측으로 보인다.
내 물리 작업 | 워밍업 직후 이어서 측정. 센서 시야 밖으로 완전히 이동해 5분간 정지. 문 개폐·에어컨·직사광 변화가 없도록 한다. 실내 조건을 기록해 알려준다.
AI 작업 | HIGH 전이 횟수를 센다.
PowerShell | python devices/pir/firmware/capture_pir.py ` --port <COM> --duration 300 ` --output devices/pir/firmware/logs/baseline/2026-MM-DD_no_motion_300s.jsonl
통과 기준 | HIGH 전이 0회. 1회라도 있으면 실패로 기록하고 원인(열원·바람·감도)을 진단한 뒤 재측정.
산출물 | logs/baseline/*_no_motion_300s.jsonl

S20. 동작 10회 반복 · 검출률과 지연 PIR

목적 | 검출률과 검출 지연을 수치로 남긴다.
내 물리 작업 | 스크립트의 큐 신호에 맞춰 10회 반복: 큐가 울리면 정해진 위치에서 센서 앞을 횡방향으로 1회 통과. 통과 사이에는 홀드타임 + 5초 이상 시야 밖에서 대기(간격은 Q7의 홀드타임에 따라 확정). 거리·각도·보행 속도를 매회 동일하게 유지하고 조건을 알려준다.
AI 작업 | 큐 시각과 HIGH 전이 시각을 매칭해 검출률과 지연(평균·중앙·최대)을 계산.
PowerShell | python devices/pir/firmware/capture_pir.py ` --port <COM> --duration <확정> --cue-count 10 --cue-interval <확정> ` --output devices/pir/firmware/logs/scenario/2026-MM-DD_motion_trials_10.jsonl ` --cue-output devices/pir/firmware/logs/scenario/2026-MM-DD_motion_trials_10_cues.jsonl
통과 기준 | 10회 중 10회 검출(런북 §7 기준 95% 이상). 검출 지연 중앙값이 기록되고 이상치 사유가 설명됨.
산출물 | logs/scenario/*_motion_trials_10.jsonl + *_cues.jsonl

S21. 센서 분리 → 결측 처리 PIR

목적 | PIR은 LOW와 "연결 없음"이 겉보기에 같다. 이 둘을 구분해 기록하는지 증명한다.
내 물리 작업 | 캡처 중 30초 정상 → OUT 선만 분리 60초 → 재연결 30초. 시각을 알려준다. (VCC/GND는 유지)
AI 작업 | 결측 구간이 motion=false가 아니라 null + NOT_CONNECTED로 기록되는지 확인한다. 하드웨어만으로 구분이 불가능하면 그 사실을 보고서에 한계로 명시하고, 어댑터 레벨에서 어떤 근거(신호 없음 타임아웃 등)로 결측을 판정하는지 문서화한다.
PowerShell | python devices/pir/firmware/capture_pir.py ` --port <COM> --duration 120 ` --output devices/pir/firmware/logs/fault/2026-MM-DD_disconnect.jsonl
통과 기준 | 결측 구간이 정상 LOW와 구분되어 기록되거나, 구분 불가 사실과 대응 설계가 문서화됨.
산출물 | logs/fault/*_disconnect.jsonl

S22. 분석 스크립트 실행 PIR

목적 | PIR 지표를 재현 가능하게 요약한다.
내 물리 작업 | 없음
AI 작업 | analyze_pir_log.py: 샘플 수, 폴링 주기, 결측률, HIGH 전이 횟수, HIGH 유지시간 통계, 검출률, 검출 지연 통계, 판정.
PowerShell | python devices/pir/firmware/analyze_pir_log.py ` devices/pir/firmware/logs/baseline/2026-MM-DD_no_motion_300s.jsonl ` --output devices/pir/firmware/analysis/2026-MM-DD_no_motion_300s_summary.json (4개 로그 반복)
통과 기준 | summary 4개 생성, 각 파일에 판정 결과 포함.
산출물 | devices/pir/firmware/analysis/*_summary.json ×4

S23. 계약 테스트 PIR

목적 | 저장 로그 리플레이로 PIRSensorAdapter의 계약 준수를 검증한다.
내 물리 작업 | 없음
AI 작업 | 테스트 작성: ①무동작 로그 리플레이 시 MOTION 상태가 0회 ②동작 로그 리플레이 시 10회 검출 ③결측 로그 리플레이 시 valid=False이고 NOT_CONNECTED ④no_motion_threshold_sec 경과 시 LONG_NO_MOTION 전이 ⑤로그 해시 고정.
PowerShell | python -m pytest devices/pir/tests -v
통과 기준 | 전 테스트 통과. mock 미사용.
산출물 | devices/pir/tests/test_pir_contract.py

S24. 검증 보고서 작성 PIR

목적 | 측정 조건·기대값·실측값·합격 여부를 문서화한다.
내 물리 작업 | 설치 높이·각도·통과 거리·실내 조건 제공.
AI 작업 | 보고서 작성 + 로그 SHA-256 기재.
PowerShell | Get-FileHash devices/pir/firmware/logs/*/*.jsonl -Algorithm SHA256 | Select-Object Hash, Path
통과 기준 | 4개 시나리오가 모두 표에 있고 실측값이 로그와 일치.
산출물 | devices/pir/docs/VERIFICATION_REPORT_2026-MM-DD.md

S25. 커밋 · 푸시 · PR PIR 승인 필수

목적 | PIR 증거를 원격에 반영한다.
내 물리 작업 | 변경 목록 확인 후 승인.
AI 작업 | diff 제시 → 승인 후 커밋·푸시.
PowerShell | git -C "<repo>" add devices/pir git -C "<repo>" commit -m "<메시지>" git -C "<repo>" push -u origin feature/pir-verification
통과 기준 | 원격 브랜치에 전 산출물 반영, main 무변경.
산출물 | 원격 브랜치, PR

## 6. 최종 완료 판정 체크리스트

# | 확인 항목 | CO2 | PIR

1 | docs/WIRING.md에 보드·핀·전압·사진이 모두 실측 기반으로 있다 | ☐ | ☐
2 | firmware/capture_*.py가 원시 로그를 무변형으로 저장한다 | ☐ | ☐
3 | firmware/logs/에 4개 시나리오 실측 로그가 있다 | ☐ | ☐
4 | firmware/analysis/*_summary.json에 샘플 수·결측률·통계·판정이 있다 | ☐ | ☐
5 | tests/가 저장 로그로 base_sensor.py 계약을 검증하고 통과한다 | ☐ | ☐
6 | docs/VERIFICATION_REPORT_YYYY-MM-DD.md에 조건/기대/실측/합격이 있다 | ☐ | ☐
7 | 결측이 0으로 위조되지 않음이 로그와 테스트로 동시에 증명된다 | ☐ | ☐
8 | 모든 로그의 SHA-256이 보고서에 기재되어 있다 | ☐ | ☐
9 | 커밋에 mock·시뮬레이션 데이터가 증거로 포함되지 않았다 | ☐ | ☐

#### 측정 전 매번 확인

1. 배선 변경 시 전원이 완전히 분리되어 있는가
2. 이번 측정의 시나리오·시간·기대값을 알고 있는가
3. 출력 경로가 올바른 logs/ 하위 디렉터리인가
4. 측정 중 개입 시각(입김 시작, 점퍼 분리 등)을 기록할 준비가 되었는가

SafeNest 임베디드 SW 경진대회 · docs/operations/SENSOR_EVIDENCE_PLAN.html · 생성 2026-08-12
관련 문서: docs/operations/HARDWARE_RUNBOOK.md (Gate C: SCD40, Gate D: PIR) · 기준 구조: devices/mmwave/firmware/

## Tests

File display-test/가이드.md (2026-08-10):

# LCD·피에조 부저 실행 가이드

## 1. 부저 연결

- 부저 `+`: Raspberry Pi 물리 핀 12번(BCM GPIO18)
- 부저 `-`: Raspberry Pi 물리 핀 14번(GND)

## 2. Raspberry Pi에서 프로젝트 받기

```bash
git clone --branch feat/lcd-buzzer-alert --single-branch https://github.com/yuseungha/safenest-embedded-competition.git
cd safenest-embedded-competition/display-test
```

## 3. 필수 프로그램 설치

```bash
sudo apt update
sudo apt install -y python3-gpiozero chromium curl
chmod +x start_lcd.sh stop_lcd.sh
```

## 4. 실행

```bash
bash start_lcd.sh
```

LCD에는 상태 화면이 자동으로 표시됩니다.

## 5. 노트북에서 상태 제어

Raspberry Pi와 노트북을 같은 Wi-Fi에 연결하고, Raspberry Pi에서 IP를 확인합니다.

```bash
hostname -I
```

노트북 브라우저에서 아래 주소를 엽니다.

```text
http://라즈베리파이-IP:8080/control
```

`emergency`를 선택하면 피에조 부저가 울리고, 다른 상태를 선택하면 멈춥니다.

## 6. 종료

```bash
bash stop_lcd.sh
```

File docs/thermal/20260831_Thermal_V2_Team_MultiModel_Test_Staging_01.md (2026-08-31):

# Thermal V2 Team Multi-Model Test Staging

Date: 2026-08-31
Team repo: `jinsu1011/safenest-embedded-competition`
Standalone source: `sheepmeat/test` @ `4dccd25205af8994d29d03d75ebd0d7a7d6263e2` (PR #197 merged)

## Why this exists

The owner is not replacing the current Team Thermal model yet. This change stages
Candidate A and Candidate B next to the existing baseline so the operator can run
the **same** SafeNest stack three times and compare Thermal models.

`./run_safenest.sh` is unchanged and still starts the current Team baseline.

## Choices

| Choice | Selector | Meaning |
| --- | --- | --- |
| `baseline` | `thermal_public_sdt_fp32_active` | Current Team Thermal model |
| `a` | `thermal_tv2_candidate_a_a0_fp32_v1` | Thermal V2 Candidate A A0 |
| `b` | `thermal_tv2_candidate_b_seed42_fp32_test_v1` | Thermal V2 Candidate B seed-42 |

C1 is not in this selector. It is a matched control, not a user-facing prototype.

## Commands

```bash
./run_safenest_thermal_test.sh baseline
./run_safenest_thermal_test.sh a
./run_safenest_thermal_test.sh b
```

Remaining SafeNest arguments are forwarded:

```bash
./run_safenest_thermal_test.sh a --api-port 8080
```

The launcher only sets:

- `SAFENEST_THERMAL_TEST_MODE=1`
- `SAFENEST_THERMAL_MODEL_SELECTOR=<selector>`

then `exec`s `./run_safenest.sh`. There is no second backend.

## Artifact identity

### Baseline (default)

- Path: `RaspberryPi/Ondevice_AI/models/thermal/public_sdt/public_sdt_pooled_mlp_fp32_tflite_v1.tflite`
- SHA-256: `f88d65d76dbb21862e1f3cdff17cefb038a432047ded6ac8d5563bc8bc8c52ff`
- Preprocessing: existing per-frame min-max
- `active_runtime_selectors.thermal` remains this selector

### Candidate A (A_PREFERRED offline, Team test only)

- Team path: `RaspberryPi/Ondevice_AI/models/thermal/tv2/thermal_tv2_candidate_a_a0_fp32_v1.tflite`
- Size: 264704
- SHA-256: `a158a70c4735e28eec70b5a996f82c91f452b94bcc24c040838143f4a55b1985`
- Exact standalone G5 TFLite import (no reconversion)
- Preprocessing: `RELATIVE_THERMAL_APPEARANCE_V1` + `FRAME_ROBUST_P2_P98_V1`
- Status: `STANDALONE_G5_PASS_WITH_LIMITATIONS` / `A_PREFERRED_OFFLINE` / `CONTROLLED_TEAM_TEST`
- Not production. Not device validated.

### Candidate B (B_NOT_COMPETITIVE, comparison only)

- Source Keras (standalone, not committed to Team): `models/thermal/candidates/tv2_candidate_b/B_DEPTHWISE_SEPARABLE_seed42.keras`
- Source Keras SHA-256: `42563c3316e9e8511ab897aaa4dfd9a154887f3a0270d5dfb77a7a344cd3ff35`
- Team TFLite: `RaspberryPi/Ondevice_AI/models/thermal/tv2/thermal_tv2_candidate_b_seed42_fp32_test_v1.tflite`
- Team TFLite size: 24100
- Team TFLite SHA-256: `f5b9ecef8def2668bb65131671134e443c600e38c2575d4350e242f1abc0dfb4`
- Converter: TensorFlow 2.21.0, ordinary FP32, no quantization
- Preprocessing: same V2 robust path as A
- Status: `B_NOT_COMPETITIVE` / `CONTROLLED_COMPARISON_ONLY` / `NOT_PREFERRED`
- Packaging smoke only. Not scientifically revalidated.

## Preprocessing difference

Do not send A/B through the old min-max path.

- Baseline: existing Team `_prepare_float_frame` min-max (unchanged)
- A and B: per-frame `p2`/`p98` robust normalization

```text
p2 = percentile(frame, 2)
p98 = percentile(frame, 98)
y = clip((frame - p2) / max(p98 - p2, 1e-6), 0, 1)
```

Output is `[1,62,80,1]` float32, unit `RELATIVE_DIMENSIONLESS_NOT_CELSIUS`.

A and B share one implementation.

## Controlled-test semantics

- `active_runtime_selectors.thermal` is the default/current runtime and stays baseline.
- `controlled_test_runtime_selectors.thermal` is the operator opt-in allowlist.
- Unknown selector: fail closed.
- Test selector without `SAFENEST_THERMAL_TEST_MODE=1`: fail closed.
- Selection is once per process. Stop SafeNest and launch again to change models.

## Source geometry / device validation

Team Thermal UDP frames are already assembled as `[62,80]` (`height=62`, `width=80`)
before `ThermalInterpreter.predict`. This staging uses that array as received:

`TEAM_RUNTIME_62X80_AS_RECEIVED_EXPERIMENTAL_BRIDGE`

This does **not** prove MI48/G1 source equivalence.

`DEVICE_DOMAIN / SOURCE_GEOMETRY VALIDATION PENDING`

`LIVE_DEVICE_TEST = NOT_PERFORMED`

`LOCKED PUBLIC TEST = NOT ACCESSED`

## What was not changed

- `./run_safenest.sh`
- Risk thresholds / emergency logic / sensor weighting
- CO2, mmWave B23, PIR, voice, UI
- Baseline Thermal preprocessing
- Default Thermal selector

## Next step

After merge, pull onto the test machine/Pi and run the three launcher commands
for real integrated comparison. That live comparison is not claimed by this PR.

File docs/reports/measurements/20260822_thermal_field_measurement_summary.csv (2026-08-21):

metric | value | unit_or_note
pi_ip | 192.168.137.249 | SafeNest :8000 host
esp_peer | 192.168.137.107 | thermal.state.peer
system | ONLINE/DEGRADED
tcp_connections | 4
telemetry_packets | 15987 | cumulative at snapshot
thermal_completed_frames | 10074
thermal_written | 10068 | sensor_logging.written
thermal_ai_state | NOT_HUMAN | live snapshot
thermal_confidence | 0.9921875
temperature_calibrated | false
preprocessing | per_frame_minmax
model | thermal_fall_int8@0.1.0
mmwave_presence | true
mmwave_human_detected_raw | true
npz_on_disk | 3516
npz_readable | 3484
recent500_analysis_frames | 6163
recent500_NOT_HUMAN | 5879
recent500_HUMAN_NORMAL | 189
recent500_HUMAN_FALL | 95
recent500_HUMAN_star_pct | 4.6 | %
recent_raw_span_mean | 465.54 | uint16 max-min

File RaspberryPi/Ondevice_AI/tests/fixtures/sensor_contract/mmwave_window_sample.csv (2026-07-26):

timestamp_s | resp_phase | subject_id | session_id | presence | label | breath_rpm | range_m | quality | signal_source | device_id
0.0000 | 0.120000 | S001 | S001_NORMAL_5MIN_01 | 1 | NORMAL | 17.00 | 0.9758 |  | MR60BHA2_breath_phase | safenest-node-01
0.1000 | 0.090000 | S001 | S001_NORMAL_5MIN_01 | 1 | NORMAL | 17.00 | 0.9758 |  | MR60BHA2_breath_phase | safenest-node-01
0.2000 | 0.010000 | S001 | S001_NORMAL_5MIN_01 | 1 | NORMAL | 17.00 | 0.9758 |  | MR60BHA2_breath_phase | safenest-node-01
0.3000 | -0.030000 | S001 | S001_NORMAL_5MIN_01 | 1 | NORMAL | 17.00 | 0.9758 |  | MR60BHA2_breath_phase | safenest-node-01
0.4000 | -0.120000 | S001 | S001_NORMAL_5MIN_01 | 1 | NORMAL | 17.00 | 0.9758 |  | MR60BHA2_breath_phase | safenest-node-01
0.5000 | -0.210000 | S001 | S001_NORMAL_5MIN_01 | 1 | NORMAL | 17.00 | 0.9758 |  | MR60BHA2_breath_phase | safenest-node-01
0.6000 | -0.260000 | S001 | S001_NORMAL_5MIN_01 | 1 | NORMAL | 17.00 | 0.9758 |  | MR60BHA2_breath_phase | safenest-node-01
0.7000 | -0.330000 | S001 | S001_NORMAL_5MIN_01 | 1 | NORMAL | 17.00 | 0.9758 |  | MR60BHA2_breath_phase | safenest-node-01
0.8000 | -0.370000 | S001 | S001_NORMAL_5MIN_01 | 1 | NORMAL | 16.00 | 0.9758 |  | MR60BHA2_breath_phase | safenest-node-01
0.9000 | -0.410000 | S001 | S001_NORMAL_5MIN_01 | 1 | NORMAL | 16.00 | 0.9758 |  | MR60BHA2_breath_phase | safenest-node-01
1.0000 | -0.430000 | S001 | S001_NORMAL_5MIN_01 | 1 | NORMAL | 16.00 | 0.9758 |  | MR60BHA2_breath_phase | safenest-node-01
1.1000 | -0.420000 | S001 | S001_NORMAL_5MIN_01 | 1 | NORMAL | 16.00 | 0.9758 |  | MR60BHA2_breath_phase | safenest-node-01
1.2000 | -0.410000 | S001 | S001_NORMAL_5MIN_01 | 1 | NORMAL | 16.00 | 0.9758 |  | MR60BHA2_breath_phase | safenest-node-01
1.3000 | -0.370000 | S001 | S001_NORMAL_5MIN_01 | 1 | NORMAL | 16.00 | 0.9758 |  | MR60BHA2_breath_phase | safenest-node-01
1.4000 | -0.350000 | S001 | S001_NORMAL_5MIN_01 | 1 | NORMAL | 16.00 | 0.9758 |  | MR60BHA2_breath_phase | safenest-node-01
1.5000 | -0.280000 | S001 | S001_NORMAL_5MIN_01 | 1 | NORMAL | 16.00 | 0.9758 |  | MR60BHA2_breath_phase | safenest-node-01
1.6000 | -0.210000 | S001 | S001_NORMAL_5MIN_01 | 1 | NORMAL | 16.00 | 0.9184 |  | MR60BHA2_breath_phase | safenest-node-01
1.7000 | -0.160000 | S001 | S001_NORMAL_5MIN_01 | 1 | NORMAL | 16.00 | 0.9184 |  | MR60BHA2_breath_phase | safenest-node-01
1.8000 | -0.070000 | S001 | S001_NORMAL_5MIN_01 | 1 | NORMAL | 16.00 | 0.9184 |  | MR60BHA2_breath_phase | safenest-node-01
1.9000 | -0.020000 | S001 | S001_NORMAL_5MIN_01 | 1 | NORMAL | 16.00 | 0.9184 |  | MR60BHA2_breath_phase | safenest-node-01
2.0000 | 0.080000 | S001 | S001_NORMAL_5MIN_01 | 1 | NORMAL | 15.00 | 0.9184 |  | MR60BHA2_breath_phase | safenest-node-01
2.1000 | 0.170000 | S001 | S001_NORMAL_5MIN_01 | 1 | NORMAL | 15.00 | 0.9184 |  | MR60BHA2_breath_phase | safenest-node-01
2.2000 | 0.210000 | S001 | S001_NORMAL_5MIN_01 | 1 | NORMAL | 15.00 | 0.9184 |  | MR60BHA2_breath_phase | safenest-node-01
2.3000 | 0.270000 | S001 | S001_NORMAL_5MIN_01 | 1 | NORMAL | 15.00 | 0.9184 |  | MR60BHA2_breath_phase | safenest-node-01
2.4000 | 0.290000 | S001 | S001_NORMAL_5MIN_01 | 1 | NORMAL | 15.00 | 0.9184 |  | MR60BHA2_breath_phase | safenest-node-01
2.5000 | 0.310000 | S001 | S001_NORMAL_5MIN_01 | 1 | NORMAL | 15.00 | 0.9184 |  | MR60BHA2_breath_phase | safenest-node-01
2.6000 | 0.300000 | S001 | S001_NORMAL_5MIN_01 | 1 | NORMAL | 15.00 | 0.9184 |  | MR60BHA2_breath_phase | safenest-node-01
2.7000 | 0.270000 | S001 | S001_NORMAL_5MIN_01 | 1 | NORMAL | 15.00 | 0.9184 |  | MR60BHA2_breath_phase | safenest-node-01
2.8000 | 0.250000 | S001 | S001_NORMAL_5MIN_01 | 1 | NORMAL | 15.00 | 0.9184 |  | MR60BHA2_breath_phase | safenest-node-01
2.9000 | 0.180000 | S001 | S001_NORMAL_5MIN_01 | 1 | NORMAL | 15.00 | 0.9184 |  | MR60BHA2_breath_phase | safenest-node-01
3.0000 | 0.150000 | S001 | S001_NORMAL_5MIN_01 | 1 | NORMAL | 15.00 | 0.9184 |  | MR60BHA2_breath_phase | safenest-node-01
3.1000 | 0.060000 | S001 | S001_NORMAL_5MIN_01 | 1 | NORMAL | 15.00 | 0.9184 |  | MR60BHA2_breath_phase | safenest-node-01
3.2000 | -0.030000 | S001 | S001_NORMAL_5MIN_01 | 1 | NORMAL | 15.00 | 0.9184 |  | MR60BHA2_breath_phase | safenest-node-01
3.3000 | -0.070000 | S001 | S001_NORMAL_5MIN_01 | 1 | NORMAL | 15.00 | 0.9184 |  | MR60BHA2_breath_phase | safenest-node-01
3.4000 | -0.160000 | S001 | S001_NORMAL_5MIN_01 | 1 | NORMAL | 15.00 | 0.9184 |  | MR60BHA2_breath_phase | safenest-node-01
3.5000 | -0.200000 | S001 | S001_NORMAL_5MIN_01 | 1 | NORMAL | 15.00 | 0.9184 |  | MR60BHA2_breath_phase | safenest-node-01
3.6000 | -0.260000 | S001 | S001_NORMAL_5MIN_01 | 1 | NORMAL | 15.00 | 0.9184 |  | MR60BHA2_breath_phase | safenest-node-01
3.7000 | -0.310000 | S001 | S001_NORMAL_5MIN_01 | 1 | NORMAL | 15.00 | 0.9184 |  | MR60BHA2_breath_phase | safenest-node-01
3.8000 | -0.330000 | S001 | S001_NORMAL_5MIN_01 | 1 | NORMAL | 15.00 | 0.9184 |  | MR60BHA2_breath_phase | safenest-node-01
3.9000 | -0.350000 | S001 | S001_NORMAL_5MIN_01 | 1 | NORMAL | 15.00 | 0.9184 |  | MR60BHA2_breath_phase | safenest-node-01
4.0000 | -0.350000 | S001 | S001_NORMAL_5MIN_01 | 1 | NORMAL | 15.00 | 0.9184 |  | MR60BHA2_breath_phase | safenest-node-01
4.1000 | -0.340000 | S001 | S001_NORMAL_5MIN_01 | 1 | NORMAL | 15.00 | 0.9184 |  | MR60BHA2_breath_phase | safenest-node-01
4.2000 | -0.310000 | S001 | S001_NORMAL_5MIN_01 | 1 | NORMAL | 15.00 | 0.9184 |  | MR60BHA2_breath_phase | safenest-node-01
4.3000 | -0.270000 | S001 | S001_NORMAL_5MIN_01 | 1 | NORMAL | 16.00 | 0.9184 |  | MR60BHA2_breath_phase | safenest-node-01
4.4000 | -0.250000 | S001 | S001_NORMAL_5MIN_01 | 1 | NORMAL | 16.00 | 0.9184 |  | MR60BHA2_breath_phase | safenest-node-01
4.5000 | -0.190000 | S001 | S001_NORMAL_5MIN_01 | 1 | NORMAL | 16.00 | 0.9184 |  | MR60BHA2_breath_phase | safenest-node-01
4.6000 | -0.160000 | S001 | S001_NORMAL_5MIN_01 | 1 | NORMAL | 16.00 | 0.9184 |  | MR60BHA2_breath_phase | safenest-node-01
4.7000 | -0.100000 | S001 | S001_NORMAL_5MIN_01 | 1 | NORMAL | 16.00 | 0.9184 |  | MR60BHA2_breath_phase | safenest-node-01
4.8000 | -0.050000 | S001 | S001_NORMAL_5MIN_01 | 1 | NORMAL | 16.00 | 0.9184 |  | MR60BHA2_breath_phase | safenest-node-01
4.9000 | -0.020000 | S001 | S001_NORMAL_5MIN_01 | 1 | NORMAL | 16.00 | 0.9184 |  | MR60BHA2_breath_phase | safenest-node-01
5.0000 | 0.030000 | S001 | S001_NORMAL_5MIN_01 | 1 | NORMAL | 16.00 | 0.9184 |  | MR60BHA2_breath_phase | safenest-node-01
5.1000 | 0.050000 | S001 | S001_NORMAL_5MIN_01 | 1 | NORMAL | 16.00 | 0.9184 |  | MR60BHA2_breath_phase | safenest-node-01
5.2000 | 0.090000 | S001 | S001_NORMAL_5MIN_01 | 1 | NORMAL | 17.00 | 0.9184 |  | MR60BHA2_breath_phase | safenest-node-01
5.3000 | 0.120000 | S001 | S001_NORMAL_5MIN_01 | 1 | NORMAL | 17.00 | 0.9184 |  | MR60BHA2_breath_phase | safenest-node-01
5.4000 | 0.130000 | S001 | S001_NORMAL_5MIN_01 | 1 | NORMAL | 17.00 | 0.9184 |  | MR60BHA2_breath_phase | safenest-node-01
5.5000 | 0.140000 | S001 | S001_NORMAL_5MIN_01 | 1 | NORMAL | 17.00 | 0.9184 |  | MR60BHA2_breath_phase | safenest-node-01
5.6000 | 0.150000 | S001 | S001_NORMAL_5MIN_01 | 1 | NORMAL | 17.00 | 0.9184 |  | MR60BHA2_breath_phase | safenest-node-01
5.7000 | 0.150000 | S001 | S001_NORMAL_5MIN_01 | 1 | NORMAL | 17.00 | 0.9184 |  | MR60BHA2_breath_phase | safenest-node-01
5.8000 | 0.150000 | S001 | S001_NORMAL_5MIN_01 | 1 | NORMAL | 17.00 | 0.9184 |  | MR60BHA2_breath_phase | safenest-node-01
5.9000 | 0.150000 | S001 | S001_NORMAL_5MIN_01 | 1 | NORMAL | 18.00 | 0.9184 |  | MR60BHA2_breath_phase | safenest-node-01
6.0000 | 0.150000 | S001 | S001_NORMAL_5MIN_01 | 1 | NORMAL | 18.00 | 0.9184 |  | MR60BHA2_breath_phase | safenest-node-01
6.1000 | 0.130000 | S001 | S001_NORMAL_5MIN_01 | 1 | NORMAL | 18.00 | 0.9184 |  | MR60BHA2_breath_phase | safenest-node-01
6.2000 | 0.130000 | S001 | S001_NORMAL_5MIN_01 | 1 | NORMAL | 18.00 | 0.9184 |  | MR60BHA2_breath_phase | safenest-node-01
6.3000 | 0.110000 | S001 | S001_NORMAL_5MIN_01 | 1 | NORMAL | 18.00 | 0.9184 |  | MR60BHA2_breath_phase | safenest-node-01
6.4000 | 0.090000 | S001 | S001_NORMAL_5MIN_01 | 1 | NORMAL | 19.00 | 0.9184 |  | MR60BHA2_breath_phase | safenest-node-01
6.5000 | 0.070000 | S001 | S001_NORMAL_5MIN_01 | 1 | NORMAL | 19.00 | 0.9184 |  | MR60BHA2_breath_phase | safenest-node-01
6.6000 | 0.040000 | S001 | S001_NORMAL_5MIN_01 | 1 | NORMAL | 19.00 | 0.9184 |  | MR60BHA2_breath_phase | safenest-node-01
6.7000 | 0.020000 | S001 | S001_NORMAL_5MIN_01 | 1 | NORMAL | 19.00 | 0.9184 |  | MR60BHA2_breath_phase | safenest-node-01
6.8000 | -0.010000 | S001 | S001_NORMAL_5MIN_01 | 1 | NORMAL | 19.00 | 0.9184 |  | MR60BHA2_breath_phase | safenest-node-01
6.9000 | -0.040000 | S001 | S001_NORMAL_5MIN_01 | 1 | NORMAL | 20.00 | 0.9184 |  | MR60BHA2_breath_phase | safenest-node-01
7.0010 | -0.060000 | S001 | S001_NORMAL_5MIN_01 | 1 | NORMAL | 20.00 | 0.9184 |  | MR60BHA2_breath_phase | safenest-node-01
7.1010 | -0.080000 | S001 | S001_NORMAL_5MIN_01 | 1 | NORMAL | 20.00 | 0.9184 |  | MR60BHA2_breath_phase | safenest-node-01
7.2010 | -0.080000 | S001 | S001_NORMAL_5MIN_01 | 1 | NORMAL | 20.00 | 0.9184 |  | MR60BHA2_breath_phase | safenest-node-01
7.3010 | -0.080000 | S001 | S001_NORMAL_5MIN_01 | 1 | NORMAL | 20.00 | 0.9184 |  | MR60BHA2_breath_phase | safenest-node-01
7.4010 | -0.070000 | S001 | S001_NORMAL_5MIN_01 | 1 | NORMAL | 20.00 | 0.9184 |  | MR60BHA2_breath_phase | safenest-node-01
7.5020 | -0.040000 | S001 | S001_NORMAL_5MIN_01 | 1 | NORMAL | 20.00 | 0.9184 |  | MR60BHA2_breath_phase | safenest-node-01
7.6020 | -0.020000 | S001 | S001_NORMAL_5MIN_01 | 1 | NORMAL | 20.00 | 0.9184 |  | MR60BHA2_breath_phase | safenest-node-01
7.7020 | 0.020000 | S001 | S001_NORMAL_5MIN_01 | 1 | NORMAL | 21.00 | 0.9184 |  | MR60BHA2_breath_phase | safenest-node-01
7.8020 | 0.050000 | S001 | S001_NORMAL_5MIN_01 | 1 | NORMAL | 21.00 | 0.9184 |  | MR60BHA2_breath_phase | safenest-node-01
7.9020 | 0.090000 | S001 | S001_NORMAL_5MIN_01 | 1 | NORMAL | 21.00 | 0.9184 |  | MR60BHA2_breath_phase | safenest-node-01
8.0020 | 0.140000 | S001 | S001_NORMAL_5MIN_01 | 1 | NORMAL | 21.00 | 0.9184 |  | MR60BHA2_breath_phase | safenest-node-01
8.1020 | 0.160000 | S001 | S001_NORMAL_5MIN_01 | 1 | NORMAL | 21.00 | 0.9184 |  | MR60BHA2_breath_phase | safenest-node-01
8.2020 | 0.210000 | S001 | S001_NORMAL_5MIN_01 | 1 | NORMAL | 21.00 | 0.9184 |  | MR60BHA2_breath_phase | safenest-node-01
8.3020 | 0.220000 | S001 | S001_NORMAL_5MIN_01 | 1 | NORMAL | 21.00 | 0.9184 |  | MR60BHA2_breath_phase | safenest-node-01
8.4020 | 0.250000 | S001 | S001_NORMAL_5MIN_01 | 1 | NORMAL | 21.00 | 0.9184 |  | MR60BHA2_breath_phase | safenest-node-01
8.5020 | 0.260000 | S001 | S001_NORMAL_5MIN_01 | 1 | NORMAL | 21.00 | 0.9184 |  | MR60BHA2_breath_phase | safenest-node-01
8.6020 | 0.270000 | S001 | S001_NORMAL_5MIN_01 | 1 | NORMAL | 21.00 | 0.9184 |  | MR60BHA2_breath_phase | safenest-node-01
8.7020 | 0.270000 | S001 | S001_NORMAL_5MIN_01 | 1 | NORMAL | 22.00 | 0.9184 |  | MR60BHA2_breath_phase | safenest-node-01
8.8020 | 0.260000 | S001 | S001_NORMAL_5MIN_01 | 1 | NORMAL | 22.00 | 0.9184 |  | MR60BHA2_breath_phase | safenest-node-01
8.9020 | 0.250000 | S001 | S001_NORMAL_5MIN_01 | 1 | NORMAL | 22.00 | 0.9184 |  | MR60BHA2_breath_phase | safenest-node-01
9.0020 | 0.220000 | S001 | S001_NORMAL_5MIN_01 | 1 | NORMAL | 22.00 | 0.9184 |  | MR60BHA2_breath_phase | safenest-node-01
9.1020 | 0.190000 | S001 | S001_NORMAL_5MIN_01 | 1 | NORMAL | 22.00 | 0.9184 |  | MR60BHA2_breath_phase | safenest-node-01
9.2020 | 0.180000 | S001 | S001_NORMAL_5MIN_01 | 1 | NORMAL | 22.00 | 0.9184 |  | MR60BHA2_breath_phase | safenest-node-01
9.3020 | 0.150000 | S001 | S001_NORMAL_5MIN_01 | 1 | NORMAL | 22.00 | 0.9184 |  | MR60BHA2_breath_phase | safenest-node-01
9.4020 | 0.130000 | S001 | S001_NORMAL_5MIN_01 | 1 | NORMAL | 22.00 | 0.9184 |  | MR60BHA2_breath_phase | safenest-node-01
9.5020 | 0.100000 | S001 | S001_NORMAL_5MIN_01 | 1 | NORMAL | 22.00 | 0.9184 |  | MR60BHA2_breath_phase | safenest-node-01
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

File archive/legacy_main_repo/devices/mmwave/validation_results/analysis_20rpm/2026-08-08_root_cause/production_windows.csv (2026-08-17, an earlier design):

target_rpm | window_index | selected_rpm | absolute_error_rpm | peak_ratio | phase_std | actual_duration_s | effective_hz | strongest_peak_rpm | second_peak_rpm | second_peak_relative
12.0 | 1 | 12.16186151663015 | 0.16186151663015025 | 21.057303070234358 | 0.3901161111913522 | 29.912000000000262 | 9.995988232147546 | 12.16186151663015 | 17.282168706483834 | 0.1777895256063374
12.0 | 2 | 11.911636374369468 | 0.08836362563053157 | 8.174724750671041 | 0.2821758329046499 | 29.90899999999965 | 9.996990872312798 | 11.911636374369468 | 19.329929285480393 | 0.1640214199256927
12.0 | 3 | 11.70123514987321 | 0.29876485012679055 | 31.677239121659937 | 0.3668788043399452 | 29.920000000000073 | 9.993315508021366 | 11.70123514987321 | 16.91871455884309 | 0.1524773251797321
12.0 | 4 | 12.56602418240707 | 0.5660241824070695 | 8.286993644092195 | 0.5030254592190727 | 29.91899999999987 | 9.993649520371713 | 12.56602418240707 | 18.551093583164423 | 0.20584959066140904
12.0 | 5 | 11.630599731762366 | 0.3694002682376336 | 18.240938624279305 | 0.35596286173808006 | 29.909999999999854 | 9.996656636576445 | 11.630599731762366 | 21.944663346228285 | 0.22420810085620477
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

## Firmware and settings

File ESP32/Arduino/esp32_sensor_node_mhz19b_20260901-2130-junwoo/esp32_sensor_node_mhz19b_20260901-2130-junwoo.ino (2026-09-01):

/*
 * SafeNest ESP32 sensor node
 *
 * Sensors:
 *   - Seeed MR60BHA2 (UART2 GPIO 16/17): respiration and heart rate
 *   - Winsen MH-Z19B (UART1 GPIO 32/33): CO2
 *   - PIR (digital input): motion
 *   - Waveshare Thermal Camera HAT / MI48xx (I2C control + SPI data): 80 x 62
 *
 * Transport:
 *   - TCP for low-rate mmWave/CO2/PIR JSON telemetry
 *   - Chunked UDP for big-endian uint16 Thermal frames
 *
 * The Arduino loop never calls delay(). Sensor scheduling uses millis().
 * TCP reconnect/writes and Thermal UDP writes run in separate FreeRTOS tasks.
 * If the network is slow, the one-slot thermal queue keeps only the newest frame.
 *
 * MH-Z19B power: Vin 4.5-5.5 V, peak 150 mA. Do not power from the ESP32 3.3 V
 * rail. UART is 9600 8N1 TTL 3.3 V with TX/RX crossed on UART1 (GPIO 32/33).
 * Never share UART2 (GPIO 16/17) with the MR60.
 */

#include <Arduino.h>
#include <esp_system.h>
#include <freertos/event_groups.h>
#include <freertos/semphr.h>
#include <WiFi.h>
#include <WiFiUdp.h>
#include <Wire.h>
#include <SPI.h>
#include <errno.h>
#include <lwip/sockets.h>
#include "Seeed_Arduino_mmWave.h"
#include "secrets.h"

// -----------------------------------------------------------------------------
// Device identity. Wi-Fi and Raspberry Pi settings live in ignored secrets.h.
// ----------------------------------------------------------------------------
constexpr char DEVICE_ID[] = "esp32-01";
char bootId[33] = {};
constexpr uint16_t THERMAL_UDP_PORT = 5005;

// -----------------------------------------------------------------------------
// ESP32 Dev Module wiring. MH-Z19B is on UART1; MR60 stays on UART2.
// ----------------------------------------------------------------------------
constexpr int PIN_I2C_SDA = 21;
constexpr int PIN_I2C_SCL = 22;
constexpr int PIN_PIR = 13;
constexpr int PIN_MMWAVE_RX = 16;  // ESP32 RX <- MR60BHA2 TX
constexpr int PIN_MMWAVE_TX = 17;  // ESP32 TX -> MR60BHA2 RX
// UART1 for MH-Z19B. Never share UART2 (16/17) with the MR60.
// GPIO 32/33 are free after the v2 pin map (I2C 21/22, PIR 13, thermal
// SPI/I2C 18/19/23/27/26/25). They are not flash/strapping pins on WROOM.
constexpr int PIN_MHZ19_RX = 32;  // ESP32 RX <- MH-Z19B TX
constexpr int PIN_MHZ19_TX = 33;  // ESP32 TX -> MH-Z19B RX

constexpr int PIN_THERMAL_SCLK = 18;
constexpr int PIN_THERMAL_MISO = 19;
constexpr int PIN_THERMAL_MOSI = 23;
constexpr int PIN_THERMAL_CS = 27;
constexpr int PIN_THERMAL_READY = 26;
constexpr int PIN_THERMAL_RESET = 25;

constexpr uint32_t USB_BAUD = 115200;
constexpr uint32_t MMWAVE_BAUD = 115200;
constexpr uint32_t MHZ19_BAUD = 9600;
constexpr uint32_t THERMAL_SPI_HZ = 8000000;

// Runtime schedules.
// MH-Z19B command 0x86 has no Sensirion-style getDataReadyStatus. Winsen
// manuals (v1.7, 2020-10-15) do not prove each UART read is a new NDIR
// conversion. This node therefore infers producer identity:
//   - at most one accepted UART sample per CO2_UART_SAMPLE_PERIOD_MS
//   - event identity class INFERRED_UART_SAMPLE (not SCD40 conversion)
// 5000 ms matches the SCD4x ~5 s cadence this v2 node used to expose and
// is slower than the ~1 s PWM encoding period. It is NOT a claim that the
// optical cell converts at this rate.
constexpr uint32_t PIR_PERIOD_MS = 20;
constexpr uint32_t CO2_UART_SAMPLE_PERIOD_MS = 5000;
constexpr uint32_t CO2_UART_RESPONSE_TIMEOUT_MS = 200;
constexpr uint32_t CO2_PREHEAT_MS = 180000;  // Winsen: 3 min
constexpr uint16_t CO2_PPM_MAX_ACCEPTED = 10000;
// 10 Hz matches the 1.3.0 phase contract. PHASE_MAX_AGE_MS is 500, so a 1 Hz
// snapshot would publish breath_phase as null on almost every packet and the
// Pi 300-sample window would never fill. LCD can ignore the extra packets.
// TCP writes remain isolated in their own task.
constexpr uint32_t TELEMETRY_PERIOD_MS = 100;
constexpr uint32_t HEALTH_LOG_PERIOD_MS = 10000;
// If MI48 is unpowered or hung off I2C, a probe-first init never pulses
// GPIO25. Recovery always resets then probes. Serial 't' is debug-only.
constexpr uint32_t THERMAL_RECOVER_PERIOD_MS = 2000;
constexpr uint32_t THERMAL_STALE_REINIT_MS = 7000;
constexpr uint32_t THERMAL_I2C_MISS_LOG_MS = 10000;
constexpr uint32_t MMWAVE_STALE_MS = 10000;
constexpr uint32_t CO2_STALE_MS = 15000;
constexpr uint32_t PHASE_MAX_AGE_MS = 500;
// The MR60 reports 0x0F09 occupancy on its own cadence, independent of the
// respiration/heart-rate stream. This bound only has to outlive normal report
// gaps; once it lapses the field goes null (unknown), which suppresses mmWave
// inference rather than asserting an empty room.
constexpr uint32_t PRESENCE_MAX_AGE_MS = 5000;
constexpr char NODE_FIRMWARE_VERSION[] =
    "safenest-esp32-sensor-node/1.7.10-mhz19b.1";
constexpr char DIAGNOSTIC_BUILD_ID[] =
    "mhz19b-thermal-reinit-20260901-09";
constexpr char MMWAVE_SCHEMA_VERSION[] = "1.3";
constexpr char CO2_SENSOR_MODEL[] = "MH-Z19B";
constexpr char CO2_EVENT_IDENTITY_CLASS[] = "INFERRED_UART_SAMPLE";

// -----------------------------------------------------------------------------
// Link diagnostics.
//
// A "disconnect" on this link is really a missed receive deadline on the Pi.
// Both receivers close the socket themselves when one packet does not arrive
// in time, and neither waits as long as this node is willing to stall:
//
//   RaspberryPi/LCD/server.py             connection.settimeout(2.0). Its
//                                         header recv is wrapped in
//                                         `except socket.timeout: continue`,
//                                         but the payload recv is not, so one
//                                         2 s gap between the 16-byte header
//                                         and the JSON body raises
//                                         socket.timeout -- an OSError, which
//                                         its handler treats as fatal.
//   RaspberryPi/Runtime/gateway/          5 s total deadline per field.
//     receiver.py
//
// Arduino-ESP32 3.x NetworkClient::write() is not bounded by writeAll()'s
// old 5000 ms stall timer. It select()-waits WIFI_CLIENT_SELECT_TIMEOUT_US
// (1 s) up to WIFI_CLIENT_MAX_WRITE_RETRY (10) times, so one client.write()
// can sit in the TX mutex for ~10000 ms. Field logs of write_max_ms=10012
// with stall_ms=0/zero_writes=0 are that path: the wait happens inside
// write(), so the application timer never starts. The Pi LCD receiver has
// already closed (2 s) long before that returns, which is why peer_closed,
// tcp_errno=104 (ECONNRESET) and connect_ms≈1500 follow.
//
// writeAll() therefore calls lwip_send(MSG_DONTWAIT) itself. An 800 ms retry
// loop on EAGAIN was still long enough to desynchronize the Pi: a partial
// SNST prefix (field wrote=97/808) forces this node to close, then
// reconnect SYN storms fill the TX queue even with thermal UDP off. Skip
// before any byte is on the wire; only a started packet uses the finish
// deadline.
// ----------------------------------------------------------------------------
constexpr uint32_t PI_PACKET_DEADLINE_MS = 2000;
// Warn below the Pi deadline so the log shows the approach, not only the crash.
constexpr uint32_t TELEMETRY_GAP_WARN_MS = 1500;
constexpr uint32_t TCP_WRITE_WARN_MS = 150;
// No byte sent yet: abandon this snapshot and keep the socket.
constexpr uint32_t TCP_WRITE_SKIP_MS = 40;
// Some bytes already on the wire: finish or close (partial SNST is fatal).
constexpr uint32_t TCP_WRITE_DEADLINE_MS = 200;
constexpr uint32_t TCP_CONNECT_TIMEOUT_MS = 4000;
// After a partial-write close, wait before SYN. 300 ms was still fast enough
// to pile SYN-RECV on a weak AP uplink (errno 119 / connect_ms=1503).
constexpr uint32_t TCP_RECONNECT_DELAY_MS = 2000;
constexpr uint32_t TCP_CONNECT_FAIL_DELAY_MS = 2500;
constexpr uint8_t TCP_CONNECT_FAILS_BEFORE_REASSOC = 5;
constexpr uint32_t SERIAL_ERROR_LOG_PERIOD_MS = 1000;
constexpr uint32_t TCP_MUTEX_WARN_MS = 100;
// UDP sendto is O_NONBLOCK, so the mutex should be held for milliseconds.
// 250 ms turns a stuck datagram into a counted timeout instead of a 3 s
// invisible wait that itself misses the Pi deadline.
constexpr uint32_t TCP_MUTEX_MAX_WAIT_MS = 250;
constexpr uint32_t UDP_DATAGRAM_WARN_MS = 40;
// 2 ms between chunks was only a CPU yield. Nine 1200-byte datagrams still
// hit the radio in ~34 ms, which is what filled the lwIP pool (errno 12) and
// left no airtime for the 1 Hz TCP write. 20 ms is long enough for the TCP
// task to wake, take the mutex, and finish a ~3 ms write, and 8 gaps stay
// inside the ~1000 ms 1 fps period and the Pi's 500 ms thermal reassembly
// window (measured from the last chunk, not the first).
constexpr uint32_t UDP_CHUNK_GAP_MS = 20;
// A live telemetry write holds TCP_CRITICAL_BIT for a few milliseconds.
// Waiting this out and then continuing the same frame is the interleave;
// returning Preempted used to drop the remaining chunks. Connect() holds the
// bit much longer, but tcpLinkHealthy is already false then, so we stand down
// instead of waiting out the handshake.
constexpr uint32_t UDP_YIELD_TO_TCP_MAX_MS = 80;
// Free-heap low-water used to trigger udp.stop()/begin() every 5 s. That
// malloc/free of the 1460-byte WiFiUDP TX buffer plus a new PCB is what
// produced heap≈74 KB with max_alloc≈45 KB (fragmentation, not a leak):
// stopping TX recovered 74→90→105→122 KB as lwIP pbufs drained. ENOMEM
// now pauses the thermal sender so those pbufs can return; the socket is
// rebuilt only when the fd itself looks dead.
constexpr uint32_t HEAP_RECLAIM_LOW_WATER_BYTES = 48000;
constexpr uint32_t UDP_ENOMEM_BACKOFF_MIN_MS = 250;
constexpr uint32_t UDP_ENOMEM_BACKOFF_MAX_MS = 2000;
constexpr uint32_t UDP_SLOW_TCP_HOLDOFF_MS = 250;
// udpStarted was only cleared when Wi-Fi dropped, so once sendto() entered a
// failing state the task retried the same socket forever: udp_sent froze at 61
// for the rest of the run while udp_failed kept climbing. Rebuilding the socket
// after a run of failures gives the transmitter a way back without a reboot.
constexpr uint32_t UDP_MAX_CONSECUTIVE_FAILURES = 10;
// The per-2-second [link] firehose was 38 fields on one line, five times more
// often than [health]. Same cadence as [health] keeps it readable; 's' still
// prints one on demand and 'l' silences the periodic copy.
constexpr uint32_t DIAG_LOG_PERIOD_MS = 10000;

enum class Mhz19Txn : uint8_t {
  IDLE,
  AWAIT_RESPONSE,
};

// -----------------------------------------------------------------------------
// Thermal-camera constants (MI48xx + MI0801/MI0802, 80 x 62).
// ----------------------------------------------------------------------------
constexpr uint8_t THERMAL_ADDRESS_A = 0x40;
constexpr uint8_t THERMAL_ADDRESS_B = 0x41;

// Winsen MH-Z19B UART read-concentration command 0x86 (9 bytes, 9600 8N1).
// checksum = (NOT (byte1..byte7)) + 1; ppm = high*256 + low.
constexpr uint8_t MHZ19_READ_CMD[9] = {0xFF, 0x01, 0x86, 0x00, 0x00,
                                       0x00, 0x00, 0x00, 0x79};

constexpr uint8_t REG_EVK_TEST = 0x00;
constexpr uint8_t REG_SENSOR_POWERUP = 0xB0;
constexpr uint8_t REG_FRAME_MODE = 0xB1;
constexpr uint8_t REG_FW_VERSION_1 = 0xB2;
constexpr uint8_t REG_FW_VERSION_2 = 0xB3;
constexpr uint8_t REG_FRAME_RATE = 0xB4;
constexpr uint8_t REG_STATUS = 0xB6;
constexpr uint8_t REG_SENSOR_TYPE = 0xBA;

constexpr uint8_t STATUS_DATA_READY = 0x10;
constexpr uint8_t STATUS_BOOTING = 0x20;
constexpr uint8_t MODE_CONTINUOUS = 0x02;

constexpr size_t THERMAL_WIDTH = 80;
constexpr size_t THERMAL_HEIGHT = 62;
constexpr size_t THERMAL_PIXEL_COUNT = THERMAL_WIDTH * THERMAL_HEIGHT;
constexpr size_t THERMAL_HEADER_WORDS = THERMAL_WIDTH;
constexpr size_t THERMAL_CAPTURE_WORDS =
    THERMAL_HEADER_WORDS + THERMAL_PIXEL_COUNT;

// MI48 FRAME_RATE is a divisor of the ~25 FPS native sensor. 25 → ~1.0 FPS.
// Lowering this value raises bandwidth and ESP32 CPU/SPI load.
//
// Divisor 4 (6.25 FPS) is what the Wi-Fi TX path could not sustain: one frame
// is 9 datagrams, so 6.25 FPS put ~57 datagrams/s and ~64 KB/s on the radio in
// 160 ms bursts. Divisor 12 (~2.08 FPS) still competed with 1 Hz TCP until
// writes were fail-fast. 25 keeps the frame format identical at about half
// that UDP rate; raise it back only with the [link] udp_kbps and tcp drop
// counters in view.
constexpr uint8_t THERMAL_FRAME_RATE_DIVIDER = 25;

// -----------------------------------------------------------------------------
// SafeNest TCP protocol v1 for scalar telemetry.
// Outer header (16 bytes, network byte order):
//   magic[4]="SNST", version:u8, type:u8, flags:u16,
//   packet_sequence:u32, payload_length:u32
// Packet type 1 payload: UTF-8 JSON.
// Thermal UDP logical payload: 16-byte metadata followed by 4960 uint16 words.
// -----------------------------------------------------------------------------
constexpr uint8_t PROTOCOL_VERSION = 1;
constexpr uint8_t PACKET_TELEMETRY_JSON = 1;
constexpr uint8_t PACKET_THERMAL_U16_BE = 2;
constexpr size_t PACKET_HEADER_SIZE = 16;
constexpr size_t THERMAL_META_SIZE = 16;

// SafeNest Thermal UDP v1. A 1200-byte datagram stays below the common
// Ethernet/Wi-Fi MTU after IPv4 and UDP headers, avoiding IP fragmentation.
// Header fields are network byte order and every chunk repeats the frame CRC32.
constexpr char THERMAL_UDP_MAGIC[] = "SNTU";
constexpr uint8_t THERMAL_UDP_VERSION = 1;
constexpr size_t THERMAL_UDP_HEADER_SIZE = 32;
constexpr size_t THERMAL_UDP_DATAGRAM_SIZE = 1200;
constexpr size_t THERMAL_UDP_CHUNK_SIZE =
    THERMAL_UDP_DATAGRAM_SIZE - THERMAL_UDP_HEADER_SIZE;
constexpr size_t THERMAL_PAYLOAD_SIZE =
    THERMAL_META_SIZE + THERMAL_PIXEL_COUNT * sizeof(uint16_t);
constexpr uint16_t THERMAL_UDP_CHUNK_COUNT =
    (THERMAL_PAYLOAD_SIZE + THERMAL_UDP_CHUNK_SIZE - 1) /
    THERMAL_UDP_CHUNK_SIZE;

struct TelemetrySnapshot {
  uint32_t sequence;
  uint32_t uptimeMs;
  float respirationRate;
  float heartRate;
  uint16_t co2Ppm;
  bool pirMotion;
  bool respirationValid;
  bool heartValid;
  bool co2Valid;
  bool phaseSamplePresent;
  // Inferred MH-Z19B UART sample identity. Same event_id on later TCP
  // snapshots is a cached retransmission; Pi slope must ignore repeats.
  uint32_t co2MeasurementEventId;
  uint32_t co2MeasurementMonotonicMs;
  bool co2MeasurementEventValid;
  bool co2Preheat;
  // Tri-state MR60 occupancy. `humanDetectedKnown == false` must serialize as
  // JSON null, never false: the Pi presence gate treats false as "room empty"
  // and would then suppress mmWave inference for the wrong reason.
  bool humanDetectedRaw;
  bool humanDetectedKnown;
  float totalPhase;
  float breathPhase;
  float heartPhase;
  uint32_t phaseTimestampMs;
  uint32_t phaseSequence;
};

struct ThermalTxFrame {
  uint32_t frameSequence;
  uint32_t uptimeMs;
  uint16_t minimumRaw;
  uint16_t maximumRaw;
  uint16_t pixels[THERMAL_PIXEL_COUNT];
};

// Per-write forensics. A bare bool made a 2 ms success and a 4.9 s stall that
// eventually succeeded look identical, yet only the second one outlives the
// Pi's receive timeout and gets the socket closed underneath us.
struct TcpWriteReport {
  size_t bytesWritten;
  uint32_t elapsedMs;
  uint32_t longestStallMs;
  uint16_t zeroWrites;
  uint16_t partialWrites;
  int lastErrno;
  bool connectedAtEnd;
};

enum class ThermalSendResult {
  Sent,
  Preempted,
  Failed,
  // The Serial kill switch dropped the frame. Kept distinct from Preempted so
  // a deliberate A/B test never inflates the contention counter.
  Suppressed,
  // The TCP session is down, so the transmitter yielded the radio to let it
  // reconnect. Distinct from Suppressed because nobody asked for it, and from
  // Preempted because no TCP write was actually waiting on the mutex.
  Deferred,
};

HardwareSerial mmWaveSerial(2);
HardwareSerial mhz19Serial(1);

// The library's own SEEED_MR60BHA2::isHumanDetected() cannot express "unknown":
// it returns false both when the room is empty and when no 0x0F09 report has
// been parsed yet, and it self-clears its validity flag on read. Overriding
// handleType() captures the report itself, so an absent report stays
// distinguishable from a negative one. The base implementation is still
// invoked, leaving library state untouched, and the base class has already
// verified both frame checksums before dispatching here.
class SafeNestMR60BHA2 : public SEEED_MR60BHA2 {
 public:
  bool handleType(uint16_t type, const uint8_t *data,
                  size_t dataLength) override {
    if (type == static_cast<uint16_t>(
                    TypeHeartBreath::ReportHumanDetection)) {
      // The vendor handler reads data[0] unguarded; refuse a truncated report
      // here instead of letting it read out of bounds.
      if (dataLength < 1) return false;
      presenceRaw_ = data[0] != 0;
      presencePending_ = true;
    }
    return SEEED_MR60BHA2::handleType(type, data, dataLength);
  }

  // Same one-shot out-parameter idiom as getBreathRate()/getHeartRate(): the
  // return value means "a new report was parsed", never "nobody is present".
  bool takePresence(bool &value) {
    if (!presencePending_) return false;
    presencePending_ = false;
    value = presenceRaw_;
    return true;
  }

  // SeeedmmWave::fetch() keeps a static startFrame that never times out.
  // One false SOF 0x01 consumes real frames as payload for the rest of the
  // boot. Assemble UART locally, then dispatch checksummed frames here.
  bool ingestFrame(const uint8_t *bytes, size_t len) {
    return processFrame(bytes, len);
  }

 private:
  bool presenceRaw_ = false;
  bool presencePending_ = false;
};

SafeNestMR60BHA2 mmWave;
SPIClass thermalSpi(VSPI);

QueueHandle_t telemetryQueue = nullptr;
QueueHandle_t thermalQueue = nullptr;
EventGroupHandle_t networkEvents = nullptr;
SemaphoreHandle_t networkTxMutex = nullptr;
constexpr EventBits_t TCP_CRITICAL_BIT = BIT0;

uint16_t thermalCapture[THERMAL_CAPTURE_WORDS];
// These ~10 KiB objects are global on purpose. Keeping either on a task stack
// can overflow the default Arduino loop stack on a non-PSRAM ESP32.
ThermalTxFrame thermalProducerFrame;
ThermalTxFrame thermalNetworkFrame;
uint8_t thermalAddress = 0;
bool thermalStarted = false;
uint32_t lastThermalRecoverMs = 0;
uint32_t lastThermalProgressMs = 0;
uint32_t lastRecoverCaptureAttempts = 0;

float respirationRate = NAN;
float heartRate = NAN;
float totalPhase = NAN;
float breathPhase = NAN;
float heartPhase = NAN;
uint16_t co2Ppm = 0;
bool pirMotion = false;
bool humanDetectedRaw = false;
bool phaseSamplePresent = false;

uint32_t lastRespirationMs = 0;
uint32_t lastHeartMs = 0;
uint32_t lastPresenceMs = 0;
uint32_t lastCo2Ms = 0;
uint32_t lastThermalStatusPollMs = 0;
uint32_t lastPirPollMs = 0;
uint32_t lastCo2PollMs = 0;
uint32_t lastTelemetryMs = 0;
uint32_t lastHealthLogMs = 0;
uint32_t telemetrySequence = 0;
uint32_t thermalSequence = 0;
uint32_t thermalCrcErrors = 0;
uint32_t thermalRangeErrors = 0;
uint32_t co2MeasurementEventId = 0;
uint32_t co2MeasurementMonotonicMs = 0;
bool co2MeasurementEventValid = false;
Mhz19Txn mhz19Txn = Mhz19Txn::IDLE;
uint32_t mhz19RequestSentMs = 0;
uint32_t co2ChecksumFailures = 0;
uint32_t co2TimeoutFailures = 0;
uint32_t co2ShortFrameFailures = 0;
uint32_t co2AcceptedSamples = 0;
uint16_t co2LastUartPpm = 0;
// Written by the network tasks on core 0 and read by loop() on core 1. Each
// counter has exactly one writer and aligned 32-bit accesses are atomic on
// Xtensa, so volatile only has to stop the compiler caching them in registers.
volatile uint32_t telemetryQueueOverwrites = 0;
volatile uint32_t thermalQueueOverwrites = 0;
volatile uint32_t tcpConnectionFailures = 0;
volatile uint32_t tcpSendFailures = 0;
volatile uint32_t thermalUdpFramesSent = 0;
volatile uint32_t thermalFramesPreempted = 0;
volatile uint32_t thermalTcpYields = 0;
volatile uint32_t thermalUdpSendFailures = 0;
volatile uint32_t heapReclaims = 0;
volatile uint32_t heapReclaimSkippedTcp = 0;
volatile uint32_t udpHoldoffEvents = 0;
volatile uint32_t udpHoldoffUntilMs = 0;
volatile uint32_t udpBackoffMs = 0;
volatile uint32_t tcpWriteTimeouts = 0;

// Link diagnostics written by the network tasks on core 0, under the same
// single-writer, aligned-32-bit rule as the counters above.
volatile uint32_t tcpSessions = 0;
volatile uint32_t tcpDrops = 0;
volatile uint32_t tcpShortSessions = 0;
volatile uint32_t tcpPeerClosed = 0;
volatile uint32_t tcpWriteStalls = 0;
volatile uint32_t tcpPartialWrites = 0;
volatile uint32_t tcpMutexTimeouts = 0;
volatile uint32_t tcpMutexWaitMaxMs = 0;
volatile uint32_t tcpMutexWaitSlow = 0;
volatile uint32_t tcpWriteMaxMs = 0;
volatile uint32_t tcpSlowWrites = 0;
volatile uint32_t telemetryGapMaxMs = 0;
volatile uint32_t telemetryGapOverWarn = 0;
volatile uint32_t telemetryGapOverDeadline = 0;
volatile uint32_t telemetryPacketsSent = 0;
volatile uint32_t lastTelemetrySentMs = 0;
volatile uint32_t udpDatagramsSent = 0;
volatile uint32_t udpBytesSent = 0;
volatile uint32_t udpDatagramMaxMs = 0;
volatile uint32_t udpSlowDatagrams = 0;
volatile uint32_t udpFrameMaxMs = 0;
volatile uint32_t thermalFramesSuppressed = 0;
volatile uint32_t thermalFramesDeferred = 0;
volatile uint32_t udpSocketRestarts = 0;
volatile int32_t tcpLastErrno = 0;
volatile int32_t udpLastErrno = 0;
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
void loop() {
  const uint32_t now = millis();
  ++loopIterations;

  pollMmWave(now);
  pollCo2(now);
  maybeRecoverThermalCamera(now);
  captureThermalIfReady(now);
  // SPI capture blocks UART servicing. Drain again so a mid-frame SOF does
  // not sit in the Seeed assembler until the next ~1 fps camera tick.
  pollMmWave(millis());

  if (scheduleDue(now, lastPirPollMs, PIR_PERIOD_MS)) {
    pirMotion = digitalRead(PIN_PIR) == HIGH;
  }

  publishTelemetrySnapshot(now);
  handleSerialCommand();
  logLinkDiagnostics(now);
  logHealth(now);

  // Cooperative yield only; there is intentionally no delay() in runtime.
  taskYIELD();
}

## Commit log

2026-07-26 Initialize SafeNest competition repository
    [2026-07-25_entry_exit_10__S001_ENTRY_EXIT_01.csv, 2026-07-25_entry_exit_10__S001_ENTRY_EXIT_02.csv, 2026-07-25_entry_exit_10__S001_ENTRY_EXIT_03.csv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]
2026-07-27 Add files via upload
    센서 커버 하우징
    [housing_body.stl, sliding_back_panel.stl]
2026-07-28 refactor: STL 파일들을 main 브랜치에서 삭제
    [housing_body.stl, sliding_back_panel.stl, trapezoid_T_back_panel.stl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]
2026-07-28 Add files via upload
    수정본
    [trapezoid_T_back_panel.stl]
2026-07-31 chore: consolidate contributor branches
    [2026-07-25_entry_exit_10__S001_ENTRY_EXIT_01.csv, 2026-07-25_entry_exit_10__S001_ENTRY_EXIT_02.csv, 2026-07-25_entry_exit_10__S001_ENTRY_EXIT_03.csv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]
2026-08-02 refactor: integrate SafeNest V4 architecture
    [2026-07-25_breath_paced_12rpm__S001_BREATH_PACED_12_01.csv, 2026-07-25_entry_exit_10__S001_ENTRY_EXIT_01.csv, 2026-07-25_entry_exit_10__S001_ENTRY_EXIT_02.csv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]
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2026-08-03 refactor: move files into responsibility domains
    [2026-07-25_breath_paced_12rpm__S001_BREATH_PACED_12_01.csv, 2026-07-25_entry_exit_10__S001_ENTRY_EXIT_01.csv, 2026-07-25_entry_exit_10__S001_ENTRY_EXIT_02.csv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]
2026-08-03 refactor: update remaining tool and analysis paths
    2차 경로 수정에서 누락된 실행 경로를 새 책임 영역 구조에 맞춘다.
    - devices/mmwave/firmware/analysis_tools 5개 스크립트가 이동 전
    firmware/esp_wroom32_mr60_monitor/ 절대경로를 참조해 실행 불가였다.
    Path(__file__) 기준 상대 경로로 교체했다.
    - hr_ref_capture_run.sh의 저장소 절대경로를 스크립트 위치 기준으로
    바꾸고, 세션마다 달라지는 임시 디렉터리를 저장소 밖 기본값으로 옮겼다.
    - benchmark_thermal.py가 이동 전 tests/benchmarks/에 결과를 쓰고 있어
    ondevice_ai/benchmarks/ 아래 실제 추적 파일과 어긋났다. 스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
2026-08-03 docs: define responsibility ownership and provenance
    책임 영역 구조에 맞춰 문서, 소유권, provenance를 정리한다. 코드 변경은 없다.
    - .github/CODEOWNERS 신설. 사람이 아니라 기기·책임 영역 기준으로 기본
    리뷰어를 지정했다. 5개 handle은 저장소 collaborator 목록으로 실재와
    write 권한을 확인했다.
    - 누락된 영역 README 7개 신설: devices/, devices/co2|pir|thermal/,
    hardware/3d_models/, shared/, shared/contracts/. 기존 README는 덮어쓰지
    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
2026-08-03 mmwave: verify R1 firmware C++/Python zero-cross equivalence
    Replicate main.cpp breathStats() in Python and compare against the ESP's
    own breath_phase_std / breath_rate_filtered / breath_filtered_valid on the
    31min schema 1.2 session. No porting bug: gate-decision mismatch is
    51/18,276 (0.279%), std p99 0.00609, rate p50 0.0328 rpm.
    All residual mismatch is explained by three non-algorithmic causes:
    replay warmup (300 packets), a 26-30min phase dropout where phase_age_ms
    reaches 288,530ms, and the 2-decimal quantization of breath_phase in the
    log (sensitivity test: dropping to 1 decimal moves rate by up to 24 rpm
    with the algorithm held fixed).
    Also records a latent defect for post-capture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
2026-08-04 feat(ondevice-ai): replace main package with SafeNest V5
    Replace only the top-level ondevice_ai package from main with the verified SafeNest V5 on-device AI distribution. Keep all other responsibility-domain directories unchanged.
    [mmwave_window_sample.csv]
2026-08-06 docs: move mmWave device docs into docs/mmwave
    팀 규칙에 맞춰 인수인계·운용 문서를 저장소 루트 docs/ 아래로 모은다.
    센서 코드는 devices/<sensor>/에 그대로 두고 읽을 문서만 옮긴다.
    git mv만 사용한 순수 이동이며 내용 변경은 없다.
    추적 파일 수 360 -> 360, SHA-256 multiset digest dec35e35... 동일.
2026-08-06 docs: update references to relocated mmWave docs
    이동한 mmWave 문서를 가리키던 참조를 docs/mmwave/로 갱신한다.
    - docs/README.md: 기기별 문서를 docs/<sensor>/로 모은다는 위치 규칙 반영
    - devices/mmwave/README.md: docs/ 하위 구성 항목을 링크로 바꾸고,
    포함/미포함 파일 유형에서 사람이 읽는 문서를 제외로 명시
    - BRANCH_PROVENANCE.md: 최종 경로만 갱신 (원본 ref/커밋은 불변)
2026-08-06 docs: establish team doc placement rule
    코드와 문서의 배치 규칙을 명문화한다.
    코드는 devices/<sensor>/, 사람이 읽는 문서는 docs/<sensor>/에 둔다.
    원본 로그와 분석 산출물은 문서가 아니므로 devices/<sensor>/에 남긴다.
    - CONTRIBUTING.md: "어디에 커밋하는가" 배치 표 추가, docs/ 브랜치 유형과
    main direct push 금지 명시
    - .github/CODEOWNERS: /docs/mmwave/ 담당 지정. 다른 센서 문서 추가 시
    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
2026-08-10 feat(esp32_node): add ESP32 4-sensor collection node firmware
    MR60BHA2(UART), SCD4x(I2C), PIR(GPIO), MI48 열화상(I2C+SPI)을 한 보드에서
    수집해 1초 주기 safenest.telemetry.v1 JSON으로 Pi에 전송하는 수집 노드.
    - 열화상 리셋을 I2C 프로브보다 먼저 수행해 not found 오인식 해결
    - I2C 400 kHz -> 100 kHz 로 낮춰 브레드보드 배선에서 CO2 0 ppm 문제 해결
    - 프레임 스트리밍 대신 thermal_max_c 스칼라만 전송해 링크 마비 제거
    원본: yuseungha/safenest-embedded-competition@0992a6d (yuseungha/esp32_sensor_node/).
    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
2026-08-10 feat(integration): add Pi receiver/LCD server and integrated web dashboard
    ESP32 텔레메트리를 받아 상태를 판정하고 LCD/부저/웹으로 내보내는 Pi 실행 계층.
    - pi_lcd: TCP 9000 수신, /api/state·/api/thermal·/health, LCD 키오스크, GPIO 부저
    - web: Express 통합 웹(관리자·방문자), 상태 변경 시에만 LCD 갱신(pushBridgeState)
    - install/start 스크립트는 pi_lcd·web을 ~/raspberry_pi_lcd·~/SafeNest_Web으로 복사해
    실측 검증된 운용 절차를 그대로 유지한다
    원본: yuseungha/safenest-embedded-competition@0992a6d
    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
2026-08-12 feat(co2): add SCD40 hardware verification evidence
    [2026-08-12_baseline_5min.csv, 2026-08-12_baseline_attempt02_5min.csv, 2026-08-12_breath-rise-recovery_6min.csv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]
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2026-08-16 Correct PR22 Thermal capture semantics and provenance
    [xiao_esp32c6_thermal90_udp_capture.ino]
2026-08-17 fix(esp32): split thermal frames onto UDP
    [esp32_sensor_node.ino]
2026-08-17 Update trapezoid housing STL and design spec
    Replace the trapezoid housing body with the latest verified STL, including the SafeNest recessed engraving, expanded buzzer grille, and updated 125/95 mm depths. Update the matching Korean design specification.
    [trapezoid_housing_body.stl]
2026-08-17 evidence: mmWave/CO2 실측 검증 데이터와 진단 도구 보존
    로컬에만 있던 미커밋 작업물을 저장소에 반영한다. 대부분 재현 불가능한
    실기기 측정 증거이므로 유실 위험을 먼저 제거한다.
    - devices/mmwave: quality policy 진단 도구·테스트, 2026-08-08 라이브 캡처
    (baseline, preflight, fail-closed, recovery, identity raw) 및 분석 결과
    - devices/co2: serial adapter, v5 노드 러너, 도구·테스트,
    2026-08-09 실측 CO2 검증 세션 결과
    - docs/dashboard: 대시보드 정적 산출물
    - ondevice_ai/integrated_node: CO2 측정 이벤트 방출 로직 보강
    - SAFE_NEST_EMERGENCY_*: 비상 대응 변경분 인수인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
    [esp32_sensor_node.ino]
2026-08-17 refactor: SafeNest canonical 통합 저장소로 재구성 + End-to-End 런타임 통합
    5개 상류 저장소를 비교해 컴포넌트별 권위 소스를 확정하고, 단일 명령으로
    기동되는 End-to-End SafeNest 런타임으로 통합했다.
    구조
    - ESP32/: canonical 4센서 통합 플래시 소스, 프로토콜 계약, mmWave 참조 펌웨어
    - RaspberryPi/Ondevice_AI: 상류 권위 소스 sheepmeat/test@4129753 채택
    - RaspberryPi/{LCD,Web}: LCD 키오스크와 실시간 대시보드 자산
    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
    [2026-07-25_breath_paced_12rpm__S001_BREATH_PACED_12_01.csv, 2026-07-25_entry_exit_10__S001_ENTRY_EXIT_01.csv, 2026-07-25_entry_exit_10__S001_ENTRY_EXIT_02.csv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]
2026-08-17 mmwave: M-C0 correspondence audit 작업물을 canonical 구조로 편입
    PR #21(codex/mmwave-m-c0-correspondence)의 작업물을 재구성된 main 구조에
    맞춰 배치한다. 브랜치를 그대로 병합하면 datasets/, devices/, docs/,
    scripts/, tests/, PROJECT_PROGRESS.md 가 최상위에 되살아나 재구성이
    부분적으로 되돌아가므로, 경로만 재배치했다.
    - research/mmwave_ai/: M-C0 오프라인 감사물 11개 (매니페스트·스크립트·
    테스트·리포트). Thermal·CO2 연구 워크스페이스와 동일한 위치 규칙
    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
    [benchmark_summary.csv, production_windows.csv]
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2026-08-18 sensor(mr60): finalize CAP-2 session 1 (SUBJ-001, 4 min, 7/7 windows)
    First CAP-2 neutral device-domain session. Raw JSONL stays local under the
    existing raw/ ignore policy; manifest and QA are tracked.
    M-N4 yield 7/7 windows accepted, 0 rejected, 0 republications dropped.
    Stream integrity clean: 0 uart/checksum errors, 0 seq gaps, max gap 103 ms,
    jitter 0.43 ms, phase_age max 18 ms.
    Producer flagged BREATH_PHASE_LOW_AMPLITUDE on 43% of records concentrated in
    the 90-180 s span while distance held at 51.7 cm, so the flag tracks breathing
    depth rather than geometry. This revises the earlier hypothesis that the PR18
    pilot low-amplitude rate was distance-driven.
    validate_contract.py --check-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
2026-08-18 sensor(mr60): add CAP-2 repeat, CAP-3 reboot, and unoccupied-room sessions
    Three further sessions on 2026-08-18, all validator PASS with
    --check-files --strict-warnings. Raw JSONL stays local under the existing
    raw/ ignore policy; manifests and QA are tracked.
    CAP2-S001-02 7/7 windows, 29% low amplitude
    CAP3-S001-REBOOT 7/7 windows, 1% low amplitude, after ESP power cycle
    CAP3-EMPTY-01 8/8 windows, all MAD=0 zero tensors, no subject
    Reboot did not shift phase scale: range -0.82..+0.85 and pstdev 0.295 sit
    within the CAP-2 session-to-session spread (0.204, 0.230). Timing behaviour
    was identical across all three (10 Hz, phase_age max 18 ms, 0 republications,
    0 rejected windows).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
2026-08-18 sensor(mr60): record CAP-2/3 results and open the CAP-6 protocol request
    Updates the sensor-owner roadmap with the 2026-08-18 measurement results and
    adds a request document for the model-development track.
    Roadmap now carries the session inventory (4 sessions, 29 canonical windows,
    0 rejected), the M-N4 yield table, and two findings:
    - reboot does not shift phase scale; the post-reboot range and pstdev sit
    inside the CAP-2 session-to-session spread (n=3 observation)
    - the CAP-0 hypothesis that pilot low amplitude was distance-driven is
    rejected; amplitude varied while distance held constant
    CAP-6 is blocked on three items, documented with their resolution paths. The
    request document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
2026-08-18 sensor(mr60): detect truncated serial lines that still parse as JSON
    physical_capture_qa.py gains a schema_conformance section (qa schema 1.2).
    A serial byte dropout can fuse two adjacent JSON keys into one novel key, as
    happened once in M-C0-PILOT-STATIONARY-001 where "breath_filtered_valid" and
    "breath_phase_std" became "breath_filtered_v_std". The line stays valid JSON,
    so malformed_line_count never sees it.
    The check compares key frequency rather than key names: the schema sets
    additionalProperties=true and the firmware emits 12 fields it does not declare,
    so an undeclared key carried by every record is reported as informational. Only
    a key present on some records but not others fails,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
2026-08-18 sensor(mr60): record the USB/TCP path split and distance quantization
    The model track's first reply described the capture path and the live
    production path as one path, then corrected it. Recording the distinction so a
    later reader does not repeat the confusion.
    CAP-0..3 are USB serial evidence from the platformio firmware, which emits the
    M-N4 fields plus human_detected_raw as flat JSON. The Arduino TCP node emits
    neither; draft PR #29 would nest the phase fields and still omits presence.
    Settled: PR #29 is not a prerequisite and is not to be merged or waited on;
    human_detected_raw is not added to the Arduino TCP packet (that ask was
    retracted, and it would be an ESP32-owner firmware chan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
2026-08-18 sensor(mr60): correct sensor height to 75 cm; capture-time tilt is now unrecoverable
    The bench was tape-measured after all four sessions were recorded, and the
    sensor tilt was re-set to 90 deg during the same pass. Only part of the
    measurement can be applied backwards.
    height 100 -> 75 cm applied; tilt-only change leaves the mount and desk
    unmoved, and the previous 100 was an eyeball estimate
    tilt stays 100 the 90 deg reading describes the post-session bench,
    not this session's geometry
    distance stays device-derived; the 50 cm tape reading was taken after the
    adjustment, so it is recorded as corrobor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
2026-08-18 sensor(mr60): read the full M-N10 protocol; Pi smoke is not a hard blocker
    Section 5.2 recorded the Pi isolated M-N9 smoke as required before human
    capture. The English protocol states the alternative: if another verified raw
    logger is used, capture may proceed and the report carries
    PI_SMOKE_REMAINS_UNVERIFIED. Our USB/Mac logger is such a logger, so a future
    M-N10 capture is not gated on Pi readiness.
    Also recorded: partition examples (6->2/4, 8->3/5, 9->3/6) and the rule that a
    RESERVED subject is never moved to DEV for inconvenient data; the per-raw-file
    lineage list, of which only "clocks" is missing from our manifests; that window
    eligibility counting is inside M-N10 scope, which cap0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
2026-08-20 Update trapezoidal housing body and design spec
    Update only the trapezoid body STL and matching Korean design specification with the latest right-side cooling-fan opening (40 x 40 mm, rounded R3, Y=70..110, Z=15..55).
    [trapezoid_housing_body.stl]
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2026-08-21 fix(esp32): align thermal UDP offset type
    [esp32_sensor_node.ino]
2026-08-21 docs: hand off thermal NOT_HUMAN field findings with measurement records
    Record live API and NPZ tallies from the 2026-08-22 Pi session, and document that visual human shape with NOT_HUMAN is a preprocessing/domain-contract issue to check before retrain.
    [20260822_thermal_field_measurement_summary.csv]
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2026-08-23 docs(report): add grand-prize review and revision guide
    개발완료보고서 21페이지를 심사위원 관점으로 재검토하고, 대상 도전에 필요한
    수정 지침을 정리한다.
    - 배점별 현재 점수 추정과 근거
    - 대상을 막는 5대 병목 (통합 관통 증거 / 경보 지연 미측정 / AI 검증 부족 /
    임베디드 신뢰성 수치 부재 / 가중치 근거 없음)
    - 진행 중인 4센서 통합과 시연영상으로 회수 가능한 항목
    - 페이지별 수정 지시와 페이지 예산 조정안
    - 신규 저장소 이관 체크리스트
    내부 전략 문서이므로 제출용 저장소에는 포함하지 않는다는 경고를 문서 상단에 명시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
2026-08-27 feat(mmwave): port B23 prototype into Pi runtime
    Replace the default M-N4/M-N9 240-sample path with the frozen SW-01 → R1/R2 → B23 prototype so team telemetry can feed the existing RaspberryPi runtime without a second service.
2026-08-27 fix(mmwave): use ESP physical timestamp and nested phase seq for B23
    The current ESP already stamps ts_monotonic_ms at observation time, so subtracting phase_age_ms double-counted age. Parse mmwave.seq as the physical sample identity and treat boot_id as the hard reset boundary.
2026-08-27 fix(mmwave): treat a valid B23 phase stream as live sensor data
    Vendor respiration/heart scalars no longer make mmWave INVALID when breath_phase, physical timestamp, phase age, and nested sequence are present.
2026-08-28 fix(gateway): preempt a stalled ESP TCP session on reconnect
    A half-open client was able to block accept until the packet deadline, so a live ESP could not come back on :9000.
2026-08-28 feat(mmwave): latch occupancy and feed B23 a 10 Hz sample-index grid
    Live ESP occupancy is a one-sample true pulse with nulls in between, and MR60 timestamps are ~9.8 Hz jittered, so the frozen R1 path never reached inference. Keep the last explicit bool without coercing null to false, and map admitted phase samples onto a 10 Hz index grid after physical freshness and gap checks.
2026-08-28 docs: shorten field-monitor labels and document live B23 states
    PHYSIOLOGY_ELIGIBLE and other B23 codes were truncated in the table. Use short labels, widen the values column, and record the current occupancy-latch / R1-time / PHYS_OK meanings in PI_RUNBOOK.
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2026-08-28 fix(mmwave): keep 30s causal window across short nested-seq holes
    Nested mmwave.seq jumps of +2 were treated as cross-bundle discontinuity and flushed M-PROT-3, so live MR60 never left WARMUP. Treat short holes as diagnostics when the timestamp gap is still within the existing max gap.
2026-08-28 fix(web): relax dashboard refresh intervals to cut Pi load
    The portal refreshed far faster than the sensors actually update, so the
    Pi spent CPU on redundant pushes, fetches, and canvas redraws.
    - backend WebSocket push: 0.25s -> 1.0s
    - admin API poll: 1s -> 3s
    - thermal frame poll: 150ms -> 500ms (named POLL_MS)
    Thermal freeze detection stays at FREEZE_MS=3000 with a 500ms checker, so
    a stalled stream is still reported within the same window.
2026-08-28 fix(web): restore 150ms thermal frame polling
    500ms made the thermal view visibly stutter on the portal, so the frame
    poll goes back to its original 150ms. POLL_MS stays as a named constant;
    this file is now behavior-identical to main.
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2026-08-31 feat(esp32): prioritize TCP telemetry over thermal UDP in node v2
    Add a TCP critical section (event group bit + TX mutex) so scalar
    telemetry writes preempt in-flight thermal UDP datagrams instead of
    queueing behind them. The thermal task samples the critical bit per
    chunk and now reports Sent/Preempted/Failed separately.
    - Raise telemetry-tcp task priority 1 -> 2 and serialize network TX
    - Chunk TCP writes at 512 B with a 5 s no-progress timeout
    - Send the telemetry header and JSON in a single write
    - Slim the telemetry JSON to the LCD contract (1792 B -> 512 B buffer)
    - Move detailed diagnostics to the rate-limited Serial health log
    - Relax cadences: telemetry 100 -> 1000 ms, CO2 poll 250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
    [esp32_sensor_node_260828_v2.ino]
2026-08-31 feat(esp32): throttle thermal UDP and instrument the TCP link
    Thermal UDP saturation was taking the TCP telemetry link down with it:
    tcp_connection_failures climbed, free heap fell ~40 KB, and TCP connect
    stopped completing its handshake until a reboot. The same run with the
    thermal camera unpowered held tcp_connection_failures at 0.
    Firmware 1.4.0-tcp-priority.1 -> 1.6.0-udp-backpressure.1.
    Backpressure:
    - THERMAL_FRAME_RATE_DIVIDER = 12 (2.08 fps, one third the bandwidth).
    Frame format is unchanged.
    - Rebuild the UDP socket after UDP_MAX_CONSECUTIVE_FAILURES = 10. Once
    sendto() entered a failing state the task retried the same socket
    forever, so udp_sent froze while udp_failed kept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
    [esp32_sensor_node_260828_v2.ino]
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2026-08-31 feat(esp32): yield thermal UDP chunks so TCP telemetry can send
    Nine datagrams in ~34 ms filled lwIP and preempt dropped the rest of the
    frame, so 1 Hz TCP writes missed the radio. Wait out TCP between chunks
    and finish the same frame instead of aborting it.
    [esp32_sensor_node_260828_v2.ino, esp32_sensor_node_260828_v2_no_co2_uart1.ino]
2026-08-31 feat(esp32): yield MH-Z19B UDP chunks and drain mmWave around thermal SPI
    Give TCP telemetry airtime between thermal datagrams and recycle only the UDP socket so lwIP buffers do not starve the scalar path. Drain MR60 UART before and after SPI so a mid-frame cut is less likely to stall parsing.
    [esp32_sensor_node_mhz19b_v2.ino]
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2026-08-31 fix(esp32): fail-fast TCP writes and drop thermal UDP to 1 fps
    WiFiClient.write() could block ~10s inside select, past the Pi 2s deadline.
    Send non-blocking with an 800ms cap, pause UDP until the first telemetry write
    succeeds, back off on ENOMEM instead of recycling the socket every 5s, and
    request ~1 fps so the radio is less likely to starve TCP.
    [esp32_sensor_node_mhz19b_v2.ino]
2026-08-31 fix(pi): keep TCP sessions across ESP skipped snapshots
    ESP 1.7.3 may skip a 1 Hz JSON write and stall up to 800 ms after a
    header. Idle 2 s / 5 s field deadlines were closing the live socket.
    Wait indefinitely for the next header; keep a 5 s deadline only after
    bytes of the current field have arrived.
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2026-08-31 feat(esp32): skip partial TCP snapshots so mmWave JSON stays on the wire
    An EAGAIN stall used to send a 97-byte SNST prefix then close, which desynced the Pi even with thermal UDP off. Skip 0-byte writes in 40 ms, rate-limit drop logs, and pause SPI capture when UDP is disabled.
    [esp32_sensor_node_mhz19b_v2.ino]
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2026-09-01 feat: add field-bringup ESP32 node and Pi receive gateway
    새 파일 2개만 추가합니다. 기존 파일과 프로토콜(SafeNest TCP v1 /
    Thermal UDP v1)은 한 바이트도 바꾸지 않았으므로 RaspberryPi/Runtime 은
    수정 없이 이 노드를 그대로 받습니다.
    ESP32/Arduino/09.01_12:21_jinsoo_esp/
    - MI48 헤더 배치를 부팅 시 자동 탐색하고, 못 찾으면 검증을 끄고 계속
    전송합니다. 기존 v2 는 capture[5]/[6]/[7] 배치를 가정하고 어긋나면
    프레임을 버려서, 가정이 틀리면 열화상이 100% 사라졌습니다.
    - MI48 READY 는 SPI 로 읽어가기 전까지 HIGH 로 래치되므로, 관찰만으로는
    정상 핀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
2026-09-01 hardware: resize rectangular CO2 opening to 13x26
    Replace the rectangular housing STL and update the design specification. CO2 opening: 13 x 26 mm, X=63, Z=20, sharp corners.
    [housing_body.stl]
2026-09-01 feat: field-tested ESP32 node and Pi gateway (09.01 14:50)
    12:21 판에서 실기기 브링업으로 확인·수정한 것들을 반영한 별도 파일입니다.
    기존 파일은 그대로 두고 새로 추가만 했습니다.
    ESP32/Arduino/09.01_14-50_jinsoo_esp/ (12:21 대비 추가분)
    - CO2 예열을 표시값과 AI 입력으로 분리했습니다. 기존에는 ESP 부팅 후 3분
    동안 co2_ppm 을 통째로 null 로 막았는데, 이 타이머가 "센서 전원"이 아니라
    "ESP 부팅" 기준이라 펌웨어를 다시 구울 때마다 또 3분을 기다려야 했습니다.
    이제 값은 즉시 나가고, co2_preheat_complete(=C-B6 입력 자격)만 Winsen
    규격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
2026-09-01 feat: LCD offline debounce (ver2) + B23 null-phase skip
    새 파일 (ver2)
    ESP32/Arduino/jinsoo_esp_ver2/jinsoo_esp_ver2.ino
    RaspberryPi/jinsoo_라즈베리파이_ver2.py
    현장 검증을 거친 최신 노드/게이트웨이. 09.01_14-50 판과 같은 내용이며
    파일명 규칙만 ver 방식으로 바꿉니다.
    RaspberryPi/LCD/static/display_ver2.html
    끊김 표시 디바운스. 기존 화면은 끊김을 즉시 "통신 오류"로 띄웠는데,
    링크가 순간적으로 흔들리거나 판정 근거가 잠시 모자라 risk_level 이
    INDETERMINATE 가 될 때마다 큰 글씨가 번쩍여서, 실제로는 데이터가
    들어오고 있는데도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
    [jinsoo_esp_ver2.ino]
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2026-09-01 feat(esp32): emit co2_preheat_complete so C-B6 can ingest H150
    Pi treated firmware co2_preheat as preheat_complete without inverting it, so after the 180 s warmup the occupancy model never received a measurement event.
    [esp32_sensor_node_mhz19b_20260901-1958-junwoo.ino]
2026-09-01 feat(esp32): re-init MI48 at runtime when thermal capture stalls
    [esp32_sensor_node_mhz19b_20260901-2130-junwoo.ino]
2026-09-02 fix(risk): 비재실에서는 위험·긴급 없이 CO2 주의만
2026-09-02 fix(thermal): 사람 존재는 모델, 서기/눕기는 bbox 종횡비로 덮기
    C0 TFLite는 그대로 두고, 사람일 때만 0-1 프레임의 핫픽셀 bbox로 HUMAN_NORMAL과 HUMAN_FALL_PROXY를 가른다.
2026-09-02 fix(tts): CO2 주의일 때 호흡이상 음성을 쓰지 않음
    주의 레벨은 CO₂가 만들었는데 TTS가 같은 tick의 호흡 reasons를 먼저 고르던 매핑 순서를 바로잡는다.
